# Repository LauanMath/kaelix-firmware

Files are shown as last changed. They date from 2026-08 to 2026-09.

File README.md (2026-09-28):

# Kaelix

Dispositivo IoT de manutenção preditiva para motores industriais — monitora
vibração e temperatura, roda um modelo de detecção de anomalias embarcado
(TinyML) e transmite o resultado via LoRa. TCC de Engenharia de Software
(ICEV), inspirado na arquitetura do TRACTIAN Smart Trac.

O hardware físico ainda não foi montado. Todo o firmware e o pipeline de
treino foram desenvolvidos e testados em simulador e dados offline, para que
a integração com o hardware real seja só calibração quando ele chegar.

## Hardware alvo

| Componente | Modelo | Interface |
|---|---|---|
| Microcontrolador | ESP32-S3-WROOM-1 N16R8 | — |
| Acelerômetro/giroscópio | MPU6050 | I2C (endereço 0x68) |
| Temperatura | Termistor NTC 10K (beta 3950) | ADC analógico |
| Rádio | RA-02 (SX1278) LoRa 433MHz | SPI |
| Regulador | HT7333 (LDO 3,3V ultra baixo consumo) | — |
| Corte de energia | Load switch high-side: SI2301 (P-MOSFET) + BC847B (inversor) | GPIO |
| Proteção de entrada | SI2301 em série (polaridade invertida) | — |
| Medição da bateria | Divisor 1M/1M + 100n | ADC analógico |

### Pinagem

| Uso | Pino | Observação |
|---|---|---|
| I2C (MPU6050) | SDA=8, SCL=9 | *default* da placa — ainda não usado (I2C real é TODO) |
| SPI (LoRa) | MOSI=11, MISO=13, SCK=12, SS=10 | *default* da placa |
| LoRa DIO0 | 14 | escolhido para não colidir com I2C |
| LoRa RESET | 21 | escolhido para não colidir com I2C |
| NTC (ADC) | 4 | placeholder |
| Corte de energia (+3V3_SW) | 5 | ativo-alto; RTC-capable, ver *deep sleep* |
| Tensão da bateria (ADC) | 6 | divisor 1M/1M; 4,2 V → 2,10 V, 3,0 V → 1,50 V |

Conferidos sem conflito entre si e contra o `pins_arduino.h` real da variante
`esp32s3`, mas ainda não contra um esquemático físico definitivo.

**Microcontrolador conferido contra a peça real.** Um ESP32-S3 foi lido com
`esptool`: QFN56 revisão v0.2, 16 MB de flash, 8 MB de PSRAM embarcada. Confirma a
variante N16R8 que o `platformio.ini` declara — e portanto a necessidade de
sobrescrever o perfil da `devkitc-1`, que declara 8 MB de flash e nenhuma PSRAM.
Os demais componentes (MPU6050, NTC, SX1278) continuam não montados.

## O ciclo

```
acordar → energizar periféricos (100ms de estabilização)
        → ler 512 amostras a 1 kHz + NTC
        → extrair RMS, curtose, fator de crista, frequência dominante
        → inferir Isolation Forest embarcado
        → transmitir 21 bytes via LoRa
        → dormir o rádio, cortar periféricos, deep sleep (12 min)
```

Todo o trabalho acontece em `setup()`; `loop()` nunca executa, porque o
dispositivo entra em deep sleep antes de chegar lá.

---

# Decisões de arquitetura

Esta seção registra o *porquê* das escolhas não óbvias — útil tanto para
retomar o desenvolvimento quanto para justificá-las numa defesa.

## Separar matemática pura de acesso a hardware

É a decisão estruturante do projeto. Cada capacidade do firmware foi
dividida em duas camadas:

- **`lib/<nome>/`** — funções puras, sem `Arduino.h`, sem I2C/ADC/SPI.
  Compilam e rodam no host pelo ambiente `native` do PlatformIO.
- **`src/sensors/`, `src/ml/`, `src/comms/`, `src/power/`** — a camada que
  fala com o hardware de verdade e chama as funções de `lib/`.

Foi isso que permitiu desenvolver e validar a maior parte da lógica sem ter
o ESP32-S3, o MPU6050 ou o RA-02 em mãos. Quando o hardware chegar, só a
camada `src/` muda — trocar buffers zerados por leituras reais — porque a
matemática já está testada.

## FFT própria em vez de `arduinoFFT`

A implementação própria (radix-2 Cooley-Tukey, iterativa, sem alocação
dinâmica) compila tanto no ambiente `esp32-s3` quanto no `native`, o que
permite testá-la no host com senoides de frequência conhecida antes de
qualquer hardware. `arduinoFFT` foi avaliada e nunca chegou a ser usada.

`n` precisa ser potência de 2 — responsabilidade do chamador
(`VIBRATION_SAMPLES = 512`).

## Frequência dominante da velocidade, não da aceleração

Aceleração escala com ω², então o espectro de aceleração é sempre dominado
pelo conteúdo de alta frequência — tipicamente um modo estrutural da
montagem, que é o mesmo com a máquina sadia ou defeituosa. Medido em dados
reais do MAFAULDA: o pico de aceleração fica em 117 Hz independente da
rotação, com correlação de **−0,018** contra a rotação real do ensaio.

A magnitude é reponderada por `|V(f)| = |A(f)|/(2πf)` e a busca fica
restrita a 10–1000 Hz. A fase é irrelevante para escolher o bin de pico,
então não é preciso integrar o sinal — só reponderar o espectro que a FFT já
produziu. Custo no firmware: uma divisão por bin.

O limite inferior da banda não é cosmético: sem ele, a ponderação 1/f faria
o bin mais baixo vencer sempre.

**Efeito medido** em 880 arquivos reais, mesmo protocolo: detecção de 11,7%
para 38,5%, F1 de 0,178 para 0,550. A AUC global quase não se move
(0,795 → 0,805), o que ilustra por que ela não serve como métrica de
operação.

## Isolation Forest nativo, sem TensorFlow Lite Micro

O modelo é um Isolation Forest (scikit-learn), mas a inferência embarcada
**não** usa TFLite Micro — usa uma implementação C++ própria
(`lib/isolation_forest/`) que percorre diretamente as árvores exportadas.

TensorFlow Lite é desenhado para redes neurais; Isolation Forest é um
ensemble de árvores cujo score é o comprimento médio de caminho até isolar
um ponto. Não existe caminho oficial e confiável de conversão
scikit-learn → TFLite Micro para esse tipo de modelo, e a rota possível
(`skl2onnx` → `onnx-tf` → `TFLiteConverter`) depende de ferramentas pouco
mantidas. A alternativa nativa é mais simples, mais leve em RAM/Flash, e
elimina a dependência frágil.

### Como funciona

1. `isolation_path_length_correction(n)` — c(n), o comprimento médio de
   caminho esperado numa árvore binária com n amostras. Mesma fórmula do
   scikit-learn, incluindo os casos `c(1)=0` e `c(2)=1`.
2. `isolation_tree_path_length` — percorre a árvore até a folha e soma a
   profundidade com a correção da folha.
3. `isolation_forest_score` — média entre as árvores, normalizada:
   `score = 2^(−caminho_médio / c(n))`, em (0,1]. Próximo de 1 = anômalo.

### Validação cruzada Python ↔ C++

`training/tests/test_export_cpp.py` treina um modelo, exporta o header,
**compila de verdade com g++**, roda o binário e compara o score contra
`-clf.score_samples(X)` do scikit-learn, com tolerância de 1e-4. É o que
garante, de forma verificável, que treino e inferência não divergem.

O vetor de features é o mesmo dos dois lados (`src/ml/model.cpp` e
`training/kaelix_ml/features.py::FEATURE_ORDER`):

```
[rms, kurtosis, crest_factor, dominant_freq_hz]
```

`temperature_c` é lido e passado para `model_infer`, mas ainda não entra no
vetor.

### Estado do modelo embarcado

`src/ml/isolation_forest_data.h` traz o modelo treinado nos dados reais do
MAFAULDA: `N_TREES = 100`, `N_FEATURES = 4`, `ANOMALY_THRESHOLD = 0,55719777`
(quantil de calibração, não 0,5). O arquivo é gerado por
`python -m kaelix_ml.train` — use `--out` para exportar a outro caminho e
preservar o que está versionado.

`model_init` e `model_infer` mantêm a guarda `N_TREES <= 0`, que devolve
`Status::ModelAbsent` e deixa o veredito em `Unknown`. Ela deixou de ser o
caminho normal quando o modelo foi embarcado, mas continua sendo o
comportamento correto para um build sem modelo — e é o que impede que a
ausência de árvores vire "máquina sadia".

## Protocolo de treino e calibração

**Domínio alinhado com o firmware.** Os datasets vêm a 50 kHz (MAFAULDA) ou
12/48 kHz (CWRU), em registros de segundos; o dispositivo lê 512 amostras a
1 kHz. Extrair features do arquivo inteiro produziria um modelo inaplicável
— `dominant_freq_hz` chegaria a 25 kHz no treino e nunca passaria de 500 Hz
em campo. `dataset.to_device_windows` decima e fatia todo sinal antes de
virar feature.

**Split por ensaio.** `GroupKFold` com o arquivo de origem como grupo, para
que janelas do mesmo ensaio nunca fiquem dos dois lados do split. O relatório
traz média ± desvio entre folds: desvio alto é informação sobre falta de
ensaios, não ruído a esconder atrás de um número único.

**Limiar por taxa de falso alarme alvo.** O limiar não é 0,5 nem vem do
`contamination`: é o quantil dos scores de um conjunto de calibração formado
por grupos que o modelo não viu no fit. O default `contamination="auto"`
marcaria ~42% da operação normal como anomalia.

**Mesma regra de decisão dos dois lados.** Calibração, avaliação e exportação
usam `device_score()` = `-clf.score_samples(X)`, a convenção (0,1] idêntica à
de `lib/isolation_forest/`. Usar `clf.predict()` faria o relatório do treino
descrever um comportamento diferente do embarcado.

**Rótulo verdadeiro do caminho, ISO como diagnóstico.** Quando o dataset
codifica a classe de falha na estrutura de diretórios — como o MAFAULDA faz
— é esse o rótulo usado. O rótulo derivado da ISO 10816-3 é calculado em
paralelo e o treino imprime a matriz de concordância. Em dados reais, a ISO
sob classe I marca **93,4% da operação genuinamente normal como anômala**,
o que a desqualifica como fonte de rótulo para este dataset.

## Temperatura

Duas funções puras em `lib/thermistor/`:

1. `ntc_resistance_from_millivolts` — converte a leitura para resistência,
   assumindo o divisor `Vcc → R_FIXED → nó de leitura → NTC → GND`.
   **Topologia assumida, não confirmada contra o esquemático final.**
2. `ntc_resistance_to_celsius` — equação B (Steinhart-Hart simplificada).

O firmware usa a variante em milivolts porque o ADC bruto do ESP32-S3 é
sensivelmente não-linear; `analogReadMilliVolts` aplica a curva de calibração
gravada no eFuse de fábrica. Usar a contagem crua assume uma linearidade que
o hardware não tem e enviesa a temperatura.

## Comunicação LoRa

RadioLib, SX1278, 433 MHz, TX a 17 dBm. API conferida contra o código-fonte
da versão instalada.

### Pacote — 21 bytes, versão 2

| Campo | Bytes | Por quê |
|---|---|---|
| `version` | 1 | o gateway precisa saber interpretar o layout; sem isso, mudar o formato vira leitura silenciosamente errada do outro lado |
| `device_id` | 4 | do eFuse MAC. Com mais de um Kaelix na planta, sem ele o gateway não sabe de quem é a leitura |
| `boot_count` | 4 | contador em RTC memory, sobrevive ao deep sleep. Dá sequência e detecção de pacote perdido |
| `state` | 1 | `kaelix::MachineState` — normal, anômalo ou **desconhecido** |
| `diag` | 1 | `kaelix::status_code()` do primeiro erro do ciclo (0 = Ok). É o canal de diagnóstico de produção: sem ele, `state = Unknown` chega ao gateway sem dizer por quê |
| `rms` | 4 | NaN = não medido |
| `temperature_c` | 4 | NaN = não medido |
| `crc` | 2 | CRC-16/CCITT sobre os 19 bytes anteriores |

A v1 tinha 20 bytes e um campo `status` binário. O `state` ternário e o `diag`
entraram juntos: um veredito que pode ser "não sei" é inútil se o outro lado
não recebe a causa.

O campo `timestamp` que existia antes era `millis()`, que zera a cada deep
sleep — todo pacote chegava com ~3000 ms. Não era um relógio. O tempo de
parede é responsabilidade do gateway, que carimba na recepção.

O CRC vive em `lib/crc16/` como função pura, testada no host contra o vetor
de conferência padrão (`"123456789"` → `0x29B1`): um pacote corrompido no ar
que chegue ao gateway como leitura válida é pior que um pacote perdido.

Um `static_assert` trava o tamanho do struct, para que uma mudança de layout
não passe despercebida sem bump de `PACKET_VERSION`.

### Topologia de rede e o elo que falta

O dispositivo transmite. Do outro lado existe um receptor **em simulação**, em
`experiments/gateway/` — decodificação do quadro, estado por dispositivo, detecção de
lacuna na sequência e regra de alerta, com 19 testes. Não existe receptor em rádio
real: nada nunca recebeu um pacote pelo ar.

**E o gateway está uma versão atrás.** `packet.py` fixa `PACKET_VERSION = 1` e
`PACKET_SIZE = 20`; o firmware emite v2 com 21 bytes. A guarda de versão faria o
gateway recusar **todos** os pacotes do firmware atual — falha segura, e a defesa
funcionando como projetada, mas a cadeia ponta-a-ponta simulada não corresponde ao
dispositivo. Os 19 testes passam porque o gateway é exercitado contra o próprio
`codificar()`, um laço fechado em v1: o teste de paridade cruza a **função** CRC com
`lib/crc16`, não o **layout** da struct. O byte `diag`, que o firmware trata como
canal de diagnóstico de produção, não tem leitor nenhum.

Fechar isso é subir o gateway para v2 e criar um teste que gere o quadro a partir do
layout de `src/comms/lora.h`, em vez do próprio codificador.

**LoRa cru, não LoRaWAN.** `radio.transmit()` direto: sem endereçamento de rede, sem
join, sem criptografia, sem confirmação. Qualquer receptor na mesma frequência, SF e
syncWord recebe o pacote. É escolha, não esquecimento — LoRaWAN exigiria um
concentrador multicanal em vez de um SX1278 e traria complexidade que um protótipo não
paga. Mas o custo aparece nos itens abaixo.

**Sem confirmação, sem retransmissão.** `lora_send()` informa se a transmissão saiu,
não se chegou. Um pacote perdido some em silêncio. O `boot_count` existe para que o
gateway detecte o buraco na sequência — sem gateway, isso é teoria.

**Colisão.** ALOHA puro. Com 185 ms no ar e ciclo de 720 s, a probabilidade de colisão
é 1,0% para 20 dispositivos e 2,5% para 50. Aceitável.
(Uma revisão anterior dava 1,5% e 3,7%: aqueles valores correspondem a 226 ms, o tempo
no ar em `CR 4/7`, que não é o que o firmware usa — ele fixa `CR 4/5`.) Mas essa conta pressupõe fases
aleatórias, e uma instalação em que os aparelhos são ligados juntos não tem fase
aleatória: eles acordariam no mesmo instante e colidiriam de forma sistemática. É o que
o deslocamento anticolisão em `transmission_jitter_seconds()` resolve.

**Sem downlink.** O dispositivo nunca escuta. Intervalo de sono, limiar de anomalia e
modelo são fixos no flash. Atualizar qualquer um exige regravar cada aparelho
fisicamente. A base magnética facilita a remoção, mas continua sendo trabalho manual
por unidade. Downlink exigiria janela de recepção após a transmissão, com custo de
energia a orçar.

**Risco regulatório: 433 MHz não é faixa ISM no Brasil.** A Resolução 680 da Anatel
define 902–907,5 MHz e 915–928 MHz para radiação restrita. Para protótipo acadêmico é
irrelevante; para qualquer intenção de produto, é bloqueante — o dispositivo não
passaria em homologação. A migração para 915 MHz (RA-01H, SX1276) é praticamente
drop-in em firmware, então o custo de errar é baixo. O risco precisa estar registrado,
e é este o registro.

**O que existe depois do gateway.** Nada definido: banco de dados, painel, alerta ao
manutentor. E o `device_id` é um número do eFuse — alguém precisa mapeá-lo para
"compressor 3". Esse cadastro não existe.

Um gateway mínimo — ESP32 ou Raspberry Pi com SX1278, validando o CRC com a mesma
lógica de `packet_is_valid()` e publicando o resultado — é o que transformaria
"transmite" em "sistema funciona de ponta a ponta". Fica como trabalho futuro,
registrado aqui para não ser confundido com esquecimento.

## Deep sleep e orçamento de energia

Ciclo: acordar → ler e processar (3s) → transmitir (~150ms) → deep sleep
(10min).

| Fonte | Corrente | Origem |
|---|---|---|
| ESP32-S3 ativo (sem WiFi) | ~40 mA | típico, datasheet Espressif |
| MPU6050 em operação | ~3,9 mA | datasheet InvenSense |
| SX1278 TX @ ~17dBm | ~90 mA | datasheet Semtech |
| **SX1278 standby (STDBY)** | **~1,5 mA** | datasheet Semtech |
| **SX1278 sleep** | **~0,2 µA** | datasheet Semtech |
| ESP32-S3 deep sleep | ~10 µA | fornecido no escopo do projeto |
| HT7333 quiescente | ~8 µA | fornecido no escopo do projeto |

### A linha que decide o orçamento

O rádio **não** está no rail comutado (+3V3_SW), então o estado em que
ele passa os 12 minutos de sleep é decidido por software:

```
sem lora_sleep():  (1,5 + 0,018) mA × 720s = 1093,0 mA·s
com lora_sleep():  (0,0002 + 0,018) mA × 720s = 13,1 mA·s
```

Sozinha, essa diferença é 5,5× maior que o orçamento inteiro do ciclo.
`comms::lora_sleep()` antes do `deep_sleep()` é obrigatório, não opcional.

### Carga por ciclo, com o rádio dormindo

```
Fase ativa (3,0s):   (40 + 3,9 + 1,5 + 0,008) mA × 3,0s   = 136,22 mA·s
                     (o rádio fica em standby depois do begin())
Fase TX (0,185s):    (40 + 3,9 + 90 + 0,008) mA × 0,185s  =  24,77 mA·s
Fase sleep (720s):   (0,0002 + 0,010 + 0,008) mA × 720s   =  13,10 mA·s
                                                   Total  = 171,91 mA·s
```

Corrente média do circuito: `171,91 ÷ 603,19 ≈ 285 µA`.

O tempo de transmissão não é estimativa: sai do cálculo de tempo no ar para os
parâmetros fixados em `src/comms/lora.cpp` (SF9, BW 125 kHz, CR 4/5, preâmbulo de 8
símbolos, 21 bytes de payload). Antes o orçamento assumia 150 ms, número que não vinha
de cálculo nenhum, e os parâmetros do enlace ficavam nos defaults do RadioLib — de modo
que uma atualização da biblioteca mudaria o consumo do produto em silêncio.

Alcance e autonomia são o mesmo botão:

| SF | Tempo no ar | Autonomia | Ganho de enlace | REQ-PWR-06 (≥ 8 meses) |
|---|---|---|---|---|
| 7 | 57 ms | 292 dias | referência | ✅ |
| 8 | 103 ms | 283 dias | +2,5 dB | ✅ |
| **9 (atual)** | **185 ms** | **269 dias** | **+5,0 dB** | ✅ |
| 10 | 371 ms | 243 dias | +7,5 dB | ✅ (no limite) |
| 11 | 741 ms | 202 dias | +10,0 dB | ❌ |
| 12 | 1483 ms | 152 dias | +12,5 dB | ❌ |

Tempo no ar para 21 bytes em `CR 4/5`; autonomia para o ciclo de 12 min. A tabela
anterior era de 20 bytes e do ciclo de 10 min.

A escolha definitiva depende da distância entre os motores e o gateway, que ainda não
foi medida. O período de 12 min é o que mantém **SF10 dentro do orçamento** — a 10 min
ele dava 211 dias e a decisão de alcance ficava travada pela energia.

Somando a autodescarga da LiPo (~2,5%/mês sobre 2000 mAh ≈ **68,5 µA**, 28%
do orçamento):

```
Consumo efetivo: ~309 µA            → dentro da meta de <1mA, margem ~3,2×
Autonomia (LiPo 2000mAh): ~269 dias (~8,8 meses)
```

REQ-PWR-06 (autonomia ≥ 8 meses) fica atendido com ~26 dias de margem. A 10 min o
projeto entregava 236 dias (7,7 meses) e o requisito não era atendido — não por
medição, mas desde que os 150 ms estimados de tempo no ar viraram 185 ms calculados.

Para comparação, sem `lora_sleep()` o consumo seria ~1,83 mA e a autonomia
cairia para ~48 dias.

### Retenção do GPIO

GPIOs não-RTC vão para alta impedância ao entrar em deep sleep, o que
deixaria a base de Q2 flutuando justamente durante os 12 minutos em que
o corte de energia precisa valer. `deep_sleep()` chama `gpio_hold_en()` +
`gpio_deep_sleep_hold_en()`; `peripherals_power()` chama `gpio_hold_dis()` no
boot seguinte, porque o hold sobrevive ao reset e travaria o pino.

---

# Status

| Frente | Situação |
|---|---|
| Estrutura do firmware (PlatformIO) | ✅ Completa |
| Processamento de vibração (RMS, curtose, fator de crista, FFT) | ✅ Implementado e testado |
| Frequência dominante na velocidade band-limitada | ✅ Paridade C++/Python verificada numericamente |
| Temperatura (NTC + Steinhart-Hart, ADC calibrado) | ✅ Implementado e testado |
| Deep sleep, corte de energia, retenção de GPIO | ✅ ~309 µA médio, autonomia ~269 dias (ciclo de 12 min) |
| LoRa (RadioLib) com device id, sequência e CRC-16 | ✅ Implementado; transmissão real não testada |
| Pipeline de treino (Isolation Forest) | ✅ Validado ponta-a-ponta |
| Split por ensaio + limiar por falso alarme alvo | ✅ `GroupKFold` + calibração por quantil |
| Alinhamento treino ↔ inferência (1 kHz, 512 amostras) | ✅ `dataset.to_device_windows` |
| Treino com dados reais (MAFAULDA) | ✅ 1951 arquivos, 17.559 janelas |
| Modelo embarcado no firmware | ✅ 100 árvores, limiar 0,55719777 |
| Build do firmware para ESP32-S3 | ✅ `pio run -e esp32-s3` limpo — RAM 8,5%, Flash 9,0% de 6,25 MB |
| Watchdog RTC (WDT-1) no ESP32-S3 | ✅ Via `hal/wdt_hal.h`; armado e linkado, comportamento não medido |
| Gateway ↔ firmware na mesma versão de pacote | ❌ Gateway em v1/20 B, firmware em v2/21 B |
| Simulação Wokwi | 🟡 Arquivo pronto; só ESP32+MPU6050, sem NTC nem rádio |
| Leitura I2C real do MPU6050 + DLPF | ⬜ Bloqueado — precisa do hardware físico |
| Calibração física, consumo real, alcance LoRa | ⬜ Bloqueado — precisa do hardware físico |

## O que o modelo detecta

Medido com `GroupKFold` por ensaio, a 2% de falso alarme, em dados reais do
MAFAULDA:

| Classe | Detecção |
|---|---|
| Desbalanceamento | **75,0% ± 3,5%** |
| Defeito de rolamento (0g, puro) | 15–21% |
| Desalinhamento vertical | 7,2% ± 4,3% |
| Desalinhamento horizontal | 5,0% ± 3,1% |

Só desbalanceamento é detectável de forma útil hoje, e as outras duas falham
por motivos diferentes:

- **Desalinhamento** — limitação do vetor de features, não do sensor. A
  assinatura é a razão entre as linhas de 2× e 1× rotação, que nenhuma das
  quatro features captura. Corrigível em software.
- **Rolamento** — limitação de banda. Com Nyquist em 500 Hz, a ressonância de
  3–10 kHz que carrega a assinatura do defeito já foi descartada na
  aquisição. Nenhuma feature recupera informação que o sensor não capturou.

Atenção ao ler números agregados deste dataset: o MAFAULDA roda os ensaios de
rolamento **com massa de desbalanceamento adicionada** (0g, 6g, 20g, 35g), e
a detecção acompanha a massa, não o defeito — de 14,8% em 0g a 87,3% em 35g.
Reportar detecção de rolamento sem estratificar pela massa infla o resultado.

---

# Estrutura do projeto

```
kaelix-firmware/
├── platformio.ini      # ambientes esp32-s3 (firmware real) e native (testes)
├── pyproject.toml      # ambiente Python das análises, figuras e notebooks
│
├── src/                # camada que fala com o hardware
│   ├── main.cpp          # ciclo principal
│   ├── sensors/          # vibração (I2C, TODO) e temperatura (ADC)
│   ├── ml/               # integração do modelo de detecção de anomalias
│   ├── comms/            # empacotamento e envio LoRa
│   └── power/            # deep sleep e corte de energia
├── lib/                # lógica pura, sem Arduino — testável em `native`
│   ├── signal_processing/  # RMS, curtose, fator de crista, FFT
│   ├── thermistor/         # conversão mV → resistência → °C
│   ├── isolation_forest/   # inferência do modelo de anomalia
│   └── crc16/              # integridade do pacote LoRa
├── test/               # testes unitários do firmware (PlatformIO + Unity)
├── wokwi/              # simulação (ESP32-S3 + MPU6050)
│
├── training/           # pipeline Python de treino do modelo
│   ├── kaelix_ml/        # ingestão, features, rotulagem, treino, export C++
│   └── tests/            # testes do pipeline (pytest)
├── tools/              # verificação reproduzível e análise estática
├── data/               # datasets — brutos ignorados, cache derivado versionado
│
├── docs/
│   ├── referencias.md    # revisão de literatura
│   ├── relatorio/        # monografia (LaTeX + PDF)
│   ├── device/           # desenho técnico do invólucro
│   └── img/
├── experiments/        # notebooks de validação numérica (fonte da verdade)
└── experiments/figures/  # figuras em padrão de submissão
    ├── scripts/          # exportadores Python + plot em R (ggplot2)
    ├── data/             # CSVs rastreáveis
    └── output/           # SVG/PDF vetoriais, TIFF 600 dpi
```

`docs/relatorio/` contém quatro documentos: o relatório de simulação da cadeia de
medição, a revisão de literatura, a análise de comunicação e topologia, e a tabela
de práticas de tolerância a falhas em sistemas embarcados críticos
(`praticas-sistemas-criticos.tex` — redundância aviônica, normas de garantia e o que
o Kaelix adota, não adota e por quê).

Histórico de mudanças em [CHANGELOG.md](CHANGELOG.md).

# Como rodar

## Firmware

```bash
pio run -e esp32-s3
```

## Testes do firmware (sem hardware, roda no host)

```bash
./tools/run-all-tests.sh      # as três suítes de uma vez
```

São três, em duas linguagens, e rodá-las separadamente é como quebra de
integração passa: um refactor em `lib/` que muda assinatura aparece no teste C++,
mas o gerador Python que consome a mesma struct só quebra na suíte de treino.

| Suíte | Casos | Cobre |
|---|---|---|
| `tools/run-native-tests.sh` | 146 | `lib/`, nos dois modos de build |
| `training/tests/` | 35 | pipeline de treino, paridade C++↔Python |
| `experiments/gateway/tests/` | 19 | pacote, receptor, cadeia simulada |

Nenhuma cobre a camada `src/`, que depende de `pio run -e esp32-s3`.

## Pipeline de treino

```bash
cd training
pip install -r requirements.txt
python -m pytest tests/            # 35 testes, inclui compilação real com g++
python -m kaelix_ml.ingest --all   # baixa o MAFAULDA e cacheia (~12GB -> 32MB)
python -m kaelix_ml.train          # treina e exporta o header C++
```

`ingest` processa uma classe por vez e apaga os CSVs após cachear, então o
pico de disco é o maior tarball e não os ~31 GB extraídos. É resumível, com
timeout e retomada por HTTP Range.

`train` imprime a validação cruzada por ensaio com média ± desvio entre
folds, AUC, pAUC e a matriz de concordância com a ISO 10816-3. Use `--out`
para exportar o header a outro caminho e preservar o placeholder do
repositório.

Sem dados em `data/`, o treino cai para dados sintéticos com aviso em stderr
— serve para exercitar o pipeline, não como modelo utilizável.

## Simulação Wokwi

Abrir a pasta em [wokwi.com](https://wokwi.com) ou pela extensão do VSCode,
usando `wokwi/diagram.json`. O diagrama tem só ESP32-S3 e MPU6050 — sem NTC e
sem rádio — e, como a leitura I2C ainda é um stub, a simulação hoje exercita
pouco além do boot.

# Pendências conhecidas

- **Gateway uma versão atrás do firmware.** `experiments/gateway/packet.py` fixa
  `PACKET_VERSION = 1` e 20 bytes; o firmware emite v2 com 21 bytes. O gateway
  recusaria todo pacote real. Os 19 testes passam porque exercitam o gateway
  contra o próprio codificador — nenhum teste cruza a fronteira firmware↔gateway.
  O caso `test_crc16_valores_de_referencia_do_pacote_de_20_bytes` também congela o
  tamanho da v1.
- **Comportamento do WDT-1 não medido.** O build prova que a API do RWDT é usada
  corretamente e que resolve em link; não prova que o contador sobrevive ao deep
  sleep, premissa em que se apoiam o `watchdog_arm_for_sleep` e o despertador de
  último recurso. Medir com o timer de despertar desabilitado.
- **Nada foi transmitido pelo ar.** `lora_init()` e `lora_send()` compilam contra a
  RadioLib instalada, mas nenhum pacote saiu de um SX1278 real.
- **Pinos GPIO** são placeholders sem conflito entre si, mas não conferidos
  contra um esquemático final. O pino de corte de energia precisa ser
  RTC-capable para que `gpio_hold_en` funcione.
- **Correntes do SX1278** (standby ~1,5mA, sleep ~0,2µA) e a autodescarga da
  LiPo (~2,5%/mês) são valores de datasheet. São os dois termos que mais
  pesam no orçamento de energia — medir com INA219 na Fase 3.
- **Layout do CWRU.** O download oficial entrega `.mat` soltos e numerados,
  sem estrutura de pastas; é preciso organizar em `normal/`, `ir/`, `or/`,
  `b/` antes de carregar. `cwru_label_from_path` falha alto até lá, de
  propósito — rotular errado em silêncio contamina o treino inteiro.
- **Limiares da ISO 10816-3** (`training/kaelix_ml/labeling.py`): valores
  comumente citados na literatura, não conferidos contra o texto oficial nem
  contra a classe real do motor de bancada. A integração para velocidade já
  usa o método validado; o que falta são os limiares de zona.
- **Banda ISO coberta pela metade.** Com 1 kHz de amostragem o Nyquist é
  500 Hz, contra os 1000 Hz que a norma exige. Conformidade plena não é
  possível com o MPU6050.
- **Alcance LoRa e taxa de perda** nunca testados em campo.

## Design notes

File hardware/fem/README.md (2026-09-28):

# Análise modal — placa e caminho de montagem

Elementos finitos com gmsh 4.15 (malha) e CalculiX 2.23 (solver), ambos os
binários vindos da instalação do FreeCAD. Nada aqui é editado à mão; todo o
conteúdo de `v1/` e `v2/` é derivado e está no `.gitignore` (uma rodada
completa passa de 200 MB).

```
# sólido do caminho de rigidez (base + corpo unidos pelo spigot)
/Applications/FreeCAD.app/Contents/Resources/bin/freecadcmd hardware/fem_caminho.py

# modo próprio da placa, por versão
KAELIX_PCB=v1 uv run --no-project --with gmsh python hardware/fem_modal.py
KAELIX_PCB=v2 uv run --no-project --with gmsh python hardware/fem_modal.py

# modo do caminho de montagem, as duas versões numa rodada
uv run --no-project --with gmsh python hardware/fem_montagem.py
KAELIX_MALHA=1.8 uv run --no-project --with gmsh python hardware/fem_montagem.py
```

## Por que existe

`experiments/notebooks/analise-involucro.ipynb` testou três hipóteses e
confirmou uma: o caminho **motor → ímãs → base ASA → spigot → corpo ASA → PCB
→ MPU6050** tem frequência de montagem dentro dos 10–1000 Hz que a
ISO 10816-3 exige, estimada em **560 Hz**. Aquela análise é de mola
equivalente, e trata a placa como massa rígida.

Ficaram duas lacunas, e as duas passaram a ser resolvíveis quando os sólidos
do invólucro e da placa passaram a existir:

1. A placa também é uma mola. Um acelerômetro no ponto mais flexível de uma
   chapa de 1,6 mm mede a flexão da chapa.
2. Existem duas versões de invólucro para comparar. A estimativa por mola
   equivalente usa uma massa fixa de 118 g e não distingue as duas.

## Resultado 1 — modo próprio da placa

Contorno e furos lidos do `.kicad_pcb` gerado, não redigitados. FR-4
isotrópico, E = 24 GPa, ν = 0,136, ρ = 1850 kg/m³, 1,6 mm. Massa dos
componentes somada como densidade equivalente (+5,1 g).

| apoio | v1 42 × 42 | v2 61 × 51 |
|---|---|---|
| 3 furos M2 engastados, chapa nua | 2951 Hz | 1702 Hz |
| 3 furos M2 engastados, povoada | **2001 Hz** | **1352 Hz** |
| aro com apoio simples, povoada | 3986 Hz | 2398 Hz |

Aumentar a placa custou **32%** do primeiro modo. O limite inferior continua
acima dos 1000 Hz da ISO nas duas versões — a decisão de ir para 61 × 51 não
introduz modo na banda.

Consequência de amostragem, essa sim aberta: com fs = 1000 Hz, um modo em
1352 Hz **dobra para 352 Hz** e fica indistinguível de vibração real. O
`vibration_init` já registra a configuração do DLPF como pendência decisiva e
devolve `NotImplemented`; o modo próprio da placa é mais um item que esse
filtro tem de rejeitar.

## Resultado 2 — modo do caminho de montagem

Base + corpo unidos pelo spigot, ASA maciço isotrópico E = 2,0 GPa,
ν = 0,35, ρ = 1070 kg/m³. Engaste nos quatro bolsos de ímã. Tampa sempre
como massa na borda de cima. O modo relatado é o de **maior massa modal
efetiva lateral**, não o primeiro autovalor: em vários casos o primeiro modo é
local de parede e não move o sensor.

| carga placa+bateria | v1 (19,4 g + tampa 13,8) | v2 (48,8 g + tampa 23,8) |
|---|---|---|
| no piso da cavidade | 1181 Hz | 1670 Hz |
| na borda de cima do corpo | **936 Hz** | **679 Hz** |
| massa modal efetiva | 57–69 g de ~110 g | 41–43 g de ~135 g |

**A v2 não resolve o caminho, e na hipótese pessimista piora.** O corpo é
24 mm mais baixo e mais rígido, e mesmo assim a frequência cai: a célula de
2000 mAh que entrega os 265 dias de REQ-PWR-06 põe 25 g a mais sobre a mola de
ASA, e a massa vence a geometria.

Contra a estimativa do notebook: os 560 Hz correspondem ao caso pessimista, e
o modelo os reproduz de perto — o menor autovalor da v2 com carga no topo é
530 Hz. O que a estimativa não conseguia mostrar é que **a posição da carga
vale um fator 2,5 na frequência**, e o projeto não a define.

A regra prática de f_n ≥ 3 × f_max continua **não atendida** em nenhum dos
quatro casos: pede 1500 Hz para a banda de 500 Hz do MPU6050 e 3000 Hz para os
1000 Hz da ISO. Só a v2 com carga no piso passa do primeiro critério. A
recomendação de base metálica do notebook permanece de pé.

## Formas modais

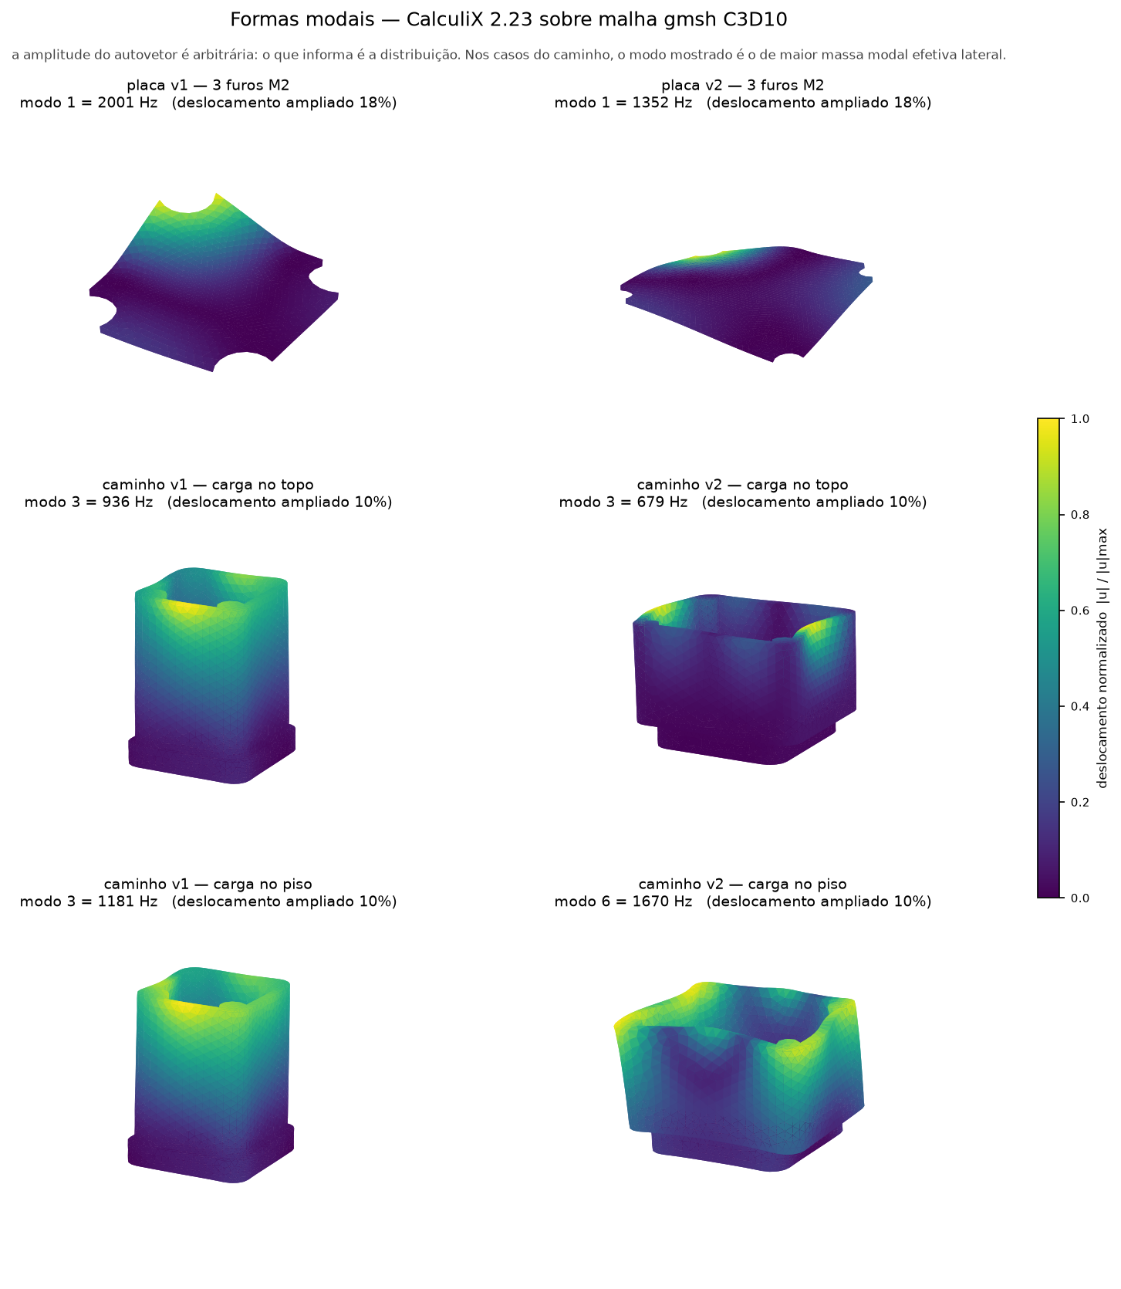
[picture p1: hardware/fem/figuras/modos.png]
formas modais


```
uv run --no-project --with numpy --with matplotlib python hardware/fem_figuras.py
```

O que as formas mostram, e que os números sozinhos não diziam:

- **placa v1 e v2** — flexão simples, com os três furos M2 como os únicos
  pontos parados. O ventre cai na região dos recortes de canto, não no centro:
  o triedro assimétrico da v1 (97°) põe o máximo perto de um recorte
- **caminho v1** — flexão de viga engastada limpa: o deslocamento cresce
  monotonicamente com a altura e é máximo na borda de cima. É exatamente o
  modelo que `analise-involucro.ipynb` assumiu
- **caminho v2** — **não** é flexão de viga. A base fica praticamente parada e
  o deslocamento se concentra na borda superior, em dois cantos opostos. Baixar
  o corpo de 62 para 38 mm enrijeceu a coluna, mas alargou os painéis de
  50 × 50 para 69 × 59 — a flexibilidade mudou de lugar, do balanço da coluna
  para a borda da caixa aberta

Essa troca é a razão de a v2 não herdar a melhora que a altura menor sugeriria.

## Resultado 3 — vibração aleatória e fadiga de junta (Steinberg)

`hardware/vibracao.py`, figura em `experiments/figures/scripts/fig10_vibracao.R`.

Excitação da própria norma que o produto usa: ISO 10816-3 classe III, limiar
C/D = 11,2 mm/s RMS, com os limites importados de
`training/kaelix_ml/labeling.py`. Densidade espectral de **velocidade**
constante na banda de 10–1000 Hz — é o que vibração de máquina rotativa faz, e
o motivo de a norma medir velocidade. Resposta pela equação de Miles com
Q = √f_n (estimativa do próprio Steinberg para placa de circuito impresso).

| | v1 | v2 |
|---|---|---|
| 1º modo da placa | 2001 Hz | 1352 Hz |
| PSD nessa frequência | 0,208 g²/Hz | 0,095 g²/Hz |
| deslocamento 3σ máximo | 31,8 µm | 35,1 µm |
| pior componente | J2 | **U1** |
| margem, base rígida | 7,3× | 4,2× |
| margem, critério do livro (sem escalonar pela forma modal) | 2,4× | 2,7× |

Todos os componentes passam com base rígida. **A base não é rígida.**

### A regra da oitava falha em três das quatro combinações

Steinberg exige que placa e chassi estejam separados por um fator 2, senão
respondem acoplados e o que chega na placa já vem amplificado.

| | chassi | razão | T | margem corrigida | vida em C/D contínua |
|---|---|---|---|---|---|
| v1, carga no topo | 936 Hz | 2,14 | 0,28 | 26,0× | > 100 anos |
| v1, carga no piso | 1181 Hz | 1,69 | 0,54 | 13,7× | > 100 anos |
| v2, carga no topo | 679 Hz | 1,99 | 0,34 | 12,3× | > 100 anos |
| **v2, carga no piso** | **1670 Hz** | **0,81** | **2,88** | **1,4×** | **43 h** |

A última linha é a configuração que a montagem atual implica: a placa assenta
a 5,0 mm do fundo, com a carga embaixo. Nessa combinação o modo do invólucro
(1670 Hz) fica logo **acima** do modo da placa (1352 Hz), a transmissibilidade
vale 2,88, e a margem de 4,2× cai para 1,4×. Com expoente S-N de 6,4, isso
leva a vida da junta do módulo ESP32-S3 de mais de 100 anos para **43 horas**
de zona C/D contínua.

Duas coisas conspiram na v2 e nenhuma delas é acidente: a placa maior baixou o
modo de 2001 para 1352 Hz, e o U1 saiu de uma região quieta (amplitude modal
local 0,21) para perto do ventre (0,65).

### Sensibilidade

Sem a correção do chassi, a margem do pior caso varia com Q e com a zona:

| Q | zona A/B | zona B/C | zona C/D |
|---|---|---|---|
| 10 | 97× / 45× | 39× / 20× | 15,5× / 8,0× |
| 20 | 68× / 32× | 27× / 14× | 11,0× / 5,6× |
| √f_n | 46× / 34× | 18× / 10× | 7,3× / 4,2× |

(v1 / v2). A ordem entre as versões não muda em nenhuma célula.

### Simplificações desta parte

| Simplificação | Direção do erro |
|---|---|
| densidade espectral de velocidade constante **extrapolada acima de 1 kHz** | **conservador**: espectro real de máquina rola em velocidade acima de algumas centenas de Hz. A norma para em 1000 Hz e os dois modos estão acima — é a única escolha livre da análise |
| ζ = 0,03 para o ASA | não medido; herdado de `analise-involucro.ipynb` para as duas análises falarem a mesma língua |
| c = 2,25 para os módulos e o QFN | classe de encapsulamento sem terminal, a pior de Steinberg. Com c = 1,26 as margens dobram |
| escalonamento pela amplitude modal local | refinamento; a linha "critério do livro" mostra o número sem ele |
| Miles com 1 grau de liberdade | válido só enquanto a regra da oitava vale — e ela falha em três dos quatro casos. A correção por transmissibilidade é remendo, não substituto de uma análise acoplada |

## Resultado 4 — condução do motor até a placa

`hardware/termica.py`, figura em `experiments/figures/scripts/fig11_termica3d.R`.
Invólucro fechado (base + corpo + tampa) em ASA, entrada pelos quatro bolsos
de ímã presos a 90 °C, convecção natural mais radiação linearizada para 30 °C
nas faces externas, cavidade adiabática.

### Regime permanente

| altura | v1 | v2 |
|---|---|---|
| ímã (carcaça do motor) | 90,0 °C | 90,0 °C |
| base, z ≈ 3 mm | 57,0 °C | 58,2 °C |
| meia altura | 31,4 °C | 32,6 °C |
| tampa | 30,0 °C | 30,1 °C |
| **parede da cavidade** | **34,3 °C** | **35,1 °C** |

**O ASA não protege: ele desconecta.** A entrada vale ~118 K/W (12,3 mm de
ASA sobre 615 mm²) contra ~5 K/W de troca com o ar — 25 vezes mais resistiva.
Dos 60 K de salto, **33 K são gastos nos primeiros 4 mm da base**. A 90 °C
passam ~640 mW e a cavidade fica 4–5 K acima do ambiente.

### A placa não fica na média da cavidade

A placa não toca em nada (ver o achado colateral acima), então se acopla ao
invólucro só por radiação e convecção interna. Mas a cavidade **não é
isotérmica**, e usar a média dela para a placa foi erro meu na primeira
versão desta seção:

| | piso da cavidade | paredes | tampa | média | **placa** |
|---|---|---|---|---|---|
| v1 | 49,1 °C | 31,9 °C | 30,0 °C | 34,3 °C | **38,6 °C** |
| v2 | 48,2 °C | 31,7 °C | 30,1 °C | 35,1 °C | **38,3 °C** |

A placa assenta 5,0 mm acima do piso, e daí o fator de forma para o piso vale
**0,80 (v1) e 0,84 (v2)** — ela enxerga quase só a superfície mais quente da
cavidade. O equilíbrio sai 4 K acima da média, não nela.

Margem para a LiPo: limite de carga 45 °C contra ~38,5 °C —
**6,5 K de folga com o motor a 90 °C**, não os 10 K que a média sugeria.

A célula fica acima da placa, com fator de forma menor para o piso, então é a
placa que manda nessa margem.

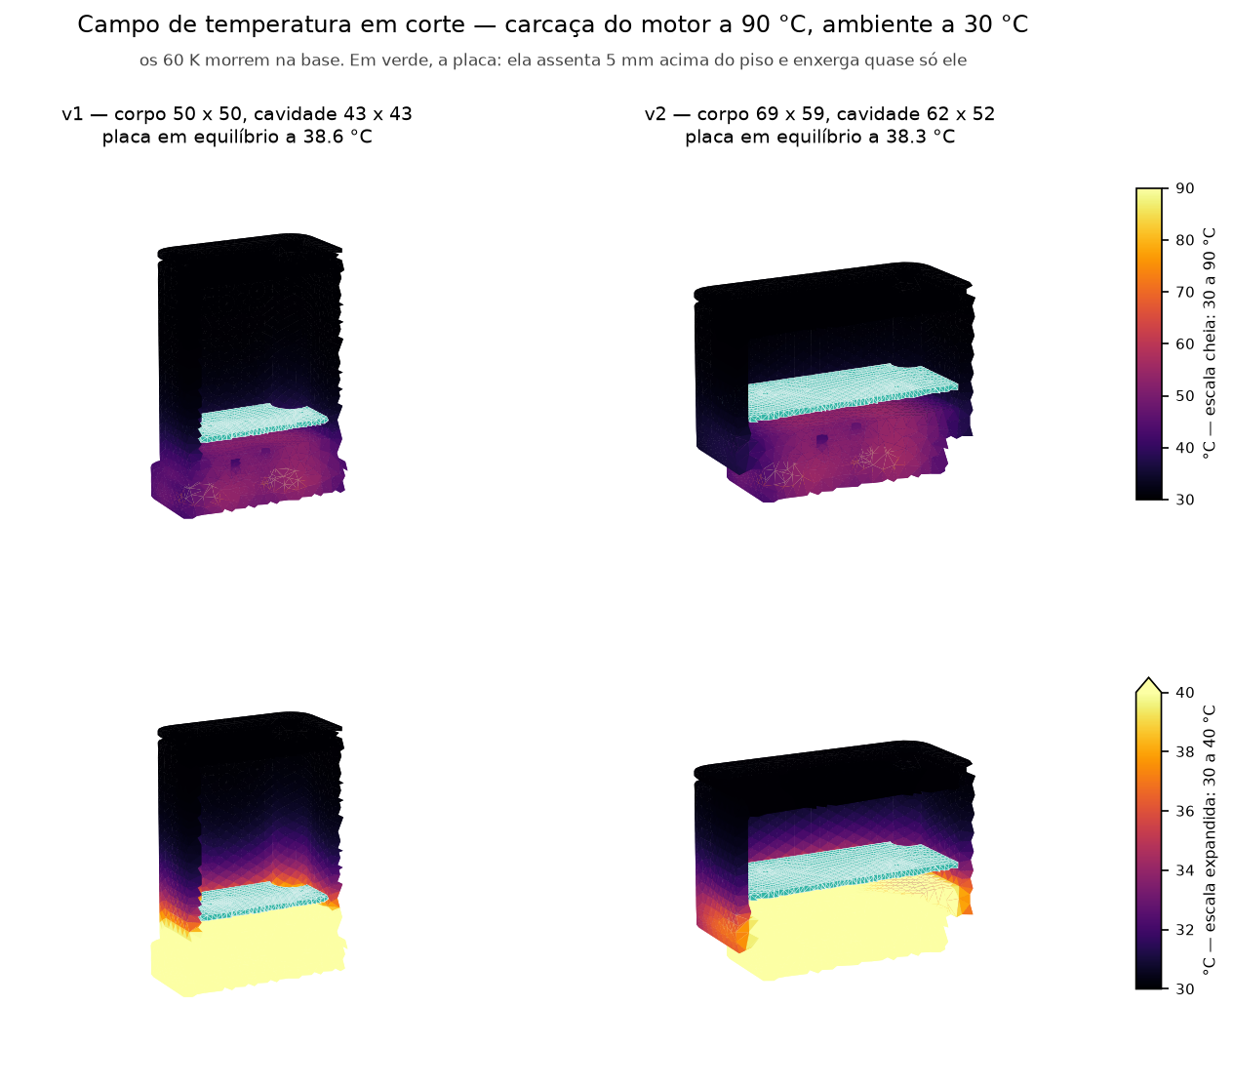
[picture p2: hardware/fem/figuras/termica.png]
campo de temperatura em corte


O corte é no plano central em Y, com a face cortada voltada para a câmera. São
duas escalas de cor porque uma só mente: com 30–90 °C o corpo inteiro sai
preto, que **é** o resultado mas não deixa ver nada dentro dele; com 30–40 °C
aparece o gradiente que sobra depois da base. Mostrar só a segunda faria o
efeito parecer maior do que é.

### Transiente

Degrau de 30 para 90 °C na carcaça em t = 0:

| | v1 | v2 |
|---|---|---|
| τ (63% do salto) | 23 min | 24 min |
| 90% do salto | 50 min | 53 min |
| 99% do salto | 113 min | 120 min |
| τ próprio da placa + célula, dentro | 4 min | 7 min |

O conjunto acompanha o motor com cerca de meia hora de atraso e nunca chega
perto dele. A massa térmica interna (20 J/K na v1, 50 J/K na v2) é pequena
diante da do invólucro e some em série.

### Durante a carga (placa v3)

`hardware/termica_carga.py`, dados em
`experiments/figures/data/termica_carga.csv`. A cavidade adiabática vale para
a operação — 2,0 mW médios, centésimos de kelvin — e deixa de valer na carga:
o BQ21040 da placa v3 é linear e dissipa I·(V_USB − V_bat) dentro do
invólucro fechado, centenas de mW. Mesma malha, material e troca externa
desta seção; a potência entra como fluxo uniforme pelas faces da cavidade, e a
placa fica acima da parede pela R_int de `termica.py`.

| cenário | placa sem carga | ganho | 200 mA (0,41 W no pior ponto) |
|---|---|---|---|
| bancada, fora do motor | 30,3 °C | 15,7 K/W | 36,7 °C |
| preso ao motor parado | 30,3 °C | 15,5 K/W | 36,6 °C |
| preso ao motor a 90 °C | 35,3 – 38,5 °C | 14,3 K/W | **41,1 – 44,3 °C** |

O intervalo do motor quente é o mesmo desta seção: da média da parede ao
equilíbrio radiativo com o piso quente. O NTC do TS está na placa, então o
corte de 45 °C é lido na placa — o limite superior da célula.

A conclusão muda de forma. **Em operação**, nenhum limite é atingido até
90 °C de carcaça: a placa fica em 38,3 °C, abaixo tanto dos 45 °C de carga
quanto dos 60 °C de descarga da célula. **Durante a carga** o limite de 45 °C
passa a restringir: com folga de 8,3 K na bancada e de só 0,7 a 3,9 K no
motor quente. E essa folga é **otimista**: a R_int herdada usa o h externo, e a
convecção dentro da cavidade fechada é mais fraca — a placa real esquenta mais
que o modelo durante a carga. No motor quente a folga real pode ser nula. O
TS suspende e retoma a carga sozinho; o procedimento recomendado é carregar
fora do motor ou com ele parado.

### Correção a `analise-termica.ipynb`

O notebook resolve o balanço concentrado por iteração de ganho fixo
(`T += 0.005*(Q_in - Q_out)`) com 500 passos, e **não converge**: no passo 500
o resíduo ainda é 2831 mW, cinco vezes o calor que atravessa. O mesmo balanço,
resolvido até a raiz:

| carcaça | notebook (500 iterações) | convergido | erro |
|---|---|---|---|
| 80 °C | 44,8 °C | 33,0 °C | +11,8 K |
| 90 °C | 47,5 °C | 33,5 °C | +14,0 K |

O erro atinge só os casos de alta resistência. O ramo de alumínio (R = 0,07
K/W) converge e seus 79,0 °C estão certos — por isso a conclusão de que base
metálica é ruim termicamente **permanece**. O que muda é a linha de base:

- "a bateria é o elo mais fraco" — a 33 °C ela tem 12 K de folga, não 0
- "recarga bloqueada com o dispositivo montado" — a curva não convergida cruza
  os 45 °C perto de 80 °C de carcaça; a convergida não cruza em faixa nenhuma
- a tabela de compromisso ASA × alumínio × quebra térmica tem a coluna térmica
  errada nas duas linhas com isolamento

O notebook não foi alterado: reescrevê-lo é mexer nas conclusões em prosa dele,
e isso é decisão de quem o mantém.

### Simplificações desta parte

| Simplificação | Direção do erro |
|---|---|
| face do bolso de ímã presa em 90 °C | **otimista**: o ímã real tem cola e resistência de contato, que só reduziriam o fluxo |
| cavidade adiabática na condução | vale > 1000 K/W contra poucos K/W da parede; desprezível para o campo no ASA |
| equilíbrio da placa por média ponderada por fator de forma, com ε → 1 | ignora a mistura do ar da cavidade, que puxaria a placa para a média (35 °C). O valor real fica **entre 35 e 38,5 °C**; adotado o extremo radiativo |
| radiação linearizada (h = 4εσT³) | erro < 1% para salto de poucos kelvin |
| h externo de convecção natural por correlação de placa vertical | valor único para toda a peça; o real varia com a orientação da face |
| ASA maciço, k = 0,17 | peça impressa a 35% de preenchimento conduz **menos**; o resultado real é ainda mais isolado |
| sem fonte interna | os 314 µA médios dissipam ~1 mW, contra os 640 mW que entram. **Não vale durante a carga** da placa v3: ver "Durante a carga" |
| fonte da carga como fluxo uniforme nas faces da cavidade | o calor real sai concentrado perto do U5; a média da parede não muda, a distribuição sim |
| R_int da placa com o h externo (herdado de `termica.py`) | a convecção interna é mais fraca que a externa: a placa real fica **mais quente** que o modelo durante a carga |
| corpo sem os furos de USB-C e SMA | os furos nunca foram cortados até a correção 18 de `hardware/involucro/README.md`; ~1,7% da parede, não refeito |

## Convergência de malha

| elemento | v1 carga no topo | v2 carga no topo | nós (v2) |
|---|---|---|---|
| 3,5 mm | 936 Hz | 679 Hz | 27 346 |
| 2,5 mm | 922 Hz | 641 Hz | 55 181 |
| 1,8 mm | 927 Hz | 657 Hz | 123 817 |

Dispersão de 1,5% na v1 e 6% na v2. As conclusões não dependem do refino.

## Achado colateral: a placa não tem assento

Seccionando o corpo no plano em que a montagem posiciona a placa
(`FUNDO` + 5,0 mm), a seção contém **apenas a parede externa e os quatro
bosses**. Não há ressalto, nervura ou batente.

Os 0,0 mm³ de interferência que `check_3d.py` reporta como aprovação
significam, portanto, que **nada toca a placa**. As duas condições de contorno
do Resultado 1 são hipóteses, e os dois casos de carga do Resultado 2 são os
limites da mesma indefinição. Enquanto ela existir, a frequência do conjunto
não é uma propriedade do projeto — é uma faixa de 2,5×.

## Simplificações declaradas

| Simplificação | Direção do erro |
|---|---|
| ASA isotrópico e maciço, E = 2,0 GPa | **otimista**: peça impressa a 35% de preenchimento é anisotrópica e mais mole, sobretudo entre camadas |
| junta do spigot tratada como colada | **otimista**: no produto são base e corpo aparafusados, com 0,2 mm de folga radial |
| furos-guia M3 Ø2,6 preenchidos | desprezível (4 × 287 mm³ em 92 cm³); feito porque o cilindro esbelto gerava elemento de jacobiano não positivo |
| nós de meio-lado lineares (`SecondOrderLinear`) | perde fidelidade nas faces curvas; adotado porque a projeção invertia elementos |
| FR-4 isotrópico | erra o modo torcional mais que o de flexão |
| massa dos componentes espalhada na chapa | subestima a queda quando a massa está no meio do vão, superestima quando está perto do apoio |
| tampa e carga como massa concentrada, sem rigidez própria | **conservador**: massa sem a rigidez que a peça real acrescenta |

## Não coberto

- Amortecimento: só frequências, nenhuma resposta forçada. O ζ = 0,03 usado
  no notebook para transmissibilidade não foi medido aqui
- Contato: todas as juntas são coladas; nenhum caso de folga ou pré-carga
- A tampa e a bateria não têm rigidez, só massa
- Nada de térmico, fadiga ou impacto

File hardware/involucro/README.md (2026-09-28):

# Invólucro — v1, v2 e v3

Três versões geradas por `hardware/gen_involucro.py` a partir de um único
conjunto de parâmetros (`VERSOES`). Todas reprodutíveis; nenhum arquivo desta
pasta é editado à mão.

A **v3** é o corpo da v2 para a placa v3, que carrega a bateria por USB-C. A
única diferença é a altura do furo do USB-C, que deixa de ser arbitrada e
passa a ser **medida** no `.step` da placa: centro do conector a 7,73 mm do
fundo da cavidade, no eixo da placa em Y (desvio 0,00 mm). O furo sai de
z = 21,50 para z = 15,73 mm. Na altura antiga a borda de baixo do furo barrava
o plugue. Tudo o mais na tabela abaixo vale para a v3 como para a v2.

| | v1 | v2 |
|---|---|---|
| estado | congelada | ativa (v3 = v2 com o furo do USB-C medido) |
| origem das cotas | `docs/device/IMG_5298.jpeg`, versão 4 | dimensionada pela célula real e pela placa |
| planta | quadrada | retangular |
| cavidade | 43 × 43 × 54 | 62 × 52 × 30 |
| corpo | 50 × 50 × 62 | 69 × 59 × 38 |
| montagem | 54 × 54 × **74,5** | 69 × 59 × **50,5** |
| postes M3 | Ø11, recuo 3,5 | Ø8, recuo 2,5 |
| volume externo do corpo | 155 cm³ | 155 cm³ |
| massa se maciço | 112 g | 115 g |
| célula que entra | nenhuma de catálogo | Adafruit 2011, 2000 mAh |
| autonomia a 314 µA | 66 dias (célula de 500 mAh, **que também não entra**) | **265 dias** |
| REQ-PWR-06 (243 dias) | não atendido | atendido |

Eletrônica idêntica na v1 e na v2; a v3 acrescenta o circuito de carga. Cada
versão tem a sua placa, desenhada para o próprio vão
(`hardware/pcb/README.md`): 42 × 42 mm na v1, 61 × 51 mm na v2 e na v3. Cada
uma entra na cavidade correspondente com interferência **0,0 mm³** — na v3
com o nariz do USB-C passando pelo furo da parede.

## Arquivos

```
v1/  v2/  v3/
  corpo.step  tampa.step  base.step     peças, cada uma na própria origem
  montagem.step                          posicionadas, com placa e bateria
  montagem-corte.step                    meia seção
```

A base (54 × 54, spigot Ø28, quatro ímãs Ø10 em R20, pino de orientação) é a
interface com o motor e é **igual nas duas versões**.

## Defeitos de projeto identificados

Cada linha traz como o defeito foi medido e o que decorre dele.

### Fechados

| # | Defeito | Medição | Correção |
|---|---|---|---|
| 1 | Contorno da placa circular (Ø40) sem fundamento. A justificativa era "com 43 mm de vão, um disco de 40 mm deixa 1,5 mm de folga radial" — trata vão **quadrado** como circular | vistas 1 e 2 do desenho: 50 × 50 externo, 43,0 interno, R7 | placa passou a quadrado 42 × 42 com recortes de canto; +18% de área útil (1257 → 1477 mm²) |
| 2 | Verificador de encaixe da placa comparava escalares (vão 43,0 contra placa 42,0), sem ver corredor de cabo, poste no canto nem altura | — | encaixe passou a ser interseção de sólidos no modelo montado |
| 3 | Modelo do conector JST deslocado 2,65 mm da origem do footprint (substituto da variante passante) | interseção de sólidos: J1 × C12 e J1 × RT1 | modelo próprio da variante SMD, e depois modelo real de terceiro |
| 4 | `.step` exportado sem os quatro componentes mais altos (WROOM-1U, Ra-02, MPU6050, JST), por ausência de modelo 3D na biblioteca | conferência de existência de arquivo por footprint | modelos de terceiros com licença permissiva; ver `3dmodels/origem/ORIGEM.md` |

### Abertos

| # | Defeito | Medição | Decorrência |
|---|---|---|---|
| 5 | **Nenhuma célula de catálogo entra na v1.** Adafruit 2011 (2000 mAh) mede 60,0 × 37,0 × 7,5 — 60 mm não entram em 43. Adafruit 1578 (500 mAh, 36 × 29 × 4,75) colide com os postes | interferência 86,1 mm³ com os postes Ø11 | REQ-PWR-06 não atendido na v1. Resolvido na v2 |
| 6 | Postes Ø11 de altura cheia consomem os cantos da cavidade. Maior retângulo livre: **25 × 40 mm** | varredura geométrica com folga de 1,0 mm | 2000 mAh nesse formato exigiria célula de ~18 mm de espessura, sob encomenda |
| 7 | **Altura dos postes não é cotada** no desenho | vistas 1 e 2 não a apresentam | Se forem postes curtos (só no topo), a v1 aceita célula 40 × 40 × 10 (~1880 mAh, 249 dias). Cota que separa "custom exótico" de "custom viável" |
| 8 | Empilhamento não fecha: 74,5 mm contra os **78,0** da vista 6 | base 9,0 + corpo 62,0 (rebaixo 3,3 absorvido) + tampa 3,5 | −3,5 mm. Candidatos: espessura da tampa, altura da base, gaxeta |
| 9 | **Espessura da tampa não é cotada.** Adotado 3,5, herdado de `experiments/figures/scripts/export_enclosure_data.py` | vista 3 não a apresenta | Se for 7,0, o item 8 fecha exato |
| 10 | Massa anotada (118 g) é cálculo **maciço**, não impresso | modelo maciço: 112 g a 1070 kg/m³ → fração implícita 1,06 | Peça impressa a 35% de infill pesa menos. Diferença de 5% valida a leitura das cotas |
| 11 | Furo USB-C Ø13,0 sem conector correspondente na placa | netlist: J2 é header UART de 6 vias | Fechado na v3 (J3, USB-C de carga). Na v1 e na v2 segue sem conector |
| 12 | Antena SMA Ø6,5 sem rabicho u.FL→SMA na BOM | `hardware/pcb/v1/kaelix-bom.csv` | O Ra-02 tem conector IPEX; a ligação ao painel não está especificada |
| 13 | Altura dos furos de USB-C e SMA na parede não legível na foto do desenho | — | Modelados a 45% e 80% da cavidade. Bitolas são as do desenho; posições verticais são arbitradas. Na v3 a do USB-C é medida no conector (15,73 mm); a da SMA segue arbitrada |
| 18 | **Os furos de USB-C e SMA nunca foram cortados.** O cilindro começava em x = −cx, a largura externa inteira, e ia de −69 a −58,5 mm num corpo que termina em −34,5 | interferência de 0,07 mm entre a carcaça do USB-C da v3 e a parede, dentro do que devia ser o furo | Corrigido: o cilindro começa fora da parede e a atravessa. O corpo perde 0,58 cm³ nas duas versões, o volume dos dois furos. **Os resultados modais e térmicos de `hardware/fem/` foram calculados sobre o corpo sem furos** e não foram refeitos: ~166 mm² de abertura numa parede de ~9.700 mm². O efeito esperado é pequeno, mas não foi medido |
| 14 | Assento mínimo da placa não estava especificado em lugar nenhum | interferência 220,3 mm³ com assento de 2,0 mm | **A placa exige ≥3,3 mm acima do fundo**: o Ra-02 está na face de baixo e desce 3,29 mm. Adotado 5,0 mm |
| 16 | **Não existe assento.** Seccionando o corpo no plano dos 5,0 mm adotados, a seção tem só a parede externa e os quatro bosses — nenhum ressalto, nervura ou batente | seção do sólido em z = FUNDO + 5,0 | Os 0,0 mm³ de interferência que `check_3d.py` reporta como aprovação significam que **nada toca a placa**. Onde a carga se apoia vale **fator 2,5** na frequência do conjunto (679 Hz contra 1670 Hz na v2); ver `hardware/fem/README.md` |
| 17 | A v2 **não resolve** o caminho de montagem confirmado em `analise-involucro.ipynb`, e na hipótese pessimista piora | modal FEM: v1 936 Hz, v2 **679 Hz**, com carga na borda de cima | A célula de 2000 mAh que entrega os 265 dias põe 25 g a mais sobre a mola de ASA; a massa vence a redução de 24 mm na altura. A recomendação de base metálica permanece |
| 15 | Base 54 × 54 menor que o corpo da v2 (69 × 59) | — | Corpo avança 7,5 mm sobre a base em X. Decisão pendente: aumentar a base ou manter a interface com o motor intocada |

## Decisões da v2

| Decisão | Razão medida |
|---|---|
| Planta retangular | Célula real manda em X (60 + folgas); placa manda em Y |
| Poste Ø8 em vez de Ø11 | Com Ø11, a menor cavidade que livra célula **e** placa exige corpo de 87 × 51. O inserto térmico M3 do próprio desenho tem Ø4,0; Ø8 de ASA em volta é folgado |
| Cavidade 62 × 52 | Menor solução da varredura sob a restrição dos quatro postes |
| Altura 50,5 mm | 24 mm abaixo da v1. Perde a comparação de altura com o TRACTIAN Smart Trac (40 × 40 × 78,5, vista 6) |
| Base inalterada | É a interface com a máquina; nada na v2 a exige diferente |

## Limitação declarada da v1

A não-adequação da bateria está registrada em `VERSOES["v1"]["limitacao"]` e
sai no relatório de geração como **limitação conhecida**, não como falha:
a v1 gera com código de saída 0. Falha de geração fica reservada a defeito
não previsto.

```
LIMITAÇÕES CONHECIDAS (declaradas, não são falha):
   v1: a bateria não cabe (86 mm3 de interferência com os postes Ø11)
```

## O que a geração verifica

Cada execução mede e reporta, por versão:

- sólido não vazio em cada peça
- interseção placa × corpo
- interseção bateria × corpo, com o lado longo da célula alinhado ao lado
  longo da cavidade
- envelope da montagem e volume externo do corpo
- massa se maciço, contra a anotada no desenho
- empilhamento, contra a altura anotada na vista 6

## Não verificado

- Se a peça impressa mede o desenho. O desenho está marcado **"⚠ COTAS NÃO
  TRAVADAS"** e "medir com paquímetro no componente físico antes da impressão
  final"
- Vedação, IP67, compressão de gaxeta
- Comportamento térmico e modal (o sólido habilita ambos; nenhum foi rodado)
- Disponibilidade comercial das células citadas

## Regenerar

```
/Applications/FreeCAD.app/Contents/Resources/bin/freecadcmd hardware/gen_involucro.py
```

Depende de `hardware/pcb/<versão>/kaelix.step` (gerado por `tools/build-hardware.sh`) e dos
modelos em `hardware/3dmodels/origem/`.

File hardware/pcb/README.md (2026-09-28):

# Placa — versões

Projeto KiCad versionado por diretório. Cada versão é autocontida
(`.kicad_sch`, `.kicad_pcb`, `.kicad_pro`, `.kicad_sym`, `sym-lib-table` e
derivados) e é gerada por `hardware/gen_schematic.py` + `hardware/gen_pcb.py`.
Nenhum arquivo destas pastas é editado à mão.

```
KAELIX_PCB=v1 ./tools/build-hardware.sh        # v1 é o padrão
KAELIX_PCB=v2 ./tools/build-hardware.sh
KAELIX_PCB=v3 ./tools/build-hardware.sh
```

**O esquemático é idêntico na v1 e na v2.** Mesma netlist, mesmos 32
componentes, mesmos 24 nets. O que a v2 muda é o contorno, o placement e o
roteamento — consequência do vão do invólucro correspondente
(`hardware/involucro/README.md`), não decisão de circuito.

**A v3 é a primeira revisão de circuito:** a v2 mais a carga da bateria
(BQ21040 e USB-C). Até a v2 a placa não tinha como carregar a célula. Ver
[O que a v3 muda](#o-que-a-v3-muda).

| | v1 | v2 | v3 |
|---|---|---|---|
| estado | congelada | ativa até a v3 | ativa |
| invólucro | v1, vão 43 × 43 | v2, vão 62 × 52 | v3 = corpo da v2 com o furo do USB-C na altura do conector |
| contorno | 42 × 42, 4 recortes r = 6,0 | 61 × 51, 4 recortes r = 4,5 | igual à v2 |
| recortes entre eixos | 36,0 × 36,0 | 57,0 × 47,0 | igual à v2 |
| área útil de cobre | 1477 mm² | 2962 mm² (+101%) | igual à v2 |
| folga no vão | 0,50 mm/lado em X e Y | 0,50 mm/lado em X e Y | 0,50 mm/lado; em −X o USB-C passa 0,07 mm para dentro do furo da parede, por projeto |
| componentes | 32 + 3 furos M2 | 32 + 3 furos M2 | 41 + 3 furos M2 |
| nets · pads com net | 24 · 118 | 24 · 118 | 30 · 149 |
| segmentos | 485 (327 F.Cu / 159 B.Cu) | 501 (419 F.Cu / 83 B.Cu) | 637 (488 F.Cu / 150 B.Cu) |
| vias de sinal | 68 | 68 | 108 |
| vias de costura de terra | 71 | 234 | 220 |
| triedro M2 | 63°, 206°, 326° — menor separação **97°** | 79°, 199°, 319° — menor separação **120°** | 64°, 184°, 304° — menor separação **120°** |
| ângulos legais para furo | 89 de 360 | 171 de 360 | 181 de 360 |
| deslocamento máx. no placement | 13,50 mm | 4,00 mm | 11,25 mm |
| desacoplamento acima de 3 mm (reta) | **6 de 6** | **2 de 6** | **3 de 6** |
| pior caso | 11,08 mm (C8 → U3.3) | 4,47 mm (C8 → U3.3) | 5,90 mm (C3 → U1.2) |
| corredor do cabo da bateria | 4,0 mm | 6,0 mm | 6,0 mm |
| envelope montado | 42,00 × 42,00 × 13,42 mm | 61,00 × 51,00 × 13,42 mm | 61,58 × 51,00 × 13,42 mm (nariz do USB-C) |
| ERC | 0 violações | 0 violações | 0 violações |
| DRC | 0 regra, 0 desconectado | 0 regra, 0 desconectado | 0 regra, 0 desconectado |
| interferência 3D | nenhuma entre 92 corpos | nenhuma entre 92 corpos | nenhuma entre 116 corpos |

A linha de desacoplamento usava uma métrica antiga ("10 de 10", "3 de 10"),
anterior à correção 16a, que tirou da conta os quatro capacitores que não
desacoplam nada. Segmentos, vias e costura da v1 e da v2 mudaram com as
correções 27 e 28 abaixo, sem tocar em circuito nem em placement.

Regras de fabricação, iguais nas duas: traço 0,20 · folga 0,15 · via Ø0,60 com
furo 0,30 mm; mínimos declarados furo 0,20 · folga 0,15 · traço 0,15 mm.

## O que a v2 resolve

| Item | v1 | v2 | Causa |
|---|---|---|---|
| desacoplamento | 10 capacitores acima de 3 mm, pior 11,08 | 3 acima de 3 mm, pior 5,95 | Na v1 o Ra-02 fica empilhado sob o WROOM-1U e divide o mesmo anel; na v2 cada módulo tem canto próprio. Os deslocamentos da v2 também deixaram de ser palpite: saem do contorno do CI mais a folga de corpo mais a meia-largura da peça |
| corredor do cabo | 4,0 mm | 6,0 mm | Medido: com 6,0 mm a v1 perde a saída de GND de RT1.2 e R8.2 (3 itens soltos no DRC); a v2 tem área para o plano contornar o corredor |
| triedro de furos M2 | 97° | 120° | O acelerômetro apoiado num triedro assimétrico mede a flexão da própria placa. 171 ângulos legais contra 89 |
| retorno de sinal | 151 segmentos em B.Cu | 81 | Menos rasgos no plano de terra da face de baixo |
| bateria | nenhuma célula de catálogo entra no invólucro v1 | célula real de 2000 mAh, 265 dias | Ver `hardware/involucro/README.md`, defeitos #5 e #6 |

## O que a v2 **não** muda

Eletrônica. Nenhum componente, valor, net ou conexão difere. Os dois
`.kicad_sch` têm os mesmos 294 elementos e 12 símbolos. Isso é deliberado: a
v2 é uma revisão mecânica e de layout, e misturá-la com mudança de circuito
tornaria impossível atribuir qualquer diferença de comportamento medido.

## O que a v3 muda

Circuito, pela primeira vez desde a v1: a placa passa a **carregar a
bateria**. Até a v2 não havia CI carregador nem conector de entrada — o
invólucro tinha o furo de USB-C, os relatórios falavam em "recarga por USB-C",
e a netlist não. Fonte: bloco `COM_CARGA` em `hardware/gen_schematic.py`.

| Peça | Função | Por quê |
|---|---|---|
| U5 BQ21040 (SOT-23-6) | carregador linear de uma célula, 4,2 V | único entre BQ21040, TP4056 e MCP73831 com monitor de temperatura da **célula** pronto para NTC de 10 k |
| RT2 NTC 10k β 3380 | TS do U5: suspende a carga acima de 45 °C (V_TS < 275 mV) e abaixo de 0 °C (V_TS > 1250 mV) | limiares do BQ21040 calibrados para β ≈ 3370 (103AT-2); o B3950 do RT1 cortaria perto de 39 °C |
| R13 2k7 | I_carga = K_ISET / R_ISET = 540 / 2,7 k = 200 mA | escolhida pelo modelo térmico, ver abaixo |
| J3 USB-C só energia, R11/R12 5k1 | entrada de 5 V | Rd em CC1 e CC2 é o que faz fonte C-para-C entregar VBUS |
| C13, C14 1 µF; C15 220 nF | entrada, saída e filtro do TS | C15 é opcional na folha de dados; aqui não, porque o RT2 fica a 22 mm do U5, na placa do rádio |
| IO7 ← CHG_N | status da carga para o firmware | GPIO de RTC: pode acordar do deep sleep; sem pull-up externo |

O limite de 45 °C que a análise térmica usa deixa de ser recomendação da
folha de dados da célula e passa a ser **imposto pelo hardware**.

**Corrente de carga, do modelo térmico.** O BQ21040 é linear e dissipa
I·(V_USB − V_bat) dentro do invólucro fechado. `hardware/termica_carga.py`
roda o FEM de `termica.py` com essa fonte interna: a placa sobe
**~15 K por watt**. Pior ponto da corrente constante (V_bat = 3,0 V), V_USB =
5,0 V, ambiente 30 °C. Com o motor a 90 °C a placa fica entre a média da
parede e o equilíbrio radiativo com o piso quente (+3,2 K, seção térmica de
`hardware/fem/README.md`); os dois extremos estão na tabela:

| I | P | bancada | motor frio | motor a 90 °C | carga completa |
|---|---|---|---|---|---|
| 150 mA | 0,30 W | 35,1 °C | 35,0 °C | 39,6 – 42,8 °C | ~15 h |
| **200 mA** | **0,41 W** | **36,7 °C** | **36,6 °C** | **41,1 – 44,3 °C** | **~12 h** |
| 250 mA | 0,51 W | 38,3 °C | 38,2 °C | 42,6 – 45,8 °C — TS pode cortar | ~9 h |
| 500 mA | 1,04 W | 46,6 °C — TS corta | 46,4 °C — TS corta | 50,2 – 53,4 °C — TS corta | — |

A 200 mA sobram 8,3 K até o corte na bancada ou com o motor parado. **No
motor a 90 °C sobram entre 0,7 e 3,9 K**: a carga funciona, mas no limite, e
com ambiente acima de 30 °C a margem cai kelvin por kelvin. Quem decide é o
TS, que suspende a carga e a retoma ao esfriar — é a proteção funcionando,
não falha. O procedimento recomendado é carregar fora do motor ou com ele
parado. Tudo isto é modelo, não medição, e a folga do motor quente é
otimista: a resistência interna herdada usa o h externo, e a convecção dentro
da cavidade é mais fraca. Ali a folga real pode ser nula. Hipóteses em
`hardware/termica_carga.py` e `hardware/fem/README.md`.

**Placement.** J3 na borda −X, alinhado ao furo do invólucro; U5 e os passivos
na face de baixo, sob o J3. RT2 na face de cima, sob a célula e longe do U5. O
J1 desce 3 mm em relação à v2: na posição antiga o corpo dele invadia o do J3
em 3,77 × 2,47 mm.

**Conector de borda.** O corpo do USB-C passa da borda da placa por projeto.
O gerador passou a conhecer isso (`NA_BORDA`): o encaixe é conferido pelos
pads, a linha "PCB Edge" do footprint tem de cair na borda (desvio medido
0,000 mm), e a passagem pela parede é interseção de sólidos em
`gen_involucro.py`.

## Defeitos de projeto identificados

### Fechados

| # | Defeito | Medição | Correção |
|---|---|---|---|
| 1 | Corte de energia dos periféricos por BC337 low-side. Os pull-ups de 4k7 permaneciam em +3V3 e alimentavam o MPU6050 pelos diodos de ESD de SDA/SCL | FM-27 em `docs/ANALISE-DE-FALHAS.md` | load switch high-side (Q1 SI2301 + Q2 BC847B); pull-ups movidos para o rail comutado +3V3_SW |
| 2 | MPU6050 permanentemente alimentado: 3,9 mA contínuos | orçamento em `src/power/sleep.cpp` | passou ao rail comutado; 314 µA efetivos |
| 3 | Placa em Ø74 mm num vão de 43. `verifica_encaixe` passava porque comparava escalares | contorno contra o vão do desenho | módulos empilhados um por face; contorno retangular |
| 4 | Ângulo de pad gravado como relativo. É **absoluto** (biblioteca + rotação do footprint) | 42 curtos no DRC | conferido contra as placas de exemplo do KiCad |
| 5 | Sinal da rotação invertido: pad local (0; 7,62) a 90° ia para −x | pad 4 do J2 aparecia em +7,62 no DRC | corrigido |
| 6 | Rotação própria do pad ignorada | QFN-24 descrito com pads de 0,85 mm num passo de 0,5 — sobrepostos entre si | escape do barramento I2C passou a fechar |
| 7 | Pad `custom` medido pelo `size` (âncora) | aba do SOT-89 tem 4,6 mm; o `size` diz 1,475 | quatro pistas passavam por cima da aba |
| 8 | Colisão mecânica e colisão de cobre tratadas como um invariante só | furo M2 sobre o pad do R6 não era detectado | separadas; passante vale nas duas faces |
| 9 | Nenhuma pista roteada — só footprints, planos e contorno | 70 pads desconectados no DRC | roteador de labirinto de duas camadas |
| 10 | Sem medição de tensão da bateria | REQ-SEG-29, REQ-SEG-53 e o heartbeat da QUARENTENA dependem dela | divisor 1M/1M + C11 em IO6 |
| 11 | Sem proteção de polaridade invertida na entrada | — | Q3 SI2301 em série, dreno na bateria |
| 12 | Sem filtro no nó do ADC do NTC. FM-08 raciocina sobre "capacitância de filtro × 10 k" — capacitor que não existia | `docs/ANALISE-DE-FALHAS.md` | C12 100n |
| 13 | Corredor de cabo do conector de bateria não modelado; furo M2 a 2,6 mm da boca | courtyard cobre a peça, não o que se conecta nela | corredor virou restrição de placement |
| 14 | Varredura do corredor registrada em comentário estava obsoleta: atribuía o limite ao triedro de furos e a peças sem lugar | remedido: placement fecha de 2,0 a 9,0 mm, furos a 97° em toda a faixa | o limite real é o plano de terra; comentário reescrito com o número medido |
| 15 | `gen_involucro.py` conferia as duas cavidades contra uma única versão de placa, escolhida por variável de ambiente | v1 do invólucro acusava 1616 mm³ de interferência com a placa da v2 | a placa passou a acompanhar a versão do invólucro |
| 22 | Nenhum caminho de carga da bateria: sem carregador, sem conector de entrada | netlist; o furo USB-C do invólucro não tinha conector | v3: BQ21040 + USB-C. v1 e v2 ficam como estão |
| 27 | Pino passante de peça não contava como obstáculo na face oposta. Só furo de fixação contava | DRC da v3: 3 `pth_inside_courtyard` — pinos de carcaça do J3 sob U5, R13 e C14 | a regra de furo passou a valer para pino (pad ≥ 0,8 mm). Via térmica de 0,6 mm continua de fora: o Ra-02 da v1 assenta sob as do WROOM-1U por projeto |
| 28 | O roteador contava como plano a faixa entre as fileiras de pads de um QFN de passo fino | DRC da v3: grupo de GND solto — o escape do U2.1 terminava numa ilha sob o MPU6050 | sob o corpo de peça de passo fino, na face dela, o plano não conta como caminho (`router.py`, `sob_fino`). Mudou o roteamento da v1 e da v2 também; as duas continuam com DRC limpo |
| 29 | Os furos de USB-C e SMA nunca foram cortados no modelo do invólucro | o cilindro começava fora do corpo, em −cx em vez de −cx/2 | ver `hardware/involucro/README.md` |

### Abertos

| # | Defeito | v1 | v2 | Decorrência |
|---|---|---|---|---|
| 16 | Desacoplamento acima de 3 mm do pino, em linha reta | 6 de 6, pior 11,08 mm | 2 de 6, pior 4,47 mm | Restam C8 (4,47) e C3 (3,30). C8 é o segundo capacitor de um **único** pino de +3V3 do Ra-02: em 0805 não há terceira posição |
| 16a | A métrica contava quatro capacitores que não desacoplam nada | lista antiga: C1, C5, C6, C9 | idem | C1 é o RC do EN, C5 e C6 são o regulador interno e a bomba de carga do MPU6050 (exigência de folha de dados, não de PDN) e C9 é a entrada do LDO. `_DESACOPLA` corrigido para C2, C3, C4, C7, C8, C10 |
| 16b | **A régua mede a reta; o laço vê a pista.** Numa placa de 2 camadas o retorno está a 1,5 mm, o que dá 781 pH/mm de pista e 1,30 nH por via passante | C8: 11,1 mm em reta contra **36,1 mm de pista e 6 vias** → 35,9 nH (3,25×) | pior caso C3: 6,4 mm de pista e 2 vias → 7,59 nH | A distância euclidiana subestimava a indutância por até 3,25×. Ver `hardware/pdn.py` e a figura 9 |
| 16c | **A v2 aproximou os capacitores e piorou o PDN.** O roteador pôs 2 vias no caminho do capacitor de bulk do ESP32-S3 | Z abaixo do alvo de 733 mΩ em toda a faixa | passa do alvo acima de **6,0 MHz** (ESP32-S3) e de **1,1 MHz** (MPU6050) | Ganho de placement em linha reta não se traduziu em ganho elétrico. Corrigir pede fixar o caminho do bulk na mesma face, sem via |
| 17 | Cinco pads de sinal do WROOM-1U a 1,27 mm de passo não comportam seis discretos a 3 mm | — | — | 0805 em pé pede 3,5 mm de passo. Limite de encapsulamento, não de área |
| 18 | Corredor do cabo | 4,0 mm | 6,0 mm | A v1 não aceita os ~6 mm que um alojamento PHR-2 com chicote pede |
| 19 | Altura dominada pelos **conectores**: J2 tem 11,54 mm e J1 tem 5,60, contra 3,20 dos módulos | igual | igual | Num dispositivo selado, um header de gravação de 11,5 mm é a peça mais alta. Decidir se fica populado no produto |
| 20 | Divisor do NTC satura no frio: nó chega a 3,22 V a −40 °C, acima da faixa útil do ADC (~3,1 V a 12 dB) | igual | igual | Abaixo de ~−35 °C a leitura sai otimista e **não** dispara os limiares de curto/aberto (ratio 0,94 contra 0,99). Inverter o divisor refaz toda a derivação de limiares |
| 21 | Numeração de pino do HT7333 em SOT-89-3 varia por fabricante | igual | igual | Conferir contra a folha de dados antes de fabricar |
| 22a | Furo USB-C Ø13,0 no invólucro sem conector correspondente | igual | igual | Fechado na v3 (J3). Na v1 e na v2 o furo existe no corpo e segue sem conector |
| 30 | v3: o NTC do TS lê a **placa**, não a célula | — | — | A placa fica acima da célula durante a carga, então o corte vem cedo, nunca tarde. Célula com NTC próprio (3 fios) tiraria a folga |
| 31 | v3: célula invertida **e** USB ligado ao mesmo tempo | — | — | O carregador sobe VBAT, liga o Q3 e injeta a pré-carga na célula invertida até VBAT cair abaixo do Vgs(th). Exige falha dupla; o JST-PH é polarizado. Saída em VBAT_RAW seria pior: a célula invertida conduziria pelo ESD do OUT mesmo sem USB |
| 32 | v3: nenhum código lê o CHG_N | — | — | O hardware está no IO7; o firmware ainda não sabe se está carregando |
| 33 | v3: modo próprio, PDN e vibração não foram recalculados | — | — | Contorno, furos e módulos são os da v2; as nove peças novas são estimadas em menos de 2 g. Declarado, não medido |
| 34 | v3: sem TVS no VBUS | — | — | O BQ21040 aguenta 30 V na entrada e desliga acima de 6,65 V (OVP). Descarga eletrostática no conector não está tratada |
| 23 | Rabicho u.FL → SMA fora da BOM | igual | igual | O Ra-02 tem IPEX; a ligação ao painel não está especificada |
| 24 | Não há código lendo a tensão da bateria | igual | igual | O caminho de hardware existe (IO6, divisor, capacitor); os limiares de REQ-SEG-29 não estão implementados |
| 26 | Modo próprio da placa cai 32% na v2 (2001 → 1352 Hz) e, a fs = 1000 Hz, dobra para 352 Hz | modal FEM em `hardware/fem/README.md` | Continua acima dos 1000 Hz da ISO nas duas versões, mas é mais um item que o DLPF do MPU6050 tem de rejeitar — configuração ainda pendente em `vibration_init` |
| 25 | A placa não parafusa nos bosses do invólucro em nenhuma das versões | furo M3 em (18; 18) pediria material até 28,2 mm na diagonal; o canto R7 da cavidade termina em 27,5 | recortes r=4,5 ficam exatamente sobre os eixos dos bosses | A fixação é o assento pelo aro mais os três M2 próprios. Os bosses seguram a tampa, não a placa |

## O que a geração verifica

- ERC com aviso tratado como erro
- DRC com zonas preenchidas; violação de regra é falha dura, item desconectado
  é contado contra linha de base declarada (**zero** nas três versões)
- contenção no contorno e colisão entre peças, separadas em mecânica e cobre
- distância de cada capacitor de desacoplamento ao pino que serve
- existência e validade de cada modelo 3D referenciado
- envelope, o que define a altura, interferência entre corpos e folga contra o
  vão da versão correspondente do invólucro
- derivados regerados a cada execução: netlist, BOM, STEP, renders

## Não verificado

- Se a pinagem confere com a peça física
- Numeração de pino do HT7333 em SOT-89-3
- Desempenho de RF, consumo real e qualquer medida de bancada
- Se o roteamento sobrevive à montagem: o gerador prova regras, não fabricação

## Reprodutibilidade

Apagando todos os derivados e regerando, `.kicad_sch`, `.kicad_pcb` e
`.kicad_sym` voltam **byte a byte idênticos**. O roteador é determinístico.

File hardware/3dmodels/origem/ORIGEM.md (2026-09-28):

# Modelos 3D de terceiros

A biblioteca do KiCad não traz corpo 3D para três footprints deste projeto —
nem a instalação local nem o repositório oficial `kicad-packages3D` têm
ESP32-S3-WROOM-1U, Ai-Thinker Ra-02 ou JST S2B-PH-SM4-TB. Os arquivos desta
pasta vieram da comunidade e estão AQUI COMO BAIXADOS, sem edição.

As versões alinhadas ficam um nível acima e são geradas por
`hardware/gen_3dmodels.py`, que aplica a transformação e CONFERE as cotas
contra o footprint. Nenhum arquivo desta pasta é usado direto pela placa.

| arquivo | componente | origem | licença |
|---|---|---|---|
| `wroom1u.step` | U1 ESP32-S3-WROOM-1U | [Lambosaurus/KicadLib](https://github.com/Lambosaurus/KicadLib) `Step/module/ESP32-S3-WROOM-1U.STEP` | MIT |
| `ra02.step` | U3 Ai-Thinker Ra-02 | [mithro/esp32-to-433mhz](https://github.com/mithro/esp32-to-433mhz) `hardware/3d/sx1278-lora-module.step` | Apache-2.0 |
| `jst.step` | J1 JST S2B-PH-SM4-TB | [arturo182/kicad-modules](https://github.com/arturo182/kicad-modules) `packages3D/Connector.3dshapes/S2B-PH-SM4-TB.step` | MIT |
| `lipo-2000mah-adafruit2011.step` | célula de referência do orçamento de energia | [adafruit/Adafruit_CAD_Parts](https://github.com/adafruit/Adafruit_CAD_Parts) `2011 2000mAh Battery` | MIT |
| `lipo-500mah-adafruit1578.step` | maior célula de catálogo que entra no vão | [adafruit/Adafruit_CAD_Parts](https://github.com/adafruit/Adafruit_CAD_Parts) `1578 500mAh battery` | MIT |

## Integridade

    06037d05aaa1940127b69baadd63fcbb76ba9f7f69717f7789735810c0756484  jst.step
    cde1f2fe047ceeaed014af076b08a75d97e699aa761d864a24c9a768c525e235  ra02.step
    f913932e97594461a5971a40dff8d53c90be6c1a7bb2da2fd58d6540b52c06bc  wroom1u.step

O `wroom1u.step` veio por Git LFS; o SHA256 acima confere com o `oid` do
ponteiro no repositório.

## O que precisou ser corrigido em cada um

Medido antes de usar, contra as cotas do footprint do projeto:

    WROOM-1U   18,00 x  3,35 x 19,20    deitado: Y é a espessura e Z o comprimento
    Ra-02      17,00 x 16,50 x  3,20    girado 90 graus, origem no canto (+8,50, -8,25)
    JST PH      7,90 x  8,65 x  5,60    alinhado; nenhuma transformação

Modelo de terceiro com eixo trocado é pior que modelo ausente: ele aparece,
parece certo de longe e mente sobre a altura. Por isso a conferência de cotas
está no gerador e falha a compilação, em vez de ficar num comentário.

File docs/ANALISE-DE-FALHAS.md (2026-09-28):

# Kaelix — Análise de Modos de Falha e Definição de Estados Seguros

Documento de segurança funcional do firmware Kaelix.
Base de código analisada: `src/` e `lib/` na revisão atual (superloop de um disparo,
modelo treinado e embarcado — `N_TREES = 100` —, leitura I2C do MPU6050 ainda
`NotImplemented`, pinos ainda marcados como `TODO`).

Método: FMEA de projeto enxuta, no espírito da IEC 60812:2018 (priorização por matriz
severidade × detectabilidade, **sem** RPN — números de ocorrência inventados não se
sustentam numa banca), com os princípios de determinismo, cota de laço e estado seguro
que DO-178C, ARP4761 e JSF++ exigem. O objetivo **não** é certificação: é que cada
decisão de projeto tenha uma razão escrita e rastreável.

---

## 1. Função, falha e classes de severidade

**Função do Kaelix (FUNC-1):** a cada 12 minutos, produzir uma caracterização confiável
do estado de vibração e temperatura de uma máquina e entregá-la ao gateway, dentro de um
orçamento de ~309 µA médio, por ~8,8 meses sem intervenção humana.

Falha é qualquer desvio dessa função. Para este dispositivo a falha mais grave **não** é
parar de funcionar — é continuar funcionando de forma aparentemente correta enquanto
produz dados que não mediu. Um dispositivo mudo é percebido; um dispositivo que mente é
acreditado.

### Classes de severidade

| Classe | Nome | Critério | Consequência típica |
|---|---|---|---|
| **S3** | Crítica | O gateway recebe dado inválido e o aceita como válido | Decisão de manutenção errada: máquina defeituosa declarada sadia, ou parada desnecessária |
| **S2** | Maior | Perda prolongada de função sem indicação, ou perda de energia que reduz a autonomia em mais de 50% | Dispositivo morre em campo; ninguém sabe quando nem por quê |
| **S1** | Moderada | Perda de um ou poucos ciclos, recuperável | Lacuna de 10 a 30 min na série temporal |
| **S0** | Menor | Sem efeito sobre a função ou sobre o orçamento de energia | — |

### Classes de detectabilidade (situação **atual**, não a desejada)

| Classe | Significado |
|---|---|
| **D-A** | O dispositivo detecta, classifica e reporta a falha |
| **D-B** | O dispositivo não detecta, mas o gateway consegue inferir a falha com os dados que já recebe |
| **D-C** | Silenciosa: nem o dispositivo nem o gateway têm como saber |

### Matriz de criticidade

Prioridade = combinação de severidade e detectabilidade atual. **S3/D-C é a categoria que
precisa desaparecer primeiro** — é a definição operacional de "falha perigosa não
detectada".

| | D-A | D-B | D-C |
|---|---|---|---|
| **S3** | Média | Alta | **Crítica** |
| **S2** | Baixa | Média | **Alta** |
| **S1** | Baixa | Baixa | Média |

---

## 2. Sumário dos modos de falha

| ID | Componente | Modo de falha | Sev. | Detecção hoje | Prioridade |
|---|---|---|---|---|---|
| FM-01 | MPU6050 / I2C | Ausente — não responde ao endereço 0x68 | S3 | D-C | **Crítica** |
| FM-02 | MPU6050 / I2C | Emudece no meio da rajada de 512 amostras | S3 | D-C | **Crítica** |
| FM-03 | MPU6050 / I2C | Barramento travado (SDA/SCL preso em nível baixo) | S2 | D-C | **Alta** |
| FM-04 | MPU6050 | Responde, mas devolve valor constante ou saturado (±16 g) | S3 | D-C | **Crítica** |
| FM-05 | Fixação mecânica | Sensor solto do corpo da máquina | S3 | D-C | **Crítica** |
| FM-06 | NTC / ADC | Termistor aberto (fio rompido, solda fria) | S3 | D-C | **Crítica** |
| FM-07 | NTC / ADC | Termistor em curto ou divisor em curto para GND | S3 | D-C | **Crítica** |
| FM-08 | NTC / ADC | Leitura feita antes do divisor estabilizar | S3 | D-C | **Alta** |
| FM-09 | SX1278 / SPI | `begin()` falha — rádio ausente, SPI mudo ou frequência rejeitada | S1 | D-B | Média |
| FM-10 | SX1278 / SPI | `sleep()` falha e o retorno é descartado — rádio fica em standby | S2 | D-C | **Alta** |
| FM-11 | Enlace LoRa | Pacote perdido no ar (alcance, colisão, interferência) | S1 | D-B | Baixa |
| FM-12 | Enlace LoRa | Colisão sistemática entre dois Kaelix na mesma planta | S2 | D-B | Média |
| FM-13 | Enlace LoRa | Dado corrompido que passa no CRC-16 | S3 | D-C | Média |
| FM-14 | Sistema | Dispositivo morto — silêncio indistinguível de perda de pacote | S2 | D-B | **Alta** |
| FM-15 | Bateria | Tensão abaixo do mínimo — brownout durante o TX | S2 | D-C | **Alta** |
| FM-16 | Bateria | Descarga profunda irreversível da célula LiPo | S2 | D-C | **Alta** |
| FM-17 | Firmware | Travamento — laço bloqueante sem watchdog | S2 | D-C | **Alta** |
| FM-18 | Firmware | Reset em laço consumindo a bateria a 40 mA | S2 | D-C | **Alta** |
| FM-19 | Isolation Forest | Árvore corrompida — travessia sem cota de profundidade | S2 | D-C | **Alta** |
| FM-20 | Isolation Forest | Índice de feature fora de faixa — leitura fora dos limites | S3 | D-C | **Crítica** |
| FM-21 | Isolation Forest | `n_trees == 0` / ponteiro nulo — divisão por zero e deref | S2 | D-C | **Alta** |
| FM-22 | Isolation Forest | Modelo placeholder: veredito sempre `Normal` | S3 | D-C | **Crítica** |
| FM-23 | Inferência | Feature NaN — comparação falha para o lado "Normal" | S3 | D-C | **Crítica** |
| FM-24 | Deep sleep | Não desperta — silêncio permanente | S2 | D-B | **Alta** |
| FM-25 | Deep sleep | `minutes == 0` ou wakeup mal configurado — acorda de imediato | S2 | D-C | **Alta** |
| FM-26 | Corte de energia | Load switch não corta — periféricos alimentados durante o sleep | S2 | D-C | **Alta** |
| FM-27 | Corte de energia | Pull-ups do I2C alimentam o MPU6050 pelos pinos de sinal | S2 | D-C | ~~Média~~ eliminada por projeto |
| FM-28 | Temperatura | Ambiente acima de +85 °C — fora da faixa do SoC e da célula | S2 | D-B | Média |
| FM-29 | Temperatura | Ambiente abaixo de 0 °C — resistência interna da célula sobe | S2 | D-C | Média |
| FM-30 | Processamento | FFT com `n` que não é potência de 2 — espectro silenciosamente errado | S3 | D-C | Média |
| FM-31 | Memória | `std::vector` por ciclo — fragmentação e `bad_alloc` não tratado | S2 | D-C | **Alta** |
| FM-32 | Memória | `new Module(...)` em inicialização estática — falha antes de `main()` | S2 | D-C | Média |
| FM-33 | Telemetria | `boot_count` zera em qualquer reset que não seja saída do deep sleep | S2 | D-C | **Alta** |
| FM-34 | Telemetria | Causa do reset nunca é lida nem reportada | S2 | D-C | **Alta** |
| FM-35 | Amostragem | Jitter na taxa de 1 kHz — frequência dominante enviesada | S3 | D-C | Média |
| FM-36 | Tempo | Sem carimbo de tempo no dispositivo | S1 | D-B | Baixa |

---

## 3. FMEA detalhada

Cada item traz o requisito de segurança derivado (`REQ-SEG-nn`), que é o elo de
rastreabilidade da seção 9.

---

### Grupo A — Aquisição de vibração (MPU6050 / I2C)

#### FM-01 — MPU6050 ausente: não responde ao endereço 0x68

- **Causa:** conector solto, solda fria, sensor não populado, rail +3V3_SW que não voltou depois do sono, pull-ups do I2C ausentes.
- **Efeito local:** `sensors::vibration_init()` devolve `false`. Hoje isso está sempre acontecendo: `src/sensors/vibration.cpp:17` retorna `false` incondicionalmente, e `vibration_read_features()` produz features sobre um buffer de zeros (`src/sensors/vibration.cpp:21`).
- **Efeito no sistema:** **este é o modo de falha mais grave do projeto.** `src/main.cpp:33-35` apenas imprime no `Serial` — que em campo não vai a lugar nenhum — e segue adiante. O ciclo transmite `rms = 0.0`, `status = Normal`, CRC íntegro. O gateway recebe um pacote perfeitamente formado dizendo que a máquina está sadia e parada. Não há como distinguir isso de uma máquina realmente desligada. **Dado fabricado apresentado como medição.** S3.
- **Como é detectado hoje:** não é. O retorno de `vibration_init()` não altera nenhum comportamento observável de fora do dispositivo.
- **Mitigação:**
  - **REQ-SEG-01** — Nenhum campo do pacote pode conter valor que o dispositivo não mediu. Cada campo de medição tem um bit correspondente em uma máscara de validade transmitida; campo inválido vai com o bit zerado e conteúdo definido (0), nunca com valor plausível.
  - **REQ-SEG-02** — `vibration_init()` deve confirmar a presença do sensor lendo `WHO_AM_I` (0x75, esperado 0x68/0x70) e comparar com o valor esperado, não apenas concluir a transação I2C.
  - **REQ-SEG-03** — Falha de inicialização de sensor leva o ciclo ao estado `DEGRADADO-DADO` (seção 5), que transmite com `status = DEGRADED` e código de falha, e não executa a inferência.

#### FM-02 — MPU6050 emudece no meio da rajada de 512 amostras

- **Causa:** ESD, glitch de alimentação durante o TX, aquecimento, vibração afrouxando o conector.
- **Efeito local:** parte das amostras é lida e o restante devolve `0xFF` ou timeout. A leitura I2C do core Arduino do ESP32 tem timeout padrão de ~50 ms por transação. 512 amostras em timeout = até ~25 s de fase ativa contra os 3 s orçados — 8 vezes o orçamento de energia do ciclo, e mais que qualquer janela de watchdog razoável.
- **Efeito no sistema:** um sinal metade real, metade lixo produz RMS, curtose e FFT sem significado físico, transmitidos como medição válida. S3. E a fase ativa estendida corrói a autonomia.
- **Como é detectado hoje:** não é. A leitura ainda não existe; quando existir, nada no desenho atual conta erros de transação.
- **Mitigação:**
  - **REQ-SEG-04** — A rajada conta transações falhas. Acima de 1% das amostras (5 de 512), o bloco inteiro é declarado inválido; features de vibração não são calculadas nem transmitidas como válidas.
  - **REQ-SEG-05** — A rajada tem prazo absoluto (deadline) de 1,5 s. Estourado o prazo, aborta e devolve erro — o laço de amostragem nunca é ilimitado (JSF++ AV-197).
  - **REQ-SEG-06** — O número de amostras perdidas vai na telemetria (seção 6), para que a degradação seja visível antes de virar travamento.

#### FM-03 — Barramento I2C travado (SDA ou SCL preso em nível baixo)

- **Causa:** escravo que perdeu a sincronia de clock e segura SDA aguardando pulsos; reset do mestre no meio de uma transação.
- **Efeito local:** toda transação seguinte falha. Sem recuperação, o sensor fica inacessível até um ciclo de energia completo.
- **Efeito no sistema:** perda permanente da função de vibração, com o dispositivo aparentemente vivo. S2.
- **Como é detectado hoje:** não é.
- **Mitigação:**
  - **REQ-SEG-07** — Antes de `Wire.begin()`, o barramento é destravado: até 9 pulsos manuais em SCL com SDA em entrada, seguidos de uma condição de STOP. Cota fixa de 9 pulsos, nunca "até destravar".
  - **REQ-SEG-08** — O corte de energia dos periféricos entre ciclos já dá um ciclo de energia a cada 12 min; isso deve ser registrado como argumento de projeto — o `peripherals_power(false)` é também uma mitigação de travamento de barramento, não só de economia.

#### FM-04 — MPU6050 responde, mas devolve valor constante ou saturado

- **Causa:** MEMS danificado por choque, faixa configurada errada (±2 g com máquina que excede), registro de configuração corrompido, sensor em modo de auto-teste.
- **Efeito local:** as amostras existem, mas não representam a máquina. Amostras todas iguais fazem `compute_kurtosis` cair no ramo `m2 == 0.0` e retornar exatamente 0 (`lib/signal_processing/signal_processing.cpp:33`), e `compute_crest_factor` retornar 0 (linha 39).
- **Efeito no sistema:** features degeneradas alimentam o Isolation Forest e produzem um veredito arbitrário. S3.
- **Como é detectado hoje:** não é. Curtose exatamente 0 e fator de crista exatamente 0 são resultados matematicamente corretos para sinal constante e indistinguíveis de resultado válido no formato atual do pacote.
- **Mitigação:**
  - **REQ-SEG-09** — Verificação de plausibilidade do bloco: variância nula, saturação em mais de 1% das amostras e RMS abaixo do piso de ruído do sensor invalidam o bloco.
  - **REQ-SEG-10** — Os ramos degenerados (`m2 == 0`, `rms == 0`) devem sinalizar "indefinido" ao chamador em vez de devolver 0 — 0 é um valor legítimo do domínio e não pode servir de código de erro (violação nº 3, modelo de erro).

#### FM-05 — Sensor fisicamente solto do corpo da máquina

- **Causa:** adesivo/parafuso cedendo por vibração e ciclo térmico.
- **Efeito local:** o acelerômetro mede o próprio invólucro balançando, não a máquina.
- **Efeito no sistema:** série temporal plausível, fisicamente falsa; a assinatura de desbalanceamento desaparece. S3. É a falha que a instrumentação de vibração industrial mais teme, e nenhum software a detecta diretamente.
- **Como é detectado hoje:** não é.
- **Mitigação:**
  - **REQ-SEG-11** — Monitorar o vetor gravidade (componente DC dos três eixos): módulo distante de 1 g ou mudança abrupta de orientação entre ciclos indica montagem comprometida; sinalizar `MOUNT_SUSPECT` na telemetria.
  - Mitigação principal é de processo, não de software: torque e inspeção de fixação no procedimento de instalação.

---

### Grupo B — Temperatura (NTC 10k / ADC)

#### FM-06 — Termistor aberto

- **Causa:** fio rompido pela vibração, solda fria, conector oxidado.
- **Efeito local:** o nó de leitura é puxado para Vcc pelo resistor fixo de 10 k. `ntc_resistance_from_adc` (`lib/thermistor/thermistor.cpp:10-12`) satura a razão em 0,999 e devolve até 9,99 MΩ.
- **Efeito no sistema:** com os parâmetros atuais (beta 3950, R nominal 10 k, 25 °C), a conversão produz **cerca de −26 °C** para leitura no topo de escala do ADC (~3100 mV) e **−77 °C** no limite absoluto do clamp. São `float` finitos, passam pelo CRC e chegam ao gateway como temperatura. S3.
- **Como é detectado hoje:** não é. O clamp em `thermistor.cpp` foi escrito para evitar divisão por zero e, sem querer, **converte uma falha de hardware detectável em um número plausível** — o clamp esconde exatamente a informação que denunciaria a falha.
- **Mitigação:**
  - **REQ-SEG-12** — O clamp deixa de ser silencioso: razão fora de [0,02; 0,98] é falha de sensor (aberto/curto) e retorna erro, não um valor saturado.
  - **REQ-SEG-13** — Faixa de plausibilidade da temperatura no dispositivo: leitura fora de [−40 °C, +125 °C] invalida o campo (bit de validade zerado).

#### FM-07 — Termistor em curto ou divisor em curto para GND

- **Causa:** solda escorrida, esmagamento do cabo, umidade.
- **Efeito local:** razão vai a zero, clamp em 0,001, resistência ≈ 10 Ω.
- **Efeito no sistema:** a conversão devolve **+349 °C**. Novamente um `float` finito, com CRC válido, indistinguível de leitura real no formato de pacote atual. Se o gateway tiver alarme de sobretemperatura, dispara uma parada de máquina por causa de uma solda ruim. S3.
- **Como é detectado hoje:** não é.
- **Mitigação:** REQ-SEG-12 e REQ-SEG-13.

#### FM-08 — Leitura feita antes de o divisor estabilizar

- **Causa:** o divisor do NTC é alimentado pelo mesmo rail +3V3_SW do MPU6050 (`src/power/sleep.cpp:14-32`). `PERIPHERAL_SETTLE_MS = 100` (`src/main.cpp:18`) é uma estimativa, não uma medição. Se a constante de tempo do nó (capacitância de filtro × 10 k) for maior, a leitura pega o transitório.
- **Efeito local:** temperatura enviesada para baixo (nó ainda subindo).
- **Efeito no sistema:** deriva sistemática em todas as leituras, invisível porque é consistente. S3 por ser um erro sistemático não detectável.
- **Como é detectado hoje:** não é.
- **Mitigação:**
  - **REQ-SEG-14** — O tempo de estabilização é medido no banco (osciloscópio no nó do divisor) e o valor adotado é o medido com margem de 3×, registrado com a evidência. Enquanto não medido, permanece como premissa aberta (seção 10).
  - **REQ-SEG-15** — Média de N leituras consecutivas com descarte da primeira, e verificação de que a dispersão entre elas está abaixo de um limite (leituras instáveis = ainda em transitório).

---

### Grupo C — Enlace de rádio (SX1278 / SPI / LoRa)

#### FM-09 — `begin()` falha: rádio ausente, SPI mudo ou frequência rejeitada

- **Causa:** módulo não populado, CS/RST/DIO0 nos pinos errados (ainda `TODO` em `src/comms/lora.cpp:10-13`), SPI sem clock, cristal de 32 MHz fora de especificação fazendo `begin(433.0)` devolver `RADIOLIB_ERR_INVALID_FREQUENCY`.
- **Efeito local:** `lora_init()` devolve `false` (`src/comms/lora.cpp:45-51`), colapsando três causas distintas — versão de chip errada (`RADIOLIB_ERR_CHIP_NOT_FOUND`, −2), SPI mudo, e frequência rejeitada (−12) — em um único bit. É exatamente a violação nº 3 do levantamento: o valor de `state` existe, tem a informação, e é jogado fora na linha seguinte.
- **Efeito no sistema:** `src/main.cpp:51` pula a transmissão. O ciclo é medido e descartado; 12 minutos de dados perdidos por ciclo. Se a causa for permanente, o dispositivo fica **completamente mudo para sempre** e a manutenção não tem informação alguma para diagnosticar sem ir até a máquina. S1 por ciclo, S2 se persistente.
- **Como é detectado hoje:** D-B — o gateway percebe o silêncio, mas não sabe a causa nem se o dispositivo está vivo.
- **Mitigação:**
  - **REQ-SEG-16** — Modelo de erro tipado substituindo `bool`: um `enum class Error : uint8_t` por subsistema, propagado até o topo e **transmitido** no campo `fault_code` (seção 6). "Rádio ausente", "SPI mudo" e "frequência rejeitada" precisam ser distinguíveis do lado do gateway.
  - **REQ-SEG-17** — Rotina de recuperação antes de desistir: pulso de reset por hardware no pino RST, nova tentativa, no máximo 2 vezes (cota fixa).
  - **REQ-SEG-18** — Medições que não puderam ser transmitidas são guardadas em um buffer circular na RTC slow memory (8 KB disponíveis; ~40 registros de 12 bytes = quase 7 h de histórico) e enviadas em rajada quando o enlace voltar.

#### FM-10 — `lora_sleep()` falha e o retorno é descartado

- **Causa:** rádio em estado inconsistente, SPI intermitente, `lora_init()` falhou e `main.cpp:61` chama `lora_sleep()` sobre um rádio que nunca respondeu.
- **Efeito local:** `bool lora_sleep()` devolve `false` e **`src/main.cpp:61` ignora o retorno**. O SX1278 permanece em standby.
- **Efeito no sistema:** o próprio código documenta a conta (`src/comms/lora.h:51-56` e `src/power/sleep.cpp:32-33`): standby custa 1,5 mA durante 720 s = 1080 mA·s por ciclo, contra 174 mA·s do ciclo inteiro. O consumo efetivo sobe de 309 µA para ~1,83 mA e a autonomia cai de ~269 dias para **~48 dias**. O dispositivo morre em campo seis meses antes do previsto, e nada indica o porquê. S2, e é a maior ameaça isolada ao orçamento de energia.
- **Como é detectado hoje:** não é. Não há medição de bateria; a única evidência seria o dispositivo morrer cedo.
- **Mitigação:**
  - **REQ-SEG-19** — O retorno de `lora_sleep()` é obrigatoriamente verificado. `[[nodiscard]]` em todas as funções que reportam falha.
  - **REQ-SEG-20** — Fallback de hardware: se `sleep()` não confirmar, o pino RST é mantido em nível ativo antes do deep sleep, forçando o rádio ao estado de menor consumo independentemente do estado do firmware do módulo.
  - **REQ-SEG-21** — O evento entra no `fault_code` do próximo pacote — uma vez que o rádio volte, o gateway fica sabendo que houve um ciclo com fuga de corrente.
  - **INV-1** (invariante, seção 5): o rádio nunca entra no período de sleep em standby.

#### FM-11 — Pacote perdido no ar

- **Causa:** alcance, obstrução metálica, interferência em 433 MHz, desvanecimento.
- **Efeito local:** `transmit()` retorna sucesso — o SX1278 confirma que emitiu, não que alguém recebeu. Não há ACK.
- **Efeito no sistema:** lacuna de um ciclo. `boot_count` permite ao gateway detectar a lacuna depois. S1.
- **Como é detectado hoje:** D-B, pela descontinuidade de `boot_count`. Este é um ponto em que o projeto já acertou.
- **Mitigação:**
  - **REQ-SEG-22** — Manter o envio sem ACK (ACK custaria janela de RX e energia), e compensar com REQ-SEG-18: reenviar as últimas N leituras junto com a atual, de forma que uma perda isolada seja recuperada no ciclo seguinte sem transmissão adicional.

#### FM-12 — Colisão sistemática entre dois Kaelix na mesma planta

- **Causa:** `lora_init()` não configura sync word, spreading factor, largura de banda, coding rate nem preâmbulo — todos ficam nos padrões do RadioLib. Dois dispositivos acordam por timers independentes de 12 min; se as janelas se aproximarem, a deriva relativa dos osciladores é pequena e elas podem ficar sobrepostas por dezenas de ciclos seguidos.
- **Efeito local:** ambos transmitem, nenhum é decodificado.
- **Efeito no sistema:** dois dispositivos ficam mudos simultaneamente e de forma persistente. S2.
- **Como é detectado hoje:** D-B, e apenas se alguém correlacionar os silêncios.
- **Mitigação:**
  - **REQ-SEG-23** — Parâmetros de rádio explicitamente fixados no código (SF, BW, CR, sync word, preâmbulo, potência) — nunca herdados de padrão de biblioteca, para que o pacote no ar seja determinístico e rastreável a uma linha de código.
  - **REQ-SEG-24** — Dispersão pseudoaleatória do instante de despertar: ±15 s derivados do `device_id`, o que descorrelaciona permanentemente as janelas de dispositivos diferentes ao custo de nada em energia.

#### FM-13 — Dado corrompido que passa no CRC-16

- **Causa:** o CRC-16/CCITT (`lib/crc16/crc16.cpp`) detecta todas as rajadas de até 16 bits e deixa passar ~1 em 65536 dos padrões restantes. O LoRa já tem CRC próprio na camada física; este é o CRC fim-a-fim.
- **Efeito local:** pacote aceito com um `float` alterado.
- **Efeito no sistema:** leitura errada aceita como boa. S3, mas com probabilidade baixa e com defesa já existente.
- **Como é detectado hoje:** parcialmente — o CRC existe, é testado no host, e usa o vetor de conferência padrão (`crc16_ccitt("123456789") == 0x29B1`). Boa prática já aplicada.
- **Mitigação:**
  - **REQ-SEG-25** — Faixas de plausibilidade no gateway como segunda barreira: RMS, temperatura e frequência dominante fora de faixa física derrubam o pacote mesmo com CRC válido. Defesa em profundidade, custo zero no dispositivo.

#### FM-14 — Dispositivo morto, silêncio indistinguível de perda de pacote

- **Causa:** qualquer falha terminal — bateria esgotada, travamento sem watchdog, deep sleep sem despertar, dano físico.
- **Efeito local:** nenhum pacote é emitido.
- **Efeito no sistema:** o gateway vê silêncio. Como não existe cadência declarada nem heartbeat, o silêncio de um dispositivo morto é igual ao de um dispositivo com o rádio momentaneamente ruim. S2.
- **Como é detectado hoje:** D-B, e só se o operador do gateway estiver ativamente esperando pacotes daquele `device_id`.
- **Mitigação:**
  - **REQ-SEG-26** — O gateway monitora cadência: ausência por mais de 2 períodos consecutivos gera alarme de dispositivo. É regra de gateway, mas é requisito de segurança do sistema e precisa estar escrito aqui.
  - **REQ-SEG-27** — Todo estado do dispositivo, inclusive os degradados, mantém emissão periódica (ver seção 5, INV-4: "sempre audível"). Um Kaelix que decide se calar é indistinguível de um Kaelix quebrado; nenhum estado seguro pode ser mudo, exceto o de proteção terminal da bateria — e esse é anunciado antes de ser entrado.

---

### Grupo D — Energia e bateria

#### FM-15 — Tensão abaixo do mínimo: brownout durante o TX

- **Causa:** o TX a 17 dBm puxa ~90-120 mA. Com a célula perto do fim, resistência interna alta e o dropout do HT7333, o trilho afunda no instante do pulso de transmissão. O detector de brownout do ESP32-S3 dispara reset.
- **Efeito local:** reset no meio da transmissão. O ciclo recomeça, energiza os periféricos, amostra, e transmite de novo — provocando outro brownout.
- **Efeito no sistema:** **laço de brownout**: o dispositivo passa a operar em fase ativa quase contínua a ~40 mA em vez de 309 µA, queimando a carga residual em horas e destruindo qualquer chance de a última mensagem sair. S2.
- **Como é detectado hoje:** não é. `esp_reset_reason()` nunca é chamado; não há medição de tensão.
- **Mitigação:**
  - **REQ-SEG-28** — `esp_reset_reason()` é lido nas primeiras linhas de `setup()`. Reset por brownout ou por pânico **não** repete o ciclo normal: entra na escalada de falhas da seção 5.
  - **REQ-SEG-29** — Medir a tensão da bateria antes de decidir transmitir. Abaixo de um limiar operacional (a definir com a curva real da célula; ponto de partida 3,45 V sob carga), reduzir a potência de TX para 10 dBm; abaixo do limiar crítico, não transmitir em 17 dBm de forma alguma.
  - **REQ-SEG-30** — Capacitor de reservatório (centenas de µF) próximo ao módulo de rádio dimensionado para o pulso de TX. Mitigação de hardware — a de software sozinha não resolve.

#### FM-16 — Descarga profunda irreversível da célula

- **Causa:** o dispositivo continua tentando cumprir a função até a célula chegar abaixo da tensão de corte. Sem BMS com corte confiável, a LiPo sofre dano permanente.
- **Efeito local:** célula inutilizada.
- **Efeito no sistema:** perda do dispositivo e do ativo, não só do ciclo. S2.
- **Como é detectado hoje:** não é.
- **Mitigação:**
  - **REQ-SEG-31** — Estado `DORMENTE-BATERIA` (seção 5): abaixo do limiar crítico, o dispositivo emite um último pacote anunciando o desligamento e entra em deep sleep **sem timer de despertar**. Esta é a única situação em que o silêncio é o comportamento seguro, e ela é anunciada antes de acontecer.

---

### Grupo E — Execução do firmware

#### FM-17 — Travamento: laço bloqueante sem watchdog

- **Causa:** travessia de árvore sem cota (FM-19), rajada I2C que nunca completa (FM-02/FM-03), `transmit()` bloqueante do RadioLib esperando DIO0 que nunca sobe porque o pino está errado (`src/comms/lora.cpp:12`, ainda `TODO`).
- **Efeito local:** `setup()` nunca chega a `deep_sleep()`. A CPU fica em fase ativa a ~40 mA indefinidamente.
- **Efeito no sistema:** dispositivo mudo **e** consumindo 115 vezes o orçamento. A bateria de 2000 mAh acaba em ~50 h. Ninguém percebe até o silêncio ser notado, e a essa altura já não há energia nem para reportar. S2.
- **Como é detectado hoje:** não é. Não há watchdog armado (violação nº 5).
- **Mitigação:** política completa na seção 5. **REQ-SEG-32** — RTC WDT armado antes de qualquer periférico ser energizado.

#### FM-18 — Reset em laço consumindo a bateria

- **Causa:** consequência direta da mitigação de FM-17 mal desenhada. Se o watchdog reinicia e o firmware volta a travar no mesmo ponto, o ciclo é travar → resetar → travar.
- **Efeito local:** boots consecutivos.
- **Efeito no sistema:** com janela de 15 s a ~40 mA, 2000 mAh se esgotam em ~50 h. **O reset, sozinho, não é um estado seguro** — é uma máquina de destruir bateria. Este é o argumento central da seção 5. S2.
- **Como é detectado hoje:** não é. Pior: `boot_count` está em `RTC_DATA_ATTR` e, como explicado em FM-33, é **zerado** em resets que não sejam saída de deep sleep — o laço de reset apagaria a própria evidência.
- **Mitigação:**
  - **REQ-SEG-33** — Contador de falhas consecutivas em `RTC_NOINIT_ATTR`, protegido por palavra mágica e CRC, com escalada obrigatória para o estado `QUARENTENA` (seção 5).

#### FM-19 — Árvore do Isolation Forest corrompida: travessia sem cota

- **Local:** `lib/isolation_forest/isolation_forest.cpp:17`
  ```cpp
  while (tree.feature[node] != -1) {
      node = (features[tree.feature[node]] < tree.threshold[node]) ? tree.left[node] : tree.right[node];
      ++depth;
  }
  ```
- **Causa:** bit flip na flash (a SPI flash externa não tem ECC por padrão), exportador de modelo com defeito gerando um ciclo `left[a] = b, left[b] = a`, ou índice apontando para além do array.
- **Efeito local:** laço infinito, ou leitura fora dos limites do array. `depth` é incrementado sem teto — em uma árvore cíclica, o laço nunca termina.
- **Efeito no sistema:** travamento permanente a 40 mA (ver FM-17). S2, e é a violação nº 2 do levantamento confirmada.
- **Como é detectado hoje:** não é.
- **Mitigação:**
  - **REQ-SEG-34** — Cota de profundidade explícita: `for (int d = 0; d < MAX_TREE_DEPTH; ++d)`, com `MAX_TREE_DEPTH` derivado de `ceil(log2(SUBSAMPLE_SIZE)) + margem` (com `SUBSAMPLE_SIZE = 256`, um limite de 32 é folgado). Estourar a cota é falha declarada, não veredito.
  - **REQ-SEG-35** — CRC-16 sobre o blob do modelo, calculado na exportação, embarcado como constante e verificado uma vez em `model_init()`. Modelo com CRC divergente = subsistema de inferência indisponível, e o dispositivo transmite features sem veredito em vez de um veredito falso.

#### FM-20 — Índice de feature fora de faixa

- **Local:** mesma linha. `features[tree.feature[node]]` — `tree.feature[node]` é `int16_t` e nada garante que esteja em [0, `N_FEATURES`). `node` também é `int16_t` e pode ser negativo, indexando `tree.feature[node]` **antes** do início do array.
- **Causa:** as mesmas de FM-19.
- **Efeito local:** leitura de memória arbitrária. No ESP32-S3 não há MMU protegendo essa região do jeito que se esperaria em um host; a leitura provavelmente **não** gera exceção — devolve lixo interpretado como `float`.
- **Efeito no sistema:** um score de anomalia calculado sobre bytes aleatórios da RAM, transmitido como veredito. É pior que travar: **o travamento é detectável, o veredito falso não é.** S3.
- **Como é detectado hoje:** não é. Não há uma única asserção nem validação de índice no módulo (violação nº 4 confirmada).
- **Mitigação:**
  - **REQ-SEG-36** — Validação de faixa em cada passo: `feature ∈ [0, N_FEATURES)`, `node ∈ [0, n_nodes)`. Índice fora de faixa aborta a travessia e devolve erro.
  - **REQ-SEG-37** — `n_nodes` passa a ser campo da `struct IsolationTree`. Hoje a struct carrega cinco ponteiros e uma raiz, e **nenhum tamanho** — é estruturalmente impossível validar um índice contra um array cujo tamanho não se conhece. Esta é uma falha de projeto do tipo de dado, não do laço.

#### FM-21 — `n_trees == 0` ou ponteiro de árvores nulo

- **Local:** `lib/isolation_forest/isolation_forest.cpp:29` — `total_path / float(n_trees)`; e `src/ml/isolation_forest_data.h` declara `isolation_forest_trees = nullptr`.
- **Causa:** chamar `isolation_forest_score()` no estado atual do repositório.
- **Efeito local:** divisão de 0,0 por 0,0 = NaN, e `trees[i]` desreferencia o ponteiro nulo antes disso.
- **Efeito no sistema (análise original):** `model.cpp` protegia com uma guarda no **chamador** — convenção documentada em comentário, não propriedade da função. Qualquer outro chamador (um teste, um refactor futuro) quebrava. S2.
- **Como é detectado hoje:** **mitigado.** `isolation_forest_score` valida as próprias pré-condições (`isolation_forest.cpp:129-139`): ponteiros nulos ⇒ `NullPointer`, `subsample_size <= 1` ⇒ `InvalidArgument`, `n_trees <= 0` ⇒ `ModelAbsent`. A guarda passou para o provedor do serviço, e `model.cpp:35` a complementa com `isolation_forest_validate`.
- **Mitigação:**
  - **REQ-SEG-38** — Validação de pré-condição dentro da própria função: `trees != nullptr && n_trees > 0 && subsample_size > 1`, devolvendo erro tipado. A guarda pertence ao provedor do serviço, não ao consumidor (princípio de contrato defensivo em fronteira de módulo).

#### FM-22 — Modelo ausente confundido com veredito `Normal` — **mitigado**

- **Local:** `src/ml/model.cpp:35` e `:59` (guarda `N_TREES <= 0`); `src/ml/isolation_forest_data.h:12` (hoje `N_TREES = 100`).
- **Causa (original):** o treino ainda não havia gerado as árvores, e a guarda devolvia `Normal`.
- **Efeito local (original):** `model_init()` devolvia falso e `model_infer()` devolvia `Normal` sempre.
- **Estado atual:** as duas metades foram fechadas. A guarda devolve `Status::ModelAbsent` (`0x30`, `"NO_MODEL"`) e deixa o veredito em `MachineState::Unknown` — nunca `Normal`. E o modelo treinado no MAFAULDA está embarcado, então o caminho da guarda deixou de ser o normal. O `diag` do pacote carrega o código ao gateway.
- **Efeito no sistema:** todo pacote sai com `status = Normal`. O gateway não tem como saber que **não há modelo embarcado**: um "Normal" sem modelo é byte a byte idêntico a um "Normal" com modelo. Um dispositivo com firmware de desenvolvimento instalado por engano em uma máquina real declara-a sadia para sempre. S3, e a mesma classe de FM-01: **dado fabricado com aparência de medição**.
- **Como é detectado hoje:** não é. A mensagem existe, mas só no `Serial` (`src/main.cpp:40`).
- **Mitigação:**
  - **REQ-SEG-39** — `Status` deixa de ser binário. Passa a ter, no mínimo: `Normal`, `Anomalous`, `Degraded` (medição parcial), `Unavailable` (sem inferência), `Fault`. `Unavailable` é o valor quando não há modelo.
  - **REQ-SEG-40** — Identificação do modelo (hash de 16 bits do blob treinado) transmitida em todo pacote. Sem ela, não há rastreabilidade entre um veredito de campo e o modelo que o produziu — e nenhuma análise post-mortem é possível depois de um retreino.

#### FM-23 — Feature NaN: a comparação falha para o lado "Normal"

- **Local:** `src/ml/model.cpp:24` — `return score > ANOMALY_THRESHOLD ? Status::Anomalous : Status::Normal;`
- **Causa:** qualquer NaN a montante — `dominant_frequency` sobre amostras com Inf, divisão degenerada, ponteiro lido fora de faixa (FM-20).
- **Efeito local:** **toda comparação com NaN é falsa em IEEE 754.** `NaN > threshold` é falso, então o operador ternário escolhe `Status::Normal`.
- **Efeito no sistema:** dado corrompido resulta sistematicamente em "máquina sadia". A falha tem direção: **falha para o lado inseguro**. É o pior padrão possível em uma decisão de segurança e está em uma única linha de código. S3.
- **Como é detectado hoje:** não é.
- **Mitigação:**
  - **REQ-SEG-41** — Toda comparação de decisão é escrita para falhar no sentido seguro: validar `std::isfinite(score)` **antes** de comparar, e tratar não finito como `Fault`, jamais como `Normal`.
  - **REQ-SEG-42** — `std::isfinite` em toda feature na fronteira entre processamento de sinal e inferência.

#### FM-30 — FFT com `n` que não é potência de 2

- **Local:** `lib/signal_processing/signal_processing.cpp:49` e `:88`. O cabeçalho documenta "`n` deve ser potência de 2" (`signal_processing.h:23-24`), mas **nada verifica**. `dominant_frequency` só rejeita `n < 4` (linha 90).
- **Causa:** um chamador futuro passando 500 em vez de 512; ou uma rajada abortada devolvendo menos amostras que o pedido.
- **Efeito local:** o laço de borboletas `for (len = 2; len <= n; len <<= 1)` simplesmente para cedo e a permutação bit-reversal fica inconsistente. Não há erro, não há travamento — o espectro sai **silenciosamente errado**.
- **Efeito no sistema:** frequência dominante inventada, alimentando o modelo. S3.
- **Como é detectado hoje:** não é. Não há asserção alguma no módulo (violação nº 4).
- **Mitigação:**
  - **REQ-SEG-43** — Contrato verificável: `n` potência de 2 checado em tempo de compilação onde o tamanho é constante (`static_assert`), e em tempo de execução na fronteira pública, com erro tipado.
  - **REQ-SEG-44** — Como `dominant_frequency` só é chamada com 512, o caminho correto é aceitar um tamanho de compilação (`template<size_t N>` ou parâmetro `constexpr`), o que resolve simultaneamente este item e FM-31.
- **Observação adicional:** `best_mag` inicia em −1,0 e é comparado com magnitudes; se todas forem NaN, nenhuma comparação é verdadeira e a função devolve o **bin inferior da banda** como se fosse o pico. Mais uma falha silenciosa para o lado plausível.

#### FM-31 — `std::vector` por ciclo: fragmentação e `bad_alloc` não tratado

- **Local:** `lib/signal_processing/signal_processing.cpp:92-93` (dois vetores de `n` floats = ~4 KB com n=512) e `src/sensors/vibration.cpp:21` (mais 2 KB).
- **Causa:** violação nº 1 do levantamento — alocação dinâmica depois da inicialização (JSF++ AV-206, MISRA C++ 18-4-1).
- **Efeito local:** ~6 KB de heap alocados e liberados a cada ciclo. O padrão alocar-liberar é regular, então a fragmentação é improvável aqui, mas o argumento de segurança não é probabilístico: **o tempo de execução e o sucesso da alocação deixam de ser determináveis estaticamente**, que é justamente o que DO-178C exige poder afirmar sobre uso de memória.
- **Efeito no sistema:** se a alocação falhar, com exceções habilitadas há `std::bad_alloc` não capturado → `std::terminate` → `abort` → reset; sem exceções, `abort` direto. Em ambos os casos: reset silencioso, sem diagnóstico, e potencialmente em laço (FM-18). S2.
- **Como é detectado hoje:** não é.
- **Mitigação:**
  - **REQ-SEG-45** — Buffers estáticos de tamanho fixo dimensionados para o pior caso (512 amostras), declarados em escopo de arquivo, com o consumo de RAM documentado e verificado no mapa de memória do build.
  - **REQ-SEG-46** — `-fno-exceptions` e proibição de `new`/`malloc` após a inicialização, verificada por análise estática (`clang-tidy: cppcoreguidelines-no-malloc`, `hicpp-no-malloc`) e por inspeção do mapa de link.

#### FM-32 — `new Module(...)` em inicialização estática

- **Local:** `src/comms/lora.cpp:17` — `static SX1278 radio = new Module(LORA_CS_PIN, LORA_DIO0_PIN, LORA_RST_PIN);`
- **Causa:** forma idiomática da API do RadioLib.
- **Efeito local:** alocação de heap **antes de `main()`**, num ponto em que não há nenhum tratamento de erro possível. Se falhar, o dispositivo não chega a executar uma linha do firmware.
- **Efeito no sistema:** boot morto, sem diagnóstico. S2 por severidade, baixa probabilidade.
- **Avaliação do desvio (pedida no levantamento):** **é evitável.** O construtor de `SX1278` aceita `Module*`, então o objeto pode viver em memória estática:
  ```cpp
  static Module lora_module(LORA_CS_PIN, LORA_DIO0_PIN, LORA_RST_PIN);
  static SX1278 radio(&lora_module);
  ```
  Isso elimina a alocação sem alterar a API usada. **Não deve ser registrado como desvio justificado** — deve ser corrigido. Registrar como desvio uma violação que tem correção de duas linhas enfraquece todos os outros desvios do documento.
  - **REQ-SEG-47** — Zero alocação dinâmica no projeto, inclusive em inicialização estática. Se em algum ponto futuro uma biblioteca de terceiros impuser heap sem alternativa, o desvio é registrado com: a evidência de que não há alternativa, o limite superior da alocação, e o comportamento em caso de falha.

---

### Grupo F — Sono, despertar e corte de energia

#### FM-24 — Deep sleep que não desperta

- **Causa:** falha do RTC timer, oscilador RC lento fora de faixa por temperatura extrema, corrupção do domínio RTC por transitório de tensão.
- **Efeito local:** o dispositivo permanece em deep sleep para sempre, a ~18 µA.
- **Efeito no sistema:** silêncio permanente com bateria cheia. É o modo de falha mais frustrante em campo: o dispositivo parece intacto e a bateria está boa, então o diagnóstico é demorado. S2.
- **Como é detectado hoje:** D-B, apenas pelo silêncio.
- **Mitigação:**
  - **REQ-SEG-48** — Fonte de despertar redundante: além do timer, habilitar despertar por GPIO (um botão de manutenção já resolve a intervenção em campo sem abrir o equipamento).
  - **REQ-SEG-49** — O RTC WDT permanece armado durante o deep sleep com janela de aproximadamente 1,2× o período de sono, funcionando como despertador de último recurso. **Isso muda a política da seção 5**: o RTC WDT não pode ser simplesmente desabilitado antes de dormir; a janela precisa ser reprogramada. Se for deixada em 20 s, o watchdog reinicia o chip 20 s depois de dormir e o período de 12 min nunca acontece.

#### FM-25 — `minutes == 0` ou wakeup mal configurado

- **Local:** `src/power/sleep.cpp:65-73`. `minutes` não é validado, e o retorno de `esp_sleep_enable_timer_wakeup()` (que é `esp_err_t`) é descartado.
- **Causa:** parâmetro vindo de configuração futura, erro de refactor, valor lido de NVS corrompido.
- **Efeito local:** com `minutes == 0` o chip desperta imediatamente. Com a chamada falhando e o retorno ignorado, nenhuma fonte de despertar fica habilitada e o resultado é FM-24.
- **Efeito no sistema:** dos dois lados o efeito é grave e oposto — ou ciclo contínuo a ~40 mA (bateria em ~50 h), ou sono permanente. S2. É a violação nº 4 (sem validação de parâmetro) com consequência direta sobre a função principal do dispositivo.
- **Como é detectado hoje:** não é.
- **Mitigação:**
  - **REQ-SEG-50** — Validar `minutes ∈ [1, 120]` e verificar o retorno de `esp_sleep_enable_timer_wakeup()`. Falha na configuração do despertar é um erro tratado, não um sono silencioso.

#### FM-26 — Corte de energia não atua: periféricos alimentados durante o sono

- **Local:** `src/power/sleep.cpp:57-70`. O código já trata corretamente o caso mais sutil (`gpio_hold_dis` no boot, `gpio_hold_en` + `gpio_deep_sleep_hold_en` antes de dormir, com o raciocínio escrito nos comentários — é um dos pontos fortes do código atual).
- **Causa residual:** o `hold` falhando silenciosamente porque o retorno de `gpio_hold_en()` não é verificado; Q1 (SI2301) com Vgs(th) fora da faixa de nível lógico não fechando o canal em 3,3 V. O pino e a polaridade deixaram de ser `TODO`: GPIO5 ativo-alto, conferido contra `hardware/gen_schematic.py`.
- **Efeito local:** o MPU6050 (~3,9 mA) e o divisor do NTC (~0,33 mA em 3,3 V sobre 10 k) permanecem energizados durante 720 s.
- **Efeito no sistema:** ~2,5 A·s adicionais por ciclo; o consumo médio salta de 309 µA para vários mA e a autonomia cai de 269 dias para poucos dias. Nada indica a falha, porque a leitura funciona normalmente. S2.
- **Como é detectado hoje:** não é. Sem medição de tensão da bateria, a única evidência é o dispositivo morrer antes da hora.
- **Mitigação:**
  - **REQ-SEG-51** — Verificar o retorno de `gpio_hold_en()`.
  - **REQ-SEG-52** — Verificação em banco com INA219/multímetro do consumo em sono, com critério de aceitação numérico (< 30 µA) e registro do resultado como evidência de verificação de REQ. É o tipo de "teste de projeto" que a defesa vai pedir.
  - **REQ-SEG-53** — Telemetria de tensão da bateria (seção 6) transforma esta falha silenciosa em uma inclinação anômala de descarga visível no gateway em poucos dias.

#### FM-27 — Pull-ups do I2C alimentando o MPU6050 pelos pinos de sinal

**Estado: eliminada por mudança de topologia.** Fica registrada porque é a
razão de o circuito ser o que é hoje — e porque a mitigação por software que
estava proposta (REQ-SEG-54) resolvia o sintoma, não a causa.

- **Causa (topologia antiga):** o BC337 era chave low-side — cortava o retorno a GND, mas SDA/SCL continuavam presos a +3V3 pelos resistores de pull-up. A corrente entrava pelos diodos de proteção dos pinos do MPU6050 e o alimentava parasitariamente.
- **Efeito local:** o sensor podia permanecer parcialmente energizado, com corrente de fuga pelos pull-ups (2 × 3,3 V / 4,7 kΩ ≈ 1,4 mA no pior caso, se os pinos do sensor puxassem para baixo).
- **Efeito no sistema:** mesmo efeito de FM-26 em escala menor, e o corte de energia deixava de ser garantia de reset do sensor (o que enfraquecia a mitigação REQ-SEG-08). S2 no pior caso.
- **Correção aplicada:** o corte passou a ser high-side (Q1 SI2301 comandado por Q2 BC847B), e os pull-ups R2/R3 foram movidos do rail fixo +3V3 para o rail comutado +3V3_SW. Com o rail em zero não existe fonte para o caminho parasita: os pull-ups estão do lado cortado. Ver `hardware/gen_schematic.py`, bloco "Corte de energia dos periféricos".
- **O que resta verificar:** REQ-SEG-55 continua valendo — medir a corrente em sono com o sensor populado. A topologia elimina o caminho conhecido; o ensaio é o que responde se existe outro.
- **REQ-SEG-54 fica sem objeto:** colocar SDA/SCL em nível baixo antes do sono era contornar o efeito. Com os pull-ups no rail cortado, não há o que contornar.

#### FM-28 — Temperatura ambiente acima de +85 °C

- **Causa:** montagem próxima a mancal quente, carcaça de motor, ambiente industrial.
- **Efeito local:** ESP32-S3, MPU6050 e SX1278 são especificados até +85 °C; a LiPo tem limite de descarga tipicamente em +60 °C. Acima disso: deriva de oscilador, erro do ADC, resets espúrios, e degradação acelerada ou inchaço da célula.
- **Efeito no sistema:** medições enviesadas, resets aleatórios, risco físico à célula. S2.
- **Como é detectado hoje:** D-B — o dispositivo **mede** a temperatura e a transmite, mas **não age sobre ela**. A informação existe e é desprezada.
- **Mitigação:**
  - **REQ-SEG-56** — A temperatura medida realimenta o comportamento: acima de +70 °C, sinalizar `OVERTEMP` na telemetria; acima de +85 °C, suspender a transmissão a 17 dBm (é o maior gerador de calor interno) e estender o período de sono. Medir e ignorar é desperdiçar uma barreira de proteção que já está paga.

#### FM-29 — Temperatura ambiente abaixo de 0 °C

- **Causa:** instalação externa ou câmara fria.
- **Efeito local:** a resistência interna da LiPo sobe acentuadamente; o pulso de TX derruba o trilho e provoca brownout (FM-15) com a bateria ainda razoavelmente carregada. A curva do NTC e a calibração do ADC também degradam nos extremos.
- **Efeito no sistema:** laço de brownout com bateria aparentemente boa — diagnóstico particularmente enganoso. S2.
- **Como é detectado hoje:** não é (a temperatura é transmitida, mas ninguém correlaciona).
- **Mitigação:** REQ-SEG-28, REQ-SEG-29 e REQ-SEG-56 cobrem; acrescentar redução de potência de TX abaixo de 0 °C.

---

### Grupo G — Telemetria e observabilidade

#### FM-33 — `boot_count` zera em resets que não sejam saída de deep sleep

- **Local:** `src/main.cpp:22` — `RTC_DATA_ATTR static uint32_t boot_count = 0;`
- **Causa:** `RTC_DATA_ATTR` coloca a variável no segmento `.rtc.data`, que o bootloader **recarrega a partir da imagem** em qualquer boot que não seja despertar de deep sleep. Reset por watchdog, por brownout ou por pânico zera o contador.
- **Efeito local:** o contador reinicia em 1.
- **Efeito no sistema:** o gateway vê `boot_count` voltar ao começo e interpreta como dispositivo novo ou reinstalado. Perde-se a detecção de lacunas (FM-11) exatamente nos cenários em que ela mais importa — os de falha. O laço de reset (FM-18) apaga a própria evidência. S2.
- **Como é detectado hoje:** não é.
- **Mitigação:**
  - **REQ-SEG-57** — Contadores que precisam sobreviver a resets anormais usam `RTC_NOINIT_ATTR` (não é reinicializado pelo bootloader; só é perdido em power-on reset), protegidos por palavra mágica de 32 bits + CRC-16, porque após um power-on o conteúdo é arbitrário e precisa ser reconhecido como inválido.
  - **REQ-SEG-58** — Transmitir separadamente `boot_count` (ciclos) e `abnormal_reset_count` (resets anormais desde a instalação). São grandezas diferentes e hoje estão fundidas em uma que não sobrevive à falha.

#### FM-34 — Causa do reset nunca é lida nem reportada

- **Causa:** `esp_reset_reason()` não é chamado em lugar nenhum.
- **Efeito local:** o firmware não sabe se está saindo de um sono normal, de um watchdog, de um brownout ou de um pânico — e trata todos igual.
- **Efeito no sistema:** as falhas dos grupos D e E tornam-se todas indistinguíveis entre si e invisíveis do lado do gateway. Todo o valor diagnóstico de um reset é perdido no instante em que ele acontece. S2.
- **Como é detectado hoje:** não é.
- **Mitigação:** **REQ-SEG-59** — Ler `esp_reset_reason()` no início de `setup()`, usar na decisão de fluxo (seção 5) e transmitir codificado (seção 6).

#### FM-35 — Jitter na amostragem de 1 kHz

- **Causa:** amostragem em laço de software com `delayMicroseconds`, com o tempo de transação I2C variando entre amostras.
- **Efeito local:** a taxa efetiva não é 1000 Hz constante. `dominant_frequency` calcula `bin_hz = sample_rate_hz / n` com a taxa **nominal** (`src/sensors/vibration.cpp:14`, `SAMPLE_RATE_HZ = 1000.0f`). Se a real for 940 Hz, toda a escala de frequência tem 6 % de erro e o espectro fica borrado.
- **Efeito no sistema:** a frequência dominante — que o cabeçalho de `signal_processing.h` justifica cuidadosamente como a assinatura de desbalanceamento em 1× rotação — passa a apontar para o bin errado. O modelo foi treinado com dados amostrados com precisão; o dispositivo infere sobre um eixo de frequência deslocado. **Divergência treino/inferência**, que o próprio cabeçalho identifica como risco (`signal_processing.h:8-10`). S3.
- **Como é detectado hoje:** não é.
- **Mitigação:**
  - **REQ-SEG-60** — Amostragem disparada por timer de hardware, não por laço de software; ou uso do FIFO do MPU6050 com taxa configurada no próprio sensor (opção preferível: o relógio de amostragem passa a ser o do sensor, imune ao jitter do software).
  - **REQ-SEG-61** — Medir a duração real da rajada com `esp_timer_get_time()`, calcular a taxa efetiva e usá-la na FFT em vez da nominal. Transmitir a taxa efetiva (ou o desvio) na telemetria.

#### FM-36 — Sem carimbo de tempo no dispositivo

- **Causa:** decisão de projeto, documentada e correta (`src/comms/lora.h:18-22`): o tempo de parede é responsabilidade do gateway.
- **Efeito no sistema:** se o gateway atrasar ou enfileirar, o instante de recepção não é o de medição. Com REQ-SEG-18 (buffer de leituras não transmitidas), pacotes antigos chegariam com carimbo atual — um erro que hoje não existe mas que a mitigação introduziria. S1.
- **Mitigação:**
  - **REQ-SEG-62** — Cada leitura carrega o `boot_count` que a gerou (já carrega) e, se REQ-SEG-18 for implementado, um `age_cycles` indicando de quantos ciclos atrás é aquela medição. Sem isso o buffer circular corrompe a série temporal em vez de recuperá-la.

---

## 4. Violações do levantamento — confirmação e ampliação

| # | Violação levantada | Confirmada | Ampliação encontrada na leitura do código |
|---|---|---|---|
| 1 | Alocação dinâmica | Sim | `signal_processing.cpp:92-93`, `vibration.cpp:21`, `lora.cpp:17`. **O caso do RadioLib é evitável** (ver FM-32) — não deve ser registrado como desvio. Efeito não tratado do `bad_alloc`: `abort` → reset silencioso → risco de laço de reset (FM-18). |
| 2 | Laço sem cota | Sim | `isolation_forest.cpp:17`. Além do laço, **o índice é irrestrito nos dois sentidos** (FM-20) e a `struct IsolationTree` **não carrega o tamanho dos arrays**, tornando a validação estruturalmente impossível (REQ-SEG-37). Laços futuros na rajada I2C têm o mesmo problema (FM-02). |
| 3 | Sem modelo de erro | Sim | `lora_init()` colapsa `CHIP_NOT_FOUND` (−2), SPI mudo e `INVALID_FREQUENCY` (−12) em um `bool`: a informação existe em `state` e é descartada na linha seguinte. Pior: **`lora_sleep()` devolve `bool` e `main.cpp:61` nem lê o retorno** (FM-10), o modo de falha que sozinho custa 80 % da autonomia. |
| 4 | Sem validação e sem asserção | Sim | Acrescente: `deep_sleep(minutes)` sem faixa (FM-25); `fft_radix2` documenta "potência de 2" e não verifica (FM-30); `isolation_forest_score` sem checar `nullptr`/`n_trees` (FM-21); o clamp de `thermistor.cpp:10-12` **transforma falha de hardware em número plausível** em vez de sinalizá-la (FM-06/FM-07). |
| 5 | Sem watchdog e sem estado seguro | Sim | Acrescente: **o reset sozinho não é estado seguro** — 50 h de bateria em laço de reset (FM-18); e o RTC WDT continua contando durante o deep sleep, então uma política ingênua de watchdog **quebra o ciclo de 12 minutos** (FM-24, REQ-SEG-49). |
| 6 | Sem análise estática | Sim | Regras com efeito direto sobre esta análise: `cppcoreguidelines-no-malloc`, `bugprone-*`, `cert-flp30-c`, `-Wfloat-equal` (pegaria `m2 == 0.0` de FM-04), `[[nodiscard]]` obrigatório (pegaria FM-10). |
| 7 | Sem ponto de entrada reprodutível | Sim | Consequência de segurança: sem `make verify` determinístico, nenhuma evidência de verificação de REQ é reproduzível numa defesa. |
| 8 | Sem rastreabilidade | Sim | Seção 9 abre a matriz. Nota: os 4 módulos de `lib/` têm teste no host; **`src/` inteiro não tem nenhum**, e é onde estão FM-01, FM-10, FM-22, FM-25 e FM-26. |
| **9** | **(novo) Falha para o lado inseguro na decisão** | — | `model.cpp:24`: `score > threshold` com `score = NaN` devolve `Normal`. Dado corrompido → "máquina sadia" (FM-23). |
| **10** | **(novo) Dado fabricado transmitido como medição** | — | `vibration.cpp:21` produz um buffer de zeros e `main.cpp:47-55` o transmite com CRC válido e `status = Normal`, mesmo com `vibration_init()` tendo falhado (FM-01, FM-22). É a violação de maior severidade do projeto. |
| **11** | **(novo) Persistência de diagnóstico não sobrevive à falha** | — | `RTC_DATA_ATTR` é zerado em reset por watchdog/brownout/pânico (FM-33), e `esp_reset_reason()` nunca é lido (FM-34). |

---

## 5. Estado seguro

### 5.1 Princípio

> **O estado seguro do Kaelix é aquele em que ele não afirma nada que não mediu, não gasta energia que não pode justificar, e continua audível.**

Um sensor de manutenção preditiva não tem atuador: não há nada para desligar, nenhum
movimento para interromper. O dano que ele pode causar é **informacional** — induzir uma
decisão de manutenção errada — e **econômico** — morrer antes da hora sem avisar. Logo o
estado seguro não é "parar": é **degradar de forma declarada**.

### 5.2 Invariantes (valem em todos os estados)

| ID | Invariante | Modos que ele fecha |
|---|---|---|
| **INV-1** | O rádio nunca entra no período de sono em standby. Se `sleep()` não confirmar, o pino RST é acionado. | FM-10 |
| **INV-2** | Os periféricos nunca permanecem energizados durante o sono, e o `hold` do GPIO é confirmado. | FM-26, FM-27 |
| **INV-3** | Nenhum campo do pacote contém valor que o dispositivo não mediu. Campo inválido vai com bit de validade zerado. | FM-01, FM-04, FM-06, FM-07, FM-22 |
| **INV-4** | Todo caminho de execução tem prazo máximo. Nenhum laço é ilimitado; o watchdog é a rede sob a rede. | FM-02, FM-17, FM-19 |
| **INV-5** | O dispositivo permanece audível em todos os estados, exceto no de proteção terminal da bateria — e este é anunciado antes de ser entrado. | FM-14, FM-16 |
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

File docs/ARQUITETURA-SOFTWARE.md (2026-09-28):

# Arquitetura de software do Kaelix

Documento normativo. Descreve as camadas do firmware, a regra de dependência
entre elas, as convenções de nome, a política de memória, a política de erro e
o estado seguro do dispositivo.

O alvo não é certificação DO-178C. O alvo é adotar — e conseguir justificar
numa defesa — as práticas de organização, determinismo e rastreabilidade que
projetos industriais e aeroespaciais usam, aplicadas a um dispositivo real:
ESP32-S3-WROOM-1 N16R8, MPU6050 no I2C, NTC 10k no ADC, SX1278 no SPI,
alimentado por LiPo com orçamento de ~309 µA médios e autonomia alvo de ~8
meses.
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

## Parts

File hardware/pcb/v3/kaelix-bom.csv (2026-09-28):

Reference | Value | Footprint
C1,C2,C4,C5,C7,C11,C12 | 100n | Capacitor_SMD:C_0805_2012Metric
C3,C8 | 10u | Capacitor_SMD:C_0805_2012Metric
C6 | 2n2 | Capacitor_SMD:C_0805_2012Metric
C9,C10,C13,C14 | 1u | Capacitor_SMD:C_0805_2012Metric
C15 | 220n | Capacitor_SMD:C_0805_2012Metric
J1 | LiPo 3,7V | Connector_JST:JST_PH_S2B-PH-SM4-TB_1x02-1MP_P2.00mm_Horizontal
J2 | UART/BOOT | Connector_PinHeader_2.54mm:PinHeader_1x06_P2.54mm_Vertical
J3 | USB-C 5V | Connector_USB:USB_C_Receptacle_GCT_USB4125-xx-x_6P_TopMnt_Horizontal
Q1,Q3 | SI2301CDS | Package_TO_SOT_SMD:SOT-23
Q2 | BC847B | Package_TO_SOT_SMD:SOT-23
R1,R5-R7 | 10k | Resistor_SMD:R_0805_2012Metric
R2,R3 | 4k7 | Resistor_SMD:R_0805_2012Metric
R4,R8 | 100k | Resistor_SMD:R_0805_2012Metric
R9,R10 | 1M | Resistor_SMD:R_0805_2012Metric
R11,R12 | 5k1 | Resistor_SMD:R_0805_2012Metric
R13 | 2k7 | Resistor_SMD:R_0805_2012Metric
RT1 | NTC 10k B3950 | Resistor_SMD:R_0805_2012Metric
RT2 | NTC 10k B3380 (103AT) | Resistor_SMD:R_0805_2012Metric
U1 | ESP32-S3-WROOM-1U-N16R8 | RF_Module:ESP32-S3-WROOM-1U
U2 | MPU-6050 | Sensor_Motion:InvenSense_QFN-24_4x4mm_P0.5mm
U3 | Ai-Thinker Ra-02 (SX1278) | RF_Module:Ai-Thinker-Ra-01-LoRa
U4 | HT7333 | Package_TO_SOT_SMD:SOT-89-3
U5 | BQ21040DBV | Package_TO_SOT_SMD:SOT-23-6

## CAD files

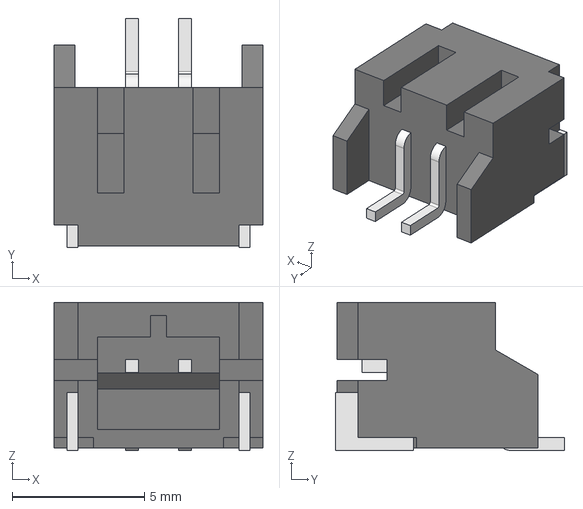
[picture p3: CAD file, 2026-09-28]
hardware/3dmodels/origem/jst.step
7.90 x 8.65 x 5.60 mm

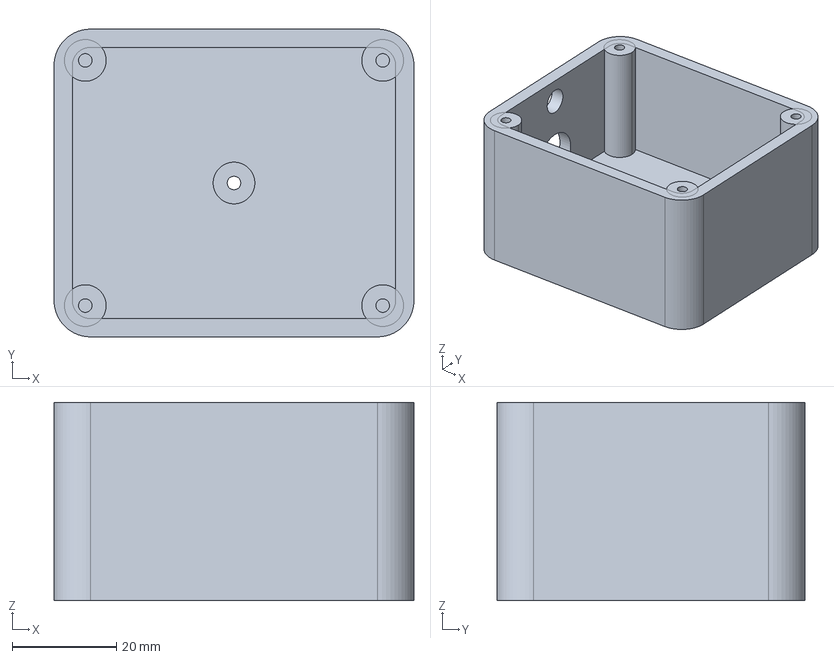
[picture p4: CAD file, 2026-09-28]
hardware/involucro/v3/corpo.step
69.0 x 59.0 x 38.0 mm

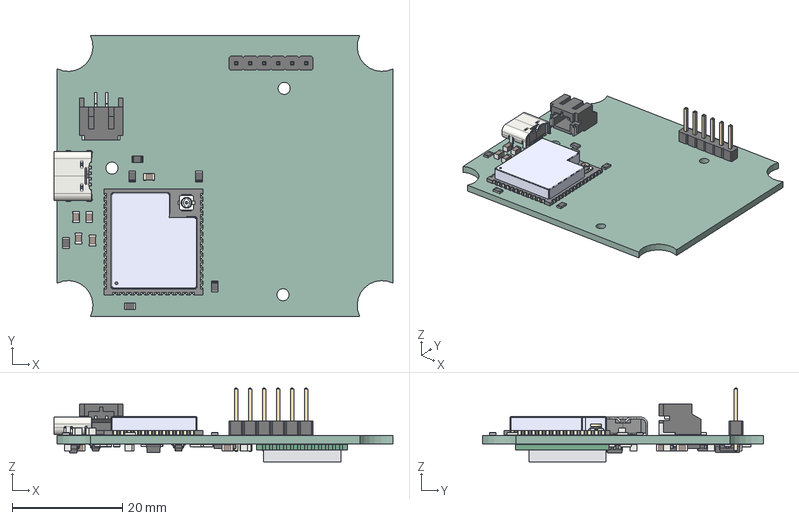
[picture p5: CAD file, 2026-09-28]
hardware/pcb/v3/kaelix.step
61.6 x 51.0 x 13.4 mm
ESP32-S3-WROOM-1U-N16R8
QFN-24-1EP_4x4mm_Pitch0.5mm
pcb_0
can_1
SOT-23-6
R_0805_2012Metric x 15
C_0805_2012Metric x 15
adbeea57-9c39-11ed-93f0-dde97e994e83_part
adbeea58-9c39-11ed-93f0-dde97e994e83_part
adbeea59-9c39-11ed-93f0-dde97e994e83_part
SOT-23 x 3
(Unsaved)
PinHeader_1x06_P254mm_Vertical
USB_C_Receptacle_GCT_USB4125-xx-x_6P_TopMnt_Horizontal
kaelix_PCB

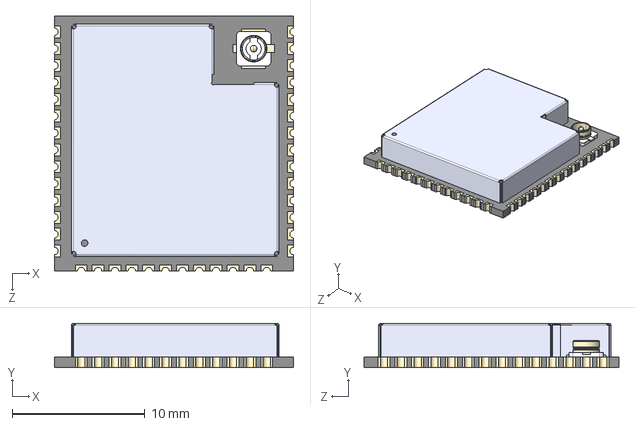
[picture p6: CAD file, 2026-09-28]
hardware/3dmodels/origem/wroom1u.step
18.0 x 3.35 x 19.2 mm

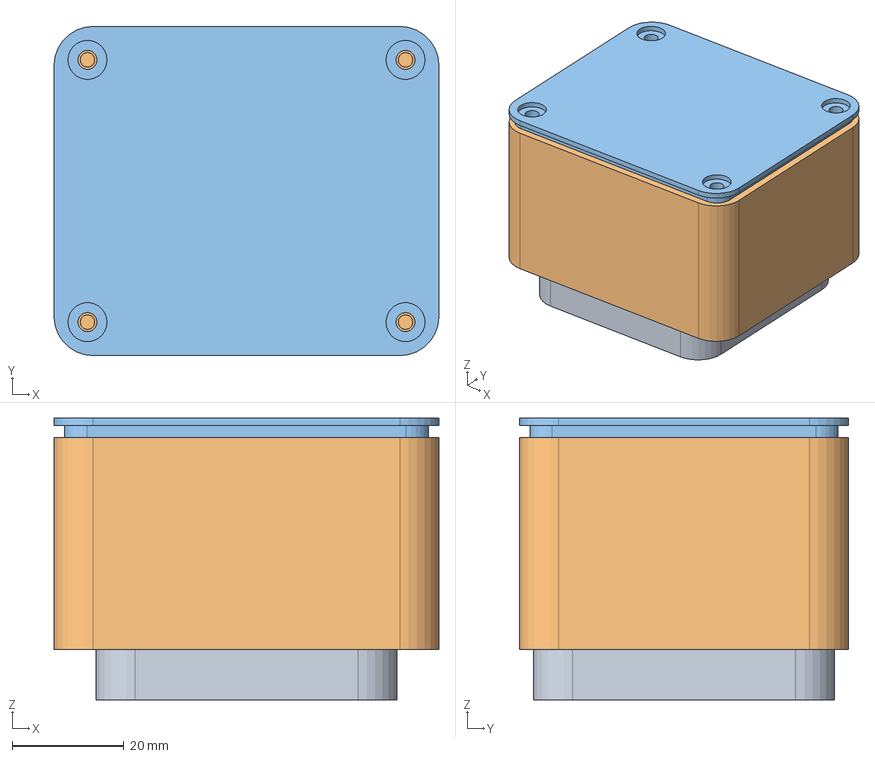
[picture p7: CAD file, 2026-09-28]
hardware/involucro/v3/montagem.step
69.0 x 59.0 x 50.5 mm

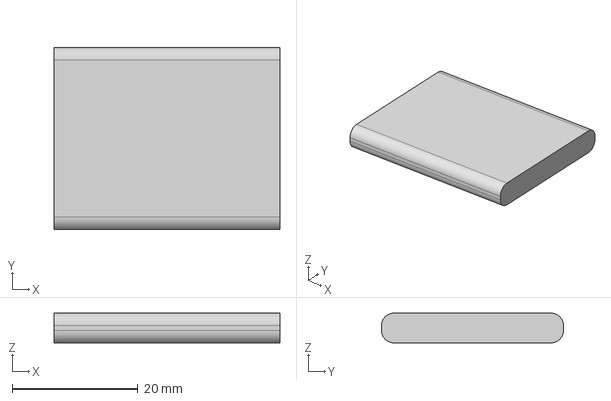
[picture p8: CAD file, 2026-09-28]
hardware/3dmodels/origem/lipo-500mah-adafruit1578.step
36.0 x 29.0 x 4.75 mm

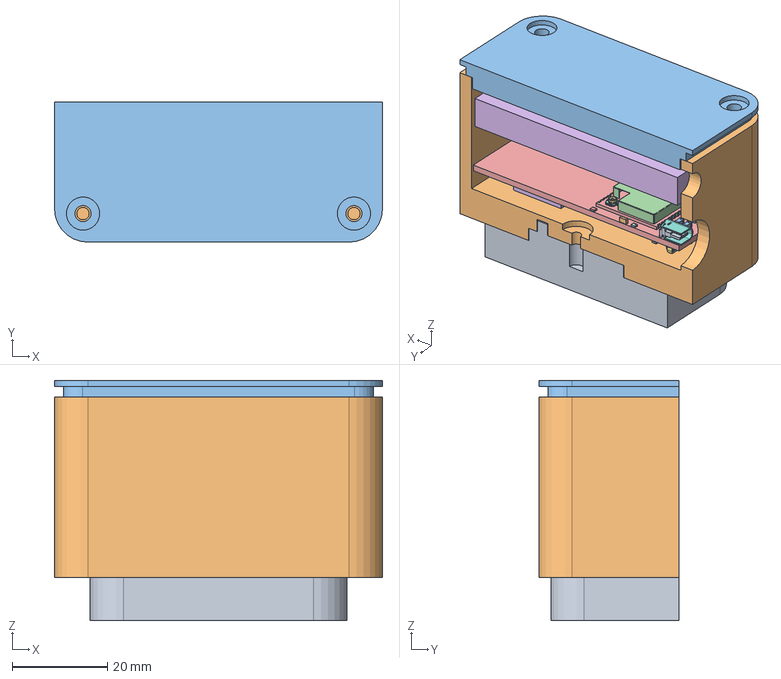
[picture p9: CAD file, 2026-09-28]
hardware/involucro/v3/montagem-corte.step
69.0 x 29.5 x 50.5 mm

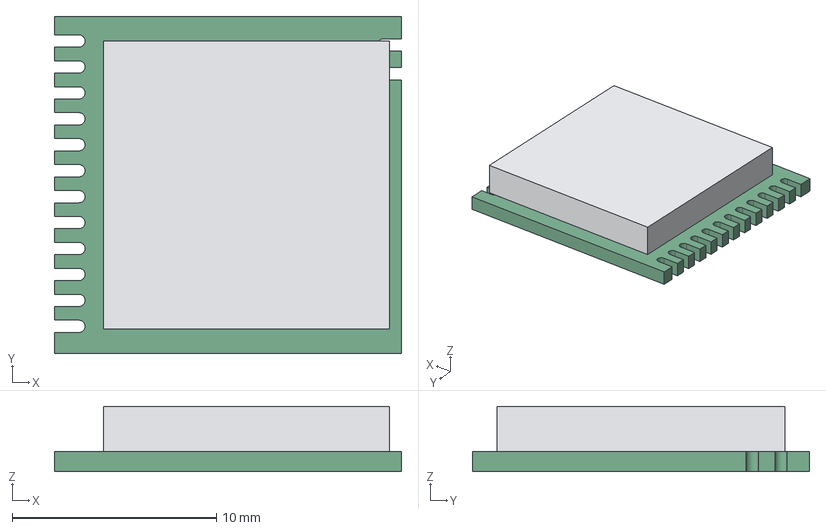
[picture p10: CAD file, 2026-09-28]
hardware/3dmodels/origem/ra02.step
17.0 x 16.5 x 3.20 mm
pcb_0
can_1

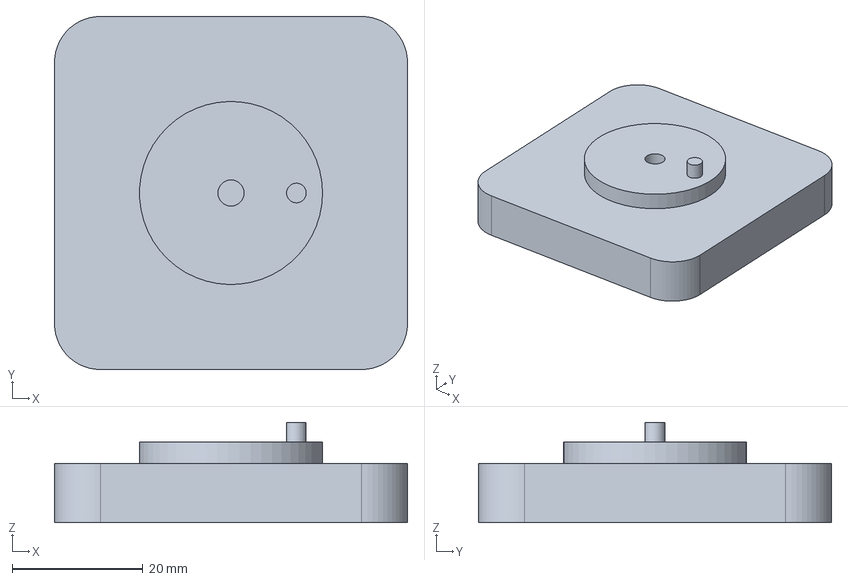
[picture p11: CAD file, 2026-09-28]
hardware/involucro/v3/base.step
54.0 x 54.0 x 15.3 mm

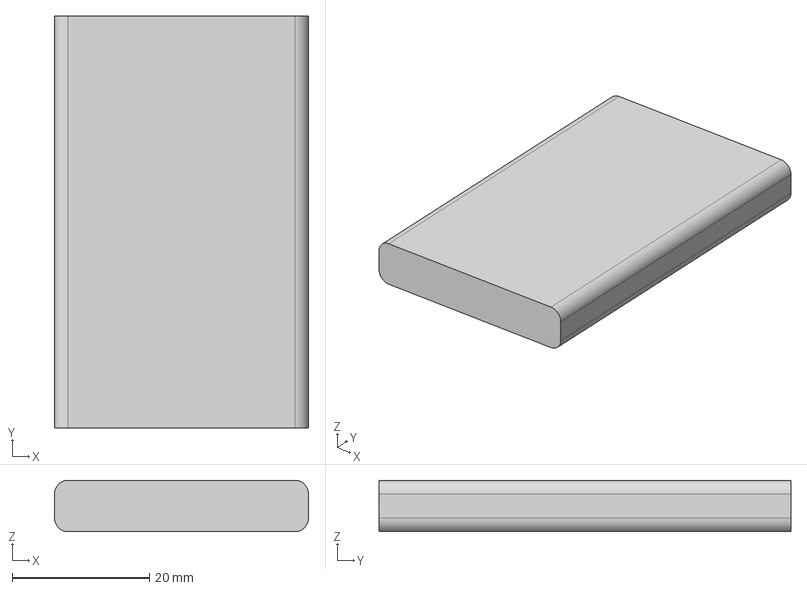
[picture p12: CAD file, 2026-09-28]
hardware/3dmodels/origem/lipo-2000mah-adafruit2011.step
37.0 x 60.0 x 7.50 mm

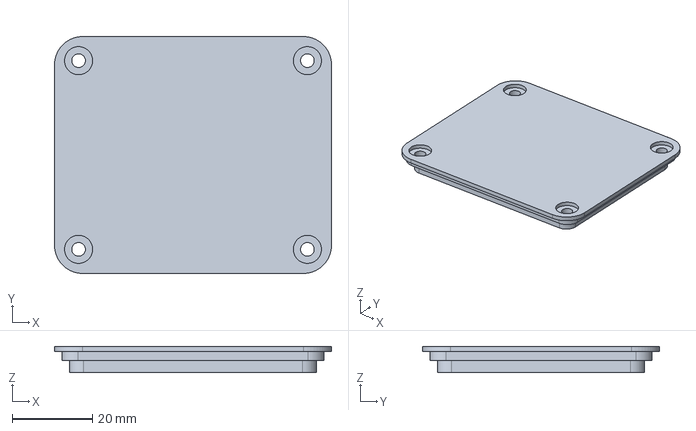
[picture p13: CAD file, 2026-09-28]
hardware/involucro/v3/tampa.step
69.0 x 59.0 x 6.50 mm

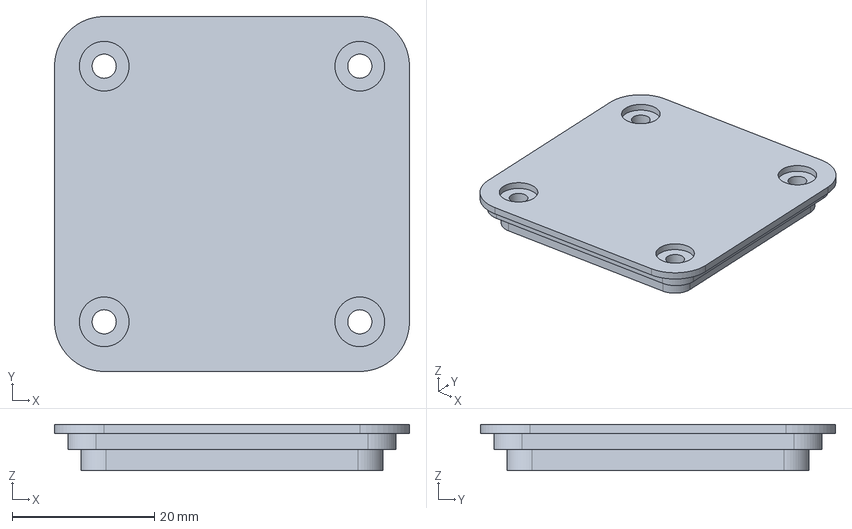
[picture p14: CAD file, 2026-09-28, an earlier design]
hardware/involucro/v1/tampa.step
50.0 x 50.0 x 6.50 mm

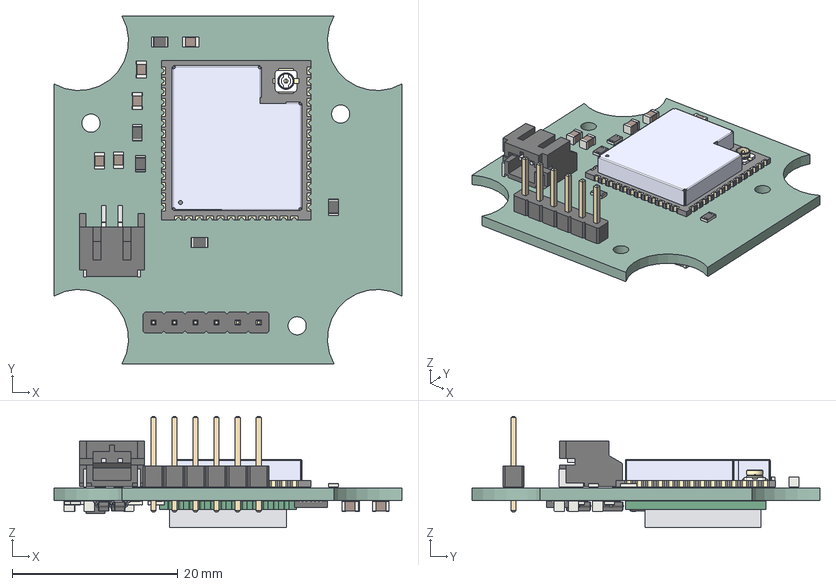
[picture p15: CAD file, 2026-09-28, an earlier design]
hardware/pcb/v1/kaelix.step
42.0 x 42.0 x 13.4 mm
ESP32-S3-WROOM-1U-N16R8
QFN-24-1EP_4x4mm_Pitch0.5mm
pcb_0
can_1
R_0805_2012Metric x 11
C_0805_2012Metric x 12
adbeea57-9c39-11ed-93f0-dde97e994e83_part
adbeea58-9c39-11ed-93f0-dde97e994e83_part
adbeea59-9c39-11ed-93f0-dde97e994e83_part
SOT-23 x 3
(Unsaved)
PinHeader_1x06_P254mm_Vertical
kaelix_PCB

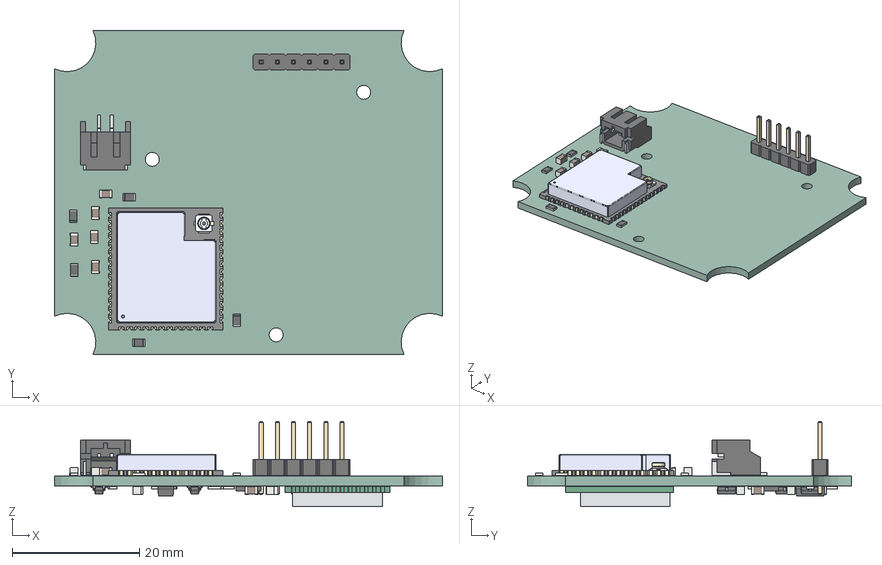
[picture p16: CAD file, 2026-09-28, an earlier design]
hardware/pcb/v2/kaelix.step
61.0 x 51.0 x 13.4 mm
ESP32-S3-WROOM-1U-N16R8
QFN-24-1EP_4x4mm_Pitch0.5mm
pcb_0
can_1
R_0805_2012Metric x 11
C_0805_2012Metric x 12
adbeea57-9c39-11ed-93f0-dde97e994e83_part
adbeea58-9c39-11ed-93f0-dde97e994e83_part
adbeea59-9c39-11ed-93f0-dde97e994e83_part
SOT-23 x 3
(Unsaved)
PinHeader_1x06_P254mm_Vertical
kaelix_PCB

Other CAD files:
hardware/involucro/v2/montagem.step
hardware/involucro/v1/montagem-corte.step
hardware/involucro/v2/base.step
hardware/involucro/v1/base.step
hardware/involucro/v1/corpo.step
hardware/involucro/v1/montagem.step
hardware/involucro/v2/corpo.step
hardware/involucro/v2/montagem-corte.step
hardware/involucro/v2/tampa.step

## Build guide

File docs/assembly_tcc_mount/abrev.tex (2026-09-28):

%%%%%%%%%%%%%%%%%%%%%%%%%%%%%%%%%%%%%%%%%%%%%%%%%%%%%%%%%%%%%%%%%%%%%%%%%%%%%%%
%% Lista de Siglas e Abreviaturas (pacote glossaries)
%%
%% Contém apenas as siglas efetivamente usadas nos Capítulos 1 a 5 e nos
%% apêndices. Acrescentar entrada aqui ao introduzir sigla nova no texto.
%%%%%%%%%%%%%%%%%%%%%%%%%%%%%%%%%%%%%%%%%%%%%%%%%%%%%%%%%%%%%%%%%%%%%%%%%%%%%%%

%% Instrumentação e mecânica
\newacronym{MEMS}{MEMS}{sistemas microeletromecânicos (\emph{Micro-Electro-Mechanical Systems})}
\newacronym{IMU}{IMU}{unidade de medição inercial (\emph{Inertial Measurement Unit})}
\newacronym{BPFO}{BPFO}{frequência de passagem de esferas na pista externa (\emph{Ball Pass Frequency, Outer race})}
\newacronym{BPFI}{BPFI}{frequência de passagem de esferas na pista interna (\emph{Ball Pass Frequency, Inner race})}
\newacronym{DLPF}{DLPF}{filtro passa-baixas digital (\emph{Digital Low-Pass Filter})}
\newacronym{RMS}{RMS}{valor eficaz (\emph{Root Mean Square})}
\newacronym{ASA}{ASA}{acrilonitrila estireno acrilato}
\newacronym{NTC}{NTC}{termistor de coeficiente de temperatura negativo}

%% Normalização
\newacronym{ISO}{ISO}{Organização Internacional de Normalização (\emph{International Organization for Standardization})}
\newacronym{ABNT}{ABNT}{Associação Brasileira de Normas Técnicas}

%% Detecção e avaliação
\newacronym{ROC}{ROC}{característica de operação do receptor (\emph{Receiver Operating Characteristic})}
\newacronym{AUC}{AUC}{área sob a curva (\emph{Area Under the Curve})}
\newacronym{pAUC}{pAUC}{área parcial sob a curva, restrita a uma faixa de falso alarme}
\newacronym{PRAUC}{PR-AUC}{área sob a curva de precisão e revocação}
\newacronym{TPR}{TPR}{taxa de detecção (\emph{True Positive Rate})}
\newacronym{DFT}{DFT}{transformada discreta de Fourier (\emph{Discrete Fourier Transform})}
\newacronym{FFT}{FFT}{transformada rápida de Fourier (\emph{Fast Fourier Transform})}
\newacronym{FPR}{FPR}{taxa de falso alarme (\emph{False Positive Rate})}

%% Computação embarcada e comunicação
\newacronym{TinyML}{TinyML}{aprendizado de máquina em dispositivos de recursos limitados}
\newacronym{LoRa}{LoRa}{modulação de longo alcance e baixa potência (\emph{Long Range})}
\newacronym{SF}{SF}{fator de espalhamento (\emph{Spreading Factor})}
\newacronym{CRC}{CRC}{verificação cíclica de redundância (\emph{Cyclic Redundancy Check})}
\newacronym{ADC}{ADC}{conversor analógico-digital}
\newacronym{SRAM}{SRAM}{memória estática de acesso aleatório (\emph{Static Random-Access Memory})}

%% Projeto de hardware
\newacronym{PCB}{PCB}{placa de circuito impresso (\emph{Printed Circuit Board})}
\newacronym{ERC}{ERC}{verificação de regras elétricas (\emph{Electrical Rules Check})}
\newacronym{DRC}{DRC}{verificação de regras de projeto (\emph{Design Rules Check})}
\newacronym{PDN}{PDN}{rede de distribuição de alimentação (\emph{Power Delivery Network})}

%% Instituição
\newacronym{UFRJ}{UFRJ}{Universidade Federal do Rio de Janeiro}

%%%%%%%%%%%%%%%%%%%%%%%%%%%%%%%%%%%%%%%%%%%%%%%%%%%%%%%%%%%%%%%%%%%%%%%%%%%%%%%
%% O pacote glossaries só imprime as siglas EFETIVAMENTE USADAS via \gls{...}.
%% Como o texto dos capítulos usa as siglas em forma literal (e não \gls{}),
%% \glsaddall força todas as entradas acima para a lista impressa.
%%
%% Se no futuro o texto passar a usar \gls{}, remova a linha abaixo para que a
%% lista volte a conter apenas o que é citado.
%%%%%%%%%%%%%%%%%%%%%%%%%%%%%%%%%%%%%%%%%%%%%%%%%%%%%%%%%%%%%%%%%%%%%%%%%%%%%%%
\glsaddall

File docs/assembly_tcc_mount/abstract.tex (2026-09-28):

%%%%%%%%%%%%%%%%%%%%%%%%%%%%%%%%%%%%%%%%%%%%%%%%%%%%%%%%%%%%%%%%%%%%%%%%%%%%%%%
%% Abstract --- tradução do resumo, mesma afirmação e mesma força.
%%%%%%%%%%%%%%%%%%%%%%%%%%%%%%%%%%%%%%%%%%%%%%%%%%%%%%%%%%%%%%%%%%%%%%%%%%%%%%%

\begin{resumo}[Abstract]
\begin{otherlanguage*}{english}
Vibration-based predictive maintenance of rotating machinery is a standardised practice,
and the obstacle to its adoption is the cost of instrumentation, which restricts coverage
to critical assets. Low-cost sensor nodes address this obstacle, but the literature
proposing them rarely declares the measurement bandwidth and noise floor that underpin the
reported performance. This work determines what the measurement chain specified for a
device of this class --- a consumer-grade accelerometer sampling at 1~kHz, a low-power
microcontroller, a long-range radio link and a polymer printed enclosure --- is able to
measure, and calibrates the decision stage so that performance is verifiable at the
intended operating point. The method builds reference conditions whose correct result
follows from an analytical solution or from a normative definition, submits them to the
proposed chain and measures the deviation. Results have three provenances, declared
individually: synthesised signal, real test-rig data decimated in software, and modelling
over design specifications. On real data, at a measured 2\% false alarm rate, detection reaches
75.0\% $\pm$ 3.5\% for imbalance, between 14.8\% and 20.7\% for pure bearing faults and
between 5.0\% and 7.2\% for misalignment. On synthesised signals, three of the estimation
decisions examined alter the results by larger margins than the physical effect under
investigation: time-domain integration misses the normative indicator by 73\% without bias
and by 716\% under a bias within the sensor specification, whereas frequency-domain
integration recovers it exactly; the detector's default thresholding policy flags 42.1\% of
normal operation as anomalous, against 1.4\% under a calibrated threshold; and random
window partitioning inflates accuracy by roughly 36 percentage points relative to
partitioning by test run. From modelling, the assembly mounting frequency falls at 557~Hz,
inside the measurement band, and the enclosure keeps the electronics below every limit
during operation; the binding thermal limit is the battery's charging limit, and only while
charging. We conclude that the chain supports imbalance detection under
a fixed false alarm rate and does not support bearing fault diagnosis, and that the
verifiable contribution of a device of this class lies in the decision stage, provided the
acquisition stage is declared. The conclusions hold for the specified chain, not for the
performance of the assembled device in industrial operation: building the prototype and
testing it in a real environment constitute the next stage.

\vspace{\onelineskip}
\noindent
\textbf{Keywords}: predictive maintenance; vibration analysis; anomaly detection;
embedded systems; low-cost instrumentation.
\end{otherlanguage*}
\end{resumo}

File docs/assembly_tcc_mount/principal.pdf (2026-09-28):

### INSTITUTO DE ENSINO SUPERIOR iCEV

### Bacharelado em Engenharia de Software

### Lauan Matheus

## Monitoramento de vibração de baixo custo para

## manutenção preditiva: aquisição e detecção

## embarcada de anomalias em motores

### Teresina – PI

2026

### Lauan Matheus

## Monitoramento de vibração de baixo custo para manutenção

## preditiva: aquisição e detecção embarcada de anomalias em

## motores

Monografia apresentada ao curso de Bacharelado em Engenharia de Software do Instituto de Ensino Superior iCEV, como requisito parcial para a obtenção do título de Bacharel em Engenharia de Software.

Instituto de Ensino Superior iCEV

Bacharelado em Engenharia de Software

### Orientador: [Nome do orientador]

### Teresina – PI

2026

### Lauan Matheus

## Monitoramento de vibração de baixo custo para manutenção preditiva: aquisição e detecção embarcada de anomalias em motores

Monografia apresentada ao curso de Bacharelado em Engenharia de Software do Instituto de Ensino Superior iCEV, como requisito parcial para a obtenção do título de Bacharel em Engenharia de Software.

Trabalho aprovado. Teresina – PI, [dia] de [mês] de 2026:

[Nome do orientador]
Orientador

[Nome do membro da banca]
Convidado 1

[Nome do membro da banca]
Convidado 2

### Teresina – PI

2026

# Resumo

A manutenção preditiva de máquinas rotativas por análise de vibração é normalizada, e o obstáculo à sua adoção é o custo de instrumentação, que restringe a cobertura aos ativos críticos. Nós sensores de baixo custo respondem a esse obstáculo, mas a literatura que os propõe raramente declara a banda e o piso de ruído que sustentam o desempenho reportado. Este trabalho determina o que a cadeia de medição especificada para um dispositivo dessa classe — acelerômetro de consumo com taxa de amostragem de 1 kHz, microcontrolador de baixo consumo, enlace de longo alcance e invólucro impresso em polímero — permite medir, e calibra o estágio de decisão de modo que o desempenho seja verificável no ponto de operação pretendido. O método constrói condições de referência cujo resultado correto decorre de solução analítica ou de definição normativa, submete-as à cadeia proposta e mede o desvio. Os resultados têm três procedências, declaradas individualmente: sinal sintetizado, dado real de bancada decimado em software e modelagem sobre as especificações de projeto. Em dado real, a 2% de falso alarme medido, a detecção é de 75,0% ± 3,5% em desbalanceamento, entre 14,8% e 20,7% em defeito de rolamento puro e entre 5,0% e 7,2% em desalinhamento. Em sinal sintetizado, três das decisões de estimação examinadas alteram os resultados por margens maiores que o efeito físico investigado: a integração no domínio do tempo erra o indicador normativo em 73% sem viés e em 716% sob viés contido na especificação do sensor, enquanto a integração no domínio da frequência o recupera exatamente; a política de limiar padrão do detector marca 42,1% da operação normal como anomalia, contra 1,4% sob limiar calibrado; e a partição aleatória de janelas infla a acurácia em cerca de 36 pontos percentuais frente à partição por ensaio. Por modelagem, a frequência de montagem do conjunto situa-se em 557 Hz, dentro da banda de medição, e o invólucro mantém a eletrônica abaixo de todos os limites em operação; o limite térmico que restringe é o de carga da bateria, e somente durante a carga. Conclui-se que a cadeia sustenta a detecção de desbalanceamento sob falso alarme fixado e não sustenta diagnóstico de defeito de rolamento, e que a contribuição verificável de um dispositivo dessa classe está no estágio de decisão, desde que o estágio de aquisição esteja declarado. As conclusões valem para a cadeia especificada, e não para o desempenho do dispositivo montado em operação industrial: a construção do protótipo e seu ensaio em ambiente real constituem a etapa seguinte.

Palavras-chave: manutenção preditiva; análise de vibração; detecção de anomalia; sistemas embarcados; instrumentação de baixo custo.

# Abstract

Vibration-based predictive maintenance of rotating machinery is a standardised practice, and the obstacle to its adoption is the cost of instrumentation, which restricts coverage to critical assets. Low-cost sensor nodes address this obstacle, but the literature proposing them rarely declares the measurement bandwidth and noise floor that underpin the reported performance. This work determines what the measurement chain specified for a device of this class — a consumer-grade accelerometer sampling at 1 kHz, a low-power microcontroller, a long-range radio link and a polymer printed enclosure — is able to measure, and calibrates the decision stage so that performance is verifiable at the intended operating point. The method builds reference conditions whose correct result follows from an analytical solution or from a normative definition, submits them to the proposed chain and measures the deviation. Results have three provenances, declared individually: synthesised signal, real test-rig data decimated in software, and modelling over design specifications. On real data, at a measured 2% false alarm rate, detection reaches 75.0% ± 3.5% for imbalance, between 14.8% and 20.7% for pure bearing faults and between 5.0% and 7.2% for misalignment. On synthesised signals, three of the estimation decisions examined alter the results by larger margins than the physical effect under investigation: time-domain integration misses the normative indicator by 73% without bias and by 716% under a bias within the sensor specification, whereas frequency-domain integration recovers it exactly; the detector’s default thresholding policy flags 42.1% of normal operation as anomalous, against 1.4% under a calibrated threshold; and random window partitioning inflates accuracy by roughly 36 percentage points relative to partitioning by test run. From modelling, the assembly mounting frequency falls at 557 Hz, inside the measurement band, and the enclosure keeps the electronics below every limit during operation; the binding thermal limit is the battery’s charging limit, and only while charging. We conclude that the chain supports imbalance detection under a fixed false alarm rate and does not support bearing fault diagnosis, and that the verifiable contribution of a device of this class lies in the decision stage, provided the acquisition stage is declared. The conclusions hold for the specified chain, not for the performance of the assembled device in industrial operation: building the prototype and testing it in a real environment constitute the next stage.

Keywords: predictive maintenance; vibration analysis; anomaly detection; embedded systems; low-cost instrumentation.

# Lista de ilustrações

Figura 7 – O caminho elástico coloca a frequência de montagem dentro da banda . . . 53

Figura 10 – Quatro escolhas metodológicas alteram os resultados mais que o efeito medido 56

# Lista de tabelas

Tabela 1 – Características do acelerômetro do MPU6050 relevantes para medição de
vibração (InvenSense, 2011; InvenSense, 2012) | 26
Tabela 2 – Banda e atraso do filtro passa-baixas digital do acelerômetro do MPU6050, por configuração do campo DLPF_CFG, com taxa de saída de 1 kHz (InvenSense,
2012) | 26
Tabela 3 – Limites entre zonas de avaliação, em velocidade eficaz de banda larga (mm/s), para máquinas industriais (ISO/TC 108/SC 2, 2022). Grupo 1: potência acima
de 300 kW, ou máquinas elétricas com altura de eixo de pelo menos 315 mm. Grupo 2: potência de 15 kW a 300 kW, ou máquinas elétricas com altura de
eixo entre 160 e 315 mm | | 27
Tabela 4 – Cadeia de geração do hardware e verificação automática de cada etapa. . . . | 47
Tabela 5 – Detecção por modo de falha a 2 % de falso alarme medido, em dado real decimado (M). Desvio entre partições onde registrado. As duas classes

de rolamento correspondem à condição sem massa de desbalanceamento
sobreposta | 52
Tabela 6 – Velocidade eficaz por variante de integração, contra o valor analítico exato (S
| ). 54

# Lista de abreviaturas e siglas

ABNT Associação Brasileira de Normas Técnicas.

ADC conversor analógico-digital.

ASA acrilonitrila estireno acrilato.

AUC área sob a curva (Area Under the Curve).

BPFI frequência de passagem de esferas na pista interna (Ball Pass Frequency, Inner race).

BPFO frequência de passagem de esferas na pista externa (Ball Pass Frequency, Outer race).

CRC verificação cíclica de redundância (Cyclic Redundancy Check).

DFT transformada discreta de Fourier (Discrete Fourier Transform).

DLPF filtro passa-baixas digital (Digital Low-Pass Filter).

DRC verificação de regras de projeto (Design Rules Check).

ERC verificação de regras elétricas (Electrical Rules Check).

FFT transformada rápida de Fourier (Fast Fourier Transform).

FPR taxa de falso alarme (False Positive Rate).

IMU unidade de medição inercial (Inertial Measurement Unit).

ISO Organização Internacional de Normalização (International Organization for Standardiza-tion).

LoRa modulação de longo alcance e baixa potência (Long Range).

MEMS sistemas microeletromecânicos (Micro-Electro-Mechanical Systems).

NTC termistor de coeficiente de temperatura negativo.

pAUC área parcial sob a curva, restrita a uma faixa de falso alarme.

PCB placa de circuito impresso (Printed Circuit Board).

PDN rede de distribuição de alimentação (Power Delivery Network).

PR-AUC área sob a curva de precisão e revocação.

RMS valor eficaz (Root Mean Square).

ROC característica de operação do receptor (Receiver Operating Characteristic).

SF fator de espalhamento (Spreading Factor).

SRAM memória estática de acesso aleatório (Static Random-Access Memory).

TinyML aprendizado de máquina em dispositivos de recursos limitados.

TPR taxa de detecção (True Positive Rate).

UFRJ Universidade Federal do Rio de Janeiro.

# Lista de Símbolos

Descritores e avaliação

α | Limite superior da faixa de falso alarme na área parcial
β | Limite superior de falso alarme da área parcial
κ | Curtose do sinal na janela
AUCα | Área parcial sob a curva ROC, acumulada até α
ψ | Tamanho da subamostra de cada árvore
σ | Desvio-padrão do sinal na janela | m/s
| | 2

c(ψ) Comprimento médio de caminho para subamostra de ψ pontos

ℎ(x) Comprimento do caminho de isolamento de x

N | Número de amostras na janela
q | Risco alvo na calibração de limiar por valores extremos

s(x, ψ) Escore de anomalia do Isolation Forest

s(x, n) Escore de anomalia do Isolation Forest

xrms | Valor eficaz do sinal na janela | m/s
| | 2

Modelo mecânico e térmico

ℓ | Lado externo da seção tubular | m
D | Rigidez flexional da placa | N m
ν | Coeficiente de Poisson
ζ | Razão de amortecimento
A | Área da seção resistente | m²
a | Raio da placa circular | m
E | Módulo de elasticidade | Pa
fn | Frequência natural de montagem do conjunto | Hz
ℎ | Espessura da base | m

I | Momento de inércia da seção tubular quadrada | m⁴
k | Rigidez equivalente do caminho de transmissão | N/m
kbase | Rigidez da base, placa circular engastada | N/m
kcorpo Rigidez do corpo, viga tubular engastada | N/m
kres | Rigidez do ressalto de centragem, compressão axial | N/m
L | Comprimento do elo | m
R | Resistência térmica | K/W
r | Razão entre frequência de excitação e frequência natural
Rth | Resistência térmica do caminho condutivo | K/W

T (r) Transmissibilidade de base

t | Espessura da parede tubular | m

Modelo de sinal e aquisição

Δ f | Resolução em frequência da DFT | Hz
δi | Desvio aleatório que modela o escorregamento das esferas | s
θ | Ângulo de contato do rolamento | rad
ε(t) | Ruído gaussiano branco | m/s
| | 2
φk | Fase da k-ésima harmônica | rad
ζd | Taxa de amortecimento do impacto | 1/s
a(t) | Aceleração simulada | m/s
| | 2
Ak | Amplitude da k-ésima harmônica da rotação | m/s
| | 2
D | Amplitude do impacto do defeito | m/s
| | 2
d | Diâmetro da esfera | mm
Dp | Diâmetro primitivo do rolamento | mm
fr | Frequência de rotação do eixo | Hz
fs | Taxa de amostragem | Hz
fap | Frequência aparente sob subamostragem sem filtro | Hz

fres | Frequência da ressonância estrutural excitada | Hz
Nb | Número de esferas do rolamento
ti | Instante do i-ésimo impacto | s
Ts | Duração de um símbolo LoRa | s
u(·) | Degrau unitário
vrms | Velocidade eficaz de banda larga, indicador normativo | mm/s

# Sumário

3.2 | Aquisição: banda, ruído e detectabilidade de defeito de rolamento . . . . | 35
3.3 | Normalização: o que a norma exige do instrumento e da estimativa . . . | 36

5.2.1 | A banda do sensor descarta a evidência de defeito de rolamento | | 50
5.2.2 | O que o dispositivo detecta, por modo de falha | | 51
5.2.3 | O invólucro filtra o sinal antes que ele alcance o sensor | | 52
5.3 | O que a estimação decide | | 53
5.3.1 | A norma exige velocidade, e a integração precisa ser feita na frequência . . . | 53
5.3.2 | O limiar padrão produz falso alarme incompatível com operação | | 54
5.3.3 | A métrica global não caracteriza o ponto de operação | | 55
5.3.4 | O protocolo de validação infla a acurácia | | 56
5.4 | O que a implantação impõe | | 56
5.4.1 | A carga da bateria, e não o invólucro, define a margem térmica | | 56
5.4.2 | O enlace impõe um compromisso entre alcance e autonomia | | 57
5.5 | Confronto com a literatura | | 59
5.5.1 | Convergências | | 59
5.5.2 | Fragilidades desta análise | | 60
5.5.3 | Escolhas de hardware contestadas | | 61
6 | CONCLUSÕES | | 62
6.1 | O que a aquisição permite medir | | 62
6.2 | O que a estimação decide | | 63
6.3 | O que a implantação impõe | | 64
6.4 | Alcance dos resultados | | 64
6.5 | Trabalho futuro | | 65
| REFERÊNCIAS | | 67
| APÊNDICES | 71
| APÊNDICE A – REGISTRO DE VERIFICAÇÃO DO HARDWARE . | 72
A.1 | Correções no esquemático e defeitos corrigidos | | 72
A.2 | Defeitos abertos | | 72
A.3 | Limitações declaradas das análises | | 73
| APÊNDICE B – PRÁTICAS DE SISTEMAS CRÍTICOS APLICADAS
| AO FIRMWARE | | 74
B.1 | Escalas de criticidade | | 74
B.2 | Mecanismos adotados | | 74
B.3 | Limite conhecido das práticas adotadas | | 75

15

# 1 Introdução

A manutenção preditiva de máquinas rotativas por análise de vibração é uma prática normalizada. A norma ISO 20816-3:2022 estabelece faixas de severidade a partir da velocidade eficaz de vibração de banda larga e define os limites que separam operação aceitável de operação inaceitável para máquinas industriais acima de 15 kW, com rotação entre 120 e 30 000 r/min. Para essa medição, a norma exige do instrumento resposta plana em faixa de ao menos 10 Hz a 1000 Hz (ISO/TC 108/SC 2, 2022). O procedimento é consolidado, e o obstáculo à sua adoção não é metodológico: é de custo de instrumentação. Acelerômetros piezoelétricos com a banda exigida para diagnóstico, seus condicionadores e os analisadores associados restringem a cobertura aos ativos considerados críticos, e deixam sem instrumentação a maior parte do parque de motores de uma planta.

A resposta que a literatura recente oferece a esse obstáculo é o nó sensor de baixo custo: uma unidade de medição inercial MEMS acoplada a um microcontrolador de baixo consumo, com detecção de anomalia executada no próprio dispositivo e enlace de rádio de longo alcance para telemetria. A viabilidade computacional dessa arquitetura está estabelecida. O algoritmo Isolation Forest (LIU; TING; ZHOU, 2008) treina e executa dentro de um ESP32 (ANTONINI et al., 2023), existem variantes desenhadas para reduzir seu custo em TinyML (BARBARIOL; SUSTO, 2022), e a combinação de microcontrolador, acelerômetro MEMS de consumo e detecção não supervisionada já foi demonstrada em manutenção preditiva de baixo custo (KOLOK et al., 2025). O que a viabilidade computacional não resolve — e é o ponto de partida deste trabalho — é a questão anterior: o que uma cadeia de medição dessa classe efetivamente permite medir.

Essa questão tem uma ordem de precedência que organiza todo o restante. Primeiro vem a aquisição: piso de ruído, banda passante e caminho mecânico entre a fonte de vibração e o elemento sensor. Nenhuma decisão posterior recupera informação que o sensor não coletou. Depois vem a estimação, que decide o que se faz com a informação disponível: a política de limiar, a métrica de desempenho e o protocolo de validação. Por último vem a implantação — energia, comportamento térmico e invólucro —, que determina por quanto tempo o dispositivo continua operando. Os três elos são encadeados, e um erro no primeiro não é compensável nos seguintes.

É contra essa cadeia que se identifica a lacuna. A literatura de vibração embarcada é

forte no primeiro elo e frágil no segundo. Sobre aquisição, há consenso quantitativo: nenhum estudo de adequação de sensor revisado testou dispositivo com limite superior abaixo de 1500 Hz (ALBARBAR et al., 2008), e os grupos que se propõem a diagnosticar defeito de rolamento com MEMS escolhem sensores de dezenas de quilohertz (LANDI et al., 2023; JAKOBSEN, 2024), porque a assinatura do defeito viaja modulada em uma portadora de alta frequência (RANDALL; ANTONI, 2011; ANTONI, 2007). Sobre estimação, ao contrário, o

Capítulo 1. Introdução | 16

registro é lacunar. O escore do Isolation Forest tem 0,5 como referência interpretativa, e não como corte calibrado (LIU; TING; ZHOU, 2008); a implementação de referência transporta essa interpretação para um deslocamento fixo, sem alterar o ranqueamento (scikit-learn developers, 2026); e os trabalhos que reportam bom desempenho com o detector abandonam o padrão sem que a política adotada seja submetida a varredura (ANTONINI et al., 2023; BRITO et al., 2022). Não se localizou, entre os trabalhos que executam o detector em microcontrolador, nenhum que variasse o parâmetro de contaminação sobre a mesma base e reportasse a fração de operação normal marcada como anomalia, nem taxa de falso alarme publicada para detector treinado no próprio dispositivo — que é justamente o modo de operação exigido de uma máquina sem histórico rotulado. Soma-se a isso uma fragilidade de protocolo com efeito documentado: janelas consecutivas de um mesmo ensaio compartilham a assinatura da montagem, e sua divisão aleatória entre treino e teste permite que o modelo identifique o ensaio em vez da falha. Varejão et al. (2025) denominam o fenômeno similarity bias e relatam que, de 41 estudos revisados sobre uma base de referência consolidada, 40 adotaram delineamento suscetível a ele.

Este trabalho ocupa essa lacuna com uma tese delimitada. Uma cadeia de medição de baixo custo, com banda e piso de ruído declarados, sustenta a detecção de desbalanceamento sob taxa de falso alarme fixada, mas não sustenta diagnóstico de defeito de rolamento; e a contribuição verificável de um dispositivo dessa classe está no segundo elo da cadeia — limiar calibrado por risco alvo, métrica avaliada no ponto de operação e protocolo de validação sem vazamento entre ensaios —, contribuição que só é válida se o primeiro elo estiver declarado em vez de disfarçado. O objeto de estudo é o Kaelix, um dispositivo que combina acelerômetro MPU6050, microcontrolador ESP32-S3, enlace LoRa e invólucro em ASA impresso por deposição, com detecção de anomalia embarcada e rotulagem de severidade pela norma.

A validade dessa tese depende de que se declare a procedência de cada resultado, e ela não é uniforme. Os resultados de detecção por modo de falha provêm de dado real: sinais de uma bancada instrumentada, adquiridos a 50 kHz e submetidos a decimação controlada em software para emular a banda do dispositivo. O que é modelado, nesse caso, não é o sinal, é a aquisição. Os resultados sobre banda, integração, limiar, métrica e protocolo de validação provêm de sinal sintetizado, cuja resposta correta é conhecida, e sustentam relações entre métodos, não desempenho em máquina. Os resultados de análise mecânica e térmica provêm de modelagem computacional sobre as especificações de projeto, tomadas como dadas. E a cadeia física do próprio dispositivo não foi verificada: nenhum ensaio físico foi conduzido e nenhuma medição de campo alimenta os modelos, uma vez que a construção do protótipo e seu ensaio em ambiente real constituem a etapa seguinte deste trabalho. Essa distinção restringe uma afirmação específica e é declarada aqui por isso: os resultados sustentam conclusões sobre o que a cadeia de aquisição especificada permite medir, e não sobre o desempenho do dispositivo montado em operação industrial. As duas coisas serão mantidas separadas ao longo do texto, e cada resultado indicará de qual das três origens provém.

Capítulo 1. Introdução | 17

## 1.1 Objetivo

### 1.1.1 Objetivo geral

Determinar o que a cadeia de medição de vibração especificada para o Kaelix permite medir, e calibrar o estágio de decisão do detector embarcado de modo que o desempenho reportado seja verificável no ponto de operação pretendido.

### 1.1.2 Objetivos específicos

Dentro desse objetivo geral, encontram-se como metas específicas:

- Quantificar a perda de contraste do indicador de defeito de rolamento entre a cadeia de

referência e a cadeia truncada do dispositivo, e verificar se o delineamento permite atribuir essa perda à banda ou ao método de demodulação;

- Determinar o método de integração de aceleração para velocidade compatível com a norma,

e quantificar o erro dos métodos alternativos contra um sinal cuja integral é conhecida analiticamente (BRANDT; BRINCKER, 2014; ISO/TC 108/SC 2, 2022);

- Medir a taxa de falso alarme produzida pela política de limiar padrão do Isolation Forest e

o efeito do parâmetro de contaminação sobre ela;

- Comparar o desempenho do detector sob divisão aleatória por janela e sob divisão por

ensaio, e quantificar a inflação de acurácia atribuível ao vazamento de assinatura de montagem;

- Avaliar, por modelagem, a resposta modal e a margem térmica do conjunto invólucro-

sensor-fixação, e identificar qual componente impõe o limite de operação;

- Declarar, para cada questão levantada, se ela foi respondida por medição, por modelagem

ou se permanece dependente de ensaio físico.

## 1.2 Metodologia

A estratégia adotada é comum às questões investigadas: construir uma condição de referência cujo resultado correto decorre de solução analítica ou de definição normativa, submetê-la à cadeia de medição proposta e medir o desvio introduzido pela configuração do projeto. Quando a resposta certa é conhecida de antemão, um erro de implementação não consegue se esconder atrás de um resultado plausível.

O trabalho se desenvolve em quatro etapas. A primeira é a revisão da literatura, organizada por eixos correspondentes aos elos da cadeia descrita, com verificação de cada referência em

Capítulo 1. Introdução | 18

fonte primária e registro explícito das lacunas encontradas, incluindo aquelas que a própria verificação derrubou. A segunda é a caracterização da aquisição: um sinal sintetizado com resposta conhecida é submetido à cadeia de referência e à cadeia truncada, e os descritores extraídos são comparados entre elas; em paralelo, sinais de bancada adquiridos em alta taxa são decimados de forma controlada para emular a banda do dispositivo e medir a detecção por modo de falha. A terceira é a calibração do estágio de decisão, na qual a política de limiar é avaliada por varredura, o desempenho é reportado no ponto de operação de baixa taxa de falso alarme e o protocolo de validação é submetido à divisão por ensaio. A quarta é a verificação de implantação, por modelagem mecânica e térmica do conjunto montado a partir das especificações de projeto.

Duas decisões metodológicas atravessam as quatro etapas. A primeira é a rastreabilidade: cada resultado é acompanhado da indicação de sua origem — sinal sintetizado, dado real decimado ou modelagem sobre especificação — e os artefatos que o produzem, dados intermediários e código de geração, são mantidos versionados e regeneráveis. A exceção são os resultados de treino sobre dado real, que não têm artefato versionado próprio e exigem nova execução do treino para serem reproduzidos (Seção 4.2). A segunda é o registro do que não foi verificado. As questões levantadas que dependem de ensaio físico ou de consulta regulatória são enunciadas, mantidas abertas e associadas à afirmação cujo alcance elas restringem, em vez de omitidas. Esse registro é parte do método, e não uma ressalva sobre ele.

## 1.3 Estrutura do Trabalho

Este trabalho está organizado em seis capítulos. O Capítulo 1 apresentou o contexto, a lacuna identificada, a tese defendida e a procedência dos resultados que a sustentam. O Capítulo 2 apresenta os conceitos em que o trabalho se apoia: vibração de máquinas rotativas e suas assinaturas de falha, aquisição e processamento de sinais, avaliação normativa de severidade, detecção de anomalias e sua avaliação, e as restrições de um dispositivo embarcado. O Capítulo 3 revisa a literatura por eixos, seguindo a ordem de precedência da cadeia de medição, e consolida o que a literatura sustenta, o que ela contesta e quais lacunas permanecem abertas. O Capítulo 4 descreve o desenvolvimento do dispositivo: a cadeia de aquisição, o detector embarcado, o projeto de hardware e a arquitetura de comunicação e recepção. O Capítulo 5 apresenta os resultados e os confronta com a literatura revisada, organizado pela ordem de precedência da cadeia: primeiro o que a aquisição permite medir, depois o que a estimação decide com a informação disponível e, por fim, o que a implantação impõe como limite de operação. O Capítulo 6 reúne as conclusões, delimita seu alcance e enuncia o trabalho futuro decorrente das questões mantidas em aberto.

19

# 2 Fundamentação teórica

Este capítulo apresenta os conceitos sobre os quais o restante do trabalho se apoia. A ordem de exposição acompanha o percurso da informação no dispositivo estudado: parte do fenômeno físico — a vibração de uma máquina rotativa e as assinaturas que cada tipo de falha deixa nela —, passa pela conversão desse fenômeno em sequência de números, pelos critérios com que a norma avalia a severidade da vibração e pelos métodos com que um algoritmo decide se a máquina se afastou da operação normal, e termina nas restrições de um equipamento embarcado: comunicação sem fio, energia e temperatura. Ao final de cada seção, o conceito é aplicado ao dispositivo estudado, de modo que os números usados nos capítulos seguintes possam ser refeitos a partir daqui.

## 2.1 Manutenção de máquinas rotativas

A manutenção de equipamentos industriais é usualmente classificada em três estratégias, distinguidas pelo momento em que a intervenção ocorre (MOBLEY, 2002). Na manutenção corretiva, o equipamento opera até falhar e só então é reparado; o custo de planejamento é nulo, mas a falha ocorre em momento não escolhido e pode danificar componentes que estavam íntegros. Na manutenção preventiva, a intervenção ocorre em intervalos fixos de tempo ou de uso, definidos a partir da vida média esperada dos componentes; a falha inesperada torna-se menos frequente, mas componentes em bom estado são substituídos sem necessidade, e falhas que ocorrem antes do intervalo continuam não detectadas. Na manutenção preditiva, ou baseada em condição, a intervenção é decidida pelo estado medido do equipamento: acompanha-se uma grandeza física que reflete sua condição e intervém-se quando ela indica degradação.

Jardine, Lin e Banjevic (2006) descrevem um programa de manutenção baseada em condição em três etapas: aquisição de dados, processamento dos dados e tomada de decisão de manutenção. A divisão é útil porque separa problemas de natureza distinta. A aquisição é um problema de instrumentação: que grandeza medir, com que sensor, em que ponto da máquina e com que taxa. O processamento é um problema de tratamento de sinais: como extrair, dos dados brutos, indicadores que respondam à condição do equipamento. A decisão é um problema de classificação ou de detecção: a partir desses indicadores, decidir se a condição exige intervenção. Os capítulos seguintes adotam uma divisão análoga, em que a qualidade de cada etapa limita a das seguintes.

Entre as grandezas empregadas no monitoramento de máquinas rotativas, a vibração é a mais difundida, porque a maior parte dos defeitos mecânicos — desbalanceamento, desalinhamento, folga, desgaste de rolamentos e de engrenagens — altera as forças dinâmicas no interior da máquina, e essas forças se transmitem à carcaça, onde podem ser medidas sem interromper a

Capítulo 2. Fundamentação teórica | 20

operação (RANDALL, 2011).

## 2.2 Fundamentos de vibração mecânica

### 2.2.1 Deslocamento, velocidade e aceleração

Vibração é o movimento oscilatório de um ponto em torno de uma posição de equilíbrio. O movimento pode ser descrito por três grandezas relacionadas: o deslocamento x(t), a velocidade v(t) = dx/dt e a aceleração a(t) = dv/dt. Para um movimento senoidal de frequência f e amplitude de deslocamento X, com ω = 2π f ,

x(t) = X sin(ωt), | v(t) = ωX cos(ωt), | a(t) = −ω
2X sin(ωt). | (2.1)

As amplitudes das três grandezas diferem, portanto, por fatores de ω: para um mesmo deslocamento, a velocidade cresce proporcionalmente à frequência, e a aceleração, ao quadrado dela. Essa relação tem duas consequências práticas. A primeira é que a grandeza escolhida para avaliação pondera as frequências de maneira diferente: o deslocamento realça as componentes de baixa frequência, a aceleração realça as de alta frequência, e a velocidade ocupa posição intermediária. A segunda é que, conhecida uma das grandezas, as outras podem ser obtidas por derivação ou integração; em particular, um acelerômetro, que mede a(t), pode fornecer a velocidade por integração, operação discutida na Seção 2.4.3.

### 2.2.2 Descritores escalares de um sinal

Um sinal de vibração registrado durante um intervalo é frequentemente resumido por descritores escalares. Para uma janela de N amostras xn, com média x¯ e desvio padrão σ, os mais usados são (RANDALL, 2011):

xrms =

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
, | xpico = max

n

|xn|, FC =

xpico

xrms

, | κ =

1
N

ÍN

n=1

(xn − x¯)

4

σ4

. (2.2)

O valor eficaz (xrms) mede a energia média do sinal e é a base da avaliação normativa de severidade (Seção 2.6). O valor de pico e o pico a pico (diferença entre o maior e o menor valor da janela) medem a excursão máxima. O fator de crista (FC) e a curtose (κ) medem a impulsividade: quanto o sinal concentra sua energia em eventos breves e intensos. Valores de referência ajudam a interpretá-los. Uma senoide pura tem FC =

√
2 ≈ 1,41 e κ = 1,5; um ruído gaussiano tem κ = 3. Um sinal composto por impactos espaçados, como o produzido por um defeito localizado em rolamento (Seção 2.3.2), tem fator de crista e curtose bem maiores, porque

Capítulo 2. Fundamentação teórica | 21

poucos valores extremos dominam a média de quarta potência. Esses descritores são insensíveis, porém, à frequência em que a energia se concentra e à relação entre componentes de frequências diferentes; essa informação só é acessível pela análise espectral (Seção 2.4.2).

### 2.2.3 Sistema de um grau de liberdade e ressonância

O modelo mais simples de uma estrutura que vibra é o sistema de um grau de liberdade: uma massa m ligada a uma base por uma mola de rigidez k e um amortecedor. Deslocada do equilíbrio e liberada, a massa oscila na frequência natural (BRANDT, 2011)

fn =

1

2π

√︂
k

m

. | (2.3)

Quando a base vibra com frequência f , a razão entre a amplitude do movimento da massa e a da base é a transmissibilidade. Com a razão de frequências r = f / fn e a razão de amortecimento ζ,

T (r) =

√︄
1 + (2ζr)

2
(1 − r

2
)

2 + (2ζr)

2

| . | | (2.4)

Para r ≪ 1, T ≈ 1: a massa acompanha a base. À medida que f se aproxima de fn, a

transmissibilidade cresce, e em r = 1 é limitada apenas pelo amortecimento — é a ressonância. Acima de r =

√
2, T < 1 e o movimento da base é atenuado.

Esse modelo descreve um problema central da medição de vibração: o sensor não está preso diretamente à superfície da máquina, mas a um conjunto de peças — base, fixação, invólucro, placa — que tem rigidez finita. Esse conjunto e a massa que ele sustenta formam um sistema com frequência natural própria, a frequência de montagem, e o sensor mede o movimento da massa, não o da máquina. Para que a medição reproduza a vibração da superfície, a transmissibilidade precisa ficar próxima de 1 em toda a banda de interesse. Com amortecimento desprezível, o erro de amplitude é 1/(1 − r

2
) − 1, e o critério de erro máximo de 10 % exige

1

1 − r

2

≤ 1,1 | =⇒ | r ≤

1
√
11
≈ 0,30 | =⇒ | fn ≥ 3,3 fmax, | (2.5)

em que fmax é a maior frequência que se deseja medir. Para a banda normativa, cujo limite superior é 1000 Hz (Seção 2.6), a frequência de montagem precisa estar acima de cerca de 3,3 kHz.

2.2.3.0.1 Aplicação ao dispositivo estudado.

Com a rigidez do caminho de montagem de 1,45 × 10⁶ N/m e a massa de 118 g obtidas

na análise do invólucro, a Equação (2.3) dá fn ≈ 557 Hz. O erro de amplitude atinge 10 %

Capítulo 2. Fundamentação teórica | 22

em r = 0,30, isto é, em torno de 168 Hz, e em 500 Hz (r ≈ 0,90) a transmissibilidade sem amortecimento é de cerca de 5.

## 2.3 Assinaturas de falha em máquinas rotativas

Cada tipo de defeito altera a vibração de um modo característico, e é essa assinatura que permite, a partir do sinal medido, inferir o que está errado na máquina. As assinaturas dividem-se em dois grupos, conforme a escala de frequência em que se manifestam.

### 2.3.1 Defeitos síncronos com a rotação

Desbalanceamento e desalinhamento produzem forças que se repetem a cada volta do eixo, e por isso se manifestam em múltiplos inteiros da frequência de rotação fr

, as harmônicas da
rotação (RANDALL, 2011). No desbalanceamento, o centro de massa do rotor não coincide com o eixo de rotação, e a força centrífuga resultante gira com o eixo; a assinatura dominante é a componente em 1 × fr
, cuja amplitude cresce com a massa desbalanceada. No desalinhamento, os eixos acoplados não são colineares, e o acoplamento impõe esforços que variam mais de uma vez por volta; a assinatura típica é o aumento da componente em 2 × fr em relação à de 1 × fr .

Como as rotações industriais usuais estão entre algumas centenas e alguns milhares de rotações por minuto, essas componentes situam-se entre poucos hertz e algumas centenas de hertz. Um motor a 1750 rpm, por exemplo, tem fr = 29,17 Hz, e suas três primeiras harmônicas estão abaixo de 100 Hz.

### 2.3.2 Defeitos em rolamentos

O rolamento de esferas é composto por uma pista interna, solidária ao eixo, uma pista externa, fixa à carcaça, e um conjunto de esferas mantidas equidistantes por uma gaiola. Um defeito localizado — uma trinca ou um lascamento em uma das pistas — é atingido periodicamente pelas esferas, e cada passagem produz um impacto. A taxa de repetição desses impactos depende apenas da geometria do rolamento e da rotação. Para um defeito na pista externa e na pista interna, respectivamente (RANDALL; ANTONI, 2011),

BPFO =

Nb
2

fr

1 −

d

Dp

cos θ

, BPFI =

Nb
2

fr

1 +

d

Dp

cos θ

, | (2.6)

com Nb o número de esferas, d o diâmetro da esfera, Dp o diâmetro primitivo e θ o ângulo de contato. Para o rolamento SKF 6205 (Nb = 9, d/Dp = 0,203, θ = 0) a 1750 rpm, as expressões dão BPFO = 104,6 Hz e BPFI = 157,9 Hz.

A frequência de repetição, contudo, não é onde a energia do defeito aparece. Cada impacto é um evento breve, que excita as ressonâncias da estrutura entre o rolamento e o ponto de medição,

Capítulo 2. Fundamentação teórica | 23

tipicamente na faixa de alguns quilohertz. O sinal resultante é uma sequência de oscilações amortecidas na frequência de ressonância, que se repetem na taxa BPFO ou BPFI. Em termos espectrais, a energia do defeito concentra-se em torno da ressonância, e a frequência característica aparece como modulação dessa portadora de alta frequência (RANDALL; ANTONI, 2011). Nos estágios iniciais do defeito, as linhas espectrais na própria BPFO tendem a ser fracas diante das demais componentes da máquina; a informação diagnóstica está na alta frequência.

É por isso que o procedimento consolidado de diagnóstico de rolamentos é a análise de

envelope. O sinal é filtrado em uma banda em torno da ressonância; calcula-se sua envoltória, isto é, a amplitude instantânea, pelo módulo do sinal analítico obtido com a transformada de Hilbert; e o espectro dessa envoltória revela linhas na frequência de repetição dos impactos (RANDALL; ANTONI, 2011). A escolha da banda de filtragem é a etapa crítica, e a curtose espectral — a curtose calculada em função da frequência — é a ferramenta estabelecida para localizar a banda em que o sinal é mais impulsivo (ANTONI; RANDALL, 2006; ANTONI, 2007). Todo esse procedimento pressupõe que a banda de ressonância tenha sido adquirida: um sistema de medição cuja banda termina abaixo da ressonância não dispõe do sinal sobre o qual a análise de envelope opera.

## 2.4 Aquisição e processamento digital de sinais

### 2.4.1 Amostragem, frequência de Nyquist e rebatimento

Um sistema digital não registra o sinal contínuo a(t), mas amostras an = a(n/ fs) tomadas à taxa de amostragem fs

. O teorema da amostragem estabelece que um sinal pode ser reconstruído a partir de suas amostras se não contiver componentes acima de fs/2, a frequência de Nyquist (BRANDT, 2011). Uma componente acima desse limite não desaparece na amostragem: suas amostras são idênticas às de uma componente de frequência mais baixa, dentro da faixa [0, fs/2]. O fenômeno chama-se rebatimento (aliasing), e a frequência aparente de uma componente em f é

fap =

f − fs

- round
f
fs
. | (2.7)

Depois da amostragem, a componente rebatida é indistinguível de uma componente legítima naquela frequência, e nenhum processamento posterior consegue separá-las. A única proteção é remover o conteúdo acima de fs/2 antes da amostragem, por um filtro passa-baixas chamado filtro anti-rebatimento (anti-aliasing). Pela mesma razão, reduzir a taxa de um sinal já digitalizado — a decimação — exige filtrar o sinal abaixo da nova frequência de Nyquist antes de descartar amostras (BRANDT, 2011).

Capítulo 2. Fundamentação teórica | 24

2.4.1.0.1 Aplicação ao dispositivo estudado.

Com fs = 1 kHz, a frequência de Nyquist é 500 Hz. Uma ressonância de rolamento em 3,5 kHz que chegasse sem filtro ao conversor seria observada, pela Equação (2.7), em |3500 − 1000 · 4| = 500 Hz, uma frequência em que nada existe fisicamente.

### 2.4.2 Análise espectral

A representação de um sinal em função da frequência é obtida pela transformada discreta de Fourier (DFT), calculada na prática pelo algoritmo da transformada rápida (FFT). Para uma janela de N amostras,

Xk =

N

∑︁−1

n=0

xn e

−j2πkn/N
, | k = 0, 1, . . . , N − 1, | (2.8)

e o coeficiente Xk corresponde à frequência k fs/N (BRANDT, 2011). Duas propriedades limitam o que o espectro mostra. A resolução em frequência é Δ f = fs/N, o inverso da duração da janela: duas componentes mais próximas que Δ f não são separadas. E a janela finita provoca vazamento espectral: uma componente cuja frequência não coincide com um múltiplo de Δ f espalha energia pelos coeficientes vizinhos, efeito que se atenua multiplicando o sinal por uma função de janela que o leve suavemente a zero nas bordas, como a de Hann (BRANDT, 2011). Para sinais aleatórios, o espectro de uma única janela é uma estimativa muito ruidosa, e usa-se a densidade espectral de potência, obtida pela média dos espectros de várias janelas.

Para o dispositivo estudado, com fs = 1 kHz e janelas de 512 amostras, a janela dura 0,512 s e a resolução é de cerca de 1,95 Hz, suficiente para separar as harmônicas de uma rotação de 29 Hz.

### 2.4.3 Integração de aceleração para velocidade

Como a norma avalia a severidade em velocidade (Seção 2.6) e o acelerômetro fornece aceleração, é preciso integrar o sinal. A integração pode ser feita de duas formas (BRANDT; BRINCKER, 2014).

No domínio do tempo, a velocidade é aproximada pela soma acumulada das amostras de aceleração multiplicadas pelo intervalo de amostragem. O método é simples, mas tem um defeito estrutural: qualquer componente contínua presente na aceleração — um desvio de zero do sensor, por exemplo — é integrada como uma rampa, e o erro cresce linearmente com a duração do registro. Um filtro passa-alta aplicado antes da integração reduz esse efeito, mas introduz seus próprios transitórios nas bordas da janela.

No domínio da frequência, usa-se a relação da Equação (2.1): cada componente de frequência f da velocidade é a componente correspondente da aceleração dividida por j2π f .

Capítulo 2. Fundamentação teórica | 25

Calcula-se a DFT da aceleração, divide-se cada coeficiente por j2π fk , anulam-se os coeficientes fora da banda de interesse — o que elimina a componente contínua e a divisão por zero em f = 0 — e retorna-se ao tempo pela transformada inversa. Brandt e Brincker (2014) compararam os dois métodos e concluíram que a integração no domínio da frequência é a mais exata para registros longos.

Como exemplo, uma aceleração senoidal de amplitude 3,0 m/s

2
a 50 Hz corresponde a
uma velocidade de amplitude 3,0/(2π · 50) ≈ 9,55 mm/s e valor eficaz 9,55/

√
2 ≈ 6,75 mm/s. É

esse valor analítico que serve de referência para comparar os métodos de integração no Capítulo 5.

## 2.5 Transdutores de vibração

### 2.5.1 Acelerômetros piezoelétricos e MEMS

O transdutor de referência no monitoramento de máquinas é o acelerômetro piezoelétrico: uma massa sísmica apoiada sobre um cristal que gera carga elétrica proporcional à força, e portanto à aceleração. Sua frequência de ressonância interna é elevada, o que lhe confere resposta plana até vários quilohertz, e seu ruído é baixo; em contrapartida, exige condicionamento de sinal dedicado e tem custo alto (ALBARBAR et al., 2008).

Os acelerômetros de sistemas microeletromecânicos (MEMS) capacitivos são fabricados pelos mesmos processos dos circuitos integrados. Uma microestrutura suspensa por molas desloca-se sob aceleração, e o deslocamento altera a capacitância entre eletrodos. O conversor analógico-digital e o processamento digital ficam no mesmo encapsulamento, e o sensor entrega amostras digitais por barramento serial. O custo é de uma a duas ordens de grandeza menor que o de um piezoelétrico, mas a banda e o ruído dependem fortemente do modelo: há MEMS projetados para monitoramento de condição, com banda de dezenas de quilohertz, e MEMS de consumo, projetados para orientação e movimento humano, com banda de algumas centenas de hertz (ALBARBAR et al., 2008; FIDALI et al., 2024). Os critérios que decidem se um MEMS serve para uma aplicação de vibração são a banda útil, a densidade espectral de ruído, a faixa de medição e a estabilidade do zero.

A densidade espectral de ruído, expressa em µg/

√
Hz, indica o ruído por unidade de banda. Para ruído branco, o ruído eficaz na banda B é a densidade multiplicada por √
B: quanto
mais larga a banda analisada, maior o ruído total, e menor a menor vibração que o sensor consegue distinguir.

### 2.5.2 O acelerômetro MPU6050

O acelerômetro adotado no dispositivo estudado é o MPU6050, uma unidade de medição inercial de consumo que combina acelerômetro e giroscópio de três eixos. As características relevantes

Capítulo 2. Fundamentação teórica | 26

para medição de vibração, conforme a folha de dados e o mapa de registradores do fabricante, estão na Tabela 1.

Tabela 1 – Características do acelerômetro do MPU6050 relevantes para medição de vibração (InvenSense, 2011; InvenSense, 2012).

Característica | Valor
Faixa de medição | ±2, ±4, ±8 ou ±16 g, programável
Resolução do conversor | 16 bits
Taxa de saída de dados | 4 Hz a 1000 Hz, programável
Filtro passa-baixas digital (DLPF) | 5 Hz a 260 Hz, programável
Densidade espectral de ruído | 400 µg/

√
Hz a 10 Hz
Tolerância de zero (eixos X e Y) ±50 mg

Dois pontos da tabela condicionam o uso do sensor em vibração. O primeiro é a banda. A taxa máxima de saída do acelerômetro é de 1 kHz, o que situa a frequência de Nyquist em 500 Hz; mas a banda efetiva é fixada pelo filtro passa-baixas digital interno, configurado pelo campo DLPF_CFG, e não pela taxa de saída. Os valores possíveis estão na Tabela 2. Na configuração de banda mais larga, DLPF_CFG = 0, que é também o valor após a inicialização, a banda do acelerômetro é de 260 Hz; não há configuração em que o acelerômetro opere sem esse filtro (InvenSense, 2012). O mapa de registradores informa a banda e o atraso de cada configuração, mas não a ordem do filtro nem sua atenuação acima da banda, de modo que o grau de proteção contra rebatimento não é especificado pelo fabricante.

Tabela 2 – Banda e atraso do filtro passa-baixas digital do acelerômetro do MPU6050, por configuração do campo DLPF_CFG, com taxa de saída de 1 kHz (InvenSense, 2012).

DLPF_CFG | Banda (Hz) | Atraso (ms)
0 | 260 | 0
1 | 184 | 2,0
2 | 94 | 3,0
3 | 44 | 4,9
4 | 21 | 8,5
5 | 10 | 13,8
6 | 5 | 19,0

O segundo ponto é o ruído. Tratando a densidade de 400 µg/

√
Hz como ruído branco, o
ruído eficaz na banda de 260 Hz é de 400 ·

√
260 ≈ 6,5 mg, cerca de 0,063 m/s

2
. A tolerância de
zero de ±50 mg significa, por sua vez, que o sensor pode apresentar uma componente contínua de até aproximadamente 0,5 m/s

2
sem estar fora de especificação — exatamente o tipo de desvio que a integração no domínio do tempo acumula (Seção 2.4.3).

Capítulo 2. Fundamentação teórica | 27

## 2.6 Avaliação normativa da severidade de vibração

A avaliação da vibração de máquinas industriais medida em partes não rotativas é normalizada pela ISO 20816-3:2022, que substituiu a ISO 10816-3:2009 (ISO/TC 108/SC 2, 2022; ISO/TC 108/SC 2, 2009). A norma aplica-se a máquinas com potência acima de 15 kW e rotação entre 120 e 30 000 r/min, e adota como grandeza de avaliação a velocidade eficaz de banda larga. A justificativa está no próprio texto normativo: vibrações com o mesmo valor eficaz de velocidade na faixa de 10 Hz a 1000 Hz podem, em geral, ser consideradas de mesma severidade, ao passo que critérios em deslocamento ou em aceleração variariam com a frequência (ISO/TC 108/SC 2, 2022). Pela mesma razão, a norma exige do instrumento resposta plana em pelo menos 10 Hz a 1000 Hz, com limite inferior de até 2 Hz para máquinas com rotação próxima ou abaixo de 600 r/min, e determina que o sinal de acelerômetros montados na carcaça seja integrado para fornecer velocidade. A norma de instrumentação correspondente torna verificável o requisito de resposta plana, com tolerância de cerca de 10 % na banda passante (ISO/TC 108/SC 3, 2012).

O valor medido é comparado com quatro zonas de avaliação:

Zona A. Vibração típica de máquinas recém-comissionadas.

Zona B. Vibração aceitável para operação de longo prazo sem restrição.

Zona C. Vibração insatisfatória para operação contínua de longo prazo; a máquina pode operar por período limitado, até que haja oportunidade de ação corretiva.

Zona D. Vibração suficientemente severa para causar dano à máquina.

Os limites entre as zonas dependem do porte da máquina e do tipo de fundação, conforme a Tabela 3. A fundação é dita rígida quando a primeira frequência natural do conjunto máquina– fundação está suficientemente acima da frequência de excitação principal, e flexível no caso contrário. Os valores de zona são idênticos nas edições de 2009 e de 2022.

Tabela 3 – Limites entre zonas de avaliação, em velocidade eficaz de banda larga (mm/s), para máquinas industriais (ISO/TC 108/SC 2, 2022). Grupo 1: potência acima de 300 kW, ou máquinas elétricas com altura de eixo de pelo menos 315 mm. Grupo 2: potência de 15 kW a 300 kW, ou máquinas elétricas com altura de eixo entre 160 e 315 mm.

Grupo | Fundação | A/B | B/C | C/D
1 | rígida | 2,3 | 4,5 | 7,1
1 | flexível | 3,5 | 7,1 | 11,0
2 | rígida | 1,4 | 2,8 | 4,5
2 | flexível | 2,3 | 4,5 | 7,1

A tabela torna concreta a sensibilidade da avaliação ao erro de medição. A velocidade eficaz de 6,75 mm/s do exemplo da Seção 2.4.3 está na zona B para máquinas do grupo 1 em

Capítulo 2. Fundamentação teórica | 28

fundação flexível, na zona C para o grupo 1 rígido e o grupo 2 flexível, e na zona D para o grupo 2 rígido. Um erro de medição de poucos milímetros por segundo, portanto, muda a classificação e a recomendação de manutenção dela decorrente.

## 2.7 Detecção de anomalias

### 2.7.1 Paradigmas de aprendizado

A decisão sobre a condição da máquina pode ser formulada de modos diferentes, conforme os dados disponíveis para treinar o modelo (CHANDOLA; BANERJEE; KUMAR, 2009). Na abordagem supervisionada, o modelo aprende a partir de exemplos rotulados de cada condição — normal e cada tipo de falha — e classifica novos dados em uma dessas classes. Na abordagem semissupervisionada, ou de classe única, o modelo aprende apenas a partir de exemplos da condição normal e marca como anomalia o que se afasta dela. Na abordagem não supervisionada, não há rótulo algum, e o modelo supõe que as anomalias são raras e diferentes da maioria dos dados.

Em manutenção preditiva, a abordagem supervisionada esbarra em um problema prático: uma máquina recém-instalada não tem histórico de falhas, e reunir exemplos rotulados de cada defeito exige que eles ocorram. O treino apenas com dados de operação normal, disponíveis desde o primeiro dia, é por isso o modo de operação natural de um dispositivo instalado em uma máquina sem histórico (CHANDOLA; BANERJEE; KUMAR, 2009). O preço é que o modelo detecta afastamento da normalidade, e não identifica qual defeito está presente.

### 2.7.2 Isolation Forest

O Isolation Forest (LIU; TING; ZHOU, 2008) parte de uma observação simples: anomalias são poucas e diferentes, e por isso são mais fáceis de isolar do resto dos dados do que os pontos normais. O algoritmo constrói um conjunto de árvores de isolamento. Cada árvore é construída sobre uma subamostra aleatória dos dados de treino, dividindo-a recursivamente: em cada nó, escolhe-se ao acaso um atributo e um valor de corte entre o mínimo e o máximo desse atributo, até que cada ponto fique isolado em uma folha ou que se atinja um limite de profundidade. Um ponto anômalo, por estar em região de baixa densidade, tende a ser isolado em poucas divisões, isto é, perto da raiz; um ponto normal exige mais divisões.

O comprimento do caminho ℎ(x) entre a raiz e a folha em que o ponto x cai mede, portanto, quão fácil é isolá-lo. Para tornar essa medida comparável entre árvores construídas com subamostras de tamanho ψ, ela é normalizada pelo comprimento médio esperado do caminho em uma árvore binária de busca com ψ pontos,

c(ψ) = 2H(ψ − 1) − 2(ψ − 1) ψ

, | H(i) ≈ ln i + 0,5772, | (2.9)

Capítulo 2. Fundamentação teórica | 29

e o escore de anomalia é

s(x, ψ) = 2

− E[ℎ(x)]/c(ψ)
, | (2.10)

em que E[ℎ(x)] é a média do comprimento do caminho sobre todas as árvores (LIU; TING; ZHOU, 2008). O escore está entre 0 e 1. Valores próximos de 1 indicam ponto facilmente isolável, candidato a anomalia; valores bem abaixo de 0,5 indicam ponto normal; e, se todos os pontos têm escore próximo de 0,5, os dados não contêm anomalias distintas. Os valores recomendados pelos autores são t = 100 árvores e subamostras de ψ = 256 pontos, para as quais c(256) ≈ 10,2.

O algoritmo tem características que o tornam atraente para execução embarcada: o treino opera sobre subamostras pequenas, a inferência percorre cada árvore uma única vez com uma comparação por nó, e o modelo treinado é inteiramente descrito por atributos e valores de corte (LIU; TING; ZHOU, 2008). A viabilidade de treiná-lo e executá-lo em microcontrolador foi demonstrada (ANTONINI et al., 2023).

### 2.7.3 Limiar de decisão e taxa de falso alarme

O escore contínuo de anomalia precisa ser convertido em decisão binária por um limiar: acima dele, o ponto é marcado como anômalo. O limiar não é propriedade do modelo, e sim uma escolha que troca um tipo de erro pelo outro. Um limiar baixo detecta mais falhas e marca mais pontos normais como anomalia; um limiar alto faz o contrário.

Na implementação de referência do algoritmo, a escolha é controlada pelo parâmetro de contaminação, que representa a fração esperada de anomalias nos dados de treino. No valor padrão, o limiar corresponde à referência interpretativa de 0,5 do escore; com um valor numérico, o limiar é posicionado de modo que essa fração dos pontos de treino fique acima dele. Em ambos os casos, o parâmetro altera apenas o deslocamento do limiar, e não o escore calculado para cada ponto (scikit-learn developers, 2026).

Quando o treino contém apenas operação normal, o limiar pode ser calibrado diretamente pela taxa de falso alarme desejada: se o limiar é o quantil de ordem 1 − α dos escores de dados normais não usados no ajuste das árvores, espera-se que uma fração α da operação normal fique acima dele. Uma alternativa com fundamentação estatística mais forte modela apenas a cauda da distribuição dos escores pela teoria de valores extremos e fixa o limiar a partir de um risco alvo (SIFFER et al., 2017).

Capítulo 2. Fundamentação teórica | 30

## 2.8 Avaliação de detectores

### 2.8.1 Matriz de confusão e taxas derivadas

Com a anomalia como classe positiva, cada decisão do detector cai em uma de quatro categorias: verdadeiro positivo (VP), anomalia corretamente detectada; falso positivo (FP), operação normal marcada como anomalia; verdadeiro negativo (VN); e falso negativo (FN), anomalia não detectada. Dessas contagens derivam as taxas usuais (FAWCETT, 2006):

TPR =

VP
VP + FN

, FPR =

FP
FP + VN

, preciso =

VP
VP + FP
, | F1 =

2 · preciso · TPR
preciso + TPR
(2.11)

A taxa de verdadeiros positivos (TPR) é a taxa de detecção; a taxa de falsos positivos (FPR) é a taxa de falso alarme. Em monitoramento contínuo, a segunda tem peso operacional particular: um dispositivo que avalia a máquina a cada poucos minutos e marca 10 % da operação normal como anomalia gera dezenas de alarmes falsos por dia, e alarmes frequentes demais deixam de ser atendidos. A acurácia — fração de decisões corretas — é pouco informativa quando as classes são desbalanceadas, porque um detector que nunca dispara alcança acurácia alta se as anomalias são raras.

### 2.8.2 Curva ROC, área sob a curva e área parcial

Como o limiar é uma escolha, um detector não tem uma única TPR, mas uma para cada limiar. A curva ROC traça a TPR contra a FPR à medida que o limiar varre todos os valores possíveis, e a área sob essa curva (AUC) resume o desempenho em um número entre 0,5, o de uma decisão ao acaso, e 1, o de um detector perfeito (FAWCETT, 2006). A AUC tem uma interpretação direta: é a probabilidade de que uma anomalia escolhida ao acaso receba escore maior que um ponto normal escolhido ao acaso. Por depender apenas da ordenação dos escores, ela é invariante a qualquer deslocamento do limiar.

Essa mesma propriedade é sua limitação para um dispositivo de campo, que opera em um único ponto da curva, em falso alarme baixo. Dois detectores com a mesma AUC podem ter desempenhos muito diferentes nessa região. A área parcial sob a curva (pAUC) restringe a integração à faixa de FPR de interesse, entre 0 e um limite β (MCCLISH, 1989). Na forma normalizada adotada no desafio de referência de detecção não supervisionada de anomalias em máquinas (KOIZUMI et al., 2020),

pAUC(β) =

1
β

∫ β

0

TPR(FPR) d FPR, | (2.12)

em que a divisão por β normaliza o resultado para o intervalo [0, 1]; o desafio adota β = 0,1.

Capítulo 2. Fundamentação teórica | 31

### 2.8.3 Validação cruzada e vazamento de informação

O desempenho de um modelo só é informativo se medido em dados não usados no treino. Na validação cruzada em k partições, os dados são divididos em k partes; o modelo é treinado k vezes, cada vez com uma parte reservada para teste, e o desempenho é a média das k avaliações, acompanhada de sua dispersão. A dispersão entre partições é informação, e não ruído a descartar: ela indica quanto o resultado depende de quais dados foram usados no teste.

A validade da validação cruzada exige que as partes de treino e de teste sejam indepen-dentes. Quando não são, ocorre vazamento de informação: o modelo tem acesso, no treino, a informação que não estaria disponível na aplicação real, e o desempenho medido superestima o desempenho verdadeiro (KAUFMAN et al., 2012). Em sinais de vibração, a forma mais comum de vazamento vem da segmentação. Um ensaio de alguns segundos é dividido em muitas janelas, e janelas do mesmo ensaio compartilham características que nada têm a ver com a falha — nível de ruído, ganho do sensor, condição de fixação. Se as janelas são distribuídas aleatoriamente entre treino e teste, o modelo pode acertar reconhecendo o ensaio, e não a falha. Varejão et al. (2025) denominam esse efeito viés de similaridade. A correção é a validação por grupos: todas as janelas de um mesmo ensaio são mantidas na mesma partição, de modo que o teste é sempre feito sobre ensaios inteiramente desconhecidos pelo modelo.

## 2.9 Sistemas embarcados para monitoramento

Um nó sensor de monitoramento é um sistema embarcado: um computador dedicado a uma única função, integrado ao equipamento que atende e sujeito a restrições de memória, de processamento e, sobretudo, de energia. O componente central é o microcontrolador, que reúne processador, memória e periféricos — conversores, interfaces seriais, temporizadores — em um único circuito integrado.

O microcontrolador adotado no dispositivo estudado é o ESP32-S3, com dois núcleos de processamento de até 240 MHz, 512 kB de memória SRAM, coprocessadores de ultrabaixo consumo e rádios Wi-Fi e Bluetooth integrados (Espressif Systems, 2026). Para a operação a bateria, a característica decisiva são os modos de baixo consumo: no modo deep-sleep, os núcleos principais e a maior parte dos periféricos são desligados, e o consumo cai para cerca de 7 µA

(Espressif Systems, 2026).

A estratégia usual de um nó a bateria é o ciclo de trabalho: o dispositivo permanece a maior parte do tempo em modo de baixo consumo, desperta em intervalos regulares, adquire e processa uma janela de sinal, transmite o resultado e volta a dormir. A corrente média é a média das correntes de cada fase, ponderada pela fração do ciclo que ela ocupa, e a autonomia é a capacidade da bateria dividida por essa corrente média. Como a fase de sono ocupa quase todo o ciclo, a corrente de sono e a duração das fases ativas — em especial a transmissão — dominam a autonomia.

Capítulo 2. Fundamentação teórica | 32

Executar a detecção no próprio dispositivo, em vez de transmitir o sinal bruto para processamento remoto, é o que viabiliza esse ciclo: transmitir uma janela de 512 amostras de três eixos custaria ordens de grandeza mais tempo de rádio que transmitir um escore. A execução de modelos de aprendizado de máquina em microcontroladores, com memória de centenas de quilobytes e consumo de miliwatts, é o campo denominado TinyML (ANTONINI et al., 2023; BARBARIOL; SUSTO, 2022).

## 2.10 Comunicação de longo alcance: LoRa

LoRa é uma técnica de modulação de rádio projetada para enlaces de longo alcance e baixo consumo, à custa de baixa taxa de dados (AUGUSTIN et al., 2016). Ela usa espalhamento espectral por chirp: cada símbolo é representado por um sinal cuja frequência varia linearmente ao longo de toda a largura de banda do canal. O espalhamento permite demodular sinais abaixo do nível de ruído, o que aumenta o alcance. LoRa designa a camada física; LoRaWAN é um protocolo de rede definido sobre ela, com servidores de rede e gerência de dispositivos. Um enlace ponto a ponto, entre o dispositivo e um receptor próprio, pode usar a modulação LoRa sem o protocolo LoRaWAN.

Três parâmetros controlam o compromisso entre alcance, taxa e consumo (Semtech, 2015):

Fator de espalhamento (SF), de 6 a 12: cada símbolo carrega SF bits e é formado por 2

SF chips.

Cada incremento de SF dobra a duração do símbolo e aumenta a sensibilidade do receptor.

Largura de banda (BW), tipicamente 125 kHz: banda mais larga encurta o símbolo e reduz a sensibilidade.

Taxa de codificação (CR), de 4/5 a 4/8: fração de redundância acrescentada para correção de erros.

A taxa de símbolos é Rs = BW/2

SF, e a duração do símbolo é Ts = 1/Rs . A duração total
de um pacote, o tempo no ar, é a soma da duração do preâmbulo e da carga útil (Semtech, 2015):

Tpacote = (npre + 4,25) Ts

+

8 + max8 PL − 4 SF + 28 + 16 CRC − 20 IH 4(SF − 2 DE)

(CR + 4), 0

Ts

,

(2.13)

em que npre é o número de símbolos do preâmbulo, PL o número de bytes da carga útil, CRC vale 1 quando a verificação de redundância está habilitada, IH vale 1 quando o cabeçalho é omitido, DE vale 1 quando a otimização para baixa taxa está ativa, e CR vale de 1 (para 4/5) a 4 (para 4/8).

Capítulo 2. Fundamentação teórica | 33

2.10.0.0.1 Aplicação ao dispositivo estudado.

O enlace do dispositivo usa SF9, BW = 125 kHz, CR = 4/5, preâmbulo de 8 símbolos e carga útil de 21 bytes, com cabeçalho e CRC habilitados e sem otimização para baixa taxa. A duração do símbolo é 2

9
/125 000 = 4,096 ms; o preâmbulo ocupa (8 + 4,25) × 4,096 ≈ 50,2 ms; a carga útil ocupa 8 + ⌈176/36⌉ × 5 = 33 símbolos, ou 135,2 ms. O tempo no ar resultante é de cerca de 185 ms. Em SF12, a mesma carga útil ocuparia o rádio por um tempo várias vezes maior, e é por isso que a escolha do fator de espalhamento é, ao mesmo tempo, uma escolha de alcance e de autonomia.

## 2.11 Transferência de calor e limites térmicos

Um dispositivo fixado à carcaça de um motor recebe calor da superfície em que está montado. Em regime permanente, a condução de calor por uma camada de espessura L, área A e condutividade térmica kt pode ser descrita por uma resistência térmica R = L/(kt A), e a diferença de temperatura através dela é o produto do fluxo de calor pela resistência, ΔT = q R (BERGMAN et al., 2011). Camadas em série somam suas resistências, como resistores elétricos. O modelo permite estimar a temperatura interna do dispositivo a partir da temperatura da carcaça, das resistências do caminho e da potência dissipada internamente.

A consequência para a escolha de material é direta: um invólucro de polímero, cuja condutividade é duas a três ordens de grandeza menor que a de um metal, oferece resistência térmica muito maior e isola o interior da carcaça quente; um invólucro metálico faz o contrário. Como a Seção 2.2.3 mostrou, a rigidez — e portanto a frequência de montagem — também depende do material, e os dois requisitos podem apontar em sentidos opostos.

Entre os componentes internos, a bateria é tipicamente o mais sensível à temperatura. A temperatura acelera os mecanismos de degradação das células de íon-lítio, e a carga em temperatura elevada é particularmente prejudicial, razão pela qual os fabricantes especificam faixas de temperatura mais estreitas para carga do que para descarga (MA et al., 2018). O limite térmico de um dispositivo com bateria recarregável depende, por isso, da fase de operação. Durante a descarga, a potência dissipada internamente é pequena e a temperatura interna é ditada pela carcaça. Durante a carga, surge uma fonte interna de calor: um carregador linear dissipa a diferença entre a tensão de entrada e a da célula multiplicada pela corrente de carga, P = (Vin − Vbat) I, e essa potência se soma ao calor vindo da carcaça justamente na fase em que o limite admissível da célula é mais baixo. É comum que o carregador monitore a temperatura

da célula por um termistor e suspenda a carga fora da faixa permitida, o que converte o limite térmico em uma interrupção da carga, e não em dano à célula.

Capítulo 2. Fundamentação teórica | 34

## 2.12 Síntese do capítulo

Os conceitos apresentados organizam-se na mesma sequência que a informação percorre no dispositivo. A vibração da máquina carrega assinaturas em duas escalas de frequência: defeitos síncronos com a rotação, em harmônicas de baixa frequência, e defeitos de rolamento, cuja informação está modulada em ressonâncias de alguns quilohertz. O caminho mecânico até o sensor, modelado como sistema de um grau de liberdade, pode amplificar ou distorcer essa vibração antes de ela ser medida. A amostragem e o filtro anti-rebatimento decidem que parte do espectro chega ao processamento, e o que fica de fora não é recuperável. A norma fixa a grandeza, a banda e os critérios com que a severidade é avaliada, e a integração de aceleração para velocidade é a etapa em que um erro numérico pode mudar a zona de classificação. O detector de anomalias converte descritores do sinal em escore, e o limiar converte o escore em decisão, escolha que determina a taxa de falso alarme; a curva ROC, a área parcial e a validação por grupos são os instrumentos que tornam esse desempenho mensurável sem superestimá-lo. Por fim, o rádio, a bateria e o comportamento térmico impõem os limites dentro dos quais o dispositivo pode operar.

O capítulo seguinte examina como a literatura aplicou esses conceitos a dispositivos de baixo custo, e quais questões ela deixou em aberto.

35

# 3 Trabalhos relacionados

## 3.1 Método da revisão

A revisão foi conduzida por confronto, e não por levantamento: cada seção parte de uma escolha de projeto ou de um resultado obtido e pergunta o que a literatura publicada diz sobre ele — se o confirma, se o contradiz ou se nada diz.

Todas as referências foram conferidas em fonte primária: depósito do editor, texto integral do artigo, amostra oficial da norma ou folha de dados do fabricante. Onde o texto integral não pôde ser acessado, isso consta na própria referência, e o achado correspondente é tratado como de menor peso. Essa verificação não é formalidade: duas auditorias sucessivas encontraram defeito em parcela substancial das referências inicialmente levantadas — primeiro autor trocado, iniciais incorretas colapsando autores distintos, norma retirada citada como vigente e, em três casos, achado atribuído a uma fonte que não o continha.

Um eixo temático levantado na fase inicial não integra esta revisão. Nenhuma das referências que o sustentariam sobreviveu à verificação em fonte primária, e a decisão foi não citar o que não foi conferido. O registro fica aqui porque uma revisão que apresenta apenas os eixos sobreviventes esconde o método que os selecionou.

A organização segue a ordem de precedência da cadeia de medição, a mesma do Capítulo 5: primeiro a aquisição, que decide que informação existe; depois a normalização, que impõe requisitos sobre o instrumento e sobre a estimativa; em seguida a estimação, que decide o que se faz com a informação disponível; por fim a implantação, que decide por quanto tempo o dispositivo continua operando.

## 3.2 Aquisição: banda, ruído e detectabilidade de defeito de rola-

## mento

A tensão que organiza esta literatura é única: as frequências que se deseja medir em um rolamento são baixas, mas o mecanismo físico que as torna mensuráveis é alto. O defeito produz impactos periódicos na frequência característica da geometria, na ordem de dezenas a centenas de hertz, e esses impactos excitam ressonâncias estruturais de alguns quilohertz. A assinatura diagnóstica viaja modulada nessa portadora de alta frequência, e é por demodulação de envelope sobre a banda de ressonância que ela é recuperada (RANDALL; ANTONI, 2011; ANTONI; RANDALL, 2006; ANTONI, 2007). O procedimento padrão localiza a banda ótima pela díade que maximiza a impulsividade do sinal filtrado (ANTONI, 2007); um dispositivo cuja frequência de Nyquist é de 500 Hz não tem díade a escolher.

Capítulo 3. Trabalhos relacionados | 36

Os estudos de adequação de sensor convergem para o limite superior de banda como a variável determinante, e nenhum testa dispositivo próximo da faixa do Kaelix. A comparação de três acelerômetros MEMS capacitivos contra um piezoelétrico de referência reprovou o de banda mais estreita, de 1500 Hz, para monitoramento de condição (ALBARBAR et al., 2008). Os grupos que se propõem a diagnosticar rolamento com MEMS escolhem sensores de dezenas de quilohertz (LANDI et al., 2023; SHARMA et al., 2024), e uma implementação de baixo custo publicada resolve o problema por projeto, reservando um acelerômetro de banda estreita para desbalanceamento e outro de 40 kHz para rolamento (JAKOBSEN, 2024). Os produtos comerciais medem, ao menos em um eixo, uma ordem de grandeza acima do teto de uma IMU de consumo (Bently Nevada (Baker Hughes), 2025; Erbessd Instruments, 2025; TRACTIAN, 2022).

Há uma segunda objeção, anterior à banda e independente dela: o piso de ruído. A densidade de ruído declarada em folha de dados para uma IMU de consumo, integrada sobre a banda normativa, situa o sensor acima do ruído admissível para resolver a fronteira entre as zonas normativas mais baixas. A literatura de MEMS levanta, de forma convergente, a ausência de calibração rastreável desses dispositivos (ALBARBAR et al., 2008; RODRIGUES et al., 2021), e a avaliação de sensibilidade diagnóstica de sensores digitais de catálogo chega à mesma leitura (FIDALI et al., 2024). O orçamento de ruído usualmente atribuído à literatura de fabricante não pôde ser confirmado em fonte primária (LOONEY, 2017), e fechar essa conta com densidade medida, e não declarada, permanece pendente.

Um efeito adicional é pouco documentado e afeta diretamente dispositivos de consumo: a ausência de filtro anti-aliasing configurado abaixo da frequência de Nyquist. Sem ele, conteúdo espectral acima da banda dobra para dentro da faixa de análise e torna-se indistinguível de sinal legítimo. Não se localizou, na literatura revisada por pares de diagnóstico de rolamento, descrição experimental do efeito desse artefato sobre descritores estatísticos como curtose e fator de crista; ele aparece apenas em notas de aplicação de fabricante, não conferidas nesta revisão.

## 3.3 Normalização: o que a norma exige do instrumento e da

## estimativa

A avaliação de severidade em velocidade eficaz não é convenção arbitrária de unidades, mas escolha justificada no próprio texto normativo (ISO/TC 108/SC 2, 2022). A norma vigente estabelece as zonas de severidade para máquinas acima de 15 kW com rotação entre 120 e 30 000 r/min, e exige do instrumento resposta plana em faixa de ao menos 10 Hz a 1000 Hz, com limite inferior de até 2 Hz em máquinas próximas ou abaixo de 600 r/min.

A distinção entre requisito de instrumento e janela de análise é decisiva e frequentemente perdida. A exigência de resposta plana recai sobre o instrumento; é isso que torna o truncamento de banda uma violação de requisito, e não uma escolha de processamento reversível. A edição

Capítulo 3. Trabalhos relacionados | 37

anterior da norma delega esse “plana” a uma norma de instrumentação que o torna verificável, com tolerância de banda passante de aproximadamente 10 % entre 12,6 Hz e 1000 Hz e limitação de banda por par de Butterworth de terceira ordem (ISO/TC 108/SC 3, 2012).

A edição de 2009 foi retirada e substituída pela de 2022 (ISO/TC 108/SC 2, 2009; ISO/TC 108/SC 2, 2022). Os valores de zona são idênticos nas duas, de modo que a substituição afeta a rastreabilidade da citação e não os números. A edição anterior é mantida na bibliografia por ser a que a prática industrial e parte da literatura ainda adotam, e por ser nela que está a delegação explícita à norma de instrumentação.

A conversão de aceleração para velocidade é obrigação normativa, e é também um problema numérico com solução conhecida. A integração no domínio do tempo acumula qualquer componente contínua presente no sinal, e o erro resultante cresce sem limite; a integração no domínio da frequência, restrita à máscara normativa, é o método estabelecido, e a comparação quantitativa entre os dois está publicada (BRANDT; BRINCKER, 2014). O que não se localizou publicado é a aplicação desse método ao indicador da norma em um dispositivo truncado — isto é, quanto um instrumento limitado a 500 Hz subestima o indicador normativo frente à banda exigida.

## 3.4 Estimação: detector, limiar, métrica e protocolo

Esta literatura desloca a pergunta de engenharia, mas o deslocamento é condicional, e a condição precisa ficar à vista: dada banda de medição suficiente, o que decide o desempenho não é qual detector se escolhe, e sim como o limiar é calibrado, com que métrica o resultado é lido e quanto do orçamento do microcontrolador o modelo consome. Sem banda, nada disso importa — nenhum corte de escore transforma contraste ausente em detecção.

### 3.4.1 A escolha do detector não tem consenso

Dois comparativos de grande porte discordam, e a discordância é informativa porque medem coisas diferentes. O maior em cobertura de paradigmas avalia 30 algoritmos sobre 57 conjuntos de dados e conclui que nenhum método não supervisionado é estatisticamente superior aos demais (HAN et al., 2022). A maior comparação restrita a métodos não supervisionados, com 33 algoritmos sobre 52 conjuntos tabulares reais, encontra vantagem para o Extended Isolation Forest, com a ressalva de que os dados se separam em dois regimes (BOUMAN; BUKHSH; HESKES, 2024). Não há contradição, e sim escopos distintos — mas há consequência: a evidência disponível recomenda uma variante que este trabalho não adota.

A razão para permanecer no algoritmo canônico (LIU; TING; ZHOU, 2008) é de custo de implementação embarcada, e é verificável em estrutura: um nó da variante estendida armazena um vetor normal com tantas componentes quantos forem os descritores, e a inferência passa de uma comparação para um produto interno por nó. É argumento de projeto, e não resultado de

Capítulo 3. Trabalhos relacionados | 38

literatura; enquanto o orçamento embarcado não for medido no dispositivo, a escolha permanece limitação de escopo declarada, não conclusão.

O suporte específico para máquinas rotativas é, em contrapartida, o melhor que o algoritmo canônico tem: entre 11 detectores não supervisionados, atinge F1 de 97,19 em rolamento run-to-failure e 97,20 em faltas mecânicas de bancada (BRITO et al., 2022). Os dois primeiros conjuntos são adquiridos a 20 kHz, banda que uma IMU de consumo não possui.

### 3.4.2 O limiar padrão não é calibração

No artigo fundador, o escore tem 0,5 como referência interpretativa, e a robustez demonstrada está nos parâmetros do ensemble, não no corte (LIU; TING; ZHOU, 2008). A implementação de referência explicita o mecanismo: o parâmetro de contaminação redefine apenas um deslocamento fixo, nunca o escore subjacente (scikit-learn developers, 2026). Seguem daí duas consequências mecânicas: o corte padrão é herdado de uma interpretação, e não estimado nos dados; e toda métrica de ranqueamento, área sob a curva ROC inclusive, é invariante ao parâmetro.

Os trabalhos que reportam bom desempenho abandonam o padrão — fixando o escore normalizado em 0,75 sob hipótese de treino limpo (ANTONINI et al., 2023), ou derivando o corte da razão de contaminação conhecida (BRITO et al., 2022). A alternativa principiada dispensa hipótese sobre a distribuição do corpo dos dados e fixa o limiar a partir de um risco alvo, que controla diretamente o número de falsos positivos (SIFFER et al., 2017).

O problema não é teórico. As duas implementações do mesmo detector em nó embarcado que reportam falso alarme, ou permitem derivá-lo, situam-se entre 22 e 38 % sobre operação normal (CHEVTCHENKO et al., 2023; KOLOK et al., 2025). Um dispositivo que marca um terço da operação normal como anomalia não é utilizável em manutenção.

### 3.4.3 A métrica e o protocolo de validação

A área sob a curva ROC global não caracteriza o ponto de operação de um dispositivo de campo, que precisa operar em falso alarme baixo. O benchmark de referência para o mesmo regime de treino reporta área parcial restrita a essa faixa (KOIZUMI et al., 2020), e a mesma disciplina aparece em quem reporta PR-AUC além do F1 (BRITO et al., 2022).

Sobre o protocolo, a objeção é a mais séria, e sua identificação não é contribuição deste trabalho: ela está publicada. Janelas consecutivas de um mesmo ensaio compartilham a assinatura da montagem, e sua divisão aleatória entre treino e teste permite que o modelo identifique o ensaio em vez da falha. O fenômeno tem nome e quantificação: de 41 estudos revisados sobre uma base de referência consolidada, 40 adotaram delineamento suscetível a ele (VAREJÃO et al.,

2025), e a inflação medida por vazamento é da ordem de dezenas de pontos percentuais (VIEIRA et al., 2026). Trabalhos que revisam abordagens de classificação de falha de rolamento chegam a leitura convergente (ABBURI et al., 2023; SMITH; RANDALL, 2015).

Capítulo 3. Trabalhos relacionados | 39

## 3.5 Implantação: nós comparáveis, invólucro e energia

A literatura de nós sem fio para manutenção preditiva divide-se em duas populações que raramente se citam. De um lado, produtos comerciais, com banda uma ordem de grandeza acima da de uma IMU de consumo, caminho mecânico rígido até o elemento sensor e alimentação por célula primária (Bently Nevada (Baker Hughes), 2025; Erbessd Instruments, 2025; TRACTIAN, 2022). De outro, nós acadêmicos de baixo custo, que convergem para a mesma arquitetura estudada aqui: microcontrolador de baixo consumo, IMU MEMS na ordem de 1 kHz e detecção não supervisionada (KOLOK et al., 2025; ANTONINI et al., 2023; BISIO et al., 2025).

### 3.5.1 O que a literatura de nós de baixo custo autoriza concluir

O análogo mais próximo em hardware e em modo de falha reporta acurácia de 72,9 % ± 2,4 %, com validação cruzada de cinco dobras sobre cerca de 900 amostras e um único modo de falha (KOLOK et al., 2025). O dado valida a arquitetura como publicável. O que ele não faz é fixar teto de desempenho da classe: a amostra é de um estudo único com um modo de falha, e o trabalho encerra em valor eficaz de aceleração, sem integração para velocidade e sem critério normativo.

A comparação mais direta é embarcada e mede três detectores no mesmo nó e no mesmo conjunto (CHEVTCHENKO et al., 2023). No mesmo hardware e no mesmo dado, um método baseado em vizinhança domina o algoritmo adotado aqui tanto em especificidade quanto em latência, sendo cerca de 26 vezes mais rápido. A resposta declarada é de custo de memória — o método de vizinhança exige manter o conjunto de referência, enquanto a floresta armazena apenas limiares e índices — mas o orçamento embarcado ainda não foi medido, e a permanência no detector adotado é hipótese de projeto, não conclusão.

O mesmo trabalho traz um achado que é restrição de implantação, e não detalhe: um motor com cerca de um ano de uso tem assinatura normal distinta da de motores novos (CHEVTCHENKO et al., 2023). Um modelo único com limiar fixo herda essa deriva do que conta como normal entre máquinas e ao longo da vida — cenário em que a calibração por risco alvo deixa de ser refinamento e passa a ser requisito.

A viabilidade computacional, em contrapartida, está estabelecida: o detector treina e executa dentro de um microcontrolador da classe (ANTONINI et al., 2023), existe variante desenhada para reduzir seu custo em TinyML (BARBARIOL; SUSTO, 2022), e dispositivos da mesma família comportam pipelines consideravelmente mais caros (USELIS; SERACKIS; ¯

POMARNACKI, 2025; KUMAR et al., 2026).

### 3.5.2 Invólucro e caminho mecânico

É na física do dispositivo que a literatura contraria o projeto mais diretamente. A prática consoli-

dada em acelerometria exige que a frequência natural do conjunto montado seja suficientemente

Capítulo 3. Trabalhos relacionados | 40

superior à maior frequência de interesse, e os produtos comerciais obtêm isso por base metálica aparafusada ou colada ao ativo. Nenhum dos nós de baixo custo revisados publica a frequência natural do conjunto invólucro-sensor-fixação: um deles reporta apenas autorressonâncias de placa e estrutura entre 6 kHz a 9 kHz (JAKOBSEN, 2024), outro adia explicitamente o invólucro (ANTONINI et al., 2023), e para um terceiro o dado não foi localizado na parte acessível do texto (BISIO et al., 2025).

### 3.5.3 Energia e margem térmica

Na energia, a literatura contraria o projeto com clareza. O campo adota célula primária, e portanto nunca carrega nada (NABAVI; HAJFOROOSH; NABAVI, 2025); a revisão térmica disponível estabelece o mecanismo de degradação por temperatura, mas não o limite de carga (MA et al., 2018). O limite de carga de uma célula secundária vem da folha de dados e das normas de segurança aplicáveis, não da literatura de manutenção preditiva. O orçamento térmico completo — carcaça quente, invólucro fechado e célula carregando — não foi localizado publicado, e é ele que decide se a escolha de bateria sobrevive.

## 3.6 Síntese

Lidos em conjunto, os eixos não formam uma lista de pontos fortes e fracos: formam uma cadeia com ordem de precedência. Primeiro a aquisição — piso de ruído, banda e caminho mecânico —, e nenhuma decisão posterior recupera informação que o sensor não coletou. Depois a estimação, que decide o que se faz com a informação disponível. Por último a implantação, que decide por quanto tempo o dispositivo continua operando.

A conclusão desta revisão é que a literatura é mais forte onde o dispositivo é mais frágil, no primeiro elo, e mais frágil onde o dispositivo tem algo a dizer, no segundo.

### 3.6.1 O que a literatura sustenta

O problema do limiar é real e não é preciosismo, e a alternativa principiada existe. A disciplina de reportar a métrica no ponto de operação, e não apenas de forma agregada, tem respaldo em benchmark de referência. A viabilidade computacional da arquitetura está estabelecida, e a exigência de integrar aceleração para velocidade é normativa, com método correto estabelecido. A forma do limite térmico durante a carga — margem imposta pela célula e não pelo invólucro — tem precedente comercial direto.

### 3.6.2 O que a literatura contesta

As objeções são de peso, e nenhuma se resolve com ajuste de software. A banda: nenhum estudo de adequação revisado testou sensor com limite superior próximo ao desta classe, e o

Capítulo 3. Trabalhos relacionados | 41

mecanismo físico da assinatura de rolamento não admite contorno. O piso de ruído: a objeção é anterior à banda e não depende de nenhuma escolha de processamento. O detector: a maior comparação restrita a métodos não supervisionados recomenda outra variante, e no mesmo hardware embarcado um método de vizinhança mostrou-se mais específico e mais rápido. Nenhuma dessas três objeções foi respondida por medição neste trabalho; as respostas oferecidas são critérios de projeto declarados, e permanecem hipóteses até que o orçamento embarcado seja medido.

## 3.7 Lacunas identificadas

Cada lacuna abaixo declara o que foi procurado, onde, e o que não foi encontrado. Duas lacunas enunciadas na fase inicial caíram na verificação e estão registradas como caídas, porque uma revisão que apresenta apenas as lacunas sobreviventes esconde o método.

Caíram na verificação. A afirmação de que não existiria falso alarme publicado para o detector em nó embarcado é falsa: dois trabalhos o reportam ou permitem derivá-lo (CHEVTCHENKO et al., 2023; KOLOK et al., 2025). A afirmação de que ninguém quantificaria a fração de operação normal marcada pela política de limiar padrão também é falsa, pelo mesmo motivo.

1. Efeito isolado do parâmetro de contaminação. Não se localizou trabalho que variasse o parâmetro sobre a mesma base e o mesmo modelo reportando a fração de operação normal marcada. O experimento que falta é barato e definitivo.
2. Falso alarme de detector treinado no próprio dispositivo. O único trabalho revisado que treina on-device é justamente o que declara a avaliação de acurácia fora de escopo (ANTONINI et al., 2023) — e esse é o modo de operação exigido de uma máquina sem histórico rotulado.
3. Contraste diagnóstico como função contínua da banda. A literatura discute o efeito da banda qualitativamente, e o único estudo revisado que faz varredura de taxa de amostragem o faz para acurácia de classificador supervisionado, não para contraste do indicador (BOUHARROUTI; MORINIGO-SOTELO; BELAHCEN, 2024).
4. Artefato de aliasing sobre descritores estatísticos. Não localizado em literatura revisada por pares; aparece apenas em notas de aplicação de fabricante.
5. Custo do truncamento sobre o indicador normativo. O erro dos métodos de integração está quantificado (BRANDT; BRINCKER, 2014), mas não a aplicação ao indicador da norma em dispositivo truncado.
6. Detectabilidade limitada por piso de ruído. Não se localizou análise de defeito mínimo detectável em função da densidade de ruído para IMUs de consumo.

Capítulo 3. Trabalhos relacionados | 42
7. Frequência natural do conjunto montado. Nenhum nó de baixo custo revisado a publica.
8. Orçamento térmico de carga de célula secundária em nó montado em carcaça de motor.
9. Separar efeito de banda de efeito de montagem. Não se localizou benchmark aberto com sinais gravados simultaneamente por MEMS de banda limitada e por piezoelétrico no mesmo ponto. Sem isso, os dois efeitos permanecem confundidos em qualquer medição de campo, inclusive nas deste projeto.

O Capítulo 5 aborda a lacuna 1, em sinal sintetizado, e oferece à lacuna 3 apenas um par de pontos, insuficiente para constituir uma função da banda. As demais, incluindo a 5, permanecem abertas e reaparecem como trabalho futuro no Capítulo 6.

43

# 4 Desenvolvimento e métodos

## 4.1 Delimitação

O objeto de estudo é o Kaelix, um dispositivo de monitoramento de vibração de baixo custo composto por acelerômetro MPU6050, microcontrolador ESP32-S3, enlace LoRa e invólucro em ASA impresso por deposição, com detecção de anomalia embarcada e rotulagem de severidade pela norma. As especificações de hardware, as cotas do desenho mecânico e a arquitetura de processamento são tomadas como dadas; o que se determina é o que elas permitem medir.

A estratégia é comum a todas as questões investigadas: construir uma condição de referência cujo resultado correto decorre de solução analítica ou de definição normativa, submetê-la à cadeia proposta e medir o desvio introduzido pela configuração do projeto. Quando a resposta certa é conhecida de antemão, um erro de implementação não consegue se esconder atrás de um resultado plausível.

Nenhum ensaio físico foi conduzido e nenhuma medição de campo alimenta os modelos. A construção do protótipo e seu ensaio em ambiente real são a etapa seguinte declarada deste trabalho. As três procedências de resultado que decorrem dessa delimitação — sinal sintetizado, dado real decimado e modelagem sobre especificação — estão definidas na Seção 5.1, e cada valor do Capítulo 5 é marcado individualmente por elas.

## 4.2 Modelo de sinal e cadeias de aquisição

### 4.2.1 Sinal sintetizado

Os sinais foram sintetizados com dois mecanismos de escalas de frequência distintas. Desbalanceamento e desalinhamento aparecem como componentes harmônicas da rotação, todas abaixo de 100 Hz. Defeito de pista externa aparece como um trem de impulsos amortecidos, repetido na taxa característica da geometria e modulando uma ressonância estrutural. A aceleração simulada é

a(t) =

∑︁

3

k=1

Ak sin(2πk fr

t + φk )

| | {z | }
| banda baixa

+

∑︁

i

D e−ζd (t−ti)
sin(2π fres(t − ti)) u(t − ti)
| | {z | }
| impactos do defeito

+ ε(t), (4.1)

com fr a rotação, Ak as amplitudes harmônicas, D a amplitude do defeito, ζd a taxa de amortecimento do impacto, fres a ressonância excitada, u(·) o degrau unitário e ε(t) ruído gaussiano

Capítulo 4. Desenvolvimento e métodos | 44

branco. Os instantes de impacto são ti = i/BPFO + δi
, em que δi modela o escorregamento das esferas. As frequências características decorrem da geometria do rolamento pelas expressões usuais de BPFO e BPFI.

### 4.2.2 Três cadeias comparadas sobre o mesmo sinal

A comparação isola o efeito da aquisição mantendo o sinal fixo:

1. Referência — amostragem a 20 kHz, representando um acelerômetro de banda larga.
2. Dispositivo corretamente configurado — decimação para 1 kHz com filtro anti-aliasing.
3. Dispositivo sem filtro — subamostragem para 1 kHz sem filtro, representando a leitura direta do registrador quando o filtro passa-baixas digital interno não é configurado.

No terceiro caso, uma componente em f acima de Nyquist é observada na frequência aparente

fap =

f − fs

f
fs

+

1
2
, | (4.2)

com fs a taxa de amostragem e ⌊·⌉ o arredondamento ao inteiro mais próximo. É essa cadeia que

corresponde ao estado atual do firmware (Seção 4.6).

Na comparação entre cadeias, os descritores extraídos por janela são o valor eficaz, a curtose, o fator de crista, o pico e o pico a pico. O detector embarcado usa um conjunto menor, idêntico no treino e no firmware: valor eficaz, curtose, fator de crista e frequência dominante. A escolha tem consequência analisada no Capítulo 5: os descritores descrevem energia, impulsividade e a linha espectral mais intensa, e nenhum captura a relação entre harmônicas ou a fase.

### 4.2.3 Dado real decimado

Para as taxas de detecção por modo de falha, o sinal não é sintetizado. Utilizaram-se as gravações do conjunto público MAFAULDA, obtidas em bancada instrumentada a 50 kHz e decimadas em software para 1 kHz, a banda do dispositivo. O conjunto soma 1951 arquivos em seis classes — operação normal, desbalanceamento, desalinhamento horizontal e vertical e defeito de rolamento nas posições overhang e underhang —, segmentados em 17 559 janelas de 512 amostras. Apenas 49 arquivos são de operação normal, e é deles que sai todo o treino, já que o detector aprende somente a operação normal. A bancada está abaixo do escopo de potência e altura de eixo da norma, o que a torna adequada como fonte de sinal para estudar a cadeia de medição e inadequada como caso de aplicação normativa.

Capítulo 4. Desenvolvimento e métodos | 45

J1 LiPo 3,7V

bateria

Q3
SI2301CDS

U4 HT7333 LDO · Iq ~8 µA

+3V3

C9 1u

C10 1u

R9 1M

R10 1M

R4 100k | Q1 SI2301CDS

Q2
BC847B

R5 10k

R8 100k

PERIPH_EN (IO5)

+3V3_SW

U2 | MPU-6050 I2C 0x68 · 3,9 mA VDD / VLOGIC

GND · CLKIN, AD0 e FSYNC aterrados; AD0 = 0 fixa o endereço 0x68 do firmware

SDA

SCL

C4 100n

REGOUT

C5 100n

CPOUT

C6 2n2

R2 4k7 R3 4k7

R1 10k

C12 100n
RT1 NTC 10k B3950

U1 ESP32-S3-WROOM-1U-N16R8 16 MB flash · 8 MB PSRAM

IO5 PERIPH_EN

IO6 VBAT_SENSE

IO8 SDA

IO9 SCL

IO4 ADC1_CH3

EN

C11 100n

IO10 NSS

IO11 MOSI

IO12 SCK

IO13 MISO

IO14 DIO0

IO21 RST

TXD0

RXD0

IO0

3V3

GND — o pad térmico (41) leva 12 vias ao plano de baixo

C2 100n · C3 10u — desacoplamento do U1, na mesma face do módulo

C1 100n

R6 10k

R7 10k

U3 Ai-Thinker Ra-02 (SX1278)

433 MHz · 17 dBm

NSS

MOSI

SCK

MISO

DIO0

RESET

VDD

GND

u.FL

C7 100n · C8 10u

J2 | UART/BOOT gravação e console
+3V3 | TX | RX

EN

IO0

GPIO5 em nível alto liga o rail +3V3_SW pelo load switch Q2/Q1. Em nível baixo — ou com o pino solto, graças ao R8 — o rail cai a zero e leva junto o MPU6050, os pull-ups do I2C e o topo do divisor do NTC. Cortar só o retorno a GND não desligaria o sensor: os pull-ups continuariam em +3V3 e o alimentariam pelos diodos de ESD de SDA/SCL.

O rádio NÃO está no rail comutado: lora_sleep() por software é obrigatório (1,5 mA x 720 s = 1093 mA·s por ciclo).

Pinos, valores e conexões extraídos de hardware/gen_schematic.py e conferidos pino a pino na geração. Cruzamento sem ponto não é conexão.

Figura 1 – Circuito de condicionamento e aquisição. Os valores da figura são gerados diretamente a partir das constantes do firmware, com o arquivo e a linha de origem registrados no cabeçalho do gerador.

O limiar do detector é calibrado pelo quantil do escore sobre operação normal, com falso alarme alvo de 1 %. Os resultados desse treino não têm artefato versionado próprio — arquivo de resultados ou registro de execução —: estão registrados no histórico de alterações do repositório, e reproduzi-los exige executar o treino de novo.

A validação emprega partição por ensaio, e não por janela, em cinco partições com os arquivos de origem como grupos. A justificativa é o próprio resultado de vazamento apresentado na Seção 5.3: janelas do mesmo ensaio compartilham a assinatura da montagem, e dividi-las aleatoriamente mede a capacidade de identificar o ensaio, não a falha. Nos ensaios de rolamento, os resultados são adicionalmente estratificados pelo nível de massa de desbalanceamento sobreposta, porque o agregado confunde os dois efeitos.

## 4.3 Conversão normativa e estágio de decisão

A norma define as zonas de severidade em velocidade eficaz de banda larga, e o acelerômetro entrega aceleração (ISO/TC 108/SC 2, 2022). A conversão foi testada contra uma senoide cuja integral é conhecida analiticamente, comparando cinco variantes: integração no tempo com e sem filtro passa-alta, integração no domínio da frequência restrita à máscara normativa, e esta última e a integração no tempo sem filtro repetidas sob viés contínuo contido na especificação do sensor. O método correto está estabelecido na literatura (BRANDT; BRINCKER, 2014); o que

Capítulo 4. Desenvolvimento e métodos | 46

se mede aqui é o erro das alternativas sobre um valor de referência exato.

O estágio de decisão emprega detecção não supervisionada por Isolation Forest (LIU; TING; ZHOU, 2008), treinada exclusivamente com dados de operação normal — o cenário de uma máquina sem histórico rotulado. Três aspectos foram submetidos a variação controlada: a política de limiar, pela varredura do parâmetro de contaminação contra a fração de operação normal marcada; a métrica, pela comparação entre área sob a curva ROC global e área parcial restrita à região de falso alarme baixo (KOIZUMI et al., 2020); e o protocolo de validação, pela comparação entre partição aleatória por janela e partição por ensaio.

## 4.4 Projeto mecânico e térmico

O invólucro foi analisado a partir das cotas do desenho técnico, por fórmulas fechadas de resistência dos materiais. A rigidez do caminho de transmissão entre a superfície do motor e o sensor foi modelada como associação em série de três elos — a base como placa circular engastada com carga central, o ressalto de centragem em compressão axial e o corpo como viga tubular engastada:

kbase =

16πD

a

2

, | kres =

E A

L

, | kcorpo =

3E I

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
, | (4.3)

com D = E ℎ3
/[12(1 − ν

2
)] a rigidez flexional da placa e I = [ℓ

4 − (ℓ − 2t)

4
]/12 o momento
de inércia da seção tubular quadrada. A frequência de montagem e a transmissibilidade de base decorrem do modelo de um grau de liberdade.

A análise térmica considera o invólucro fechado em regime permanente, com o calor entrando pela carcaça do motor e o autoaquecimento do circuito como fonte interna. O caminho condutivo é modelado como resistência térmica em série, e o limite de operação é determinado pelo primeiro componente a atingir sua temperatura máxima admissível.

As condições de contorno são idealizadas: a rigidez real depende de pré-carga de parafusos, planicidade das faces impressas e orientação das camadas, e a análise térmica não modela resistência de contato, convecção forçada pelo ventilador do motor nem radiação de superfícies próximas.

## 4.5 Geração e verificação do hardware

Nenhum arquivo derivado é editado à mão. O esquemático, a placa e o sólido são gerados por script a partir de uma fonte única, e cada etapa tem verificação automática associada, conforme a Tabela 4.

Capítulo 4. Desenvolvimento e métodos | 47

Tabela 4 – Cadeia de geração do hardware e verificação automática de cada etapa.

Etapa | Saída | Verificação automática
Esquemático | .kicad_sch, netclasses | ERC com aviso tratado como erro
Placa | .kicad_pcb | DRC com zonas preenchidas; colisão
Sólido | .step da placa e do invólucro | modelo por footprint; interferência
Modal | frequências e formas | convergência de malha em três refinos
Térmica | campo e transiente | balanço fechado contra modelo concentrado
v1, superior | v1, inferior | v2, superior | v2, inferior
Figura 2 – Placas geradas nas duas versões. Contorno retangular com quatro recortes de canto para os apoios do invólucro; duas camadas, com plano de terra em ambas.

A regeneração a partir de diretório limpo reproduz os arquivos de esquemático, placa e símbolos byte a byte nas duas versões; o roteador é determinístico. Essa propriedade é o que torna a verificação significativa: um resultado que não se reproduz não distingue correção de coincidência.

As regras de fabricação adotadas são traço de 0,20 mm, folga de 0,15 mm e via de 0,60 mm com furo de 0,30 mm, contra mínimos declarados de 0,15 mm para traço e folga. Os defeitos de geração encontrados e corrigidos, bem como os que permanecem abertos, constam do Apêndice A.

## 4.6 Firmware e estado de implementação

O firmware é escrito em C++ para o ESP32-S3, com disciplina de sistemas críticos: caminhos não implementados devolvem um estado de erro explícito e propagam-no, em vez de retornar sucesso ou falha silenciosa. A justificativa dessa escolha e sua correspondência com a prática de sistemas de alta criticidade constam do Apêndice B.

Dois caminhos permanecem não implementados e são decisivos para a validade da medição em campo: a inicialização do acelerômetro — que inclui a conferência do registro de identidade, o fundo de escala, o divisor de taxa de amostragem e, decisivamente, a configuração do filtro passa-baixas interno abaixo de fs/2 — e o segundo caminho de aquisição. Enquanto o filtro não for configurado, o dispositivo opera na terceira cadeia da Seção 4.2, aquela em que todo conteúdo acima de 500 Hz dobra para dentro da banda de análise.

Capítulo 4. Desenvolvimento e métodos | 48

v1
v2
ESP32-S3 | Ra-02 | MPU6050
1 k | 10 k | 100 k | 1 M | 10 M | 100 M 1 k | 10 k | 100 k | 1 M | 10 M | 100 M 1 k | 10 k | 100 k | 1 M | 10 M | 100 M

0.01

0.10

1

10

frequência (Hz)

|Z| (Ω)

alvo 733 mΩ (66 mV / 90 mA); faixa cinza: acima de 50 MHz responde o encapsulamento, não a placa a Impedância do PDN vista do pino de alimentação

### 35.9 nH ↑

vias
pista
v1 | v2

C3
10u

C10
1u

C7
100n

C8
10u

C4
100n

C2
100n

C3
10u

C10
1u

C7
100n

C8
10u

C4
100n

C2
100n

0.0

2.5

5.0

7.5

10.0

L de laço (nH)

cada via passante custa 1,30 nH; a pista, 781 pH/mm. Eixo cortado em 10 nH b Composição da indutância de laço

pista = distância

C8 (v1) 3.2×

C3 (v1) 1.5×

C3 (v2) 1.6×
0

10

20

30

comprimento roteado (mm)

0 | 10 | 20 | 30
distância capacitor–pino (mm) a régua mede a reta; o laço vê a pista c Pista roteada × linha reta

Figura 3 – Rede de distribuição de alimentação: impedância vista do pino de cada carga, composição da indutância de laço e comprimento roteado contra distância em linha reta.
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

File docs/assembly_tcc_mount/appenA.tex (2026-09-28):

%%%%%%%%%%%%%%%%%%%%%%%%%%%%%%%%%%%%%%%%%%%%%%%%%%%%%%%%%%%%%%%%%%%%%%%%%%%%%%%
%% Apêndice A --- Registro de verificação do hardware
%%
%% Absorve o registro de engenharia do relatório de verificação de hardware:
%% correções no esquemático, defeitos de geração corrigidos e abertos, versões.
%% O material de PROJETO (cadeia de geração, placa, PDN) fica no Capítulo 3.
%%
%% PENDENTE DE TRANSCRIÇÃO: as tabelas completas de defeitos (itens 1--21) e de
%% comparação entre versões v1/v2 estão em docs/relatorio/verificacao-hardware.tex
%% e devem ser transportadas na íntegra. A estrutura abaixo é a do destino.
%%%%%%%%%%%%%%%%%%%%%%%%%%%%%%%%%%%%%%%%%%%%%%%%%%%%%%%%%%%%%%%%%%%%%%%%%%%%%%%

\chapter{Registro de verificação do hardware}
\label{ape:hardware}

Este apêndice reúne o registro de engenharia da cadeia de geração descrita na
Seção~\ref{sec:dev-hardware}. Ele é mantido no trabalho por uma razão de método: a
verificação só é informativa se os defeitos que ela encontrou forem publicados junto com os
que ela não encontrou.

Nenhum resultado aqui provém de bancada. Todos os valores são de geração, verificação
geométrica ou simulação, e o registro não reivindica validação experimental. Cada afirmação
tem associada a grandeza que a sustenta; itens sem medição associada aparecem como
\textsf{não verificado}.

\section{Correções no esquemático e defeitos corrigidos}
\label{sec:ape-corrigidos}

Os defeitos identificados e corrigidos durante a geração constam do relatório de
verificação com o valor antigo, o valor corrigido e a causa. Incluem, entre outros, erro de
referencial angular de \emph{pad} que produzia \num{42} curtos no DRC, e inversão de sinal
de rotação de \emph{footprint}.

\section{Defeitos abertos}
\label{sec:ape-abertos}

\emandamento{Os defeitos abaixo permanecem abertos e restringem afirmações específicas.}

\begin{itemize}
  \item \textbf{A placa não parafusa nos bosses do invólucro.} Na v1, o furo M3 exigiria
        material até \SI{28,2}{\milli\meter} na diagonal e o canto termina em
        \SI{27,5}{\milli\meter}; na v2, os recortes coincidem com os eixos dos bosses. A
        fixação passa a ser o assento pelo aro mais três furos M2 próprios.
  \item \textbf{Corredor do cabo.} Com \SI{6,0}{\milli\meter}, a v1 perde a saída de terra
        de dois componentes, com três itens soltos no DRC.
  \item \textbf{Altura do conjunto definida pelos conectores.} Decidir se o cabeçalho de
        gravação permanece populado no produto.
  \item \textbf{Divisor do NTC satura no frio}, atingindo \SI{3,22}{\volt} a
        \SI{-40}{\celsius}, acima da faixa útil do conversor. Abaixo de aproximadamente
        \SI{-35}{\celsius} os limiares de curto e de circuito aberto não disparam.
  \item \textbf{Numeração de pino do regulador varia por fabricante} ---
        \textsf{não verificado}; conferir contra a folha de dados antes de fabricar.
  \item \textbf{Furo de conector no invólucro sem conector correspondente} na netlist.
  \item \textbf{Rabicho de antena ausente da lista de materiais}; a ligação do conector
        do módulo de rádio ao painel não está especificada.
  \item \textbf{Nenhum código lê a tensão da bateria.} O caminho de hardware existe; os
        limiares do requisito de segurança correspondente não estão implementados.
\end{itemize}

\section{Limitações declaradas das análises}
\label{sec:ape-limitacoes}

A análise modal assume ASA isotrópico e maciço, hipótese otimista: a peça impressa com
preenchimento parcial é anisotrópica e menos rígida. O amortecimento do material não foi
medido, e sim herdado de análise anterior do projeto. As demais limitações constam da
Seção~\ref{sec:conc-alcance}.

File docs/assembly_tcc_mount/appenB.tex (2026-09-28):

%%%%%%%%%%%%%%%%%%%%%%%%%%%%%%%%%%%%%%%%%%%%%%%%%%%%%%%%%%%%%%%%%%%%%%%%%%%%%%%
%% Apêndice B --- Práticas de sistemas críticos
%%
%% Absorve o relatório de práticas de sistemas críticos. Justifica escolhas de
%% engenharia de firmware; não toca a tese sobre a cadeia de medição.
%%
%% PENDENTE DE TRANSCRIÇÃO: a tabela de mecanismos por setor, com as colunas
%% Limite conhecido e Situação no Kaelix, está em
%% docs/relatorio/praticas-sistemas-criticos.tex e deve ser transportada.
%%%%%%%%%%%%%%%%%%%%%%%%%%%%%%%%%%%%%%%%%%%%%%%%%%%%%%%%%%%%%%%%%%%%%%%%%%%%%%%

\chapter{Práticas de sistemas críticos aplicadas ao firmware}
\label{ape:praticas}

Este apêndice registra a origem documentada das práticas de engenharia adotadas no
firmware. A unidade de análise é o \emph{mecanismo}, e não a norma: uma norma aparece como
origem de vários mecanismos.

Duas ressalvas delimitam o alcance. Primeira: aviônica civil e automotivo entram como
origem documentada de prática, não como alvo de certificação --- o dispositivo é protótipo
acadêmico e nenhum processo de certificação é reivindicado. Segunda: para cada mecanismo
registra-se também o que ele comprovadamente \emph{não} cobre; sem essa coluna, o
levantamento viraria lista de recomendações.

\section{Escalas de criticidade}
\label{sec:ape-escalas}

Não há equivalência normativa entre as escalas setoriais, e a correspondência citada na
literatura é informal. A norma de aviônica classifica software pela severidade da condição
de falha e não atribui taxa de falha ao software \cite{do178c}; a norma genérica é a única
das três com faixa numérica direta de medida de falha alvo \cite{iec61508}; a automotiva
compõe severidade, exposição e controlabilidade \cite{iso26262}.

\section{Mecanismos adotados}
\label{sec:ape-mecanismos}

Os mecanismos concentram-se em disciplina de codificação, detecção de erro e definição de
estado seguro --- categorias cujo custo é de projeto, e não de replicação de hardware, e
que portanto são acessíveis a um protótipo de baixo custo.

O mecanismo com consequência mais direta sobre este trabalho é a propagação explícita de
estado não implementado. Um caminho ainda não escrito devolve erro e propaga-o até o
receptor, em vez de retornar sucesso ou falhar silenciosamente. A justificativa é a mesma
que a literatura de sistemas críticos oferece para a redundância diversa: falha silenciosa
é indistinguível de operação correta, e é essa indistinguibilidade que remove a evidência
de que algo está errado \cite{knight1986,esa1996}.

\section{Limite conhecido das práticas adotadas}
\label{sec:ape-limites}

A disciplina de codificação e a propagação de erro não substituem redundância de hardware,
e a literatura documenta que a suposição de independência entre versões diversas de
software não se sustenta empiricamente \cite{knight1986}. \emandamento{Nenhuma das práticas
adotadas foi exercitada em hardware real; sua eficácia é verificada apenas em teste no
\emph{host}.}

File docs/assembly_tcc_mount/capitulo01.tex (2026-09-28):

%%%%%%%%%%%%%%%%%%%%%%%%%%%%%%%%%%%%%%%%%%%%%%%%%%%%%%%%%%%%%%%%%%%%%%%%%%%%%%%
%% Capítulo 1 --- Introdução
%%
%% Citações: abntex2cite (sistema autor-data). \cite{} → (AUTOR, ano);
%%           \citeonline{} → Autor (ano).
%%
%% MARCAÇÃO DE TRECHO EM ANDAMENTO --------------------------------------------
%% \emandamento{...} destaca em vermelho os trechos cuja validade muda quando o
%% protótipo for construído e ensaiado em ambiente real. É marcação de rascunho.
%%
%% Para REMOVER todas as marcas na versão final, troque a definição abaixo por:
%%     \newcommand{\emandamento}[1]{#1}
%% ou apague as chamadas \emandamento{...} do texto.
%%%%%%%%%%%%%%%%%%%%%%%%%%%%%%%%%%%%%%%%%%%%%%%%%%%%%%%%%%%%%%%%%%%%%%%%%%%%%%%

\makeatletter
\@ifundefined{emandamento}{%
  \@ifundefined{textcolor}%
    {\newcommand{\emandamento}[1]{#1}}%
    {\newcommand{\emandamento}[1]{\textcolor{red}{#1}}}%
}{}
\makeatother

\chapter{Introdução}
\label{cap:introducao}

A manutenção preditiva de máquinas rotativas por análise de vibração é uma prática
normalizada. A norma ISO 20816-3:2022 estabelece faixas de severidade a partir da
velocidade eficaz de vibração de banda larga e define os limites que separam operação
aceitável de operação inaceitável para máquinas industriais acima de
\SI{15}{\kilo\watt}, com rotação entre \num{120} e \num{30000}~r/min. Para essa medição,
a norma exige do instrumento resposta plana em faixa de \emph{ao menos}
\SIrange{10}{1000}{\hertz}~\cite{iso208163_2022}. O procedimento é
consolidado, e o obstáculo à sua adoção não é metodológico: é de custo de instrumentação.
Acelerômetros piezoelétricos com a banda exigida para diagnóstico, seus condicionadores e
os analisadores associados restringem a cobertura aos ativos considerados críticos, e
deixam sem instrumentação a maior parte do parque de motores de uma planta.

A resposta que a literatura recente oferece a esse obstáculo é o nó sensor de baixo custo:
uma unidade de medição inercial MEMS acoplada a um microcontrolador de baixo consumo, com
detecção de anomalia executada no próprio dispositivo e enlace de rádio de longo alcance
para telemetria. A viabilidade computacional dessa arquitetura está estabelecida. O
algoritmo Isolation Forest~\cite{liu2008} treina e executa dentro de um
ESP32~\cite{antonini2023}, existem variantes desenhadas para reduzir seu custo em
TinyML~\cite{barbariol2022}, e a combinação de microcontrolador, acelerômetro MEMS de
consumo e detecção não supervisionada já foi demonstrada em manutenção preditiva de baixo
custo~\cite{kolok2025}. O que a viabilidade computacional não resolve --- e é o ponto de
partida deste trabalho --- é a questão anterior: o que uma cadeia de medição dessa classe
efetivamente permite medir.

Essa questão tem uma ordem de precedência que organiza todo o restante. Primeiro vem a
aquisição: piso de ruído, banda passante e caminho mecânico entre a fonte de vibração e o
elemento sensor. Nenhuma decisão posterior recupera informação que o sensor não coletou.
Depois vem a estimação, que decide o que se faz com a informação disponível: a política de
limiar, a métrica de desempenho e o protocolo de validação. Por último vem a implantação
--- energia, comportamento térmico e invólucro ---, que determina por quanto tempo o
dispositivo continua operando. Os três elos são encadeados, e um erro no primeiro não é
compensável nos seguintes.

É contra essa cadeia que se identifica a lacuna. A literatura de vibração embarcada é
forte no primeiro elo e frágil no segundo. Sobre aquisição, há consenso quantitativo:
nenhum estudo de adequação de sensor revisado testou dispositivo com limite superior
abaixo de \SI{1500}{\hertz}~\cite{albarbar2008}, e os grupos que se propõem a diagnosticar
defeito de rolamento com MEMS escolhem sensores de dezenas de
quilohertz~\cite{landi2023,jakobsen2024}, porque a assinatura do defeito viaja modulada em
uma portadora de alta frequência~\cite{randall2011,antoni2007}. Sobre estimação, ao
contrário, o registro é lacunar. O escore do Isolation Forest tem \num{0,5} como
referência interpretativa, e não como corte calibrado~\cite{liu2008}; a implementação de
referência transporta essa interpretação para um deslocamento fixo, sem alterar o
ranqueamento~\cite{scikitlearn2026}; e os trabalhos que reportam bom desempenho com o
detector abandonam o padrão sem que a política adotada seja submetida a
varredura~\cite{antonini2023,brito2022}. Não se localizou, entre os trabalhos que executam
o detector em microcontrolador, nenhum que variasse o parâmetro de contaminação sobre a
mesma base e reportasse a fração de operação normal marcada como anomalia, nem taxa de
falso alarme publicada para detector treinado no próprio dispositivo --- que é justamente
o modo de operação exigido de uma máquina sem histórico rotulado. Soma-se a isso uma
fragilidade de protocolo com efeito documentado: janelas consecutivas de um mesmo ensaio
compartilham a assinatura da montagem, e sua divisão aleatória entre treino e teste
permite que o modelo identifique o ensaio em vez da falha. \citeonline{varejao2025}
denominam o fenômeno \emph{similarity bias} e relatam que, de \num{41} estudos revisados
sobre uma base de referência consolidada, \num{40} adotaram delineamento suscetível a ele.

Este trabalho ocupa essa lacuna com uma tese delimitada. Uma cadeia de medição de baixo
custo, com banda e piso de ruído declarados, sustenta a detecção de desbalanceamento sob taxa de falso
alarme fixada, mas não sustenta
diagnóstico de defeito de rolamento; e a contribuição verificável de um dispositivo dessa
classe está no segundo elo da cadeia --- limiar calibrado por risco alvo, métrica avaliada
no ponto de operação e protocolo de validação sem vazamento entre ensaios ---, contribuição
que só é válida se o primeiro elo estiver declarado em vez de disfarçado. O objeto de
estudo é o Kaelix, um dispositivo que combina acelerômetro MPU6050, microcontrolador
ESP32-S3, enlace LoRa e invólucro em ASA impresso por deposição, com detecção de anomalia
embarcada e rotulagem de severidade pela norma.

A validade dessa tese depende de que se declare a procedência de cada resultado, e ela não
é uniforme. Os resultados de detecção por modo de falha provêm de dado real: sinais de uma
bancada instrumentada, adquiridos a \SI{50}{\kilo\hertz} e submetidos a decimação
controlada em \emph{software} para emular a banda do dispositivo. O que é modelado, nesse
caso, não é o sinal, é a aquisição. Os resultados sobre banda, integração, limiar, métrica e
protocolo de validação provêm de sinal sintetizado, cuja resposta correta é conhecida, e
sustentam relações entre métodos, não desempenho em máquina. Os resultados de análise
mecânica e térmica provêm de modelagem computacional sobre as especificações de projeto,
tomadas como dadas. \emandamento{E a cadeia física do próprio
dispositivo não foi verificada: nenhum ensaio físico foi conduzido e nenhuma medição de
campo alimenta os modelos, uma vez que a construção do protótipo e seu ensaio em ambiente
real constituem a etapa seguinte deste trabalho.} Essa distinção restringe uma afirmação
específica e é declarada aqui por isso: \emandamento{os resultados sustentam conclusões
sobre o que a cadeia de aquisição especificada permite medir, e não sobre o desempenho do
dispositivo montado em operação industrial.} As duas coisas serão mantidas separadas ao
longo do texto, e cada resultado indicará de qual das três origens provém.

\section{Objetivo}
\label{sec:objetivo}

\subsection{Objetivo geral}
\label{ssec:objetivo-geral}

Determinar o que a cadeia de medição de vibração especificada para o Kaelix permite medir,
e calibrar o estágio de decisão do detector embarcado de modo que o desempenho reportado
seja verificável no ponto de operação pretendido.

\subsection{Objetivos específicos}
\label{ssec:objetivo-especifico}

Dentro desse objetivo geral, encontram-se como metas específicas:

\begin{itemize}
    \item Quantificar a perda de contraste do indicador de defeito de rolamento entre a
          cadeia de referência e a cadeia truncada do dispositivo, e verificar se o
          delineamento permite atribuir essa perda à banda ou ao método de demodulação;

    \item Determinar o método de integração de aceleração para velocidade compatível com a
          norma, e quantificar o erro dos métodos alternativos contra um sinal cuja
          integral é conhecida analiticamente~\cite{brandt2014,iso208163_2022};

    \item Medir a taxa de falso alarme produzida pela política de limiar padrão do
          Isolation Forest e o efeito do parâmetro de contaminação sobre ela;

    \item Comparar o desempenho do detector sob divisão aleatória por janela e sob divisão
          por ensaio, e quantificar a inflação de acurácia atribuível ao vazamento de
          assinatura de montagem;

    \item Avaliar, por modelagem, a resposta modal e a margem térmica do conjunto
          invólucro-sensor-fixação, e identificar qual componente impõe o limite de
          operação;

    \item Declarar, para cada questão levantada, se ela foi respondida por medição, por
          modelagem ou se permanece dependente de ensaio físico.
\end{itemize}

\section{Metodologia}
\label{sec:metodologia}

A estratégia adotada é comum às questões investigadas: construir uma condição de
referência cujo resultado correto decorre de solução analítica ou de definição normativa,
submetê-la à cadeia de medição proposta e medir o desvio introduzido pela configuração do
projeto. Quando a resposta certa é conhecida de antemão, um erro de implementação não
consegue se esconder atrás de um resultado plausível.

O trabalho se desenvolve em quatro etapas. A primeira é a revisão da literatura,
organizada por eixos correspondentes aos elos da cadeia descrita, com verificação de cada
referência em fonte primária e registro explícito das lacunas encontradas, incluindo
aquelas que a própria verificação derrubou. A segunda é a caracterização da aquisição: um sinal
sintetizado com resposta conhecida é submetido à cadeia de referência e à cadeia truncada, e
os descritores extraídos são comparados entre elas; em paralelo, sinais de bancada
adquiridos em alta taxa são decimados de forma controlada para emular a banda do
dispositivo e medir a detecção por modo de falha.
A terceira é a calibração do estágio de decisão, na qual a política de limiar é avaliada
por varredura, o desempenho é reportado no ponto de operação de baixa taxa de falso alarme
e o protocolo de validação é submetido à divisão por ensaio. A quarta é a verificação de
implantação, por modelagem mecânica e térmica do conjunto montado a partir das
especificações de projeto.

Duas decisões metodológicas atravessam as quatro etapas. A primeira é a rastreabilidade:
cada resultado é acompanhado da indicação de sua origem --- sinal sintetizado, dado real
decimado ou modelagem sobre especificação --- e os artefatos que o produzem, dados
intermediários e código de geração, são mantidos versionados e regeneráveis. A exceção são
os resultados de treino sobre dado real, que não têm artefato versionado próprio e exigem
nova execução do treino para serem reproduzidos (Seção~\ref{sec:dev-sinal}). A
segunda é o registro do que não foi verificado. As questões levantadas que dependem de
ensaio físico ou de consulta regulatória são enunciadas, mantidas abertas e associadas à
afirmação cujo alcance elas restringem, em vez de omitidas. Esse registro é parte do
método, e não uma ressalva sobre ele.

\section{Estrutura do Trabalho}
\label{sec:estrutura}

Este trabalho está organizado em seis capítulos. O Capítulo~\ref{cap:introducao}
apresentou o contexto, a lacuna identificada, a tese defendida e a procedência dos
resultados que a sustentam. O Capítulo~\ref{cap:fundamentacao} apresenta os conceitos
em que o trabalho se apoia: vibração de máquinas rotativas e suas assinaturas de falha,
aquisição e processamento de sinais, avaliação normativa de severidade, detecção de
anomalias e sua avaliação, e as restrições de um dispositivo embarcado. O
Capítulo~\ref{cap:revisao} revisa a literatura por eixos, seguindo a ordem
de precedência da cadeia de medição, e consolida o que a literatura sustenta, o que ela
contesta e quais lacunas permanecem abertas. O Capítulo~\ref{cap:desenvolvimento} descreve o desenvolvimento do
dispositivo: a cadeia de aquisição, o detector embarcado, o projeto de hardware e a
arquitetura de comunicação e recepção. O Capítulo~\ref{cap:resultados} apresenta os resultados e os confronta
com a literatura revisada, organizado pela ordem de precedência da cadeia: primeiro o que
a aquisição permite medir, depois o que a estimação decide com a informação disponível e,
por fim, o que a implantação impõe como limite de operação. O Capítulo~\ref{cap:conclusoes}
reúne as conclusões, delimita seu alcance e enuncia o trabalho futuro decorrente das
questões mantidas em aberto.

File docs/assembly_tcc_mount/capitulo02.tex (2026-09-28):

%%%%%%%%%%%%%%%%%%%%%%%%%%%%%%%%%%%%%%%%%%%%%%%%%%%%%%%%%%%%%%%%%%%%%%%%%%%%%%%
%% Capítulo 2 --- Fundamentação e revisão da literatura
%%
%% Reordenado pela ordem de precedência da cadeia, na MESMA sequência do
%% Capítulo 4: aquisição -> normalização -> estimação -> implantação.
%% Os relatórios de origem organizavam a revisão por "eixos" numerados 1, 3, 4 e
%% 5, abrindo pelo detector. A ordem aqui é a da cadeia, para que o capítulo de
%% revisão e o de resultados possam ser lidos em paralelo.
%%
%% A ausência de um eixo na numeração original era deliberada e está declarada
%% na Seção 2.1: as referências que o sustentariam não passaram na verificação.
%%%%%%%%%%%%%%%%%%%%%%%%%%%%%%%%%%%%%%%%%%%%%%%%%%%%%%%%%%%%%%%%%%%%%%%%%%%%%%%

\makeatletter
\@ifundefined{toprule}{%
  \newcommand{\toprule}{\hline}%
  \newcommand{\midrule}{\hline}%
  \newcommand{\bottomrule}{\hline}%
}{}
\@ifundefined{emandamento}{%
  \@ifundefined{textcolor}%
    {\newcommand{\emandamento}[1]{#1}}%
    {\newcommand{\emandamento}[1]{\textcolor{red}{#1}}}%
}{}
\makeatother

\chapter{Trabalhos relacionados}
\label{cap:revisao}

\section{Método da revisão}
\label{sec:rev-metodo}

A revisão foi conduzida por confronto, e não por levantamento: cada seção parte de uma
escolha de projeto ou de um resultado obtido e pergunta o que a literatura publicada diz
sobre ele --- se o confirma, se o contradiz ou se nada diz.

Todas as referências foram conferidas em fonte primária: depósito do editor, texto integral
do artigo, amostra oficial da norma ou folha de dados do fabricante. Onde o texto integral
não pôde ser acessado, isso consta na própria referência, e o achado correspondente é
tratado como de menor peso. Essa verificação não é formalidade: duas auditorias sucessivas
encontraram defeito em parcela substancial das referências inicialmente levantadas ---
primeiro autor trocado, iniciais incorretas colapsando autores distintos, norma retirada
citada como vigente e, em três casos, achado atribuído a uma fonte que não o continha.

Um eixo temático levantado na fase inicial não integra esta revisão. Nenhuma das
referências que o sustentariam sobreviveu à verificação em fonte primária, e a decisão foi
não citar o que não foi conferido. O registro fica aqui porque uma revisão que apresenta
apenas os eixos sobreviventes esconde o método que os selecionou.

A organização segue a ordem de precedência da cadeia de medição, a mesma do
Capítulo~\ref{cap:resultados}: primeiro a aquisição, que decide que informação existe;
depois a normalização, que impõe requisitos sobre o instrumento e sobre a estimativa; em
seguida a estimação, que decide o que se faz com a informação disponível; por fim a
implantação, que decide por quanto tempo o dispositivo continua operando.

\section{Aquisição: banda, ruído e detectabilidade de defeito de rolamento}
\label{sec:rev-aquisicao}

A tensão que organiza esta literatura é única: as frequências que se deseja medir em um
rolamento são baixas, mas o mecanismo físico que as torna mensuráveis é alto. O defeito
produz impactos periódicos na frequência característica da geometria, na ordem de dezenas
a centenas de hertz, e esses impactos excitam ressonâncias estruturais de alguns
quilohertz. A assinatura diagnóstica viaja modulada nessa portadora de alta frequência, e é
por demodulação de envelope sobre a banda de ressonância que ela é recuperada
\cite{randall2011,antoni2006,antoni2007}. O procedimento padrão localiza a banda ótima pela
díade que maximiza a impulsividade do sinal filtrado \cite{antoni2007}; um dispositivo cuja
frequência de Nyquist é de \SI{500}{\hertz} não tem díade a escolher.

Os estudos de adequação de sensor convergem para o limite superior de banda como a variável
determinante, e nenhum testa dispositivo próximo da faixa do Kaelix. A comparação de três
acelerômetros MEMS capacitivos contra um piezoelétrico de referência reprovou o de banda
mais estreita, de \SI{1500}{\hertz}, para monitoramento de condição \cite{albarbar2008}.
Os grupos que se propõem a diagnosticar rolamento com MEMS escolhem sensores de dezenas de
quilohertz \cite{landi2023,sharma2024}, e uma implementação de baixo custo publicada
resolve o problema por projeto, reservando um acelerômetro de banda estreita para
desbalanceamento e outro de \SI{40}{\kilo\hertz} para rolamento \cite{jakobsen2024}. Os
produtos comerciais medem, ao menos em um eixo, uma ordem de grandeza acima do teto de uma
IMU de consumo \cite{bentlynevada2025,erbessd2025,tractian2022}.

Há uma segunda objeção, anterior à banda e independente dela: o piso de ruído. A densidade
de ruído declarada em folha de dados para uma IMU de consumo, integrada sobre a banda
normativa, situa o sensor acima do ruído admissível para resolver a fronteira entre as
zonas normativas mais baixas. A literatura de MEMS levanta, de forma convergente, a
ausência de calibração rastreável desses dispositivos \cite{albarbar2008,rodrigues2021},
e a avaliação de sensibilidade diagnóstica de sensores digitais de catálogo chega à mesma
leitura \cite{fidali2024}. \emandamento{O orçamento de ruído usualmente atribuído à
literatura de fabricante não pôde ser confirmado em fonte primária \cite{looney2017}, e
fechar essa conta com densidade medida, e não declarada, permanece pendente.}

Um efeito adicional é pouco documentado e afeta diretamente dispositivos de consumo: a
ausência de filtro anti-\emph{aliasing} configurado abaixo da frequência de Nyquist. Sem
ele, conteúdo espectral acima da banda dobra para dentro da faixa de análise e torna-se
indistinguível de sinal legítimo. Não se localizou, na literatura revisada por pares de
diagnóstico de rolamento, descrição experimental do efeito desse artefato sobre descritores
estatísticos como curtose e fator de crista; ele aparece apenas em notas de aplicação de
fabricante, não conferidas nesta revisão.

\section{Normalização: o que a norma exige do instrumento e da estimativa}
\label{sec:rev-norma}

A avaliação de severidade em velocidade eficaz não é convenção arbitrária de unidades, mas
escolha justificada no próprio texto normativo \cite{iso208163_2022}. A norma vigente
estabelece as zonas de severidade para máquinas acima de \SI{15}{\kilo\watt} com rotação
entre \num{120} e \num{30000}~r/min, e exige do instrumento resposta plana em faixa de
\emph{ao menos} \SIrange{10}{1000}{\hertz}, com limite inferior de até \SI{2}{\hertz} em
máquinas próximas ou abaixo de \num{600}~r/min.

A distinção entre requisito de instrumento e janela de análise é decisiva e frequentemente
perdida. A exigência de resposta plana recai sobre o instrumento; é isso que torna o
truncamento de banda uma violação de requisito, e não uma escolha de processamento
reversível. A edição anterior da norma delega esse ``plana'' a uma norma de instrumentação
que o torna verificável, com tolerância de banda passante de aproximadamente
\SI{10}{\percent} entre \SI{12,6}{\hertz} e \SI{1000}{\hertz} e limitação de banda por par
de Butterworth de terceira ordem \cite{iso2954_2012}.

\emandamento{A edição de 2009 foi retirada e substituída pela de 2022
\cite{iso108163_2009,iso208163_2022}. Os valores de zona são idênticos nas duas, de modo
que a substituição afeta a rastreabilidade da citação e não os números.} A edição anterior
é mantida na bibliografia por ser a que a prática industrial e parte da literatura ainda
adotam, e por ser nela que está a delegação explícita à norma de instrumentação.

A conversão de aceleração para velocidade é obrigação normativa, e é também um problema
numérico com solução conhecida. A integração no domínio do tempo acumula qualquer
componente contínua presente no sinal, e o erro resultante cresce sem limite; a integração
no domínio da frequência, restrita à máscara normativa, é o método estabelecido, e a
comparação quantitativa entre os dois está publicada \cite{brandt2014}. O que não se
localizou publicado é a aplicação desse método ao indicador da norma em um dispositivo
truncado --- isto é, quanto um instrumento limitado a \SI{500}{\hertz} subestima o
indicador normativo frente à banda exigida.

\section{Estimação: detector, limiar, métrica e protocolo}
\label{sec:rev-estimacao}

Esta literatura desloca a pergunta de engenharia, mas o deslocamento é condicional, e a
condição precisa ficar à vista: \emph{dada banda de medição suficiente}, o que decide o
desempenho não é qual detector se escolhe, e sim como o limiar é calibrado, com que métrica
o resultado é lido e quanto do orçamento do microcontrolador o modelo consome. Sem banda,
nada disso importa --- nenhum corte de escore transforma contraste ausente em detecção.

\subsection{A escolha do detector não tem consenso}

Dois comparativos de grande porte discordam, e a discordância é informativa porque medem
coisas diferentes. O maior em cobertura de paradigmas avalia \num{30} algoritmos sobre
\num{57} conjuntos de dados e conclui que \emph{nenhum} método não supervisionado é
estatisticamente superior aos demais \cite{han2022}. A maior comparação restrita a métodos
não supervisionados, com \num{33} algoritmos sobre \num{52} conjuntos tabulares reais,
encontra vantagem para o Extended Isolation Forest, com a ressalva de que os dados se
separam em dois regimes \cite{bouman2024}. Não há contradição, e sim escopos distintos ---
mas há consequência: a evidência disponível recomenda uma variante que este trabalho não
adota.

A razão para permanecer no algoritmo canônico \cite{liu2008} é de custo de implementação
embarcada, e é verificável em estrutura: um nó da variante estendida armazena um vetor
normal com tantas componentes quantos forem os descritores, e a inferência passa de uma
comparação para um produto interno por nó. \emandamento{É argumento de projeto, e não
resultado de literatura; enquanto o orçamento embarcado não for medido no dispositivo, a
escolha permanece limitação de escopo declarada, não conclusão.}

O suporte específico para máquinas rotativas é, em contrapartida, o melhor que o algoritmo
canônico tem: entre \num{11} detectores não supervisionados, atinge F1 de \num{97,19} em
rolamento \emph{run-to-failure} e \num{97,20} em faltas mecânicas de bancada
\cite{brito2022}. Os dois primeiros conjuntos são adquiridos a \SI{20}{\kilo\hertz}, banda
que uma IMU de consumo não possui.

\subsection{O limiar padrão não é calibração}

No artigo fundador, o escore tem \num{0,5} como \emph{referência interpretativa}, e a
robustez demonstrada está nos parâmetros do \emph{ensemble}, não no corte \cite{liu2008}.
A implementação de referência explicita o mecanismo: o parâmetro de contaminação redefine
apenas um deslocamento fixo, nunca o escore subjacente \cite{scikitlearn2026}. Seguem daí
duas consequências mecânicas: o corte padrão é herdado de uma interpretação, e não estimado
nos dados; e toda métrica de ranqueamento, área sob a curva ROC inclusive, é invariante ao
parâmetro.

Os trabalhos que reportam bom desempenho abandonam o padrão --- fixando o escore
normalizado em \num{0,75} sob hipótese de treino limpo \cite{antonini2023}, ou derivando o
corte da razão de contaminação conhecida \cite{brito2022}. A alternativa principiada
dispensa hipótese sobre a distribuição do corpo dos dados e fixa o limiar a partir de um
risco alvo, que controla diretamente o número de falsos positivos \cite{siffer2017}.

O problema não é teórico. As duas implementações do mesmo detector em nó embarcado que
reportam falso alarme, ou permitem derivá-lo, situam-se entre \num{22} e
\SI{38}{\percent} sobre operação normal \cite{chevtchenko2023,kolok2025}. Um dispositivo que marca um terço da operação
normal como anomalia não é utilizável em manutenção.

\subsection{A métrica e o protocolo de validação}

A área sob a curva ROC global não caracteriza o ponto de operação de um dispositivo de
campo, que precisa operar em falso alarme baixo. O benchmark de referência para o mesmo
regime de treino reporta área parcial restrita a essa faixa \cite{koizumi2020}, e a mesma
disciplina aparece em quem reporta PR-AUC além do F1 \cite{brito2022}.

Sobre o protocolo, a objeção é a mais séria, e sua identificação não é contribuição deste
trabalho: ela está publicada.
Janelas consecutivas de um mesmo ensaio compartilham a assinatura da montagem, e sua
divisão aleatória entre treino e teste permite que o modelo identifique o ensaio em vez da
falha. O fenômeno tem nome e quantificação: de \num{41} estudos revisados sobre uma base de
referência consolidada, \num{40} adotaram delineamento suscetível a ele \cite{varejao2025},
e a inflação medida por vazamento é da ordem de dezenas de pontos percentuais
\cite{vieira2026}. Trabalhos que revisam abordagens de classificação de falha de rolamento
chegam a leitura convergente \cite{abburi2023,smith2015}.

\section{Implantação: nós comparáveis, invólucro e energia}
\label{sec:rev-implantacao}

A literatura de nós sem fio para manutenção preditiva divide-se em duas populações que
raramente se citam. De um lado, produtos comerciais, com banda uma ordem de grandeza acima
da de uma IMU de consumo, caminho mecânico rígido até o elemento sensor e alimentação por
célula primária \cite{bentlynevada2025,erbessd2025,tractian2022}. De outro, nós acadêmicos
de baixo custo, que convergem para a mesma arquitetura estudada aqui: microcontrolador de
baixo consumo, IMU MEMS na ordem de \SI{1}{\kilo\hertz} e detecção não supervisionada
\cite{kolok2025,antonini2023,bisio2025}.

\subsection{O que a literatura de nós de baixo custo autoriza concluir}

O análogo mais próximo em hardware e em modo de falha reporta acurácia de
\SI{72,9}{\percent} $\pm$~\SI{2,4}{\percent}, com validação cruzada de cinco dobras sobre
cerca de \num{900} amostras e \emph{um único} modo de falha \cite{kolok2025}. O dado valida
a arquitetura como publicável. O que ele não faz é fixar teto de desempenho da classe: a
amostra é de um estudo único com um modo de falha, e o trabalho encerra em valor eficaz de
aceleração, sem integração para velocidade e sem critério normativo.

A comparação mais direta é embarcada e mede três detectores no mesmo nó e no mesmo
conjunto \cite{chevtchenko2023}. No mesmo hardware e no mesmo dado, um método baseado em
vizinhança domina o algoritmo adotado aqui tanto em especificidade quanto em latência,
sendo cerca de \num{26} vezes mais rápido. \emandamento{A resposta declarada é de custo de
memória --- o método de vizinhança exige manter o conjunto de referência, enquanto a
floresta armazena apenas limiares e índices --- mas o orçamento embarcado ainda não foi
medido, e a permanência no detector adotado é hipótese de projeto, não conclusão.}

O mesmo trabalho traz um achado que é restrição de implantação, e não detalhe: um motor com
cerca de um ano de uso tem assinatura normal distinta da de motores novos
\cite{chevtchenko2023}. Um modelo único com limiar fixo herda essa deriva do que conta como
normal entre máquinas e ao longo da vida --- cenário em que a calibração por risco alvo
deixa de ser refinamento e passa a ser requisito.

A viabilidade computacional, em contrapartida, está estabelecida: o detector treina e
executa dentro de um microcontrolador da classe \cite{antonini2023}, existe variante
desenhada para reduzir seu custo em TinyML \cite{barbariol2022}, e dispositivos da mesma
família comportam \emph{pipelines} consideravelmente mais caros \cite{uselis2025,kumar2026}.

\subsection{Invólucro e caminho mecânico}
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

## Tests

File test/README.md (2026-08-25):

Testes unitários (PlatformIO + Unity, ambiente `native`) da lógica pura em
`lib/`, que não depende de hardware: `signal_processing` (RMS, curtose,
fator de crista, frequência dominante), `thermistor` (ADC/mV → resistência
→ °C), `isolation_forest` (c(n), caminho de árvore, score) e `crc16`
(integridade do pacote LoRa).

Rodar com: `pio test -e native` — 26 testes.

Os testes do pipeline Python de treino ficam em `training/tests/`
(`python -m pytest tests/`).

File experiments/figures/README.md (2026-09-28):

# Figuras — Kaelix

Figuras em padrão de submissão para os questionamentos técnicos do projeto.
Computação em Python, plotagem em R.

## Pipeline

```
notebooks/*.ipynb          validação numérica (fonte da verdade)
                 │
                 ▼
experiments/figures/scripts/export_*.py            reproduz a computação → CSV
                 │
                 ▼
figures/data/*.csv                     dados-fonte, rastreáveis
                 │
                 ▼
experiments/figures/scripts/fig*.R                 ggplot2 + patchwork
                 │
                 ▼
figures/output/*.{svg,pdf,tiff,png}    SVG/PDF vetoriais, TIFF 600 dpi
```

| Fonte da verdade | Exportador | Figura |
|---|---|---|
| `validacao-questionamentos.ipynb` | `export_source_data.py` | 1, 2 |
| `analise-involucro.ipynb` | `export_enclosure_data.py` | 3 |
| `analise-termica.ipynb` | `export_thermal_data.py` | 4 |
| cálculo no próprio exportador | `export_topologia_data.py` | 5 |
| **módulo `experiments/gateway/`** | `export_gateway_data.py` | 7 |
| esquema, sem dado numérico | — | 6 |
| **firmware** (`src/`, `lib/`) | — (desenho direto) | 8 |

**Figura 8 é a exceção do pipeline.** Um esquemático não tem CSV: os valores
*são* o desenho. `fig8_circuito.py` gera SVG diretamente, com coordenadas
absolutas, e cada constante traz no cabeçalho o arquivo e a linha do firmware de
onde saiu (pinos, R_FIXED, correntes). Não usa R nem biblioteca de esquemático —
`schemdraw` foi tentada e descartada: o posicionamento relativo dela fazia o
rótulo do CI disputar espaço com os nomes dos pinos.

**Nota sobre a fonte da verdade das figuras 5 e 7.** As figuras 1 a 4 têm a
computação no notebook e reproduzida no exportador — duas cópias que podem
divergir em silêncio, e o `simulate()` está de fato duplicado hoje. As figuras 5
e 7 não repetem esse arranjo: a 5 calcula no próprio exportador, e a 7 **importa
`gateway/kaelix_gateway`**, rodando o mesmo código que os 19 testes exercitam. O
exportador é adaptador para CSV, não segunda implementação.

**Divisão de responsabilidade.** A cadeia numérica (FFT, Hilbert, `butter`/`sosfiltfilt`,
`decimate`, Isolation Forest, `GroupKFold`) permanece em SciPy/scikit-learn, onde foi
validada. R cuida da camada gráfica, onde ggplot2 dá controle tipográfico superior.
Reimplementar o processamento de sinal em R exigiria revalidar tudo e arriscaria alterar
resultados já verificados.

## Reproduzir

```bash
uv run python experiments/figures/scripts/export_source_data.py      # CSVs das figuras 1 e 2
uv run python experiments/figures/scripts/export_enclosure_data.py   # CSVs da figura 3
uv run python experiments/figures/scripts/export_thermal_data.py     # CSVs da figura 4

Rscript experiments/figures/scripts/fig1_banda_sensor.R              # figura 1
Rscript experiments/figures/scripts/fig2_metodologia.R               # figura 2
Rscript experiments/figures/scripts/fig3_involucro.R                 # figura 3
Rscript experiments/figures/scripts/fig4_termica.R                   # figura 4

uv run python experiments/figures/scripts/export_topologia_data.py   # CSVs da figura 5
uv run python experiments/figures/scripts/export_gateway_data.py     # CSVs da figura 7

Rscript experiments/figures/scripts/fig5_topologia.R                 # figura 5
Rscript experiments/figures/scripts/fig6_cadeia.R                    # figura 6 (sem CSV)
Rscript experiments/figures/scripts/fig7_gateway.R                   # figura 7
```

Dependências R: `ggplot2`, `patchwork`, `dplyr`, `readr`, `scales`, `tidyr`,
`svglite`, `ragg`, `systemfonts`.

---

## Figura 6 — Cadeia completa do sistema

**Conclusão.** Do motor ao manutentor são dez elos; o diagrama mostra o estado de
implementação de cada um, e as fronteiras do ESP32-S3 não coincidem com a quebra
de linha.

**Arquétipo.** Esquema de fluxo, sem dado numérico. 183 × 96 mm.

**Legenda proposta.**

> **Fig. 6 | Cadeia do sistema proposto e estado de cada elo.** Fluxo do motor ao
> manutentor. Cor indica o estado: implementado e testado no host; existente mas
> exercitado apenas em simulação; inexistente; ou bloqueado pela ausência de
> hardware. Linhas tracejadas verticais marcam onde começa e termina o ESP32-S3.
> "Testado" refere-se a verificação no host: nenhum elo desta cadeia foi
> exercitado com rádio ou sensor reais.

## Figura 7 — Cadeia de comunicação exercitada por simulação

**Conclusão.** O deslocamento anticolisão por `device_id` não é otimização: sem
ele, dispositivos energizados juntos perdem **todos** os quadros, em qualquer
quantidade de nós.

**Arquétipo.** Grade quantitativa com painel-herói (a). 183 × 118 mm.

**Legenda proposta.**

> **Fig. 7 | Cadeia de comunicação sob simulação de meio.** **a**, Fração de
> quadros perdidos por colisão contra número de dispositivos energizados
> simultaneamente, com e sem o deslocamento derivado de `device_id`. Sem
> deslocamento a colisão não é probabilística: os nós transmitem no mesmo
> instante a cada ciclo e a perda é total. **b**, Funil de 24 h para 20
> dispositivos, com 2% de perda e 1% de corrupção injetados no meio; as duas
> primeiras barras coincidem porque o deslocamento eliminou a colisão neste
> cenário. **c**, Alerta por dispositivo: a regra de anomalias consecutivas
> dispara nos dois nós com anomalia sustentada e em nenhum dos dezoito com
> anomalia esporádica de 2%. **d**, Perda e corrupção injetadas contra o que o
> gateway reconstrói; a corrupção é integralmente detectada pelo CRC-16, e a
> perda aparece como lacuna na sequência de `boot_count`. A simulação cobre
> colisão, perda e corrupção de bit; **não** cobre propagação — alcance e margem
> de enlace dependem de medição em campo.

**Dados.** `fig7a_jitter.csv`, `fig7b_funil.csv`, `fig7c_alertas.csv`,
`fig7d_deteccao.csv`, gerados por `export_gateway_data.py`, que importa o módulo
`experiments/gateway/`.

## Figura 5 — Comparação de arquiteturas topológicas

**Conclusão.** O enlace decide autonomia tanto quanto decide alcance, e a
topologia atual não tem receptor: das quatro arquiteturas, três diferem apenas
no que fica do lado do gateway, e a escolha entre elas é de escopo, não de
viabilidade técnica.

**Arquétipo.** Composto liderado por esquema, com painel-herói (a). 183 × 168 mm.

**Legenda proposta.**

> **Fig. 5 | Arquiteturas topológicas de rede para o Kaelix.** **a**, Quatro
> arranjos comparados. A, estado atual: os nós transmitem e não há receptor
> implementado. B–D diferem no elemento que recebe — gateway ESP32 de canal
> único, computador de placa única com armazenamento e publicação, e
> concentrador LoRaWAN multicanal com downlink classe A. Linha tracejada,
> enlace de rádio; linha contínua, backhaul com fio. **b**, Autonomia do nó
> contra ganho de enlace, por fator de espalhamento; alcance e autonomia são o
> mesmo parâmetro, e SF9 é a escolha atual. **c**, Probabilidade de colisão em
> ALOHA puro contra número de dispositivos por gateway; o cálculo pressupõe
> fases de transmissão descorrelacionadas. **d**, Autonomia do nó por
> tecnologia de enlace. Todos os valores derivam do orçamento de energia do
> dispositivo (bateria LiPo de 2000 mA h, ciclo de 10 min, pacote de 20 bytes)
> e do tempo no ar calculado pela formulação do SX127x; nenhum vem de medição
> em hardware.

**Dados.** `fig5b_sf_tradeoff.csv`, `fig5c_colisao.csv`, `fig5d_enlace.csv`,
gerados por `scripts/export_topologia_data.py`.

## Figura 1 — Limite de banda do sensor

**Conclusão.** A banda de 500 Hz do MPU6050 preserva a taxa de repetição do defeito
(BPFO, 105 Hz) mas descarta a ressonância de 3,5 kHz que a carrega, reduzindo o
contraste diagnóstico de 413× para 20× e anulando curtose e fator de crista.

**Arquétipo.** Grade quantitativa com painel-herói (a). 183 × 110 mm.

| Painel | Evidência | Dados |
|---|---|---|
| a | PSD comparada, sadio vs. defeito, com a banda do sensor destacada | `fig1a_espectro.csv` |
| b | Contraste em BPFO: envelope (20 kHz) vs. espectro direto (1 kHz) | `fig1b_contraste.csv` |
| c | Curtose e fator de crista por cadeia de aquisição | `fig1c_features.csv` |
| d | Frequência aparente da ressonância sob aliasing | `fig1d_aliasing.csv` |

**Legenda proposta.**

> **Fig. 1 | O limite de banda do MPU6050 descarta a evidência de defeito de rolamento.**
> **a**, Densidade espectral de potência de vibração simulada para rolamento sadio (azul)
> e com defeito de pista externa (vermelho), amostrada a 20 kHz. A faixa sombreada marca
> a banda acessível ao MPU6050 (≤ 500 Hz, Nyquist para ODR de 1 kHz). Os impactos
> periódicos excitam uma ressonância estrutural em 3,5 kHz, inteiramente fora dessa
> banda. **b**, Razão entre a amplitude em BPFO (104,6 Hz) nas condições com e sem
> defeito. A análise de envelope sobre a banda de ressonância (2–6 kHz), disponível
> apenas a 20 kHz, entrega contraste 21× maior que o espectro direto na banda do
> MPU6050. **c**, Curtose e fator de crista, indicadores clássicos de impacto, para as
> três cadeias de aquisição. Com antialiasing correto (MPU c/ AA) as duas condições
> tornam-se indistinguíveis (curtose 1,76 vs. 1,77). Sem antialiasing (s/ AA) as
> descritores aparentam discriminar, mas o conteúdo espectral é artefato. **d**, Frequência
> aparente da ressonância após subamostragem a 1 kHz sem filtro antialiasing; a energia
> real de 3–5 kHz reaparece em frequências onde nada existe fisicamente.
> Sinais sintéticos, motor de 1750 rpm, rolamento SKF 6205. Fonte: `figures/data/`.

---

## Figura 2 — Escolhas metodológicas

**Conclusão.** Integração no domínio errado, split que vaza assinatura de ensaio e
limiar herdado do default produzem erros de 73–716%, 36 pontos de acurácia aparente e
42% de falso alarme.

**Arquétipo.** Grade quantitativa, três blocos independentes. 183 × 112 mm.

| Painel | Evidência | Dados |
|---|---|---|
| a | Erro de cada método de integração contra o valor analítico | `fig2a_integracao.csv` |
| b | Deriva temporal causada por bias de 0,02 m/s² | `fig2b_deriva.csv` |
| c | Acurácia por estratégia de split | `fig2c_split.csv`, `fig2c_folds.csv` |
| d | Falso alarme por valor de `contamination` | `fig2d_contamination.csv` |
| e | ROC do Isolation Forest por banda de aquisição | `fig2e_roc.csv` |

**Legenda proposta.**

> **Fig. 2 | Três escolhas metodológicas alteram os resultados mais do que o efeito
> medido.** **a**, Velocidade RMS obtida por cinco variantes de integração aplicadas a
> uma senoide de 3,0 m/s² a 50 Hz, cuja integral é conhecida analiticamente
> (6,75 mm/s, linha tracejada). Só a integração no domínio da frequência, com a banda de
> 10–1000 Hz da ISO 10816-3, recupera o valor exato; ela permanece exata sob bias porque
> o termo DC cai fora da máscara. **b**, Velocidade instantânea sob bias de 0,02 m/s²,
> dentro da especificação do MPU6050. A integração no tempo acumula deriva linear e
> atinge 55 mm/s de RMS contra os 6,75 mm/s corretos. A modulação do traço azul é a
> janela de Hann, compensada no cálculo do RMS. **c**, Acurácia de um Random Forest sobre
> as mesmos descritores e os mesmos dados, variando apenas a estratégia de divisão.
> Barras: média; erro: desvio-padrão entre repetições (n = 10 seeds) ou folds (n = 5);
> pontos: folds individuais do split por ensaio. **d**, Fração de janelas de operação
> normal classificadas como anomalia, por valor de `contamination`, treinando apenas com
> dados normais. A detecção foi de 100% em todos os casos: o parâmetro desloca o limiar,
> não a qualidade (AUC = 1,000). **e**, Curvas ROC do Isolation Forest para defeito
> incipiente. A faixa sombreada marca a região de operação realista; ali a perda do
> MPU6050 é maior do que o AUC sugere.
> Sinais sintéticos. Fonte: `figures/data/`.

---

## Figura 3 — Invólucro

**Conclusão.** O caminho elástico motor→base→ressalto de centragem→corpo→sensor coloca a frequência de
montagem em 557 Hz, dentro da banda de medição, com erro de amplitude acima de 10% a
partir de 168 Hz — enquanto fixação magnética e modos de placa não são problema.

**Arquétipo.** Grade quantitativa com painel-herói (a). 183 × 125 mm.

| Painel | Evidência | Dados |
|---|---|---|
| a | Transmissibilidade por material, com as bandas destacadas | `fig3d_transmissibilidade.csv` |
| b | Erro de amplitude dentro da banda do sensor | `fig3e_erro.csv` |
| c | Fração da flexibilidade por elo do caminho | `fig3c_rigidez.csv` |
| d | Força de retenção vs. diâmetro da carcaça (hipótese descartada) | `fig3a_fixacao.csv`, `fig3a_margem.csv` |
| e | Modos fundamentais dos painéis (hipótese descartada) | `fig3b_modos.csv` |

**Legenda proposta.**

> **Fig. 3 | O invólucro em ASA filtra o sinal antes que ele chegue ao sensor.**
> **a**, Transmissibilidade de base do conjunto invólucro–sensor, modelado como sistema
> massa–mola de um grau de liberdade ($m$ = 118 g, $\zeta$ = 0,03), para a mesma
> geometria em três materiais. A rigidez de cada elo vem de fórmulas fechadas aplicadas
> às cotas do desenho. Em ASA a frequência de montagem cai em 557 Hz, dentro da banda de
> medição; em alumínio e aço ela sai da faixa e a resposta permanece plana.
> **b**, Erro de amplitude correspondente dentro da banda do MPU6050. O erro ultrapassa
> 10% a partir de 168 Hz e cresce até a ressonância; por variar com a frequência, não é
> corrigível por ganho fixo. **c**, Decomposição da flexibilidade total ($1/k$) por elo:
> base e corpo respondem por 99,6%, enquanto o ressalto de centragem é irrelevante — consequência da
> associação em série, em que o elo mais flexível domina. **d**, Força de retenção dos
> quatro ímãs Ø10×3 sobre carcaças cilíndricas de diferentes diâmetros, considerando o
> entreferro causado pela curvatura; a linha tracejada marca a força inercial a 18 g,
> equivalente a 28 mm/s RMS a 1 kHz. **e**, Modo fundamental dos painéis do invólucro;
> a barra cobre o intervalo entre as condições de contorno simplesmente apoiada e
> engastada. Todos os modos ficam acima da banda da ISO 10816-3.
> Estimativas analíticas a partir das cotas do desenho. Fonte: `figures/data/`.

**Nota de método.** Fórmulas fechadas com condições de contorno idealizadas: placa
circular engastada para a base, compressão axial para o ressalto de centragem, viga tubular engastada
para o corpo. A rigidez real depende de pré-carga dos parafusos, planicidade das faces
impressas, orientação de camadas e comportamento do inserto térmico. O módulo do ASA
impresso é anisotrópico e cai com a temperatura. Os valores são ordem de grandeza; a
conclusão qualitativa é robusta à variação testada (base de 4 a 12 mm mantém $f_n$
dentro da banda), o número exato não.

---

## Figura 4 — Análise térmica

**Conclusão.** Por ser mau condutor, o ASA mantém o interior a 44,8 °C com carcaça a
80 °C, enquanto o alumínio entregaria 79,0 °C. O limitante não é o invólucro nem o ímã,
mas o limite de carga da LiPo (45 °C) — e a base metálica que o item 8 pede exige quebra
térmica para não violá-lo.

**Arquétipo.** Grade quantitativa com painel-herói (a). 183 × 115 mm.

| Painel | Evidência | Dados |
|---|---|---|
| a | Temperatura interna vs. carcaça, por configuração de base | `fig4a_temperatura.csv` |
| b | Limite térmico por componente, colorido pela margem | `fig4b_limites.csv` |
| c | Trade-off rigidez × temperatura entre os itens 4 e 8 | `fig4c_tradeoff.csv` |
| d | Efeito da espessura da quebra térmica | `fig4d_isolador.csv` |

**Legenda proposta.**

> **Fig. 4 | O ASA protege a eletrônica; a bateria é o elo térmico mais fraco.**
> **a**, Temperatura interna em regime permanente em função da temperatura da carcaça,
> para três configurações de base. O modelo de parâmetros concentrados considera condução
> pelo caminho sólido (base e ressalto de centragem), convecção natural e radiação para um ambiente a
> 30 °C. A resistência do caminho em ASA é de 88,8 K/W contra 0,074 K/W em alumínio, uma
> razão de 1206×: o plástico isola e o metal conduz. **b**, Limite térmico de cada
> componente, comparado à temperatura interna com carcaça a 80 °C (linha vertical). A cor
> indica a margem — crítica (< 5 °C), estreita (< 40 °C) ou confortável. O limite de
> carga da bateria é o único abaixo da temperatura de operação. **c**, As duas análises
> impõem requisitos opostos à base: o item 8 pede rigidez (metal) para tirar a frequência
> de montagem da banda de medição, e a térmica pede isolamento (plástico). Nenhuma das
> três configurações alcança simultaneamente a região desejável. **d**, Temperatura
> interna com base de alumínio em função da espessura do espaçador isolante. Meio
> milímetro recupera a maior parte do isolamento, porque a resistência em série é
> dominada pelo elo de menor condutividade.
> Estimativas analíticas a partir das cotas do desenho. Fonte: `figures/data/`.

**Nota de método.** Regime permanente, parâmetros concentrados, caminho condutivo
idealizado como a seção do ressalto de centragem. Não modela resistência de contato entre base e
carcaça, convecção forçada pelo ventilador do motor (que ajudaria) nem radiação recebida
de superfícies quentes próximas (que prejudicaria). A temperatura de carcaça dos
equipamentos da Skala continua não medida — é o dado que fecha a análise.

---

## Notas de QA

Verificado contra o checklist de pré-submissão:

| Item | Situação |
|---|---|
| Largura | 183 mm (dupla coluna) |
| Tipografia | Arial, base 6,5 pt; eixos 6,0 pt; tags 8 pt em negrito |
| Texto editável | SVG com 99, 91, 83 e 88 elementos `<text>`; nenhum glifo convertido em curva |
| Vetorial | SVG e PDF vetoriais; TIFF LZW a 600 dpi como raster |
| Cor | Sem mapa arco-íris; azul = correto/referência, vermelho = erro/perda, consistente nas quatro figuras |
| Escala de cinza | Verificado por conversão nas quatro figuras. Vermelho escurecido para #8C2D1E; curvas sobrepostas recebem `linetype` distinto (ROC do MPU6050; aço na Fig. 3; mitigação na Fig. 4), garantindo separação por luminância e por padrão |
| Legendas | Diretas ou internas; nenhuma legenda redundante repetida |
| Dados-fonte | Todo painel quantitativo rastreável a um CSV em `figures/data/` |

**Estatística dos painéis de modelo (Fig. 2c–e).**

```
split treino/teste : aleatório por janela (vazamento) vs. GroupKFold por ensaio
seeds / folds      : 10 seeds (split aleatório); 5 folds (GroupKFold)
métrica            : acurácia (c); taxa de falso alarme e detecção (d); ROC/AUC (e)
variabilidade      : desvio-padrão entre seeds ou folds
baseline           : classe majoritária (0,50), marcada em c
treino do IF       : apenas janelas de operação normal
```

**Limitação.** Os sinais são sintéticos, com física conhecida. As figuras validam a
cadeia de processamento e dimensionam ordens de grandeza; não substituem MAFAULDA/CWRU
nem medição em campo. Os valores absolutos dependem dos parâmetros de simulação
(amplitude do defeito, frequência de ressonância, nível de ruído).

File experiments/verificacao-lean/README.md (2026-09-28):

# Verificação formal dos cálculos do TCC — Lean 4

Este projeto reproduz, em Lean 4, os cálculos de forma fechada que sustentam os
resultados de procedência **E** (modelagem sobre especificação) e o valor de
referência analítico da Tabela 4.2 do TCC. São **76 teoremas**, todos fechados
por avaliação no núcleo (*kernel*) do Lean, sem `sorry` e sem depender de
nenhum axioma — nem `Classical.choice`, nem `propext`, nem `Quot.sound`. O
arquivo `Kaelix/Auditoria.lean` registra isso por escrito na saída da
compilação.

## O que isto verifica, e o que não verifica

**Verifica:** que os números relatados decorrem, por aritmética exata, das
fórmulas declaradas no Capítulo 3 e dos parâmetros declarados no desenho, no
firmware e nas tabelas de material.

**Não verifica:** que os modelos descrevam o dispositivo real. Nenhum ensaio
físico alimenta nada aqui, e as condições de contorno idealizadas continuam
sendo as declaradas em §3.4. Resultado de procedência **S** (sinal
sintetizado) e **M** (dado real decimado) está fora do alcance do método: são
saídas de simulação e de treinamento, não consequências de fórmula fechada.
Onde o TCC relata um número dessa origem, este projeto ou fica em silêncio ou
verifica a conta que o *explica* — e diz qual das duas coisas está fazendo.

## Como rodar

Não há dependências externas, nem mesmo Mathlib; só o compilador. Nada é
baixado.

```sh
lake build          # compila e verifica os 76 teoremas (~6 s)
```

Exige Lean 4.33.1 (`lean-toolchain`). Se `lake` não estiver no `PATH`:
`export PATH="$HOME/.elan/bin:$PATH"`.

A saída de `lake build` inclui, do `Kaelix/Auditoria.lean`, os `#print axioms`
e os valores em decimal de cada grandeza, para conferência a olho contra as
tabelas do TCC.

## Método: por que não há números reais aqui

Lean sem Mathlib não tem ℝ, e π e as raízes não são racionais. Em vez de
importar uma biblioteca de análise, o projeto usa **aritmética de intervalos
sobre racionais exatos** (`Kaelix/Racional.lean`):

* `Q` é um racional `num/den` sem normalização por MDC. A normalização
  exigiria `Nat.gcd`, que não reduz no núcleo; sem ela, cada comparação vira
  uma multiplicação cruzada de inteiros que o núcleo avalia com GMP. O preço é
  denominador grande, nunca erro de arredondamento.
* `Intv` é um par `[lo, hi]`. Toda grandeza irracional entra como intervalo
  que a contém — π em dez casas, e cada raiz por enquadramento verificado
  (`ehRaiz`, `ehRaiz4`: basta checar `lo² ≤ x ≤ hi²`, e a monotonicidade de
  `t ↦ t²` faz o resto). Toda operação devolve intervalo que contém o
  resultado verdadeiro, então `lo < x < hi` no fim vale para o valor real, e
  não para um representante escolhido.

Isso também é o que permite verificar raiz de equação transcendente sem
resolver nada: mostrar que o resíduo do balanço térmico é positivo em `T₁` e
negativo em `T₂` localiza a raiz em `(T₁, T₂)`, dado que o resíduo é monótono
— e essa monotonicidade é elementar e está argumentada em comentário.

## O que fica fora do núcleo, e portanto precisa de leitura humana

1. As **definições** de cada modelo correspondem às fórmulas do Capítulo 3.
   Elas estão no topo de cada arquivo, curtas e comentadas, justamente para
   isso.
2. O enquadramento de π (`piI`) usa dígitos de constante conhecida.
3. A solidez da aritmética de intervalos implementada em `Racional.lean`.
4. Os argumentos de **monotonicidade** que transformam duas avaliações de sinal
   na localização de uma raiz.

Fora isso, nada é acreditado: nem os valores do TCC, nem os das planilhas, nem
os dos notebooks.

## Mapa: valor no TCC → teorema

| §  | Valor relatado | Teorema | Veredito |
|----|---|---|---|
| 4.2.1 | Nyquist 500 Hz para f_s de 1 kHz | `Aquisicao.nyquist_500` | confirma |
| 4.2.1 | BPFO 104,6 Hz | `Aquisicao.bpfo_exata` (104,606 25 exatos) | confirma |
| 4.2.1 | BPFI 157,9 Hz | `Aquisicao.bpfi_exata` (157,893 75 exatos) | confirma |
| 4.2.1 | defeito na banda, ressonância fora | `bpfo_dentro_da_banda`, `ressonancia_fora_da_banda` | confirma |
| 4.2.1 | 3,5 kHz rebate em 500 Hz | `Aquisicao.alias_da_ressonancia` (igualdade exata) | confirma |
| 4.2.1 | banda ISO (10–1000 Hz) não atendida | `Aquisicao.banda_iso_nao_atendida` | confirma |
| 4.2.3 | rigidez do caminho 1,45·10⁶ N/m | `Montagem.rigidez_do_caminho` (1 446 297,8) | confirma |
| 4.2.3 | frequência de montagem 557 Hz | `Montagem.freq_montagem_ASA` (557,196) | confirma |
| 4.2.3 | transmissibilidade ≈ 5× em 500 Hz | `Montagem.transmissibilidade_em_500` (4,9488) | confirma |
| 4.2.3 | erro de amplitude > 10 % em 168 Hz | `erro_abaixo_de_10_em_168`, `erro_acima_de_10_em_169` | confirma com ressalva: a travessia está em (168, 169) Hz, então em 168 Hz o erro ainda é 9,98 % |
| 4.2.3 | flexibilidade 51,1 / 0,4 / 48,5 % | `Montagem.decomposicao_da_flexibilidade` | confirma |
| 4.2.3 | base dobrada → 750 Hz | `Montagem.base_dobrada_nao_resolve` (749,53) | confirma |
| 4.2.3 | alumínio → 3273 Hz | `Montagem.freq_montagem_aluminio` (3272,79) | confirma |
| 4.2.3 | painéis acima de 1300 Hz | `Montagem.painel_lateral` (1307,25) | confirma |
| 4.2.3 | prática pede f_n ≥ 3 kHz | `Montagem.reprova_regra_3x_por_fator_5` | confirma |
| 4.3.1 | referência analítica 6,7524 mm/s | `Integracao.vrms_analitico` (6,752 372) | confirma |
| 4.3.1 | viés de 0,02 m/s² leva a 55,08 mm/s | `Integracao.relatado_55_08_na_faixa` | parcial: a fórmula fechada da deriva dá 46,2 mm/s (janela de 4 s) a 69,3 mm/s (6 s), faixa que contém o valor relatado. O TCC não declara a janela da simulação; sem ela, a verificação é de mecanismo e ordem de grandeza |
| 4.3.1 | sinal de zona A classificado além de D | `Integracao.zona_A_vira_alem_de_D` | confirma |
| 4.4.1 | resistência do caminho em ASA 88,8 K/W | `Termica.resistencia_ASA` (88,844) | confirma |
| 4.4.1 | em alumínio 0,074 K/W; razão 1206× | `resistencia_aluminio`, `razao_das_resistencias` | confirma |
| 4.4.1 | **temperatura interna 44,8 °C com carcaça a 80 °C** | `Termica.asa_sobe_em_32_9`, `asa_desce_em_33_1`, **`refuta_44_8`** | **refuta: o balanço dá 33,0 °C** |
| 4.4.1 | **bateria a 45 °C com carcaça em torno de 81 °C** | `Termica.asa_nao_atinge_45_nem_com_carcaca_90` | **refuta na configuração em ASA**; vale na de alumínio (`aluminio_atinge_45_com_carcaca_46`) |
| 4.4.1 | base de alumínio → 79,0 °C | `Termica.aluminio_79` | confirma |
| 4.4.1 | autoaquecimento de 2,0 mW → 0,01 °C | `Termica.autoaquecimento_desprezivel` (0,0113) | confirma |
| 4.4.2 | tempo no ar 185 ms | `Enlace.tempo_no_ar_sf9` (185,344 ms, igualdade exata) | confirma |
| 4.4.2 | 256 d no SF mais baixo, 138 d no mais alto | `Enlace.autonomia_sf7`, `autonomia_sf12` | confirma |
| 4.4.2 | 12,5 dB entre os extremos | `Enlace.ganho_entre_extremos` | confirma |
| 4.4.2 | Wi-Fi 44 d contra 236 d no enlace adotado | `Enlace.autonomia_wifi`, `autonomia_sf9` | confirma |
| 4.4.2 | rádio em standby: 45 d | `Enlace.autonomia_sem_sleep` | confirma |

Sem cobertura, por serem de procedência S ou M: contraste de 413× e 20×,
tabela de detecção por modo de falha, os 42,1 % de falso alarme, a queda de
área parcial, a inflação por vazamento e os resultados das cinco variantes de
integração (exceto a referência analítica e a deriva). Também não coberta
nesta rodada: a força de retenção magnética (7–30 %), que depende de um modelo
de ímã com duas raízes quadradas e não foi formalizada.

## A divergência térmica, em detalhe

O valor de 44,8 °C vem da célula 8 de `analise-termica.ipynb`, que resolve o
balanço por iteração de ganho fixo: 500 passos de `T += 0,005·(Q_in − Q_out)`
partindo de `T = (80 + 30)/2 = 55 °C`. A iteração caminha na direção certa, mas
em 500 passos ainda não chegou à raiz — parou em 44,8 °C a caminho de 33 °C.

Isso não é conjectura. O próprio repositório registra a correção: o bloco final
de `hardware/termica.py` grava `experiments/figures/data/fig11_correcao.csv`
com as duas leituras lado a lado, e para carcaça a 80 °C elas são **44,841 °C
("500 iterações")** e **33,005 °C ("convergido")**. O modelo em elementos
finitos do mesmo arquivo, com o motor a 90 °C, dá **34,30 °C**. O que este
projeto acrescenta é a prova de que 44,8 °C não pode ser a raiz: o resíduo já é
negativo, e por larga margem (−2,79 W), em 44,7 °C.

Duas consequências para o texto do TCC:

1. **O número precisa mudar** em §4.4.1, de 44,8 °C para ≈ 33 °C — e com ele o
   "temperatura interna alcançada com carcaça em torno de 81 °C".
2. **O achado principal muda de forma, não de direção.** Com base em ASA a
   bateria nunca atinge o limite de carga de 45 °C, nem com a carcaça a 90 °C;
   o invólucro plástico isola bem demais para isso. Mas a análise mecânica de
   §4.2.3 recomenda base metálica — e com base de alumínio bastam **46 °C de
   carcaça** para o interior chegar a 45 °C. O conflito entre elos que o TCC
   enuncia continua de pé, e fica mais nítido: não é que a bateria limite o
   projeto atual, é que ela limita exatamente a correção que o projeto precisa
   fazer. A quebra térmica de 2 mm, que o relatório de origem propõe, leva o
   interior a 40,1 °C com carcaça a 80 °C (`Termica.quebra_termica`) — e é,
   pelos números corrigidos, a saída que fecha os dois requisitos.

## Organização

```
Kaelix/Racional.lean    núcleo: racional exato Q, intervalos Intv, π, raízes
Kaelix/Aquisicao.lean   banda, BPFO/BPFI, Nyquist, rebatimento        (17)
Kaelix/Integracao.lean  velocidade eficaz analítica, deriva do viés   (10)
Kaelix/Montagem.lean    rigidez, f_n, transmissibilidade, painéis     (20)
Kaelix/Termica.lean     resistências, balanço, limite da bateria      (14)
Kaelix/Enlace.lean      tempo no ar, orçamento de energia             (15)
Kaelix/Auditoria.lean   #print axioms e valores em decimal
```

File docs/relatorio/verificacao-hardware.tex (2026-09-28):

% Kaelix — verificação de hardware: esquemático, placa, invólucro e simulação
% Compilar:  latexmk -pdf verificacao-hardware.tex
%
% Formato tabular deliberado. Cada linha é um item verificável: o que foi
% medido, com que ferramenta, e o que o resultado permite afirmar.

\documentclass[10pt,a4paper,landscape]{article}

\usepackage[T1]{fontenc}
\usepackage[utf8]{inputenc}
\usepackage[brazil]{babel}
\usepackage{lmodern}
\usepackage[landscape,top=1.5cm,bottom=1.6cm,left=1.4cm,right=1.4cm]{geometry}
\usepackage{booktabs}
\usepackage{tabularx}
\usepackage{array}
\usepackage{siunitx}
\usepackage{amsmath}
\usepackage{microtype}
\usepackage[hidelinks]{hyperref}
\usepackage{caption}
\usepackage{enumitem}
\usepackage{titlesec}
\usepackage{float}
\usepackage{graphicx}
\usepackage{seqsplit}

\sisetup{output-decimal-marker={,}, group-separator={.}, per-mode=symbol}
\captionsetup{font=footnotesize, labelfont=bf}
\setlist{itemsep=1pt, topsep=3pt, parsep=0pt, leftmargin=*}
\titleformat{\section}{\normalfont\large\bfseries}{\thesection}{0.7em}{}
\titlespacing{\section}{0pt}{11pt}{5pt}
\titleformat{\subsection}{\normalfont\normalsize\bfseries}{\thesubsection}{0.6em}{}
\titlespacing{\subsection}{0pt}{8pt}{3pt}
\pagestyle{plain}

% emergencystretch, e não \sloppy: \sloppy dentro do preâmbulo da coluna
% interfere na passada de medição do tabularx e as tabelas encolhem para um
% quarto da largura. O objetivo é o mesmo — impedir que um \texttt de
% caminho de arquivo transborde a coluna.
\newcolumntype{Y}[1]{>{\raggedright\arraybackslash
  \setlength{\emergencystretch}{2em}\hsize=#1\hsize}X}
% \seqsplit ficou de fora: com os pesos de coluna corretos não há
% mais transbordo, e ele espaçava os nomes de arquivo ao justificar.
\newcommand{\arq}[1]{\texttt{#1}}
\newcommand{\ok}{\textsf{fecha}}
\newcommand{\nok}{\textsf{não fecha}}

\begin{document}

\begin{center}
{\Large\bfseries Verificação de hardware do Kaelix}\\[2pt]
{\large Esquemático, placa, invólucro e simulação numérica}
\end{center}

\vspace{2pt}

\section{Escopo e critério}

\begin{itemize}
\item Cobre a cadeia esquemático $\rightarrow$ placa $\rightarrow$ sólido 3D $\rightarrow$ análise numérica, para três versões (v1, v2, v3) de placa e de invólucro. A v3 é a v2 acrescida do circuito de carga da bateria (Seção~\ref{sec:v3}); as análises modal, de PDN e de vibração cobrem v1 e v2.
\item Nenhum resultado provém de bancada. Todos os valores são de geração, verificação geométrica ou simulação. O documento não reivindica validação experimental.
\item A coluna \textbf{Medição} registra a grandeza que sustenta cada afirmação. Itens sem medição associada aparecem como \textsf{não verificado}.
\item Correções a análises anteriores do projeto constam da Seção~\ref{sec:correcoes} com o valor antigo, o valor corrigido e a causa.
\end{itemize}

\section{Cadeia de geração e verificação}

Nenhum arquivo derivado é editado à mão. A fonte é \texttt{hardware/gen\_schematic.py}.

\begin{table}[H]\footnotesize
\begin{tabularx}{\textwidth}{@{}Y{0.7} Y{1.0} Y{1.3} Y{1.0}@{}}
\toprule
\textbf{Etapa} & \textbf{Ferramenta} & \textbf{Saída} & \textbf{Verificação automática} \\
\midrule
Esquemático & \texttt{gen\_schematic.py} & \texttt{.kicad\_sch}, \texttt{.kicad\_sym}, netclasses & ERC com aviso tratado como erro \\
Placa & \texttt{gen\_pcb.py} + \texttt{router.py} & \texttt{.kicad\_pcb} & DRC com zonas preenchidas; contenção no contorno; colisão mecânica e de cobre \\
Sólido & \texttt{kicad-cli export step}, \texttt{gen\_involucro.py} & \texttt{.step} da placa e do invólucro & existência de modelo por footprint; interferência entre corpos \\
Modal & gmsh 4.15 + CalculiX 2.23 & frequências e formas & convergência de malha em três refinos \\
Térmica & gmsh + CalculiX & campo e transiente & balanço fechado contra modelo concentrado \\
\bottomrule
\end{tabularx}
\end{table}

Regeração a partir de diretório limpo reproduz \texttt{.kicad\_sch}, \texttt{.kicad\_pcb} e \texttt{.kicad\_sym} byte a byte nas duas versões. O roteador é determinístico.

\section{Correções no esquemático}

\begin{table}[H]\footnotesize
\begin{tabularx}{\textwidth}{@{}p{0.7cm} Y{1.184} Y{0.868} Y{0.947}@{}}
\toprule
\textbf{\#} & \textbf{Condição anterior} & \textbf{Medição} & \textbf{Alteração} \\
\midrule
1 & Corte de alimentação dos periféricos por transistor \emph{low-side}. Os pull-ups de \SI{4.7}{\kilo\ohm} permaneciam em +3V3 e alimentavam o MPU6050 pelos diodos de ESD de SDA/SCL & modo de falha FM-27 já registrado em \arq{ANALISE-DE-FALHAS.md} & \emph{Load switch} \emph{high-side} (Q1 SI2301 + Q2 BC847B); pull-ups transferidos para o rail comutado +3V3\_SW \\
2 & MPU6050 permanentemente alimentado & \SI{3.9}{\milli\ampere} contínuos, folha de dados InvenSense & rail comutado; consumo médio do ciclo \SI{314}{\micro\ampere} \\
3 & Ausência de medição de tensão da bateria & REQ-SEG-29 e REQ-SEG-53 dependem dela & divisor \SI{1}{\mega\ohm}/\SI{1}{\mega\ohm} e capacitor de \SI{100}{\nano\farad} em IO6 \\
4 & Ausência de proteção contra polaridade invertida & --- & Q3 SI2301 em série com a entrada \\
5 & Ausência de capacitor no nó do ADC do NTC, embora FM-08 raciocine sobre ``capacitância de filtro $\times$ \SI{10}{\kilo\ohm}'' & \arq{ANALISE-DE-FALHAS.md} & C12, \SI{100}{\nano\farad} \\
\bottomrule
\end{tabularx}
\end{table}

O esquemático é idêntico nas duas versões de placa: mesmos 32 componentes, 24 nets e 118 pads com net. A versão altera contorno, \emph{placement} e roteamento.

\begin{figure}[H]\centering

\caption{Esquemático. A figura é gerada a partir da mesma netlist que produz o
\texttt{.kicad\_sch}, e a geração falha se algum par (referência, pino) da netlist
não estiver desenhado. Confere 106 pinos.}
\end{figure}

\section{Placa gerada}

\begin{figure}[H]\centering
\begin{minipage}{0.24\textwidth}\centering
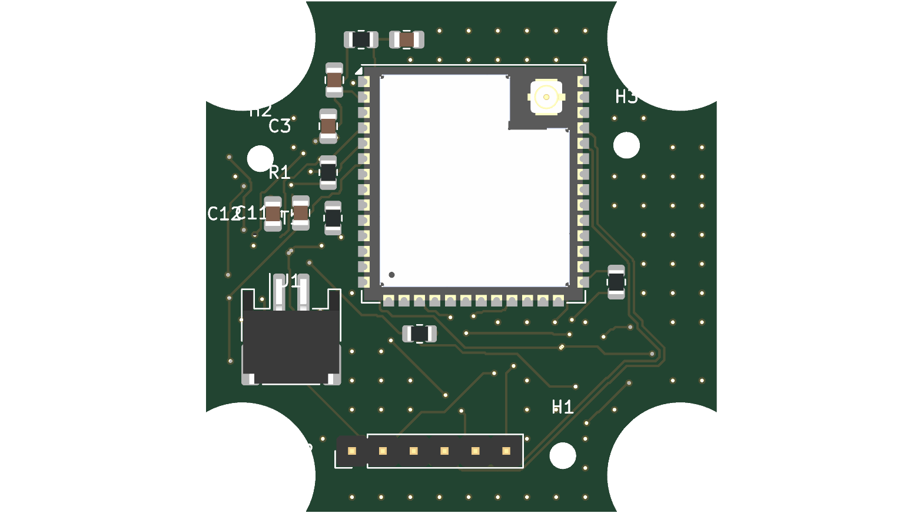
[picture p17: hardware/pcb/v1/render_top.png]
\\[1pt]
{\footnotesize v1, face superior}
\end{minipage}\hfill
\begin{minipage}{0.24\textwidth}\centering
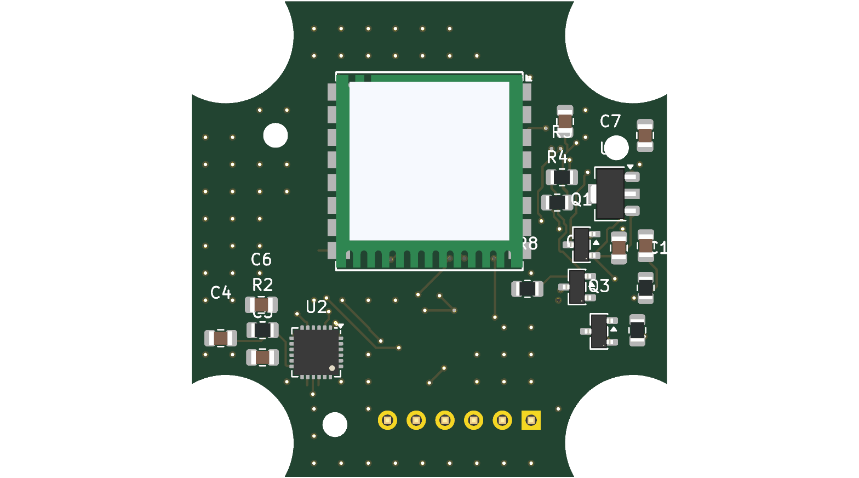
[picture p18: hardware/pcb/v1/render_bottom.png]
\\[1pt]
{\footnotesize v1, face inferior}
\end{minipage}\hfill
\begin{minipage}{0.24\textwidth}\centering
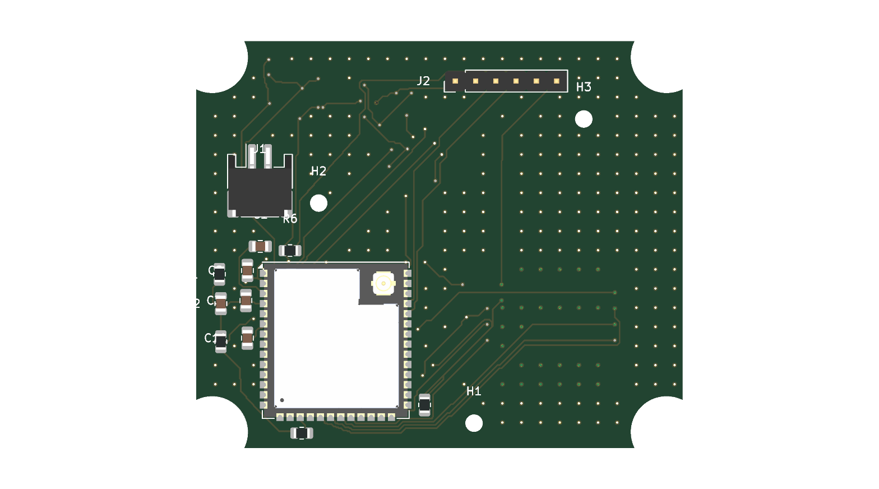
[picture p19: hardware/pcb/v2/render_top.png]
\\[1pt]
{\footnotesize v2, face superior}
\end{minipage}\hfill
\begin{minipage}{0.24\textwidth}\centering
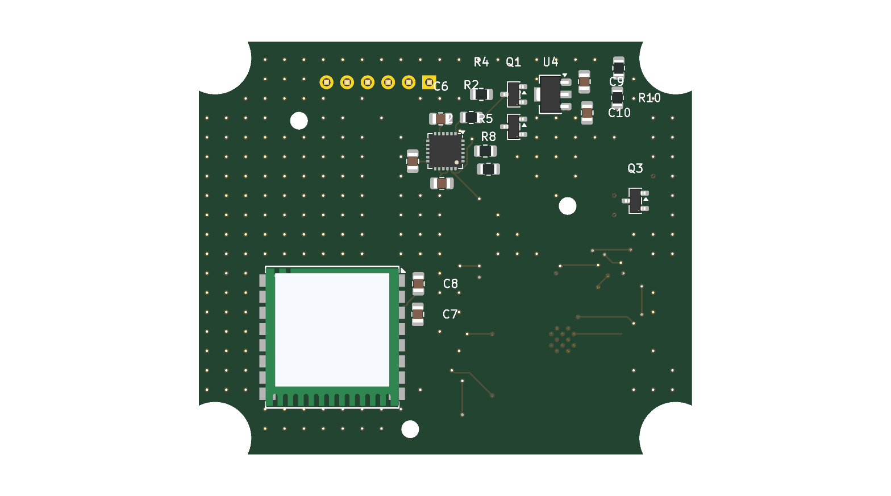
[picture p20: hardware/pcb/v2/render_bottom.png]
\\[1pt]
{\footnotesize v2, face inferior}
\end{minipage}
\caption{Placas geradas. Contorno retangular com quatro recortes de canto para
os bosses do invólucro. Duas camadas, plano de terra em ambas.}
\end{figure}

Regras de fabricação, iguais nas duas versões: traço \SI{0.20}{\milli\meter},
folga \SI{0.15}{\milli\meter}, via Ø\SI{0.60}{\milli\meter} com furo
\SI{0.30}{\milli\meter}. Mínimos declarados: furo \SI{0.20}{\milli\meter},
folga \SI{0.15}{\milli\meter}, traço \SI{0.15}{\milli\meter}.

\section{Defeitos de geração da placa}

\subsection{Corrigidos}

\begin{table}[H]\footnotesize
\begin{tabularx}{\textwidth}{@{}p{0.7cm} Y{1.184} Y{0.868} Y{0.947}@{}}
\toprule
\textbf{\#} & \textbf{Defeito} & \textbf{Medição} & \textbf{Correção} \\
\midrule
6  & Ângulo de pad gravado como relativo; é absoluto (biblioteca mais rotação do footprint) & 42 curtos no DRC & conferido contra as placas de exemplo do KiCad \\
7  & Sinal da rotação invertido: pad local $(0;\,7{,}62)$ a \SI{90}{\degree} mapeado para $-x$ & pad 4 do J2 reportado em $+7{,}62$ pelo DRC & sinal corrigido \\
8  & Rotação própria do pad ignorada & QFN-24 descrito com pads de \SI{0.85}{\milli\meter} em passo de \SI{0.5}{\milli\meter}, sobrepostos entre si & largura e altura trocadas quando o pad tem \SI{90}{\degree} \\
9  & Pad \texttt{custom} medido pelo campo \texttt{size} (âncora) & aba do SOT-89 mede \SI{4.6}{\milli\meter}; \texttt{size} declara \SI{1.475}{\milli\meter} & leitura das \texttt{primitives} \\
10 & Colisão mecânica e colisão de cobre tratadas como invariante único & furo M2 sobre o pad do R6 não detectado & invariantes separados; pad passante conta nas duas faces \\
11 & Contorno circular de \SI{74}{\milli\meter} num vão de \SI{43}{\milli\meter}; o verificador comparava escalares & contorno contra vão do desenho & contorno retangular; módulos distribuídos um por face \\
12 & Nenhuma pista roteada & 70 pads desconectados no DRC & roteador de labirinto de duas camadas \\
13 & Corredor de cabo do conector de bateria não modelado & furo M2 a \SI{2.6}{\milli\meter} da boca do conector & corredor incluído como restrição de \emph{placement} \\
22 & Pino passante de componente não contava como obstáculo na face oposta; só o furo de fixação contava & 3 \texttt{pth\_inside\_courtyard} no DRC da v3: pinos de carcaça do USB-C sob U5, R13 e C14 & regra estendida a pino com pad $\geq\SI{0.8}{\milli\meter}$; vias térmicas de \SI{0.6}{\milli\meter} do WROOM-1U continuam fora \\
23 & O roteador contava como plano a faixa entre as fileiras de pads de um QFN de passo fino & grupo de terra solto no DRC da v3: escape do U2.1 terminado numa ilha sob o MPU6050 & plano não conta como caminho sob o corpo de peça de passo fino, na face dela; o roteamento de v1 e v2 mudou, com DRC limpo nas três \\
24 & Furos de USB-C e SMA do invólucro nunca cortados no modelo: o cilindro começava em $-c_x$ em vez de $-c_x/2$ & interferência de \SI{0.07}{\milli\meter} entre a carcaça do USB-C da v3 e a parede & cilindro reposicionado; o corpo perde \SI{0.58}{\centi\meter\cubed} nas duas versões \\
\bottomrule
\end{tabularx}
\end{table}

\subsection{Abertos}

\begin{table}[H]\footnotesize
\begin{tabularx}{\textwidth}{@{}p{0.7cm} Y{1.333} Y{0.762} Y{0.762} Y{1.143}@{}}
\toprule
\textbf{\#} & \textbf{Defeito} & \textbf{v1} & \textbf{v2} & \textbf{Decorrência} \\
\midrule
14 & A placa não parafusa nos bosses do invólucro & furo M3 em $(18;\,18)$ exigiria material até \SI{28.2}{\milli\meter} na diagonal; o canto R7 termina em \SI{27.5}{\milli\meter} & recortes $r=\SI{4.5}{\milli\meter}$ coincidem com os eixos dos bosses & a fixação é o assento pelo aro mais três furos M2 próprios \\
15 & Corredor do cabo & \SI{4.0}{\milli\meter} & \SI{6.0}{\milli\meter} & com \SI{6.0}{\milli\meter} a v1 perde a saída de terra de RT1.2 e R8.2 (3 itens soltos no DRC) \\
16 & Altura do conjunto definida pelos conectores & J2 \SI{11.54}{\milli\meter}, J1 \SI{5.60}{\milli\meter}, módulos \SI{3.20}{\milli\meter} & idem & decidir se o header de gravação permanece populado no produto \\
17 & Divisor do NTC satura no frio: \SI{3.22}{\volt} a \SI{-40}{\celsius}, acima da faixa útil do ADC ($\approx$\SI{3.1}{\volt} a \SI{12}{\decibel}) & idem & idem & abaixo de $\approx$\SI{-35}{\celsius} os limiares de curto e aberto não disparam (razão 0,94 contra 0,99) \\
\bottomrule
\end{tabularx}
\end{table}
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

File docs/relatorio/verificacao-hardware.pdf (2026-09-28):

## Verificação de hardware do Kaelix

## Esquemático, placa, invólucro e simulação numérica

## 1 Escopo e critério

- Cobre a cadeia esquemático → placa → sólido 3D → análise numérica, para três versões (v1, v2, v3) de placa e de invólucro. A v3 é a v2 acrescida do circuito de carga da bateria (Seção 7); as análises modal, de PDN e de vibração cobrem v1 e v2.
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

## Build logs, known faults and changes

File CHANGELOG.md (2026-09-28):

# Changelog

Registro das mudanças do projeto Kaelix. Formato baseado em
[Keep a Changelog](https://keepachangelog.com/pt-BR/1.1.0/).

## [Não publicado]

## Verificação formal em Lean 4 passa a ser versionada

`experiments/verificacao-lean/`: 76 teoremas que reproduzem por aritmética
exata de intervalos as contas de forma fechada do TCC, sem `sorry` e sem
axiomas — conferido com `#print axioms` em todos os 76, e não só nos cinco
que `Auditoria.lean` imprime. Estava fora do repositório, sem versionamento.
Inclui a refutação dos 44,8 °C do modelo térmico concentrado (a raiz está em
33,0 °C), o que corrobora por outra via a correção feita nos relatórios.
Rodar: `lake build` na pasta.

## Placa v3: a bateria passa a ser carregável

Até a v2 a placa **não tinha como carregar a célula**: nenhum CI carregador,
nenhum conector de entrada. O invólucro tinha o furo de USB-C, os relatórios
falavam em "recarga por USB-C", a análise térmica inteira raciocinava sobre o
limite de 45 °C *de carga* — e a netlist não tinha nada disso. O achado veio
da auditoria do TCC (defeito 19 do `verificacao-hardware`, enterrado entre
ângulo de pad e rabicho de antena).

A correção é uma **v3**, e não uma mudança na v2: a v2 é revisão mecânica por
regra (`hardware/pcb/README.md`), e circuito novo em versão velha tornaria
impossível atribuir diferença medida. v1 e v2 mantêm o esquemático byte a byte.

| Peça | Função |
|---|---|
| U5 BQ21040 | carregador linear de uma célula; pino TS suspende a carga fora de 0–45 °C |
| RT2 NTC 10k β 3380 | sensor do TS, na face de cima, sob a célula e longe do U5 |
| R13 2k7 | I_carga = 540 / 2,7 k = **200 mA** |
| J3 USB-C só energia, R11/R12 5k1 | entrada de 5 V; Rd em CC1/CC2 para fonte C-para-C |
| C13, C14, C15 | entrada, saída e filtro do TS |
| IO7 ← CHG_N | estado da carga para o firmware (nenhum código lê ainda) |

**Por que BQ21040.** Único entre BQ21040, TP4056 e MCP73831 com monitor de
temperatura da célula pronto para NTC de 10 k. O limite de 45 °C deixa de ser
recomendação da folha de dados da célula e passa a ser imposto pelo hardware.
O RT1 existente (B3950) não serve: os limiares do CI são calibrados para
β ≈ 3370, e com B3950 o corte cairia perto de 39 °C.

**Por que 200 mA — do modelo térmico, não de regra de bolso.** O carregador
é linear e dissipa I·(V_USB − V_bat) dentro do invólucro fechado. Novo
`hardware/termica_carga.py` roda o FEM de `termica.py` com essa fonte interna
(helpers extraídos para `termica_base.py`, saída de `termica.py` inalterada):
a placa sobe **~15 K/W**.

| 200 mA, 0,41 W | placa | folga até o corte |
|---|---|---|
| fora do motor | 36,7 °C | 8,3 K |
| motor a 90 °C | 41,1 – 44,3 °C | 0,7 – 3,9 K, **otimista** |

A 500 mA o TS cortaria nos três cenários. A folga do motor quente é otimista
porque a troca interna usa o h externo; ali ela pode ser nula. Procedimento
recomendado: carregar fora do motor ou com ele parado.

### A conclusão térmica muda — e já estava errada antes da carga

`relatorio-kaelix` concluía que "a bateria atinge 45 °C com a carcaça em torno
de 81 °C". Esse número vinha do modelo concentrado **que não convergia**
(44,8 °C a 80 °C); a correção (33,0 °C convergido; placa a 38,3 °C a 90 °C no
FEM) estava registrada no `verificacao-hardware` e nunca chegou ao texto nem à
figura 4. Reescrito: em operação nenhum limite é atingido até 90 °C de
carcaça; o limite de 45 °C restringe **só durante a carga**. A figura 4 segue
mostrando o valor não convergido, agora declarado na legenda — refazê-la mexe
no notebook de origem.

### Defeitos de gerador achados no caminho

- **Pino passante não era obstáculo na face oposta** (`gen_pcb.py`). Só furo
  de fixação era. Os pinos de carcaça do USB-C caíam sob U5, R13 e C14: 3
  `pth_inside_courtyard` no DRC. Regra estendida a pad ≥ 0,8 mm; as vias
  térmicas de 0,6 mm do WROOM-1U seguem de fora, como antes.
- **O roteador contava como plano a faixa entre as fileiras de um QFN**
  (`router.py`). O escape de GND do U2.1 terminava numa ilha sob o MPU6050 e
  o DRC acusava grupo solto. Agora o plano não conta como caminho sob o corpo
  de peça de passo fino. **Mudou o roteamento da v1 e da v2** (costura 92 → 71
  e 261 → 234), sem tocar em circuito nem placement; as três passam com DRC
  limpo.
- **Os furos de USB-C e SMA nunca foram cortados** (`gen_involucro.py`). O
  cilindro começava em −cx, a largura externa inteira, e ficava fora do corpo.
  O defeito "furo USB-C sem conector" descrevia um furo que só existia no
  desenho. Corrigido; os corpos v1 e v2 perdem 0,58 cm³. **Os resultados
  modais e térmicos de `hardware/fem/` foram calculados sem os furos** e não
  foram refeitos (~1,7% da parede).
- **Peça de borda.** O corpo do USB-C passa da borda da placa por projeto.
  `gen_pcb.py` confere o encaixe pelos pads e exige a linha "PCB Edge" do
  footprint sobre a borda (desvio 0,000 mm); `check_3d.py` aceita a passagem
  só no lado −X; `gen_involucro.py` mede a altura do conector no `.step` da
  placa e põe o furo ali (15,73 mm, contra 21,50 arbitrados).

### Não verificado

Modal, PDN e vibração não foram recalculados para a v3. O NTC do TS lê a
placa, não a célula. Célula invertida com USB ligado injeta a pré-carga
(falha dupla; conector polarizado). Sem TVS no VBUS. Tudo acima é modelo,
nenhuma medição.

## Correções de documentação: norma, procedência, referências e TCC

Entrada que faltou nos commits de 17/09/2026.

- **ISO 20816-3.** Os relatórios chamavam de "a norma" a ISO 10816-3:2009,
  retirada. Os valores de zona são idênticos; muda a rastreabilidade da
  citação. A banda passou a ser enunciada como requisito de instrumento ("ao
  menos 10–1000 Hz"), que é o que sustenta a conclusão de não conformidade.
- **Procedência.** Três resultados próprios da revisão eram apresentados como
  medidos no MAFAULDA e vêm de sinal sintetizado: o par 413×/20×, a queda de
  pAUC de 16,2% contra 3,7% e o falso alarme de ~42% com
  `contamination='auto'`. Todos no único documento que mistura procedências.
- **`docs/relatorio/referencias.bib`**, fonte canônica: 55 chaves, 53 obras;
  nas 5 divergentes vence a versão auditada.
- **Figuras** em Times, com cores de série de contraste ≥ 3:1.
- **TCC** em `docs/assembly_tcc_mount/`, consumindo o `.bib` e as figuras
  sem cópia.

## Período do ciclo para 12 minutos: REQ-PWR-06 atendido

`SLEEP_MINUTES` passou de 10 para 12 (`src/main.cpp:83`).

**Por quê.** `REQ-PWR-06` pede autonomia ≥ 8 meses. A 10 min o projeto entregava
~236 dias (7,7 meses) e o requisito estava em falha — não por medição, mas desde
que os 150 ms estimados de tempo no ar viraram 185 ms calculados para SF9. Das
três saídas possíveis (baixar o alvo, descer para SF8, alongar o período), o
período é a única que fecha o requisito **sem tocar no enlace**.

| | 10 min | 12 min |
|---|---|---|
| Carga por ciclo | 171,96 mA·s | 174,14 mA·s |
| Consumo médio | ~354 µA | **~309 µA** |
| Autonomia | ~236 d (7,7 m) | **~269 d (8,8 m)** |
| REQ-PWR-06 | ❌ | ✅ com ~26 dias de margem |

**Custo:** latência de detecção — uma falha que comece logo após uma transmissão
demora até um período para ser vista. Irrelevante para vibração em motor
industrial, cuja evolução se mede em dias.

**Efeito colateral que vale mais que a economia:** a folga torna **SF10 viável**
(~243 dias, ainda ≥ 8 meses). A 10 min, SF10 dava ~211 dias e a escolha de
alcance ficava travada pelo orçamento de energia — o levantamento de RSSI em
planta agora pode pedir os 2,5 dB extras sem reabrir o requisito. Pelo mesmo
motivo, as três linhas do §7.4 da análise de falhas (pacote de diagnóstico de
36 bytes) passaram a caber no requisito: o custo virou margem consumida, não
conflito.

### Corrigido junto

- **Probabilidade de colisão.** README e `main.cpp` davam 1,5% para 20
  dispositivos e 3,7% para 50. Esses valores correspondem a **226 ms**, o tempo
  no ar em `CR 4/7` — o firmware fixa `CR 4/5`. É a mesma troca de linha já
  encontrada no §7.4. Com 185 ms reais e período de 720 s: **1,0% e 2,5%**.
- **Tabela de SF do README.** Era de 20 bytes e do ciclo de 10 min. Refeita para
  21 bytes, `CR 4/5` e 12 min, com coluna dizendo quais SF atendem REQ-PWR-06.
  SF12 a 21 bytes são 1483 ms, não os 1319 ms da v1.
- **Bloco de orçamento em `src/power/sleep.cpp`.** Ainda descrevia 150 ms de TX,
  600 s de sono e ~346 µA. Reescrito.

## Primeiro build do alvo: WDT-1 corrigido e documentação sincronizada

O `pio run -e esp32-s3` passou a rodar. Ele reprovou de imediato, e o que ele
encontrou motivou esta rodada.

### Corrigido

- **WDT-1 não compilava no ESP32-S3.** `src/power/watchdog.cpp` incluía
  `<soc/rtc_wdt.h>` sob uma guarda `__has_include`. A guarda testava a
  **existência** do cabeçalho, não sua **usabilidade**: no S3 o arquivo está
  presente e referencia `RTC_WDT_STG_SEL_*`, definidos apenas na árvore do ESP32
  original — símbolo nenhum deles existe no SDK do S3. O build do alvo falhava
  com 5 erros, em vez de degradar para `NotImplemented` como a guarda pretendia.
  A proteção falhou exatamente no cenário para o qual foi escrita.

  A implementação passou a usar `hal/wdt_hal.h` (RWDT), portátil entre ESP32, S2,
  S3 e C3 e a mesma via que o ESP-IDF usa no bootloader — o que eliminou o
  condicional por família em vez de acrescentar mais um. A janela é convertida em
  ticks a partir de `rtc_clk_slow_freq_get_hz()`, e não de constante: o
  `RTC_SLOW_CLK` é RC de ~136 kHz ou cristal de 32768 Hz conforme a placa, e uma
  constante fixa faria a janela de 20 s virar 4,8 s ou 83 s sem nenhum sintoma
  além do watchdog agindo na hora errada. `WDT_STAGE_ACTION_RESET_SYSTEM`
  preserva o domínio RTC, onde vive o estado retido — `RESET_RTC` apagaria a
  evidência de instabilidade que o FM-33 existe para preservar.

- **Cabeçalho da imagem declarava 8 MB de flash.** `board_build.flash_size`
  governa só o lado do build; o `elf2image` lê `upload.flash_size`, que o perfil
  da `devkitc-1` fixa em 8 MB. A tabela de partições vai até 16 MB (`app1`
  termina em 12,6 MB; `spiffs`, em 15,6 MB). O app cabe nos primeiros 8 MB, então
  nada quebra hoje; OTA, SPIFFS e coredump quebrariam. Corrigido com
  `board_upload.flash_size`, deliberadamente sem tocar em `maximum_size` — a
  checagem de tamanho tem de continuar valendo contra a partição app0 de 6,25 MB.

- **Erro de conta no §7.4 da análise de falhas.** Os ~363 µA e ~230 dias
  atribuídos ao pacote de 36 bytes pertenciam ao de **21 bytes em CR 4/7**: as
  linhas do cálculo foram trocadas. E a base de comparação (~346 µA, ~241 dias)
  era anterior ao cálculo de tempo no ar em SF9. Recalculado a partir do que o
  firmware transmite (21 B, CR 4/5, 185 ms): 36 bytes custam **12 dias** de
  autonomia mantendo CR 4/5, não 11 contra uma base inexistente.

### Sincronizado com o código

A documentação descrevia um firmware anterior a várias rodadas. Corrigido em
`README.md`, `docs/RASTREABILIDADE.md`, `docs/ANALISE-DE-FALHAS.md` e
`docs/ARQUITETURA-SOFTWARE.md`:

- **Modelo embarcado.** Vários pontos ainda diziam `N_TREES = 0` e "limiar 0,5 é
  placeholder". O header traz 100 árvores e limiar 0,55719777 por quantil de
  calibração. A FMEA chegava a citar `if (N_TREES == 0) return Status::Normal;`,
  código que não existe: a guarda devolve `ModelAbsent` e deixa o veredito em
  `Unknown` — o firmware estava **melhor** do que a própria análise afirmava.
- **Pacote v2.** 21 bytes com `state` ternário e `diag`, não 20 bytes com
  `status` binário.
- **Orçamento de energia.** ~354 µA e ~236 dias (7,8 meses) em toda parte; 346 µA
  e 241 dias eram resíduo da estimativa de 150 ms de tempo no ar. Com isso,
  `REQ-PWR-06` ("autonomia ≥ 8 meses") passou a **não ser atendido pelo próprio
  cálculo de projeto**, e a matriz diz isso.
- **Matriz de rastreabilidade.** `REQ-ML-01` e `REQ-ML-09` estavam marcados como
  falha comprovada e já haviam sido corrigidos — o teste de paridade compila e
  passa, e `export_cpp.py` emite os 8 inicializadores por árvore. Contagens
  refeitas: 13 de 59 plenamente verificados (22,0%), 1 falha ativa restante
  (`REQ-SYS-03`, includes relativos), 4 não implementados.

### Registrado como pendência

- **Gateway uma versão atrás.** `experiments/gateway/packet.py` fixa
  `PACKET_VERSION = 1` e 20 bytes; o firmware emite v2 com 21. O gateway recusaria
  todo pacote real — falha segura, e a guarda de versão funcionando, mas a cadeia
  simulada não corresponde ao dispositivo. Os 19 testes passam porque exercitam o
  gateway contra o próprio `codificar()`: nenhum cruza a fronteira. O byte `diag`
  não tem leitor.
- **Comportamento do WDT-1 não medido.** O build prova que a API é usada
  corretamente e resolve em link; não prova que o contador do RWDT sobrevive ao
  deep sleep, premissa do `REQ-WDT-05` e do despertador de último recurso.

### Conferido contra a peça real

Um ESP32-S3 foi lido com `esptool`: QFN56 rev. v0.2, 16 MB de flash, 8 MB de
PSRAM. Confirma a variante N16R8 que o `platformio.ini` declara — a sobrescrita
do perfil da `devkitc-1` era necessária e está correta.

### Adicionado

- `docs/relatorio/praticas-sistemas-criticos.tex` — tabela de práticas de
  tolerância a falhas em sistemas embarcados críticos (redundância aviônica,
  DO-178C, IEC 61508, ISO 26262, ARINC 653, MISRA C++, JSF++), com origem,
  falha coberta, custo, limite conhecido e situação no Kaelix. Traz declaração de
  nível de conferência por fonte, no espírito de `docs/referencias.md`.

## Reorganização: análise e simulação sob `experiments/`

`figures/` e `gateway/` passaram a viver sob `experiments/`, ao lado de
`notebooks/`. A raiz do repositório fica com o que é firmware (`src/`, `lib/`,
`test/`), o pipeline de treino (`training/`), o ferramental (`tools/`) e a
documentação.

Caminhos reapontados: `\graphicspath` dos três documentos LaTeX, a profundidade
de `parents[]` em `export_gateway_data.py` e em `test_paridade_crc.py`, o runner
de testes, e as árvores de projeto nos READMEs.

**Entradas anteriores deste changelog citam os caminhos antigos** (`figures/scripts/`,
`figures/data/`). Elas descrevem o estado da época e não foram reescritas: um
changelog que reescreve o próprio passado para casar com o presente deixa de
servir como registro.

### Corrigido durante a arrumação

- **Crédito de fotografia sem fotografia.** As legendas da Figura 5, no
  `comunicacao-topologia.tex` e no README de figuras, creditavam imagens de
  componente do Wikimedia Commons. A figura deixou de usá-las quando o painel
  (a) foi refeito como grafo de estrela, e os arquivos não estão mais no
  repositório. Atribuir imagem ausente é erro factual; os créditos saíram.
- **`sys.path.insert` nos testes do gateway.** O `training/` já resolvia o
  import por `conftest.py`; o gateway não seguia o padrão. Passou a seguir, e
  com isso saíram os `# noqa: E402` que existiam só para silenciar o import
  fora de ordem.

### Adicionado

- `experiments/gateway/README.md` — o componente não tinha explicação: por que
  existe separado do nó, o acoplamento com `src/comms/lora.h`, e o que a
  simulação não cobre.
- `tools/run-all-tests.sh` — ponto de entrada único para as três suítes. Havia
  146 casos C++, 35 de treino e 19 de gateway sem forma de rodar juntos, e é
  assim que quebra de integração passa: um refactor em `lib/` que muda
  assinatura aparece no teste C++, mas o gerador Python que consome a mesma
  struct só quebra na suíte de treino. O script termina listando o que não
  cobre — a camada `src/` e qualquer comportamento em hardware.

## Conformidade com práticas de software industrial/aeroespacial

Rodada de reorganização do firmware segundo MISRA C++, JSF++ e os princípios de
determinismo do DO-178C. 19 arquivos alterados, +2027/−254 linhas, 4 módulos novos.
O objetivo não é certificar, é adotar as práticas de organização, determinismo e
rastreabilidade que projetos críticos usam — e poder justificá-las numa defesa.

### Corrigido

- **Alocação dinâmica eliminada.** `dominant_frequency` alocava dois `std::vector` de
  512 floats por chamada — ~4 KB de heap por ciclo, ~35 mil pares malloc/free por ano de
  campo, com falha de alocação não tratada. Substituídos por buffer estático
  `FFT_MAX_N`, com a não reentrância documentada. Proibição de heap após inicialização é
  JSF++ AV-206 e MISRA C++ 18-4-1.

- **Laço sem cota superior.** `isolation_tree_path_length` percorria a árvore com
  `while (tree.feature[node] != -1)`: um array corrompido travava o dispositivo, e não
  havia watchdog para tirá-lo de lá. Virou `for` com cota derivada da profundidade real
  da árvore. O defeito estrutural, porém, era a `struct`: ela não carregava o
  comprimento dos arrays, então nenhuma função conseguia validar índice. Ganhou
  `n_nodes` e `max_depth`.

- **Modelo de erro.** As sete funções que devolviam `bool` passam a devolver
  `kaelix::Status` — 41 valores organizados por faixa de subsistema, para que o gateway
  faça triagem sem tabela completa. Os quatro `false` idênticos de `lora_init()` viraram
  `RadioAbsent`, `RadioBusSilent`, `RadioConfigRejected` e `RadioTxFailed`.

- **Validação de parâmetro** em 9 módulos, via `KAELIX_REQUIRE`/`CHECK`/`ENSURE`. A
  asserção tem dois comportamentos por build: em desenvolvimento aborta com
  arquivo:linha; em produção devolve o status sem travar. A justificativa está no
  header — abortar num dispositivo com 8 meses de bateria numa máquina remota troca um
  bug por um aparelho morto e mudo.

- **Watchdog de dois estágios** (`src/power/watchdog.*`): task WDT na fase ativa, RTC WDT
  como rede de segurança, com rearme distinto para o deep sleep. A alimentação acontece
  entre etapas do ciclo e nunca dentro de laço, para que o watchdog meça progresso e não
  atividade de CPU.

### Adicionado

- `lib/kaelix_status/` — modelo de erro compartilhado, header-only, sem `Arduino.h`.
- `src/machine_state.h` — máquina de estados que materializa o estado seguro.
- `docs/ARQUITETURA-SOFTWARE.md` — camadas, convenções, políticas de memória e erro,
  estado seguro, registro de desvios. Recomenda **não** construir uma camada HAL, e
  argumenta dos dois lados.
- `docs/ANALISE-DE-FALHAS.md` — FMEA com 36 modos de falha, classes de severidade e
  detectabilidade, matriz de criticidade (em vez de RPN com números inventados),
  política de watchdog e telemetria.
- `docs/NORMA-DE-CODIFICACAO.md` — regras selecionadas de MISRA/JSF++ com exemplo certo
  e errado tirados do próprio código, mais uma seção de desvios assumidos.
- `docs/RASTREABILIDADE.md` — matriz requisito → código → teste, com a coluna de não
  verificados explícita.
- `.clang-tidy`, `.clang-format`, `tools/run-native-tests.sh`, `tools/run-static-analysis.sh`.
  O runner roda cada suíte nos **dois modos de build**, porque a asserção se comporta
  diferente em cada um: 146 casos.

### Achados da análise de falhas que não estavam na lista original

1. **Dado fabricado transmitido como medição.** `main.cpp` registrava a falha de
   `vibration_init()` e chamava `vibration_read_features()` mesmo assim; o buffer de
   zeros produz RMS=0 e curtose=0, que o modelo lê como `Normal`. Sensor morto virava
   "máquina saudável", com CRC válido.
2. **Falha para o lado inseguro na decisão.** `score > threshold ? Anomalous : Normal` —
   toda comparação com NaN é falsa em IEEE 754, então feature corrompida resultava
   sistematicamente em "sadia".
3. **O clamp do termistor convertia falha de hardware em número plausível**: NTC aberto
   lia −26 °C a −77 °C; em curto, +349 °C. Floats finitos, indistinguíveis de leitura real.
4. **`new Module(...)` é evitável** — a API do RadioLib aceita ponteiro para instância
   existente. O desvio que eu havia classificado como inevitável não era.

### Regressões introduzidas pelo refactor e corrigidas

Três quebras de integração, todas em fronteiras entre áreas de posse diferente:

- Três testes chamavam a FFT com `n = 1024` e um com `n = 4096`, acima do novo
  `FFT_MAX_N = 512`. Reparametrizados mantendo bin de 1 Hz.
- `isolation_forest.h` passou a incluir `kaelix_status.h`, e `test_export_cpp.py`
  compila fora do PlatformIO — faltava o `-I`.
- **A raiz:** a `struct IsolationTree` ganhou dois campos, mas
  `training/kaelix_ml/export_cpp.py` continuava emitindo o inicializador de seis. Com
  `n_nodes = 0`, toda inferência era rejeitada como `ModelMalformed`. O gerador Python é
  parte do mesmo contrato da struct; o acoplamento está agora documentado no cabeçalho
  dele, com guarda que falha alto se a árvore não couber em `int16_t`.

### Verificação

70 testes C++ (eram 26) e 35 Python. Paridade numérica C++↔Python reverificada em janelas
reais do MAFAULDA: divergência máxima **4,2e-06**.

**O firmware não foi compilado.** A camada `src/` passou de 269 para ~700 linhas usando
APIs do ESP-IDF (`esp_task_wdt_reconfigure`, `rtc_wdt_set_stage`, `esp_task_wdt_delete`)
que nunca passaram por compilador, e há código condicional a versão de SDK
(`#if __has_include(<soc/rtc_wdt.h>)`). `pio run -e esp32-s3` é o que fecha esta rodada.

Os três achados de severidade máxima acima ainda **não foram confirmados como
corrigidos**: a fase de reauditoria do workflow terminou por limite de sessão.

---

## Revisão de literatura e auditoria de citações

### Adicionado

- `docs/relatorio/revisao-literatura.tex` — 1472 linhas, 38 referências, todas conferidas
  em fonte primária. Escopo e método com nota de procedência, revisão por eixo, síntese
  (o que a literatura sustenta, o que contesta, o que se conclui) e lacunas.
  **Falta a seção do Eixo 2** (vazamento de dados): o agente redator caiu duas vezes,
  por conexão e por limite de sessão. As 12 referências desse eixo já estão verificadas.

### Corrigido — auditoria de citações

Duas rodadas de auditoria em fonte primária, com placares parecidos: **6 defeitos em 13**
referências do relatório, **18 em 38** da revisão. O levantamento automático original era,
na prática, uma lista de pistas — não uma bibliografia.

No relatório (`relatorio-kaelix.tex`):

- `varejao2025` — **primeiro autor errado**: I. M. S. Varejão, não F. M. Varejão (que é o
  sexto autor). Duas pessoas do mesmo grupo.
- `kolok2025` — três de cinco iniciais erradas.
- `fidali2024` — terceiro autor é J. Ochmann, não M.; título truncado.
- `iso10816` — **norma retirada**, substituída pela ISO 20816-3:2022, e o relatório a
  tratava como vigente em sete lugares. Registrado o status; a prática industrial ainda
  a usa, e é isso que justifica mantê-la. Descoberta também a Amd 1:2017.
- Títulos completos e DOIs acrescentados em cinco entradas.

**Erro factual corrigido no corpo do relatório:** o texto afirmava que Fidali identifica
pico e pico a pico como mais sensíveis *"acima da velocidade eficaz"*. Velocidade eficaz
nunca foi avaliada no estudo — a palavra "velocity" aparece duas vezes no artigo inteiro,
ambas fora do experimento. A comparação real é com aceleração eficaz, curtose e fator de
crista. A distorção tinha consequência: o parágrafo seguinte trata da velocidade eficaz
normativa da ISO, e o texto criava a impressão de que Fidali mediu o descritor da norma e
o achou inferior — argumento contra a norma que a própria monografia adota. Corrigido, e
a citação passou de contraste a apoio: os autores preveem exatamente o colapso por
limitação de banda que o projeto mediu.

Achados que atingem material já removido do repositório, registrados porque podem ter
circulado: o protocolo de limiar por distribuição gama no percentil 90 **não é** de
Koizumi et al. 2020 (aparece no baseline do DCASE2022); a redução de 90,25% em falsos
alarmes de Hermansa et al. é do **HDBSCAN**, não do Isolation Forest, que ficou atrás
dele no ranking; e Ma et al. não sustenta que o default do `contamination` equivalha a
sorteio — o artigo diz que o iForest com hiperparâmetros default é baseline difícil de
bater, e `contamination` nem está entre os hiperparâmetros estudados.

## Firmware — bloco de energia e integridade do pacote

### Corrigido — o SX1278 nunca entrava em sleep

Correção de maior impacto do bloco. O rádio não está no barramento cortado
pelos BC337, e o código nunca chamava `radio.sleep()`: depois do
`transmit()`, o RadioLib devolve o módulo para STANDBY, onde consome
~1,5 mA continuamente — inclusive durante os 10 minutos de deep sleep.

```
sem lora_sleep():  (1,5 + 0,018) mA × 600s = 910,8 mA·s
com lora_sleep():  (0,0002 + 0,018) mA × 600s = 10,9 mA·s
```

Sozinha, a diferença é 5,5× o orçamento inteiro do ciclo. O orçamento
publicado não tinha termo nenhum de LoRa idle.

### Corrigido — orçamento de energia refeito

Além do rádio, dois erros na conta anterior: a autonomia era calculada para
uma 18650 de 3000 mAh enquanto `project.md` especifica LiPo de 2000 mAh, e
a autodescarga da bateria (~2,5%/mês = ~68,5 µA, 25% do orçamento) não
entrava.

| | Antes (publicado) | Real, sem a correção | Depois |
|---|---|---|---|
| Corrente média | 270 µA | ~1,84 mA | **~346 µA** |
| Autonomia | 464 dias (18650 3000mAh) | ~45 dias | **~241 dias** (LiPo 2000mAh) |
| Meta <1 mA | ✅ margem 3,7× | ❌ 84% acima | ✅ margem 2,9× |

Os números anteriores estavam em `sleep.cpp`, `ARQUITETURA.md`, `README.md`
e `project.md`, agora todos alinhados.

### Corrigido — GPIO flutuava durante o deep sleep

GPIOs não-RTC vão para alta impedância ao entrar em deep sleep, deixando a
base dos BC337 flutuando justamente durante os 10 minutos em que o corte de
energia precisa valer. `deep_sleep()` agora chama `gpio_hold_en()` +
`gpio_deep_sleep_hold_en()`, e `peripherals_power()` chama `gpio_hold_dis()`
no boot seguinte — o hold sobrevive ao reset e travaria o pino se não fosse
solto.

### Corrigido — pacote LoRa não identificava o emissor nem detectava erro

O pacote tinha status, RMS, temperatura e um `timestamp` que era `millis()`
— que zera a cada deep sleep, então todo pacote chegava com ~3000 ms. Não
era um relógio. E sem identificação, um gateway com mais de um Kaelix na
planta não teria como saber de quem era a leitura.

Novo formato, 20 bytes: `version`, `device_id` (eFuse MAC), `boot_count`
(RTC memory, sobrevive ao sleep), `status`, `rms`, `temperature_c`, `crc`.

O CRC-16/CCITT vive em `lib/crc16/` como função pura, testada no host
contra o vetor de conferência padrão (`"123456789"` → `0x29B1`) e contra
bit invertido e troca de bytes. Um pacote corrompido no ar que chegue ao
gateway como leitura válida é pior que um pacote perdido.

Layout e round-trip verificados isoladamente: 20 bytes, offsets corretos,
CRC detecta 1 bit invertido.

### Corrigido — retornos de init eram ignorados

`main.cpp` descartava o `bool` dos quatro `*_init()` e de `lora_send()`: o
dispositivo transmitia mesmo com o rádio fora do ar, e uma falha de TX
sumia em silêncio. Agora cada falha é reportada e a transmissão é
condicionada ao rádio ter subido.

Acrescenta também `delay(100ms)` após energizar os periféricos — o MPU6050
precisa estabilizar antes do init.

### Corrigido — ADC do NTC assumia linearidade que o hardware não tem

`analogRead()` no ESP32-S3 é sensivelmente não-linear. A leitura passa a
usar `analogReadMilliVolts()`, que aplica a curva de calibração gravada no
eFuse de fábrica, com `analogSetPinAttenuation(ADC_11db)` para abrir a
faixa aos ~3,3 V do divisor. `lib/thermistor` ganhou
`ntc_resistance_from_millivolts` com testes.

### Corrigido — `platformio.ini` não declarava o hardware alvo

O alvo é o WROOM-1 **N16R8** (16 MB de flash, 8 MB de PSRAM octal), mas o
perfil default da `esp32-s3-devkitc-1` declara 8 MB de flash e nenhuma
PSRAM — metade da flash e toda a PSRAM ficavam invisíveis. Adicionados
`board_build.flash_size`, `partitions`, `memory_type = qio_opi` e
`-D BOARD_HAS_PSRAM`.

### Verificação

26 testes C++ (eram 20) e 35 Python passando. O firmware completo não pôde
ser compilado aqui (sem toolchain ESP32 nesta máquina) — `pio run -e esp32-s3`
continua sendo o passo que fecha esta rodada.

### Ainda aberto no firmware

Leitura I2C real do MPU6050 e configuração do DLPF (item 1) seguem
bloqueadas por hardware. As correntes do SX1278 e a autodescarga da LiPo
são valores de datasheet — são os dois termos que mais pesam no orçamento e
precisam de INA219 na Fase 3.

### Contexto

Rodada de correções no pipeline de treino (`training/`) para
deixá-lo pronto para receber os datasets reais (MAFAULDA/CWRU). O gatilho foi
uma auditoria de proveniência dos dados: **nenhum número do projeto vinha de
medição** — tudo era simulado — e o pipeline tinha defeitos que fariam o
download dos datasets virar retrabalho.

As correções também fecham a lacuna entre o que
`docs/questionamentos-tecnicos.md` (removido depois) concluiu
e o que o código fazia: os itens 2, 6 e 7 prescreviam correções que a
implementação ainda não tinha incorporado.

### Corrigido

- **`dataset.py`: busca de arquivos não era recursiva.** `iter_dataset_files`
  usava `Path.glob`, que não desce em subdiretórios. Como o MAFAULDA é
  organizado em pastas por tipo e severidade de falha, a busca encontraria zero
  arquivos e `train.py` cairia em silêncio no fallback sintético — como se nada
  tivesse sido baixado. Agora usa `rglob`.

- **`labeling.py`: faltava a máscara de banda da ISO 10816-3.** A norma define
  as zonas A–D sobre velocidade RMS medida entre 10 Hz e 1000 Hz. A integração
  zerava apenas o bin DC, sem recortar a banda — divergindo do método que o
  item 2 validou com erro de 0,0%. A implementação agora é a mesma do notebook
  (janela de Hann, recorte 10–1000 Hz, compensação de potência da janela),
  verificada contra o valor analítico de referência.

- **Regra de decisão do treino divergia da do firmware.** `train.py` avaliava
  com `clf.predict()`, que decide pelo `offset_` derivado de `contamination`,
  enquanto o dispositivo decide `score > ANOMALY_THRESHOLD`
  (`src/ml/model.cpp`). Os relatórios impressos no treino não descreviam o
  comportamento embarcado. Agora tudo — calibração, avaliação e exportação —
  usa `device_score()`, a mesma convenção do firmware.

- **`contamination="auto"` e limiar fixo em 0,5.** Exatamente o default que o
  item 7 mediu em 42% de falso alarme, e um limiar que não vinha de lugar
  nenhum. O limiar agora é derivado por quantil sobre um conjunto de
  calibração separado por grupo, com taxa de falso alarme alvo explícita
  (`FALSE_ALARM_TARGET = 1%`).

- **Campo `unit` era escrito e nunca lido.** `label_from_acceleration` assumia
  `g` incondicionalmente; um dataset em m/s² seria multiplicado por 9,80665
  outra vez, em silêncio. A conversão agora é explícita (`convert_unit`) e
  falha alto em unidade desconhecida.

- **`load_cwru_mat` era código morto.** Nenhum chamador — nem `train.py`, nem
  os testes. Baixar o CWRU não teria efeito. Agora está ligado ao carregamento
  por `load_device_windows("cwru")`.

### Adicionado

- **Alinhamento entre domínio de treino e de inferência** (`to_device_windows`).
  O treino extraía um vetor de features por arquivo inteiro — MAFAULDA a 50 kHz,
  ~250k amostras — enquanto o firmware extrai de uma janela de 512 amostras a
  1 kHz. `dominant_freq_hz` chegaria a 25 kHz no treino e nunca passaria de
  500 Hz no dispositivo. Todo sinal carregado agora é decimado para
  `DEVICE_SAMPLE_RATE_HZ` (com anti-aliasing FIR em estágios) e fatiado em
  janelas de `DEVICE_WINDOW_SAMPLES`, espelhando `src/main.cpp` e
  `src/sensors/vibration.cpp`.

- **Rótulo verdadeiro lido do caminho do arquivo**
  (`mafaulda_label_from_path`, `cwru_label_from_path`). O MAFAULDA codifica a
  classe de falha na estrutura de diretórios; o pipeline descartava isso e
  derivava o rótulo pelos limiares ISO. Agora o rótulo do caminho é a verdade
  de referência e o rótulo ISO vira **diagnóstico comparativo** — `train.py`
  imprime a matriz de concordância entre os dois.

- **Validação com `GroupKFold` por arquivo de origem** (item 6). Antes não
  havia split algum: `clf.fit(X_normal)` seguido de `clf.predict(X)` sobre o
  mesmo conjunto. O relatório agora traz média ± desvio entre folds, como o
  item 6 exige, e o desvio alto é informação, não ruído a esconder.

- **Calibração do limiar aninhada.** Dentro de cada fold de treino, um
  subconjunto de grupos é separado para calibrar o limiar; a avaliação ocorre
  no fold de validação intocado. Evita o otimismo de calibrar e avaliar no
  mesmo dado.

- **AUC e pAUC no relatório de treino**, com `max_fpr=0.10` — mesma chamada
  usada em `figures/scripts/export_source_data.py`, para que os números sejam
  comparáveis com a Fig. 2e. Atende à crítica A1 de
  `docs/criticas-da-literatura.md` (removido depois).

- **`training/tests/test_dataset.py`** — cobre recursão do `rglob`, taxa e
  formato da decimação, janelamento, conversão de unidade e leitura de rótulo
  por caminho.

- **Teste de referência da integração ISO** em `test_labeling.py`, contra o
  valor analítico exato de `figures/data/fig2_referencia.csv`.

### Alterado

- `data/README.md` descrevia os datasets como insumo dos testes unitários de
  `sensors/vibration.cpp`; o consumidor real é o pipeline Python. Reescrito
  com a árvore de diretórios esperada.
- `test/README.md` dizia cobrir `sensors/vibration` e `sensors/temperature`;
  os testes cobrem `lib/signal_processing`, `lib/thermistor` e
  `lib/isolation_forest`.
- `VibrationSample` ganhou o campo `group` (identidade do ensaio/arquivo de
  origem), necessário para o `GroupKFold`. O gerador sintético atribui um grupo
  distinto por amostra.

### Achado durante a implementação

O diagnóstico ISO recém-adicionado produziu resultado logo na primeira
execução: **o gerador sintético rotula como "normal" sinais que a ISO
10816-3 classifica como anômalos** — concordância global de 23,1%, com 100%
das janelas "normais" caindo em zona C/D.

A causa é dimensional. As amostras "normais" sintéticas são senoides de
0,5–1,0 g em torno de 50 Hz; integrando, isso dá ~16 mm/s RMS de velocidade,
contra o limite B/C de 1,8 mm/s da classe I. O gerador nunca foi calibrado
em amplitude contra a norma — ele foi escrito para exercitar o pipeline, e
para isso serve.

Não é um defeito do código novo; é o novo diagnóstico funcionando. Mas
reforça que os números de desempenho obtidos sobre dados sintéticos não
transferem, e que o gerador precisaria de amplitudes fisicamente plausíveis
se algum dia for usado para algo além de teste de fumaça.

### Layout do MAFAULDA conferido em fonte primária

Os nomes de diretório e a ordem das 8 colunas em `dataset.py` eram
"documentados publicamente, não conferidos". Conferidos agora contra a
página oficial da UFRJ:

- **Nomes de diretório: batem.** Os 6 tarballs distribuídos são `normal`,
  `horizontal-misalignment`, `vertical-misalignment`, `imbalance`,
  `underhang` e `overhang` — exatamente as chaves de `MAFAULDA_FAULT_DIRS`.
- **Ordem das colunas: bate.** Tacômetro, acelerômetro underhang (axial,
  radial, tangencial), acelerômetro overhang (axial, radial, tangencial),
  microfone.
- **Volume:** 1951 arquivos, 13,0 GB, janelas de 5 s a 50 kHz (250.000
  linhas por arquivo).

O TODO correspondente foi removido. O do CWRU foi **afiado** em vez de
removido: o download oficial entrega .mat soltos e numerados, sem estrutura
de pastas — a condição de cada ensaio está numa tabela do site. É preciso
organizar em `normal/`, `ir/`, `or/`, `b/` antes de carregar, e
`cwru_label_from_path` falha alto até que isso seja feito.

### Composição do MAFAULDA e o que ela implica

| Classe | Arquivos |
|---|---|
| Normal | 49 |
| Imbalance | 333 |
| Horizontal misalignment | 197 |
| Vertical misalignment | 301 |
| Underhang bearing | 558 |
| Overhang bearing | 513 |

Dois pontos que afetam o planejamento:

1. **Só 49 arquivos normais.** Como o Isolation Forest treina apenas sobre
   operação normal, o conjunto de treino inteiro sai desses 49 → ~441
   janelas de 512 amostras. Suficiente, mas modesto, e é o que limita o
   `GroupKFold` (49 grupos).
2. **56% das anomalias (1071 de 1902) são falha de rolamento.** É
   exatamente a classe que o item 1 mostra ficar fora do alcance do
   MPU6050: depois de decimar para 1 kHz, a ressonância de 3–10 kHz que
   carrega a assinatura do defeito já foi descartada. Esperar bom
   desempenho nessas classes contradiz a própria análise do projeto — o
   desempenho útil deve vir de imbalance e misalignment (831 arquivos).

### Primeiro treino em dados reais (parcial — 4 de 6 classes)

880 arquivos do MAFAULDA (normal, imbalance, horizontal- e
vertical-misalignment) → 7920 janelas. Underhang/overhang ainda baixando.

**O pipeline funciona.** Falso alarme medido de 1,8% ± 3,0% contra alvo de
1% — a calibração por quantil faz o que promete. `GroupKFold` por arquivo,
5 folds.

**O modelo não.** Detecção de 11,7% ± 16,1% no ponto de operação:

| Classe | Detecção @ 1% FA |
|---|---|
| horizontal-misalignment | 3,8% ± 3,8% |
| vertical-misalignment | 8,6% ± 8,5% |
| imbalance | 19,3% ± 30,3% |

AUC global 0,795 ± 0,040, pAUC (FPR≤10%) 0,665 ± 0,099. A distância entre
as duas confirma em dado real a crítica A1: a AUC global sugere um detector
razoável, e no ponto de operação que importa ele não é.

### Duas causas identificadas, ambas anteriores ao modelo

**1. O vetor de 4 features não separa desalinhamento de normal.** Medianas:

| Classe | rms | kurtosis | crest | dom. freq |
|---|---|---|---|---|
| normal | 0,177 | −0,155 | 3,11 | 46,9 |
| horizontal-misalignment | 0,174 | −0,115 | 3,11 | 48,8 |
| vertical-misalignment | 0,171 | 0,034 | 3,23 | 50,8 |
| imbalance | 0,607 | −1,310 | 2,00 | 41,0 |

Desalinhamento é indistinguível de normal nas quatro features — o RMS é até
levemente menor. Só imbalance separa, por amplitude. Entre 64% e 92% das
janelas anômalas caem dentro da faixa p1–p99 dos normais em cada feature.

**2. `dominant_freq_hz` mede a ressonância da bancada, não a falha.** A
correlação com a rotação real do ensaio (que o MAFAULDA codifica no nome do
arquivo) é **−0,018**. Investigando o espectro:

```
rot 12,3 Hz | pico ACELERAÇÃO 117,2 Hz | pico VELOCIDADE (10-500 Hz) 11,7 Hz
rot 13,9 Hz | pico ACELERAÇÃO 117,2 Hz | pico VELOCIDADE (10-500 Hz) 27,3 Hz
```

O pico de aceleração fica em 117,2 Hz independente da rotação: é um modo
estrutural do MFS. Como aceleração escala com ω², o espectro de aceleração
é sempre dominado pelo conteúdo de alta frequência, e a linha de 1× rotação
— que é a assinatura de desbalanceamento e desalinhamento — fica soterrada.
No espectro de **velocidade** com a banda 10–500 Hz, o pico cai sobre 1×
rotação, com 86–100% da energia do pico.

**Consequência para o firmware:** `dominant_frequency()` em
`lib/signal_processing/` deveria operar sobre o espectro de velocidade
band-limitado, não sobre a aceleração crua. A FFT já é calculada; falta
dividir por 2πf e aplicar a máscara de banda — o mesmo método que o item 2
já validou para a rotulagem ISO. É barato e provavelmente a mudança de
maior retorno no dispositivo.

### Classe de máquina ISO: o default está errado para esta bancada

Velocidade RMS mediana da operação **normal** real: 4,74 mm/s.

| Classe assumida | Corte B/C | % dos normais reais marcados anômalos |
|---|---|---|
| **I** (default do `train.py`) | 1,80 mm/s | **93,4%** |
| II | 2,80 mm/s | 76,4% |
| III | 4,50 mm/s | 54,6% |
| IV | 7,10 mm/s | 2,0% |

O código antigo derivava o rótulo *da* ISO: teria treinado em ~29 janelas
sobreviventes, em silêncio, e exportado um modelo sem sentido. A mudança
para rótulo-do-caminho como verdade evitou exatamente isso.

Encaminhamento: **não usar o MAFAULDA para calibrar limiar de zona ISO.**
A bancada SpectraQuest opera mais áspera do que a norma admite para classe
I, e nenhuma das quatro classes descreve bem um simulador de laboratório.
Essa calibração depende da medição na Skala — item 3 dos questionamentos.

### Corrigido — `dominant_frequency` passa a medir velocidade band-limitada

Implementado nos dois lados (`lib/signal_processing/signal_processing.cpp` e
`training/kaelix_ml/features.py`), com a paridade preservada.

A frequência dominante era extraída do espectro de **aceleração** cru. Como
aceleração escala com ω², esse espectro é sempre dominado pelo conteúdo de
alta frequência — no MAFAULDA, um modo estrutural da bancada em 117 Hz,
idêntico com máquina sadia ou defeituosa. A feature carregava a assinatura
da montagem, não da falha.

Agora a magnitude é reponderada por `|V(f)| = |A(f)|/(2πf)` e a busca fica
restrita a 10–1000 Hz. A fase é irrelevante para escolher o bin de pico, então
não é preciso integrar o sinal — só reponderar o espectro que a FFT já produz.
Custo no firmware: uma divisão por bin. O limite inferior da banda **não é
cosmético**: sem ele a ponderação 1/f faria o bin mais baixo vencer sempre.

**Resultado, mesmos 880 arquivos e mesmo protocolo:**

| Métrica | Antes | Depois |
|---|---|---|
| Detecção @ 1% FA alvo | 11,7% ± 16,1% | **38,5% ± 8,5%** |
| F1 | 0,178 ± 0,223 | **0,550 ± 0,083** |
| pAUC (FPR≤10%) | 0,665 ± 0,099 | **0,702 ± 0,047** |
| AUC global | 0,795 | 0,805 |
| Falso alarme medido | 1,8% ± 3,0% | 3,6% ± 2,9% |

| Classe | Antes | Depois |
|---|---|---|
| imbalance | 19,3% | **77,5%** |
| vertical-misalignment | 8,6% | 15,1% |
| horizontal-misalignment | 3,8% | 8,3% |

Note que a AUC global quase não se move (0,795 → 0,805) enquanto a detecção
no ponto de operação triplica. É a mesma lição da crítica A1, agora do lado
positivo: a AUC global não teria detectado esta melhoria.

**Verificação de paridade:** comparação numérica direta Python ↔ C++ em 15
casos (10 janelas reais do MAFAULDA + 5 sintéticos adversariais).
`dominant_freq_hz` bate exatamente (divergência 0); as demais features
divergem no máximo 5,1e-06. Testes de regressão espelhados nos dois lados:
9 testes C++ (eram 6), 35 Python (eram 32).

### O que a correção não resolveu

Desalinhamento continua praticamente invisível (8,3% e 15,1%). As quatro
features atuais medem amplitude e forma de onda; a assinatura clássica de
desalinhamento é a **razão entre as linhas de 2× e 1× rotação**, que nenhuma
delas captura. Próximo passo natural: features de energia em banda em torno
de 1× e 2× da rotação — o que exige conhecer a rotação (o MAFAULDA a traz no
tacômetro, coluna 0, hoje não usada; no dispositivo, viria de estimativa
espectral).

O falso alarme subiu de 1,8% para 3,6%, acima do alvo de 1%. Causa provável:
só 49 arquivos normais para dividir entre fit, calibração e validação — a
estimativa de quantil fica ruidosa. É um limite do dataset, não do método.

### Treino completo — 6 classes, 1951 arquivos, 17.559 janelas

Dataset inteiro ingerido: **31 GB de CSV bruto → 32 MB de cache**, bruto
descartado. `GroupKFold` por arquivo, 5 folds, limiar por quantil a 1% de
falso alarme alvo.

| Métrica | Valor |
|---|---|
| Falso alarme medido | 2,0% ± 1,3% |
| Detecção agregada | 42,6% ± 4,4% |
| F1 | 0,596 ± 0,043 |
| AUC global | 0,852 ± 0,022 |
| pAUC (FPR≤10%) | 0,752 ± 0,057 |

### O número agregado é enganoso — e o motivo confirma o item 1

A detecção agregada **subiu** ao acrescentar as classes de rolamento
(38,5% → 42,6%), o que contradiria a previsão do item 1. Investigando: o
MAFAULDA roda os ensaios de falha de rolamento **com massa de
desbalanceamento adicionada**, em quatro níveis (0g, 6g, 20g, 35g), e a
estrutura de diretórios é `overhang/ball_fault/20g/*.csv`.

A detecção acompanha a massa, não o defeito:

| Classe | 0g | 6g | 20g | 35g |
|---|---|---|---|---|
| underhang-bearing | **14,8%** | 46,2% | 82,0% | 87,3% |
| overhang-bearing | **20,7%** | 19,5% | 64,0% | 78,3% |

Na condição 0g — defeito de rolamento puro, sem desbalanceamento
sobreposto — a detecção cai para 14,8% e 20,7%, no mesmo patamar do
desalinhamento. O que o modelo detecta nos arquivos de rolamento é a massa
adicionada, não o defeito.

**Isso confirma o item 1 com dado real**, e acrescenta um alerta
metodológico: reportar "detecção de falha de rolamento: 56%" sem
estratificar pela massa adicionada seria exatamente o tipo de número
inflado que o item 6 e a crítica A2 alertam. O agregado de 42,6% tem o
mesmo problema.

### Quadro honesto do que o dispositivo detecta

| Classe | Detecção @ 2% falso alarme |
|---|---|
| imbalance | **75,0% ± 3,5%** |
| overhang-bearing (0g, puro) | 20,7% |
| underhang-bearing (0g, puro) | 14,8% |
| vertical-misalignment | 7,2% ± 4,3% |
| horizontal-misalignment | 5,0% ± 3,1% |

Só desbalanceamento é detectável de forma útil. Desalinhamento e defeito de
rolamento puro ficam perto do piso.

Para desalinhamento a causa é o vetor de features, não o sensor — a
assinatura é a razão 2×/1× rotação, que RMS, curtose, fator de crista e
frequência dominante não capturam. É corrigível sem trocar hardware.

Para rolamento a causa é a banda, como o item 1 previu por simulação e
estes dados agora confirmam. Não é corrigível por feature nenhuma.

### Consolidado num único repositório

`docs/`, `experiments/` e `figures/` viviam na raiz do workspace, fora do
repositório com remoto (`kaelix-firmware`), num repo git sem nenhum commit.
Todo o trabalho de análise — notebooks, figuras, monografia — estava
efetivamente fora de controle de versão.

Movidos para dentro de `kaelix-firmware/`, junto com `pyproject.toml`,
`uv.lock`, `.python-version` e este CHANGELOG. As três pastas mantiveram a
posição relativa entre si, então as referências cruzadas continuam válidas;
`docs/` foi **fundido** com o `docs/` do firmware (sem colisão de nomes —
`ARQUITETURA.md` convive com os demais).

- `.gitignore` unificado, com `.DS_Store`, caches de Jupyter e R, e os
  datasets brutos. O cache derivado em `data/cache/` (~32 MB) fica
  **versionado de propósito**: torna o treino reproduzível sem rebaixar
  12 GB do MAFAULDA.
- `pyproject.toml` renomeado de `lauan` para `kaelix`.
- Árvore do projeto no README atualizada.
- **Link quebrado corrigido**: `validacao-questionamentos.ipynb` apontava
  para `../docs/questionamentos-tecnicos.md`, que resolvia para
  `experiments/docs/` — quebrado desde antes do move. Agora `../../docs/`.

Verificação: 18 links relativos resolvem, 0 quebrados; `\graphicspath` da
monografia continua achando `figures/output/` e `docs/img/`; 35 testes
Python e 20 C++ passando; `export_thermal_data.py` reproduz os mesmos
44,8 °C documentados.

### Verificação

- `training/tests/`: **32 testes passando** (eram 10), incluindo o
  round-trip real treina → exporta → compila com g++ → compara contra
  `sklearn.score_samples`.
- `pio test -e native`: 17 testes C++ inalterados, revalidados aqui com um
  shim mínimo do Unity (o `pio` não estava instalado na máquina).
- Treino ponta-a-ponta em dados sintéticos: falso alarme 2,0% ± 1,7%
  (alvo 1%), detecção 100% ± 0%, em 5 folds de `GroupKFold`.
- Header exportado com o limiar calibrado (0,665, não mais 0,5 fixo)
  compila limpo com `-Wall -Wextra -Wpedantic` e produz a decisão esperada.
- O placeholder `src/ml/isolation_forest_data.h` (`N_TREES = 0`) foi
  **preservado** — exportar um modelo treinado em dados sintéticos para
  dentro do repositório seria pior que não ter modelo nenhum.

### Pendente (não coberto nesta rodada)

Correções de firmware levantadas na mesma auditoria seguem abertas — ver
`README.md`. As de maior impacto:

- SX1278 nunca entra em sleep; o orçamento de energia não tem termo de LoRa
  idle e o consumo médio real deve ficar ~6,5× acima do estimado.
- `platformio.ini` não declara os 16 MB de flash nem a PSRAM do N16R8.
- `LoraPacket` não tem identificação de dispositivo, e `timestamp = millis()`
  zera a cada deep sleep.
- Retornos de `*_init()` e de `lora_send()` são ignorados em `main.cpp`.

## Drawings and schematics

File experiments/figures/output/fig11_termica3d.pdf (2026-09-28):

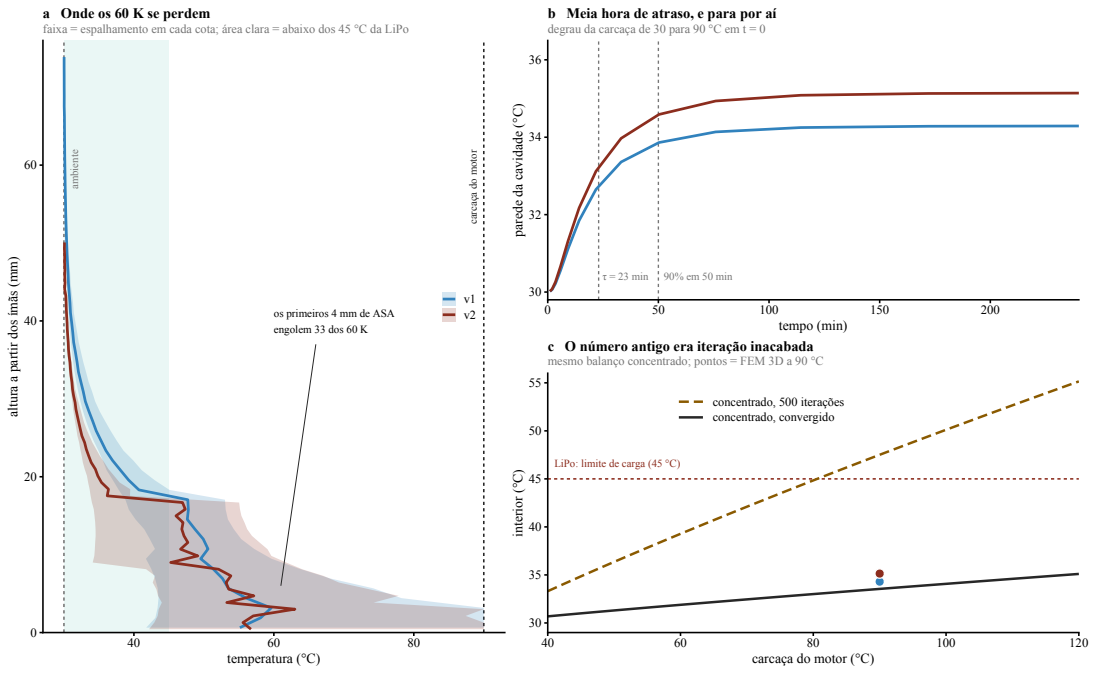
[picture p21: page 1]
ambiente; temperatura (°C); τ = 23 min; 90% em 50 min; tempo (min); interior (°C); concentrado, 500 iterações concentrado, convergido

a Onde os 60 K se perdem
faixa = espalhamento em cada cota; área clara = abaixo dos 45 °C da LiPo

b Meia hora de atraso, e para por aí
degrau da carcaça de 30 para 90 °C em t = 0

parede da cavidade (°C)

carcaça do motor

altura a partir dos ímãs (mm)

os primeiros 4 mm de ASA
engolem 33 dos 60 K

c O número antigo era iteração inacabada
mesmo balanço concentrado; pontos = FEM 3D a 90 °C

LiPo: limite de carga (45 °C)

carcaça do motor (°C)

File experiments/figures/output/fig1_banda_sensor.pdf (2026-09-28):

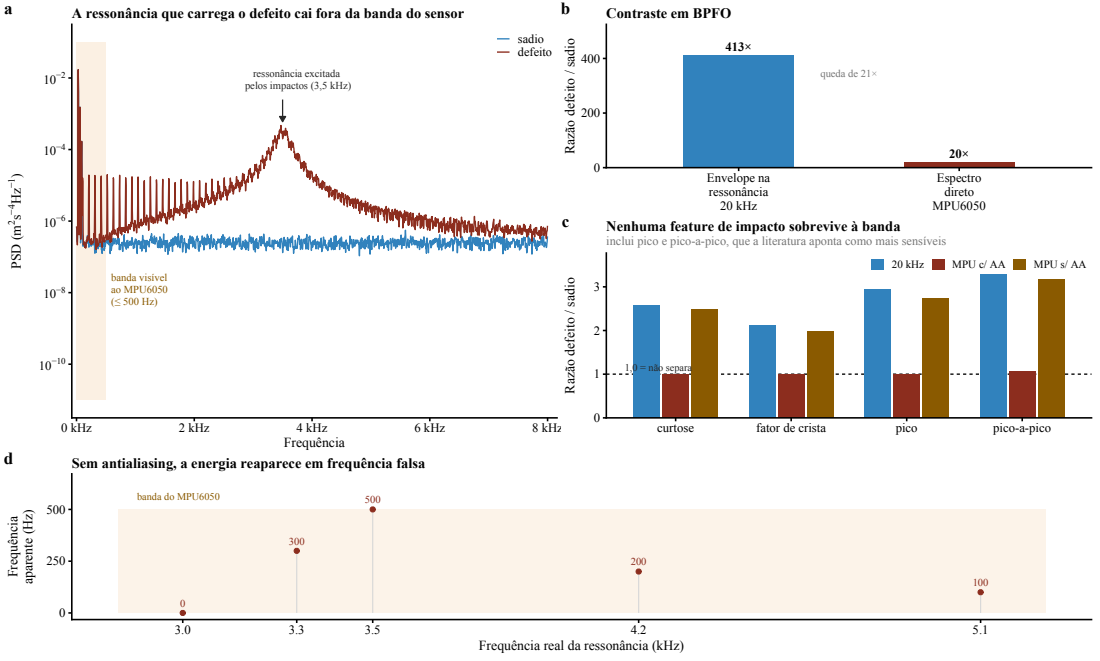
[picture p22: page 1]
banda visível ao MPU6050 (≤ 500 Hz); 0 kHz; 2 kHz; 4 kHz; 6 kHz; 8 kHz; Frequência; PSD (m2; sadio defeito; A ressonância que carrega o defeito cai fora da banda do sensor; queda de 21×; Envelope na ressonância 20 kHz; Espectro direto MPU6050; Contraste em BPFO; 1,0 = não separa; curtose; fator de crista; pico; pico-a-pico; 20 kHz; MPU c/ AA; MPU s/ AA; banda do MPU6050; aparente (Hz); Sem antialiasing, a energia reaparece em frequência falsa

Razão defeito / sadio

ressonância excitada
pelos impactos (3,5 kHz)

Nenhuma feature de impacto sobrevive à banda c

inclui pico e pico-a-pico, que a literatura aponta como mais sensíveis

Frequência real da ressonância (kHz)

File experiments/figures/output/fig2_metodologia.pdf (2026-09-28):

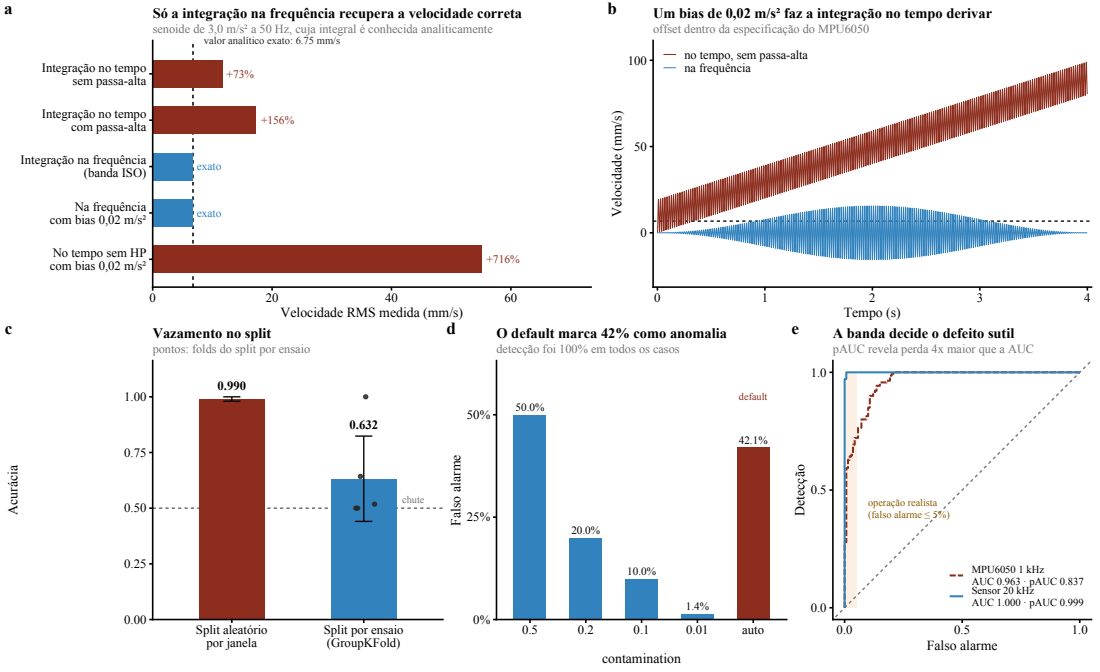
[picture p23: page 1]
exato; (banda ISO); Só a integração na frequência recupera a velocidade correta; Tempo (s); Velocidade (mm/s); Um bias de 0,02 m/s² faz a integração no tempo derivar; chute; Split aleatório por janela; Acurácia; default; auto; contamination; Falso alarme; O default marca 42% como anomalia; operação realista (falso alarme ≤ 5%); MPU6050 1 kHz AUC 0.963 · pAUC 0.837 Sensor 20 kHz AUC 1.000 · pAUC 0.999 0.0; Detecção

senoide de 3,0 m/s² a 50 Hz, cuja integral é conhecida analiticamente

offset dentro da especificação do MPU6050
no tempo, sem passa-alta
na frequência

valor analítico exato: 6.75 mm/s

Integração no tempo
sem passa-alta

com passa-alta

Integração na frequência

Na frequência
com bias 0,02 m/s²

No tempo sem HP

Velocidade RMS medida (mm/s)

Vazamento no split c

A banda decide o defeito sutil e

pontos: folds do split por ensaio

detecção foi 100% em todos os casos

pAUC revela perda 4x maior que a AUC

Split por ensaio
(GroupKFold)

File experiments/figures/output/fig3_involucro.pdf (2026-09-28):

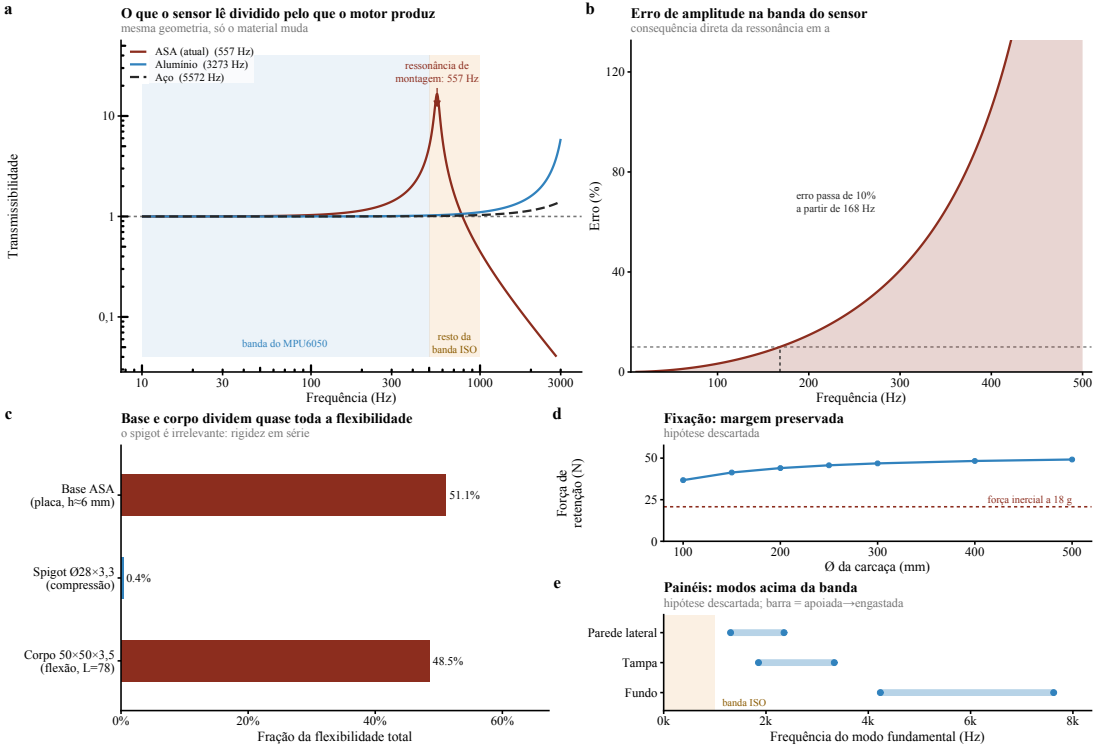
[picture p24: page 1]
banda do MPU6050; resto da; banda ISO; ressonância de montagem: 557 Hz; Frequência (Hz); Transmissibilidade; O que o sensor lê dividido pelo que o motor produz; Erro (%); Erro de amplitude na banda do sensor; 48.5% Corpo 50×50×3,5 (flexão, L=78); Spigot Ø28×3,3 (compressão); Base ASA (placa, h≈6 mm); força inercial a 18 g; Força de; retenção (N); hipótese descartada; Fixação: margem preservada; Tampa; Parede lateral

mesma geometria, só o material muda
ASA (atual) (557 Hz)
Alumínio (3273 Hz)
Aço (5572 Hz)

consequência direta da ressonância em a

erro passa de 10%
a partir de 168 Hz

Base e corpo dividem quase toda a flexibilidade c

o spigot é irrelevante: rigidez em série

Ø da carcaça (mm)

Painéis: modos acima da banda e

hipótese descartada; barra = apoiada→engastada

banda ISO Fundo

Fração da flexibilidade total

Frequência do modo fundamental (Hz)

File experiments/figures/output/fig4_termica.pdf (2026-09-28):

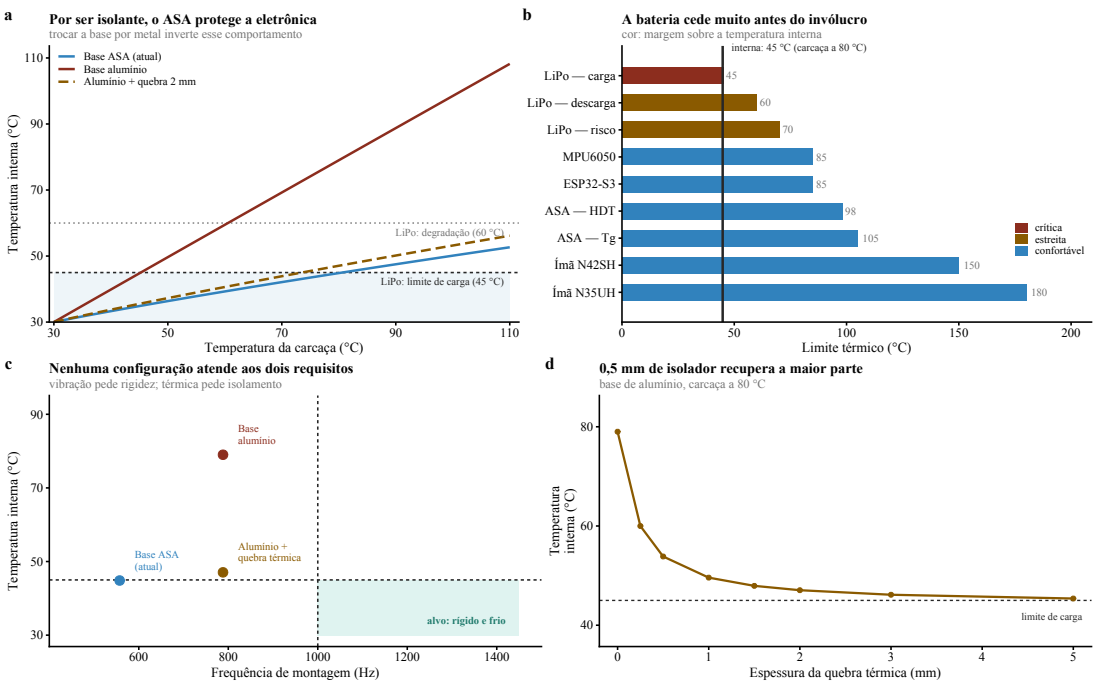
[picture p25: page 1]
LiPo: degradação (60 °C); Temperatura interna (°C); Por ser isolante, o ASA protege a eletrônica; interna: 45 °C (carcaça a 80 °C); Ímã N35UH; Ímã N42SH; ASA — Tg; ASA — HDT; ESP32-S3; MPU6050; LiPo — risco; LiPo — descarga; LiPo — carga; Limite térmico (°C); crítica estreita confortável; A bateria cede muito antes do invólucro; Base ASA (atual); Base alumínio; Alumínio + quebra térmica; 0,5 mm de isolador recupera a maior parte

trocar a base por metal inverte esse comportamento
Base ASA (atual)
Base alumínio
Alumínio + quebra 2 mm

cor: margem sobre a temperatura interna

LiPo: limite de carga (45 °C)

Nenhuma configuração atende aos dois requisitos c

Temperatura da carcaça (°C)

vibração pede rigidez; térmica pede isolamento

base de alumínio, carcaça a 80 °C

alvo: rígido e frio

limite de carga 40

Frequência de montagem (Hz)

Espessura da quebra térmica (mm)

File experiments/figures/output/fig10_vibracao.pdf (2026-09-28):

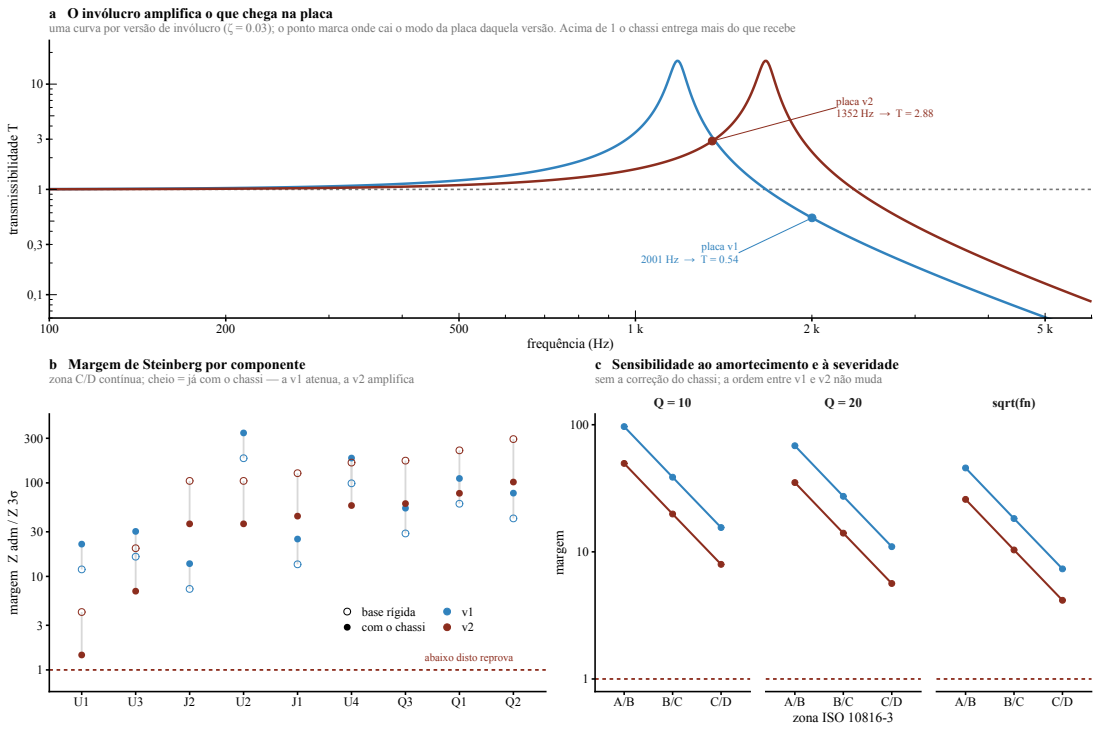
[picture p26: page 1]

a O invólucro amplifica o que chega na placa
uma curva por versão de invólucro (ζ = 0.03); o ponto marca onde cai o modo da placa daquela versão. Acima de 1 o chassi entrega mais do que recebe

b Margem de Steinberg por componente
zona C/D contínua; cheio = já com o chassi — a v1 atenua, a v2 amplifica

c Sensibilidade ao amortecimento e à severidade
sem a correção do chassi; a ordem entre v1 e v2 não muda

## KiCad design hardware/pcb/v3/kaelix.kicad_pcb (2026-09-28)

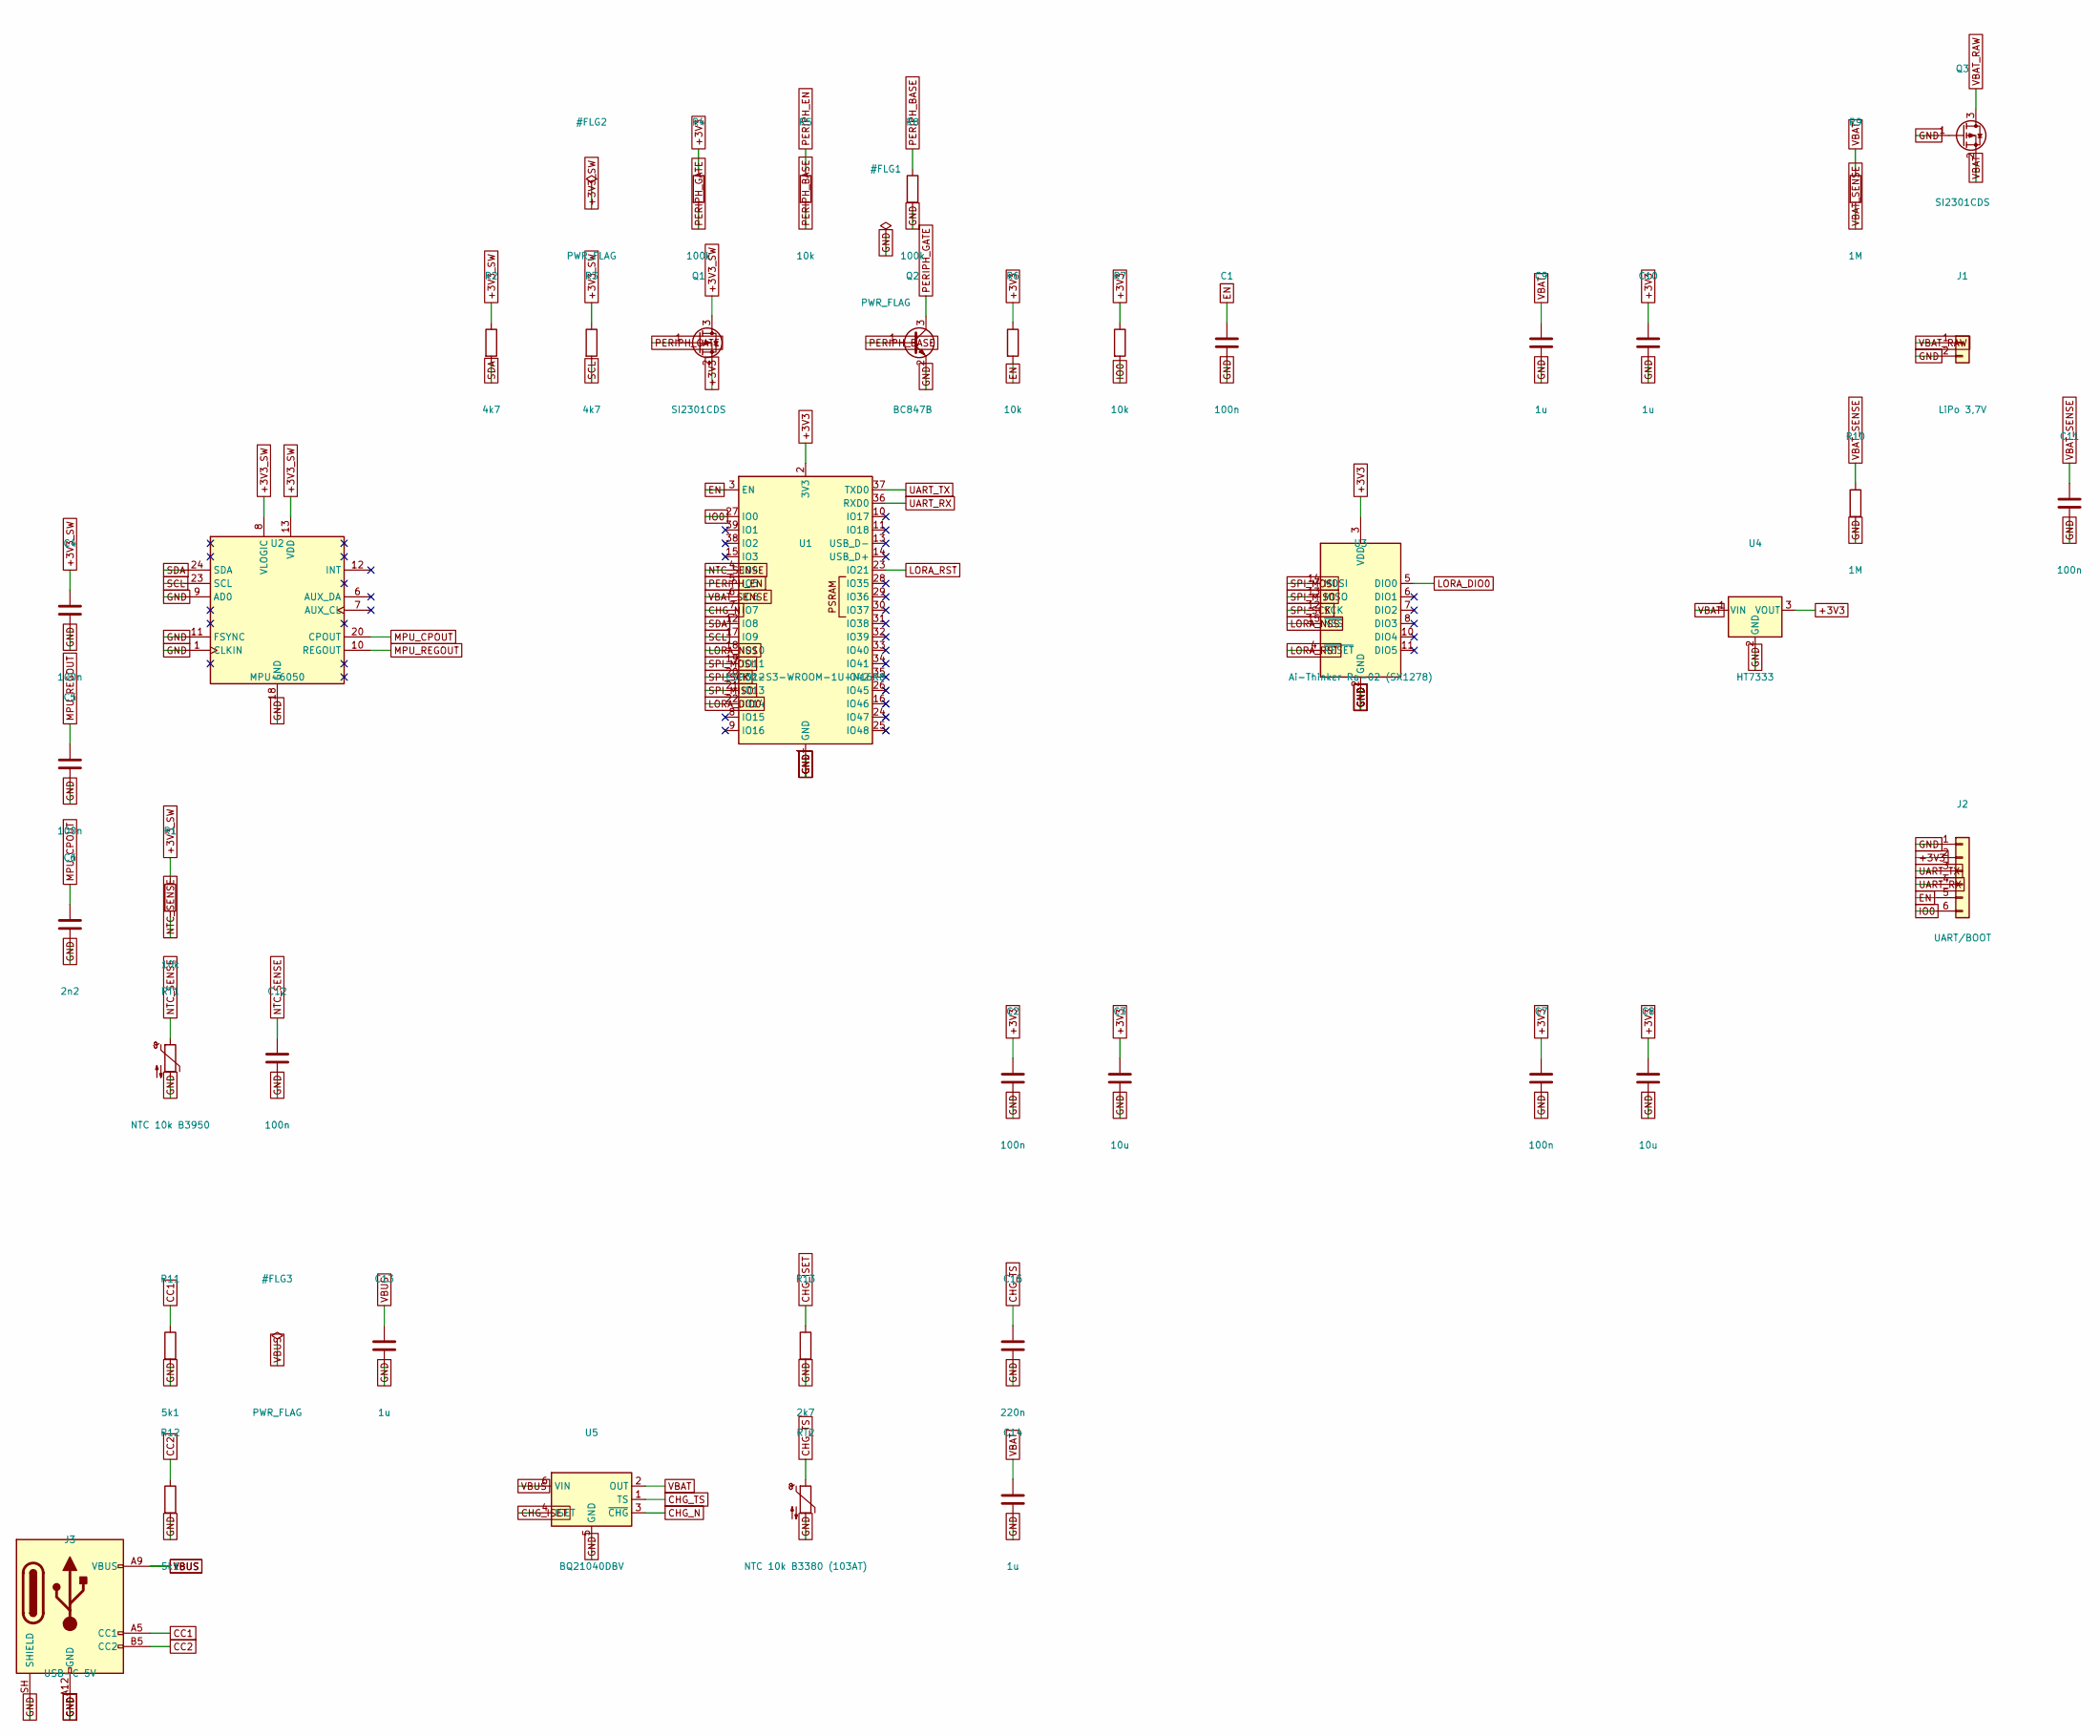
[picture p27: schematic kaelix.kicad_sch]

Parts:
C1, C2, C4, C5, C7, C11, C12: 100n; C_0805_2012Metric
C3, C8: 10u; C_0805_2012Metric
C6: 2n2; C_0805_2012Metric
C9, C10, C13, C14: 1u; C_0805_2012Metric
C15: 220n; C_0805_2012Metric
J1: LiPo 3,7V; JST_PH_S2B-PH-SM4-TB_1x02-1MP_P2.00mm_Horizontal
J2: UART/BOOT; PinHeader_1x06_P2.54mm_Vertical
J3: USB-C 5V; USB_C_Receptacle_GCT_USB4125-xx-x_6P_TopMnt_Horizontal
Q1, Q3: SI2301CDS; SOT-23
Q2: BC847B; SOT-23
R1, R5, R6, R7: 10k; R_0805_2012Metric
R2, R3: 4k7; R_0805_2012Metric
R4, R8: 100k; R_0805_2012Metric
R9, R10: 1M; R_0805_2012Metric
R11, R12: 5k1; R_0805_2012Metric
R13: 2k7; R_0805_2012Metric
RT1: NTC 10k B3950; R_0805_2012Metric
RT2: NTC 10k B3380 (103AT); R_0805_2012Metric
U1: ESP32-S3-WROOM-1U-N16R8; ESP32-S3-WROOM-1U
U2: MPU-6050; InvenSense_QFN-24_4x4mm_P0.5mm
U3: Ai-Thinker Ra-02 (SX1278); Ai-Thinker-Ra-01-LoRa
U4: HT7333; SOT-89-3
U5: BQ21040DBV; SOT-23-6

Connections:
+3V3: C2.1, C3.1, C7.1, C8.1, C10.1, J2.2, Q1.2 (S), R4.1, R6.1, R7.1, U1.2 (3V3), U3.3 (VDD), U4.3 (VOUT)
+3V3_SW: C4.1, Q1.3 (D), R1.1, R2.1, R3.1, U2.8 (VLOGIC), U2.13 (VDD)
CC1: J3.A5 (CC1), R11.1
CC2: J3.B5 (CC2), R12.1
CHG_ISET: R13.1, U5.4 (ISET)
CHG_N: U1.7 (IO7), U5.3 (~CHG)
CHG_TS: C15.1, RT2.1, U5.1 (TS)
EN: C1.1, J2.5, R6.2, U1.3 (EN)
GND: C1.2, C2.2, C3.2, C4.2, C5.2, C6.2, C7.2, C8.2, C9.2, C10.2, C11.2, C12.2, C13.2, C14.2, C15.2, J1.2, J2.1, J3.A12 (GND), J3.B12 (GND), J3.SH (SHIELD), Q2.2 (E), Q3.1 (G), R8.2, R10.2, R11.2, R12.2, R13.2, RT1.2, RT2.2, U1.1 (GND), U1.40 (GND), U1.41 (GND), U2.1 (CLKIN), U2.9 (AD0), U2.11 (FSYNC), U2.18 (GND), U3.1 (GND), U3.2 (GND), U3.9 (GND), U3.16 (GND), U4.2 (GND), U5.5 (GND)
IO0: J2.6, R7.2, U1.27 (IO0)
LORA_DIO0: U1.22 (IO14), U3.5 (DIO0)
LORA_NSS: U1.18 (IO10), U3.15 (~NSS)
LORA_RST: U1.23 (IO21), U3.4 (~RESET)
MPU_CPOUT: C6.1, U2.20 (CPOUT)
MPU_REGOUT: C5.1, U2.10 (REGOUT)
NTC_SENSE: C12.1, R1.2, RT1.1, U1.4 (IO4)
PERIPH_BASE: Q2.1 (B), R5.2, R8.1
PERIPH_EN: R5.1, U1.5 (IO5)
PERIPH_GATE: Q1.1 (G), Q2.3 (C), R4.2
SCL: R3.2, U1.17 (IO9), U2.23 (SCL)
SDA: R2.2, U1.12 (IO8), U2.24 (SDA)
SPI_MISO: U1.21 (IO13), U3.13 (MISO)
SPI_MOSI: U1.19 (IO11), U3.14 (MOSI)
SPI_SCK: U1.20 (IO12), U3.12 (SCK)
UART_RX: J2.4, U1.36 (RXD0)
UART_TX: J2.3, U1.37 (TXD0)
VBAT: C9.1, C14.1, Q3.2 (S), R9.1, U4.1 (VIN), U5.2 (OUT)
VBAT_RAW: J1.1, Q3.3 (D)
VBAT_SENSE: C11.1, R9.2, R10.1, U1.6 (IO6)
VBUS: C13.1, J3.A9 (VBUS), J3.B9 (VBUS), U5.6 (VIN)

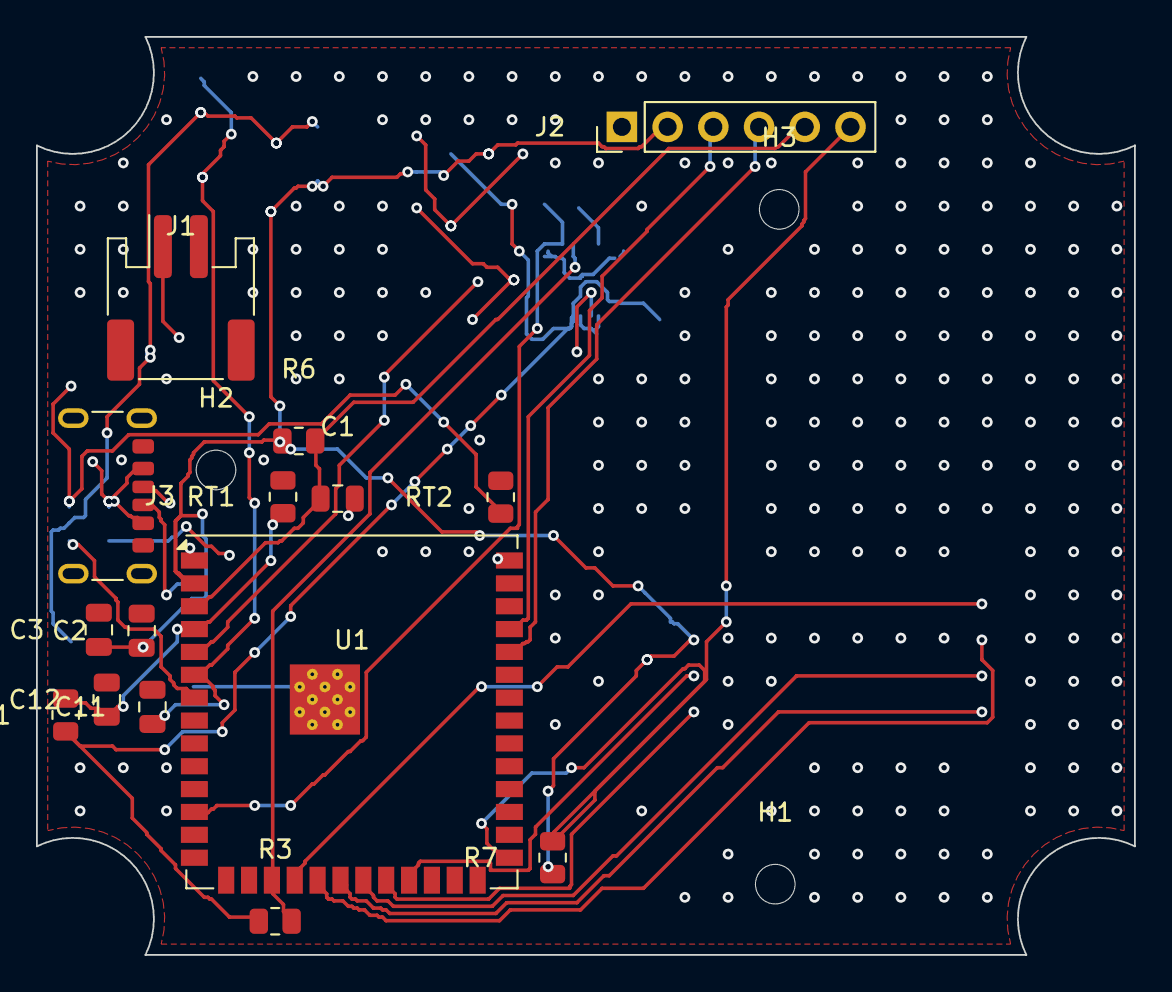
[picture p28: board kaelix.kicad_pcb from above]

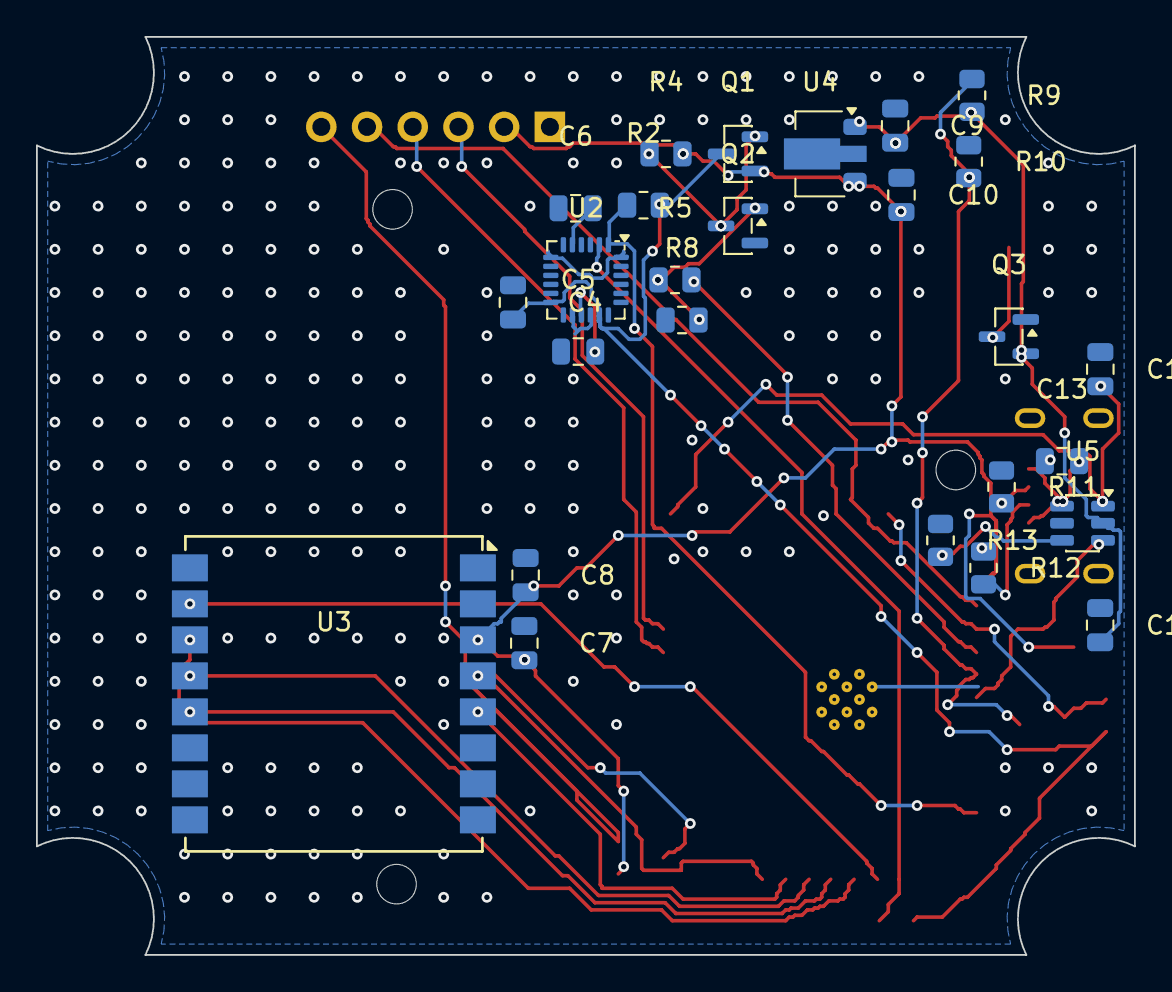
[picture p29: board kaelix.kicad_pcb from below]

Board: 2 copper layers, 61.0 x 51.0 mm, 44 parts (26 on the bottom side), 30 nets.

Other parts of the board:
H1, H2, H3: M2; MountingHole_2.2mm_M2

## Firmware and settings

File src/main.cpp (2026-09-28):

#include "machine_state.h"
#include "comms/lora.h"
#include "ml/model.h"
#include "power/sleep.h"
#include "power/watchdog.h"
#include "sensors/temperature.h"
#include "sensors/vibration.h"

#include "crc16.h"
#include "kaelix_status.h"

#include <Arduino.h>

#include <cstddef>
#include <cstdint>
#include <limits>

// Kaelix — ciclo principal: acordar → ler sensores → processar → inferir
// → transmitir (LoRa) → dormir o rádio → cortar periféricos → deep sleep.
// Ver README.md para a visão geral de cada módulo e o porquê das decisões,
// docs/ARQUITETURA-SOFTWARE.md §5-§6 para a política de erro e o estado
// seguro, e docs/ANALISE-DE-FALHAS.md §5-§6 para os modos de falha que
// cada verificação daqui fecha.
//
// Este arquivo é a ÚNICA camada que decide. `sensors`, `ml`, `comms` e
// `power` relatam com `kaelix::Status`; o que fazer com cada relato —
// degradar, pular fase, transmitir, entrar no estado seguro — é decisão
// de L3 e mora aqui.

// Sem `using namespace`: main.cpp inclui todos os módulos e é o arquivo
// mais exposto a colisão de nomes (MISRA C++ 7-3-4). Aliases mantêm a
// origem de cada nome visível sem a verbosidade.
namespace ksens = kaelix::sensors;
namespace kml = kaelix::ml;
namespace kcomms = kaelix::comms;
namespace kpower = kaelix::power;

using kaelix::MachineState;
using kaelix::Status;

// O log serial é bancada e Fase 3, não operação: em campo não há ninguém
// com um cabo USB, e a UART custa energia na janela ativa que o orçamento
// de src/power/sleep.cpp não contabiliza. O canal de diagnóstico de
// produção é o byte `diag` do pacote LoRa.
#if !defined(KAELIX_LOG_SERIAL)
#  if defined(KAELIX_PRODUCTION)
#    define KAELIX_LOG_SERIAL 0
#  else
#    define KAELIX_LOG_SERIAL 1
#  endif
#endif

namespace {

// ---------------------------------------------------------------------
// Configuração do ciclo
// ---------------------------------------------------------------------

// O tamanho do bloco vem da constante que governa a cadeia inteira, em
// lib/signal_processing — não de um número solto repetido aqui.
constexpr uint16_t VIBRATION_SAMPLES_PER_CYCLE = static_cast<uint16_t>(ksens::VIBRATION_SAMPLES);
static_assert((VIBRATION_SAMPLES_PER_CYCLE & (VIBRATION_SAMPLES_PER_CYCLE - 1U)) == 0U,
              "FFT radix-2 exige potência de 2");
static_assert(VIBRATION_SAMPLES_PER_CYCLE <= ksens::VIBRATION_MAX_SAMPLES,
              "o bloco pedido não cabe no buffer estático de amostras");

// 12 e não 10 minutos. O período é o parâmetro que fecha REQ-PWR-06
// (autonomia >= 8 meses) sem tocar no enlace: a 10 min o projeto entregava
// ~236 dias (7,7 meses) e o requisito ficava em falha aritmética, não de
// medição — ele passou a não ser atendido quando os 150 ms estimados de
// tempo no ar viraram 185 ms calculados para SF9. A 12 min são ~269 dias
// (8,8 meses).
//
// O custo é latência de detecção: uma falha que comece logo após uma
// transmissão demora até um período para ser vista. Para vibração em
// motor industrial isso é irrelevante — a evolução de desbalanceamento e
// desalinhamento se mede em dias, não em minutos.
//
// A folga também é o que torna SF10 viável (~243 dias, ainda >= 8 meses)
// se o levantamento de RSSI em planta exigir os 2,5 dB extras de ganho de
// enlace. A 10 min, SF10 dava ~211 dias e a decisão de alcance ficava
// travada pelo orçamento de energia.
constexpr uint32_t SLEEP_MINUTES = 12U;

// Período estendido do estado seguro por escalada. Ver ESCALADA, abaixo.
constexpr uint32_t QUARANTINE_SLEEP_MINUTES = 60U;

constexpr uint16_t MAX_ABNORMAL_RESETS = 4U;

// O MPU6050 precisa estabilizar depois de o rail +3V3_SW subir.
constexpr uint32_t PERIPHERAL_SETTLE_MS = 100U;

// WDT-3: cota de software da fase ativa. Fica ABAIXO da janela do Task
// WDT (6 s) de propósito — é a rede que pega o atraso ANTES do watchdog,
// para que o dispositivo chegue ao estado seguro de forma ordenada, com o
// rádio adormecido, em vez de ser resetado com o rádio em standby a
// 1,5 mA. O nominal da fase ativa é ~1,6 s, então há mais de 3x de folga.
constexpr uint32_t CYCLE_DEADLINE_MS = 5000U;
static_assert(CYCLE_DEADLINE_MS < kpower::WATCHDOG_TASK_TIMEOUT_S * 1000U,
              "a cota de software precisa disparar antes do Task WDT");

// Uma retentativa, não um laço até funcionar: cada tentativa custa o pico
// de ~90 mA do orçamento, e o gateway percebe a ausência pela lacuna na
// sequência de boot_count.
constexpr uint8_t TX_MAX_ATTEMPTS = 2U;

// Sentinela de "não medido". NaN e não 0.0f porque 0 é uma leitura
// perfeitamente plausível tanto de RMS quanto de temperatura — um
// sentinela que se disfarça de medição é a falha silenciosa que este
// firmware existe para eliminar.
constexpr float MEASUREMENT_INVALID = std::numeric_limits<float>::quiet_NaN();

// ---------------------------------------------------------------------
// Estado que atravessa o sono
// ---------------------------------------------------------------------
//
// RTC_NOINIT_ATTR e não RTC_DATA_ATTR: o bootloader RECARREGA a seção
// .rtc.data a partir da imagem em qualquer boot que não seja despertar de
// deep sleep. Ou seja, um reset por watchdog, brownout ou pânico zerava o
// boot_count — o contador apagava justamente a evidência de que o
// dispositivo estava instável, que é a informação de manutenção mais
// valiosa que ele tem a dar (FM-33).
//
// Em troca, .noinit tem conteúdo ARBITRÁRIO depois de um power-on, e
// precisa ser reconhecido como inválido: daí a palavra mágica e o CRC-16,
// calculado com o mesmo lib/crc16 já testado que protege o pacote.
struct RetainedState {
    uint32_t magic;
    uint32_t boot_count;
    uint16_t abnormal_reset_count; // resets anormais consecutivos
    uint8_t  last_status;          // Status do ciclo anterior, para o próximo pacote
    uint8_t  reserved;             // alinhamento explícito: o CRC só cobre bytes definidos
    uint16_t crc;                  // CRC-16/CCITT sobre os campos acima
};

constexpr uint32_t RETAINED_MAGIC = 0x4B4C5831UL; // "KLX1"
static_assert(offsetof(RetainedState, crc) == 12U,
              "a região coberta pelo CRC mudou — o estado retido de campo deixaria de conferir");

RTC_NOINIT_ATTR RetainedState s_retained;

// Deslocamento anticolisão do despertar.
//
// Sem ele, dispositivos energizados juntos — o que acontece numa
// instalação — acordam no mesmo instante a cada 12 minutos e colidem de
// forma SISTEMÁTICA, não estatística. O cálculo de probabilidade de
// colisão em ALOHA (1,0% para 20 dispositivos e 2,5% para 50, com 185 ms
// no ar e período de 720 s) pressupõe
// fases aleatórias, e uma instalação simultânea não tem fase aleatória.
//
// device_id separa dispositivos entre si; boot_count faz o deslocamento
// variar a cada ciclo, para que dois aparelhos que caiam no mesmo resto
// não fiquem colidindo para sempre. Determinístico e sem estado extra:
// os dois valores já existem e já vão dentro do pacote.
uint32_t transmission_jitter_seconds() {
    return (kcomms::device_id() + s_retained.boot_count) % kpower::JITTER_MAX_SECONDS;
}


uint16_t retained_crc() {
    return kcomms::crc16_ccitt(reinterpret_cast<const uint8_t*>(&s_retained),
                               offsetof(RetainedState, crc));
}

void retained_seal() {
    s_retained.crc = retained_crc();
}

// Devolve RtcStateCorrupt quando o bloco não confere SEM ser a primeira
// energização. Distinguir os dois casos importa: sem isso, todo
// dispositivo novo reportaria corrupção no primeiro pacote da vida, e o
// código perderia o significado justamente por excesso de uso.
Status retained_load(bool power_on) {
    if (s_retained.magic == RETAINED_MAGIC && s_retained.crc == retained_crc()) {
        return Status::Ok;
    }

    s_retained.magic = RETAINED_MAGIC;
    s_retained.boot_count = 0U;
    s_retained.abnormal_reset_count = 0U;
    s_retained.last_status = kaelix::status_code(Status::Ok);
    s_retained.reserved = 0U;
    retained_seal();

    return power_on ? Status::Ok : Status::RtcStateCorrupt;
}

// ---------------------------------------------------------------------
// Log
// ---------------------------------------------------------------------
// Formato fixo, uma linha por fase, sem texto livre: a string vem de
// status_to_string() e é literal em .rodata. Texto livre num log de
// campo é o que fazia "rádio LoRa não inicializou" cobrir quatro
// deslocamentos de manutenção diferentes.

#if KAELIX_LOG_SERIAL
void log_phase(const char* phase, Status status) {
    Serial.print("[kaelix] ");
    Serial.print(phase);
    Serial.print(' ');
    Serial.println(kaelix::status_to_string(status));
}

void log_cycle(Status status, MachineState state, uint32_t boot_count) {
    Serial.print("[kaelix] cycle ");
    Serial.print(kaelix::status_to_string(status));
    Serial.print(' ');
    Serial.print(kaelix::machine_state_to_string(state));
    Serial.print(" boot=");
    Serial.println(boot_count);
    // Sem flush, a UART é cortada no meio da última linha pelo deep
    // sleep — justamente a linha que diz por que o ciclo terminou assim.
    Serial.flush();
}
#else
void log_phase(const char*, Status) {}
void log_cycle(Status, MachineState, uint32_t) {}
#endif

// Alimenta o WDT-2 numa junção de fases. O retorno entra no acumulador
// como qualquer outro: um watchdog que não aceita ser alimentado é um
// watchdog que vai resetar o dispositivo no meio do ciclo.
Status feed_watchdog(Status accumulated) {
    return kaelix::status_first_error(accumulated, kpower::watchdog_feed());
}

// ---------------------------------------------------------------------
// Estado seguro (ESK)
// ---------------------------------------------------------------------
// Não é "desligado": um dispositivo desligado para de monitorar a máquina,
// e a máquina continua girando. É quieto, de baixíssimo consumo e
// reagendado — preserva a bateria, preserva a capacidade de tentar de
// novo no próximo período, e não afirma nada enquanto isso.
[[noreturn]] void enter_safe_state(Status cycle_status, MachineState state,
                                   uint32_t sleep_minutes) {
    Status status = cycle_status;

    // ESK passo 1: o rádio precisa CONFIRMAR que dormiu. Sem isso ele fica
    // em standby a 1,5 mA durante o período inteiro — 910 mA·s por ciclo,
    // 5,5x o orçamento do dispositivo — e o único sintoma é a bateria
    // durar ~45 dias em vez de ~241.
    const Status radio_sleep = kcomms::lora_sleep();
    log_phase("rf_sleep", radio_sleep);
    status = kaelix::status_first_error(status, radio_sleep);

    // ESK passo 2: trilha dos periféricos cortada.
    const Status peripherals = kpower::peripherals_power(false);
    log_phase("pwr_off", peripherals);
    status = kaelix::status_first_error(status, peripherals);

    // ESK passo 3: hold do GPIO, WDT-1 cobrindo o sono, timer armado.
    const Status prepared = kpower::sleep_prepare(sleep_minutes, transmission_jitter_seconds());
    log_phase("sleep", prepared);
    status = kaelix::status_first_error(status, prepared);

    // Este ciclo já não tem como contar o que houve daqui para a frente —
    // o rádio está dormindo. Fica registrado para o PRÓXIMO pacote: é
    // assim que um RadioSleepFailed chega ao gateway.
    s_retained.last_status = kaelix::status_code(status);
    retained_seal();

    log_cycle(status, state, s_retained.boot_count);

    kpower::deep_sleep_now();
}

} // namespace

void setup() {
#if KAELIX_LOG_SERIAL
    Serial.begin(115200);
#endif

    // Primeira coisa do ciclo, antes de energizar qualquer periférico
    // (REQ-SEG-32): a partir daqui, um travamento em qualquer ponto — I2C
    // sem resposta, radio.transmit() bloqueado, laço de árvore corrompida
    // — tem quem o interrompa. Sem watchdog, o dispositivo fica acordado a
    // ~40 mA e esvazia 2000 mAh em ~2 dias, contra os ~241 dias de
    // projeto, sem nenhum caminho de volta.
    const Status watchdog = kpower::watchdog_arm_active_phase();
    log_phase("wdt", watchdog);

    // O status do watchdog entra no acumulador só no fim do ciclo, e não
    // aqui: ele é uma propriedade do BUILD (a API do RTC WDT existe ou não
    // existe no core instalado), não um evento deste ciclo. Somado
    // primeiro, ele venceria o "primeiro erro vence" em todos os pacotes e
    // esconderia justamente as falhas de sensor que o campo precisa ver.
    Status cycle = Status::Ok;

    const uint32_t started_ms = millis();

    // Causa do reset e estado retido, antes de qualquer decisão.
    const Status reset_cause = kpower::reset_cause_status();
    log_phase("reset", reset_cause);
    const Status rtc_state = retained_load(kpower::reset_was_power_on());
    log_phase("rtc", rtc_state);

    ++s_retained.boot_count;
    if (kaelix::is_error(reset_cause)) {
        ++s_retained.abnormal_reset_count;
    } else {
        s_retained.abnormal_reset_count = 0U;
    }
    retained_seal();

    cycle = kaelix::status_first_error(cycle, reset_cause);
    cycle = kaelix::status_first_error(cycle, rtc_state);

    // O status do ciclo ANTERIOR entra no diagnóstico deste pacote, mas
    // não no acumulador: se entrasse, ele voltaria a ser gravado no estado
    // retido ao final e seria retransmitido para sempre.
    const Status carried = static_cast<Status>(s_retained.last_status);

    // ESCALADA (REQ-SEG-33): quatro resets anormais seguidos significam
    // que repetir o ciclo a cada 12 min não está resolvendo. O período
    // estendido é o que torna o estado seguro SUSTENTÁVEL — o dispositivo
    // sobrevive semanas anunciando o próprio defeito, em vez de horas
    // tentando. Um reset em laço a ~40 mA esvazia a bateria em ~50 h:
    // watchdog sem escalada troca um travamento por uma morte mais rápida.
    const uint32_t sleep_minutes = (s_retained.abnormal_reset_count >= MAX_ABNORMAL_RESETS)
                                       ? QUARANTINE_SLEEP_MINUTES
                                       : SLEEP_MINUTES;

    cycle = kaelix::status_first_error(cycle, kpower::peripherals_power(true));
    delay(PERIPHERAL_SETTLE_MS);
    cycle = feed_watchdog(cycle);

    // RECUPERAÇÃO: um boot que veio de watchdog, pânico ou brownout NÃO
    // repete o ciclo que acabou de travar — repetir é o laço de reset. A
    // fase de medição é pulada; o pacote sai mesmo assim, porque um
    // dispositivo que se cala é indistinguível de um dispositivo fora de
    // alcance (INV-5, "sempre audível").
    const bool recovery = kaelix::is_error(reset_cause);

    MachineState state = MachineState::Unknown;
    float rms = MEASUREMENT_INVALID;
    float temperature_c = MEASUREMENT_INVALID;

    if (!recovery) {
        ksens::VibrationFeatures features{};

        Status vibration = ksens::vibration_init();
        log_phase("vib_init", vibration);
        if (kaelix::is_ok(vibration)) {
            vibration = ksens::vibration_read_features(VIBRATION_SAMPLES_PER_CYCLE, &features);
            log_phase("vib_read", vibration);
        }
        cycle = kaelix::status_first_error(cycle, vibration);
        cycle = feed_watchdog(cycle);

        Status temperature = ksens::temperature_init();
        if (kaelix::is_ok(temperature)) {
            temperature = ksens::temperature_read_celsius(&temperature_c);
        }
        log_phase("temp", temperature);
        cycle = kaelix::status_first_error(cycle, temperature);
        cycle = feed_watchdog(cycle);

        Status model = kml::model_init();
        log_phase("model", model);
        // A inferência só roda com features VÁLIDAS. Sem elas não há
        // veredito: `state` fica Unknown e o pacote carrega o porquê. É
        // este `if` que impede o pior desfecho possível deste projeto —
        // um pacote bem formado, com CRC correto, dizendo "máquina sadia"
        // a partir de um buffer de zeros de um acelerômetro que não
        // existe.
        if (kaelix::is_ok(model) && kaelix::is_ok(vibration)) {
            model = kml::model_infer(features, temperature_c, &state);
            log_phase("infer", model);
        }
        cycle = kaelix::status_first_error(cycle, model);

        if (kaelix::is_ok(vibration)) {
            rms = features.rms;
        }
        cycle = feed_watchdog(cycle);
    }

    // WDT-3. A subtração de unsigned é segura na volta do contador, e
    // millis() zera a cada boot — o que se mede aqui é a fase ativa deste
    // ciclo, não tempo de parede.
    const bool deadline_exceeded = (millis() - started_ms) > CYCLE_DEADLINE_MS;
    if (deadline_exceeded) {
        cycle = kaelix::status_first_error(cycle, Status::CycleDeadlineExceeded);
        log_phase("deadline", Status::CycleDeadlineExceeded);
    }

    // O rádio é inicializado MESMO com o prazo estourado, e isso é
    // deliberado: `lora_sleep()` fala com o SX1278 pelo SPI, e quem
    // configura o SPI é o begin() do RadioLib. Pular a inicialização para
    // "economizar tempo" deixaria o rádio em standby a 1,5 mA durante os
    // 12 minutos de sono — 6,3x o orçamento do ciclo, para poupar ~100 ms.
    // O que o prazo estourado corta é a TRANSMISSÃO, não o caminho que
    // leva ao estado seguro.
    Status radio = kcomms::lora_init();
    log_phase("rf_init", radio);

    // Prazo estourado ⇒ estado seguro imediato, sem transmitir: a fase
    // ativa é cortada onde estiver, e o que ficou pendente aparece no
    // pacote do próximo ciclo.
    if (kaelix::is_ok(radio) && !deadline_exceeded) {
        // O diagnóstico do pacote é o primeiro erro DESTE ciclo, ou o do
        // anterior se este correu limpo.
        const Status diag = kaelix::status_first_error(cycle, carried);

        kcomms::LoraPacket packet{};
        radio = kcomms::make_packet(state, diag, rms, temperature_c,
                                    s_retained.boot_count, &packet);
        if (kaelix::is_ok(radio)) {
            for (uint8_t attempt = 0U; attempt < TX_MAX_ATTEMPTS; ++attempt) {
                radio = kcomms::lora_send(packet);
                if (kaelix::is_ok(radio)) {
                    break;
                }
            }
            log_phase("tx", radio);
        }
    }
    cycle = kaelix::status_first_error(cycle, radio);
    cycle = feed_watchdog(cycle);
    cycle = kaelix::status_first_error(cycle, watchdog);

    enter_safe_state(cycle, state, sleep_minutes);
}

void loop() {
    // Não utilizado — o dispositivo nunca sai do estado seguro em setup(),
    // que termina em deep sleep.
}

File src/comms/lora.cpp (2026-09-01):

#include "lora.h"

#include "../machine_state.h"

#include "crc16.h"
#include "kaelix_status.h"

#include <Arduino.h>
#include <RadioLib.h>

#include <cstdint>

// RA-02 (SX1278) via SPI. Pinos e potência de TX são placeholders — o
// código compila e a lógica pode ser revisada sem hardware, mas só
// será validado de fato (alcance, taxa de perda) na Fase 3, em campo.
// TODO: confirmar pinos contra o esquemático final.

namespace kaelix::comms {
namespace {

constexpr int8_t LORA_CS_PIN = 10;   // NSS (SPI SS padrão do esp32-s3-devkitc-1)
constexpr int8_t LORA_DIO0_PIN = 14; // DIO0 (IRQ) — não usar 8/9 (I2C do MPU6050)
constexpr int8_t LORA_RST_PIN = 21;  // RESET — não usar 8/9 (I2C do MPU6050)
constexpr float LORA_FREQUENCY_MHZ = 433.0f;
constexpr int8_t LORA_TX_POWER_DBM = 17;

// ---------------------------------------------------------------------
// Parâmetros do enlace, fixados explicitamente.
//
// Antes o código chamava begin() só com a frequência, e SF, largura de
// banda, coding rate, syncWord e preâmbulo ficavam nos defaults do
// RadioLib. Isso é ruim por dois motivos: o tempo no ar entra direto no
// orçamento de energia, e uma atualização da biblioteca mudaria o
// consumo do produto em silêncio.
//
// Alcance e autonomia são o mesmo botão. Para o pacote de 20 bytes,
// BW 125 kHz, CR 4/5, com LiPo de 2000 mAh:
//
//   SF7    57 ms no ar   256 dias    alcance de referência
//   SF8   103 ms         249 dias    +2,5 dB
//   SF9   185 ms         236 dias    +5,0 dB
//   SF10  371 ms         211 dias    +7,5 dB
//   SF12 1319 ms         138 dias    +12,5 dB
//
// SF9 é o meio-termo: 5 dB de margem sobre SF7 custando 20 dias de
// autonomia. A escolha definitiva depende da distância real entre os
// motores da Skala e o gateway, que ainda não foi medida — quando for,
// reveja esta tabela em vez de aceitar o default.
//
// CR 4/5 em vez do 4/7 default: menos redundância de canal, 18% menos
// tempo no ar. O pacote já tem CRC-16 próprio, então erro de bit é
// detectado na aplicação; gastar bateria com correção de canal para um
// payload de 20 bytes que pode ser reenviado no ciclo seguinte é troca
// ruim.
//
// syncWord separa esta rede de outras que compartilhem a frequência. O
// valor 0x12 é o de rede privada; 0x34 é reservado para LoRaWAN.
constexpr uint8_t LORA_SPREADING_FACTOR = 9U;
constexpr float LORA_BANDWIDTH_KHZ = 125.0f;
constexpr uint8_t LORA_CODING_RATE = 5U;    // 4/5
constexpr uint8_t LORA_SYNC_WORD = 0x12U;   // rede privada
constexpr uint16_t LORA_PREAMBLE_SYMBOLS = 8U;

// Tempo no ar calculado para os parâmetros acima, usado no orçamento de
// energia (ver README). Se qualquer parâmetro mudar, este número muda.
constexpr uint32_t LORA_AIRTIME_MS = 185U;

// Pulso de reset do SX1278: o datasheet pede RST em nível baixo por mais
// de 100 µs e 5 ms de espera antes do primeiro acesso.
constexpr uint32_t LORA_RESET_PULSE_MS = 1;
constexpr uint32_t LORA_RESET_SETTLE_MS = 5;

// Cota fixa de tentativas de adormecer o rádio. É um laço com limite
// constante, não um "tenta até dar certo": cada tentativa custa tempo na
// janela ativa, e um rádio que não responde a três tentativas com reset
// entre elas não vai responder à quarta.
constexpr uint8_t LORA_SLEEP_MAX_ATTEMPTS = 3;

// ---------------------------------------------------------------------
// Sem heap: por que estes dois objetos e não `new Module(...)`
// ---------------------------------------------------------------------
// O construtor do SX1278 exige um `Module*`, mas NÃO exige que ele venha
// de `new` — um objeto de duração estática serve, e é isto que elimina a
// única alocação dinâmica deste módulo. Avaliação registrada porque o
// desvio DEV-001 do documento de arquitetura dependia dela: a alocação
// era EVITÁVEL, então não há desvio a justificar, há código a corrigir.
//
// O que `new` custava: um ponteiro nunca conferido (com -fno-exceptions a
// falha vira abort() antes de qualquer log existir, indistinguível de um
// brick) e uma alocação durante a inicialização estática, antes de
// setup().
//
// Ordem de inicialização: ambos têm duração estática e são construídos na
// inicialização dinâmica desta unidade de tradução. Nenhuma outra unidade
// os toca — são `static` no escopo anônimo e só as funções abaixo os
// alcançam, todas chamadas a partir de setup(). A dependência de ordem
// entre unidades de tradução que JSF++ proíbe, portanto, não existe aqui
// por construção, e não por coincidência.
Module lora_module(LORA_CS_PIN, LORA_DIO0_PIN, LORA_RST_PIN);
SX1278 radio(&lora_module);

bool s_initialized = false;

// Traduz o código do RadioLib para o vocabulário de falha do projeto.
// `fallback` é o que o chamador considera a causa genérica da SUA fase:
// um código desconhecido durante o begin() não é uma falha de
// transmissão, e vice-versa — um mapeamento único e cego perderia essa
// distinção justamente onde ela orienta a manutenção.
kaelix::Status from_radiolib(int16_t state, kaelix::Status fallback) {
    switch (state) {
        case RADIOLIB_ERR_NONE:
            return kaelix::Status::Ok;
        case RADIOLIB_ERR_CHIP_NOT_FOUND:
            return kaelix::Status::RadioAbsent;      // sem VCC, sem antena de fato: chip mudo
#if defined(RADIOLIB_ERR_SPI_WRITE_FAILED)
        case RADIOLIB_ERR_SPI_WRITE_FAILED:
            return kaelix::Status::RadioBusSilent;   // CS/SCK/MOSI/MISO
#endif
#if defined(RADIOLIB_ERR_SPI_CMD_FAILED)
        case RADIOLIB_ERR_SPI_CMD_FAILED:
            return kaelix::Status::RadioBusSilent;
#endif
        case RADIOLIB_ERR_INVALID_FREQUENCY:
        case RADIOLIB_ERR_INVALID_OUTPUT_POWER:
        case RADIOLIB_ERR_INVALID_BANDWIDTH:
        case RADIOLIB_ERR_INVALID_SPREADING_FACTOR:
        case RADIOLIB_ERR_INVALID_CODING_RATE:
            return kaelix::Status::RadioConfigRejected; // bug de firmware, não defeito de peça
        case RADIOLIB_ERR_TX_TIMEOUT:
            return kaelix::Status::RadioTxTimeout;
        case RADIOLIB_ERR_PACKET_TOO_LONG:
            return kaelix::Status::PayloadTooLong;
        default:
            return fallback;
    }
}

// Pulso de reset por GPIO em vez de radio.reset(): o método existe na
// família SX127x, mas a superfície de API do RadioLib varia entre
// versões, e o pulso é uma linha do datasheet. Depender do datasheet é
// mais estável que depender da versão da biblioteca.
void lora_hardware_reset() {
    pinMode(LORA_RST_PIN, OUTPUT);
    digitalWrite(LORA_RST_PIN, LOW);
    delay(LORA_RESET_PULSE_MS);
    digitalWrite(LORA_RST_PIN, HIGH);
    delay(LORA_RESET_SETTLE_MS);
}

} // namespace

uint32_t device_id() {
    // eFuse MAC é único de fábrica por chip. Os 32 bits baixos bastam
    // para distinguir os dispositivos de uma planta.
    return static_cast<uint32_t>(ESP.getEfuseMac() & 0xFFFFFFFFULL);
}
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

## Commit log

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2026-08-22 chore: consolida análises, figuras e monografia neste repositório
    docs/, experiments/ e figures/ viviam na raiz do workspace, fora deste
    repositório, num repo git sem nenhum commit — todo o trabalho de análise
    estava efetivamente fora de controle de versão.
    As três pastas mantiveram a posição relativa entre si, então as
    referências cruzadas continuam válidas, e docs/ foi fundido com o docs/
    do firmware (sem colisão de nomes). Junto vieram pyproject.toml,
    uv.lock e .python-version, que são o ambiente Python dos notebooks e
    dos exportadores de figura.
    Corrige também um link quebrado desde antes do move:
    validacao-questionamentos.ipynb apontava para ../docs/, que resolvia
    para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
    [fig1a_espectro.csv, fig1b_contraste.csv, fig1b_espectros_bpfo.csv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]
2026-08-22 feat(training): alinha o domínio dos datasets ao do firmware
    O treino extraía um vetor de features por arquivo inteiro — MAFAULDA a
    50 kHz, ~250k amostras — enquanto o dispositivo lê uma janela de 512
    amostras a 1 kHz. dominant_freq_hz chegaria a 25 kHz no treino e nunca
    passaria de 500 Hz em campo: o modelo exportado não se aplicaria ao que
    o ESP32 mede.
    to_device_windows() decima (FIR em estágios, zero_phase) e fatia todo
    sinal antes de virar feature. As constantes espelham src/main.cpp e
    src/sensors/vibration.cpp.
    Outras correções no mesmo módulo:
    - iter_dataset_files usava Path.glob, que não desce em subdiretórios.
    Como o MAFAULDA é organizado em pastas por tipo e sev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
2026-08-22 fix(training): aplica a máscara de banda 10-1000 Hz da ISO 10816-3
    A norma define as zonas A-D sobre velocidade RMS medida entre 10 Hz e
    1000 Hz. A integração zerava apenas o bin DC, sem recortar a banda,
    divergindo do método que o item 2 dos questionamentos técnicos validou
    com erro de 0,0%.
    A implementação passa a ser a mesma de figures/scripts/export_source_data.py
    (vel_freq): janela de Hann, recorte de banda, compensação da potência
    que a janela remove. Verificada contra o valor analítico de referência
    (3,0 m/s² @ 50 Hz -> 6,7524 mm/s) e contra a imunidade a bias de
    acelerômetro, que é o que motiva integrar na frequência.
2026-08-22 feat(training): valida por ensaio e calibra o limiar por falso alarme
    Três correções de método, todas vindas de docs/questionamentos-tecnicos.md.
    Split por grupo (item 6). A validação usa GroupKFold com o arquivo de
    origem como grupo, então janelas do mesmo ensaio nunca ficam dos dois
    lados do split. Antes não havia split algum: fit(X_normal) seguido de
    predict(X) sobre o mesmo conjunto. O relatório agora traz média e desvio
    entre folds — desvio alto é informação sobre falta de ensaios, não ruído
    a esconder atrás de um número único.
    Limiar por taxa de falso alarme alvo (item 7). O limiar deixa de ser 0,5
    fixo e passa a ser o quantil dos scores de um conjunto de calibra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
2026-08-22 fix(signal): extrai a frequência dominante da velocidade band-limitada
    A frequência dominante vinha do espectro de aceleração cru. Como
    aceleração escala com ω², esse espectro é sempre dominado pelo conteúdo
    de alta frequência — no MAFAULDA, um modo estrutural da bancada em
    117 Hz, idêntico com máquina sadia ou defeituosa. A feature carregava a
    assinatura da montagem, não da falha: a correlação com a rotação real do
    ensaio era de -0,018, e 92% das janelas anômalas caíam dentro da faixa
    p1-p99 das normais.
    A magnitude passa a ser reponderada por |V(f)| = |A(f)|/(2πf), com a
    busca restrita a 10-1000 Hz. A fase é irrelevante para escolher o bin de
    pico, então não é p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
2026-08-22 docs: atualiza arquitetura, README e adiciona changelog
    ARQUITETURA.md ganha o protocolo de treino e calibração, a integração
    para velocidade com recorte de banda, e o papel da ISO como diagnóstico
    em vez de verdade de referência.
    README.md: árvore do projeto reescrita para a estrutura consolidada,
    status das frentes atualizado, contagem de testes corrigida.
    test/README.md dizia cobrir sensors/vibration e sensors/temperature; os
    testes cobrem lib/signal_processing, lib/thermistor e
    lib/isolation_forest.
    CHANGELOG.md registra a rodada inteira, incluindo os resultados do
    primeiro treino em dados reais e o confundimento da massa adicionada nos
    ensaios de rolamento do MAFAULDA.
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2026-08-22 feat(comms): identifica o dispositivo, versiona o pacote e dorme o rádio
    Três problemas no mesmo módulo.
    O pacote não identificava o emissor. Com mais de um Kaelix na planta, o
    gateway não teria como saber de quem era a leitura. Agora carrega
    device_id derivado do eFuse MAC, único de fábrica por chip.
    O campo timestamp era millis(), que zera a cada deep sleep — todo pacote
    chegava com ~3000 ms. Não era um relógio. Substituído por boot_count, que
    vive em RTC memory e sobrevive ao sleep, dando sequência e detecção de
    pacote perdido. O tempo de parede fica com o gateway, que carimba na
    recepção.
    Não havia verificação de integridade nem versão de formato. O pacote
    passa a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
    [lora.cpp]
2026-08-22 fix(power): retém o GPIO no deep sleep e refaz o orçamento de energia
    GPIOs não-RTC vão para alta impedância ao entrar em deep sleep, deixando
    a base dos BC337 flutuando justamente durante os 10 minutos em que o
    corte de energia precisa valer. deep_sleep() passa a chamar
    gpio_hold_en() + gpio_deep_sleep_hold_en(), e peripherals_power() chama
    gpio_hold_dis() no boot seguinte, porque o hold sobrevive ao reset e
    travaria o pino.
    O orçamento documentado no arquivo tinha três erros:
    - Nenhum termo de LoRa idle. O rádio ficava em standby (~1,5 mA) durante
    o sleep, o que sozinho é 5,5x o orçamento inteiro do ciclo.
    - Autonomia calculada para uma 18650 de 3000 mAh, enquanto project.md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
    [sleep.cpp]
2026-08-22 fix(main): confere retornos de init e dorme o rádio antes do deep sleep
    Os quatro *_init() e o lora_send() devolvem bool e nenhum era conferido:
    o dispositivo transmitia mesmo com o rádio fora do ar, e uma falha de
    transmissão sumia em silêncio. Cada falha agora é reportada, e a
    transmissão fica condicionada ao rádio ter subido.
    Acrescenta a chamada de lora_sleep() antes do deep_sleep — sem ela o
    SX1278 passa os 10 minutos em standby e o orçamento de energia do
    dispositivo não fecha.
    Acrescenta delay de 100ms após energizar os periféricos: o MPU6050
    precisa estabilizar antes do init, e antes o init vinha imediatamente
    depois de ligar os BC337.
    O boot_count em RTC memory subst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
    [main.cpp]
2026-08-22 fix(sensors): lê o NTC em milivolts calibrados pelo eFuse
    A conversão assumia que a contagem crua do ADC é linear na tensão. O ADC
    do ESP32-S3 é sensivelmente não-linear, e o desvio ia direto para a
    temperatura reportada.
    analogReadMilliVolts() aplica a curva de calibração gravada no eFuse de
    fábrica; analogSetPinAttenuation(ADC_11db) abre a faixa de entrada para
    os ~3,3V que o divisor pode entregar, contra o padrão que satura antes.
    lib/thermistor ganha ntc_resistance_from_millivolts com testes. A
    matemática do divisor é a mesma — o que muda é a linearidade da entrada.
    [temperature.cpp, test_thermistor.cpp]
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2026-08-22 docs(relatorio): corrige as referências auditadas em fonte primária
    Auditoria das 13 referências da bibliografia contra o site do editor, o
    DOI e o arXiv. Seis tinham defeito.
    Erros de atribuição:
    - varejao2025: primeiro autor é I. M. S. Varejão, citado como
    F. M. Varejão — que é o sexto autor. Duas pessoas do mesmo grupo, e é
    assim que esse erro nasce.
    - kolok2025: três de cinco iniciais erradas (P. Kolok, L. Hotz, N. Remy).
    - fidali2024: terceiro autor é J. Ochmann, não M. Ochmann.
    A ISO 10816-3:2009 está RETIRADA, substituída pela ISO 20816-3:2022, e a
    bibliografia a tratava como vigente. A prática industrial e a literatura
    ainda a adotam, e é isso que justifica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
2026-08-22 refactor(signal): elimina a alocação dinâmica da FFT
    dominant_frequency alocava dois std::vector de n floats por chamada. Com
    a janela de 512 amostras são ~4 KB de heap a cada ciclo de 10 minutos —
    cerca de 35 mil pares malloc/free por ano de campo, com falha de alocação
    não tratada e fragmentação acumulando num dispositivo que nunca reinicia
    por vontade própria. Heap depois da inicialização é proibido em JSF++
    AV-206 e MISRA C++ 18-4-1, e a razão é exatamente essa.
    Substituídos por buffer estático dimensionado por FFT_MAX_N, que deriva
    de VIBRATION_SAMPLES: o tamanho vem da configuração do dispositivo, não
    de um número solto. A não reentrância que isso impõe está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
2026-08-22 refactor(isolation-forest): cota a travessia e valida a árvore
    isolation_tree_path_length percorria a árvore com
    while (tree.feature[node] != -1). Um array corrompido travava o
    dispositivo em laço infinito, e não havia watchdog para tirá-lo de lá.
    Mas o laço era o sintoma. O defeito estrutural estava na struct: ela
    carregava os cinco arrays e nenhum comprimento, então nenhuma função
    tinha como saber se um índice caía dentro deles. root, left e right são
    int16_t com sinal, e um índice negativo lia memória fora do array — no
    ESP32-S3 não há MPU para transformar isso em falha visível. Corrigir o
    laço sem corrigir a struct teria sido remendo.
    IsolationTree ganha n_nodes e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
2026-08-22 docs: adiciona arquitetura de software, análise de falhas, norma e rastreabilidade
    Os quatro artefatos de processo que projetos industriais e aeroespaciais
    exigem e que o projeto não tinha.
    ARQUITETURA-SOFTWARE.md: camadas com regra de dependência, convenções,
    políticas de memória e de erro, estado seguro e registro de desvios.
    Recomenda NÃO construir uma camada HAL, argumentando dos dois lados: todo
    o ganho vem de separar de onde vêm as amostras do que se faz com elas, e
    isso se resolve partindo vibration_read_features em uma função que toca
    I2C e outra pura, sem vtable nem indireção.
    ANALISE-DE-FALHAS.md: FMEA com 36 modos de falha, classes de severidade e
    detectabilidade, e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
2026-08-22 docs: registra a rodada de conformidade e a auditoria de citações no changelog
    Cobre a reorganização do firmware segundo MISRA C++, JSF++ e os
    princípios de determinismo do DO-178C; os achados da análise de falhas
    que não estavam na lista original, incluindo os três de severidade
    máxima; as três regressões que o próprio refactor introduziu e como
    foram corrigidas; e as duas rodadas de auditoria de citações, com o
    placar honesto de 6 defeitos em 13 referências do relatório e 18 em 38
    da revisão de literatura.
    Registra também o que NÃO foi verificado: o firmware não foi compilado, e
    os três achados de severidade máxima não foram confirmados como
    corrigidos porque a fase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
2026-09-01 refactor: move figures/ para experiments/
    figures/ passa a viver ao lado de notebooks/, sob experiments/. A raiz do
    repositório fica com o que é firmware (src/, lib/, test/), o pipeline de
    treino, o ferramental e a documentação; o que é análise e material derivado
    dela fica junto.
    Os scripts em R resolvem caminho pelo próprio diretório e não precisaram
    mudar. Os exportadores Python usam parents[] relativo e também não.
    [fig1a_espectro.csv, fig1b_contraste.csv, fig1b_espectros_bpfo.csv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]
2026-09-01 fix(comms): fixa os parâmetros do enlace LoRa
    begin() recebia só a frequência. Fator de espalhamento, largura de banda,
    taxa de codificação, syncWord e preâmbulo ficavam nos defaults do RadioLib
    — o que é ruim por dois motivos independentes.
    O tempo no ar entra direto no orçamento de energia, e o orçamento assumia
    150 ms sem derivação. Para o pacote de 20 bytes em SF9, BW 125 kHz e CR 4/5,
    o valor real é 185 ms. E, com os parâmetros herdados, uma atualização da
    biblioteca alteraria o consumo do produto sem que a mudança fosse detectável.
    Cada retorno de configuração passa a ser conferido. Um enlace configurado
    pela metade transmite — para um receptor que não estará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
    [lora.cpp]
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2026-09-17 feat(hardware): esquemático, placa e verificação física geradas por código
    O projeto eletromecânico passa a ser gerado a partir de uma netlist declarada,
    e verificado sobre o artefato gerado em vez de sobre um modelo paralelo.
    Geração: gen_schematic e gen_pcb partem da mesma netlist, router faz o
    traçado de duas camadas no disco, gen_involucro modela as três peças a partir
    das cotas do desenho, e gen_3dmodels confere os modelos importados contra as
    cotas do footprint.
    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
    [base.step, corpo.step, jst.step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]
2026-09-17 feat(figures): circuito, PDN, vibração e térmica tridimensional
    Quatro figuras da fase de hardware: o circuito, a impedância da rede de
    distribuição de energia, a resposta a vibração aleatória com a margem de
    fadiga de solda, e a condução térmica em três dimensões.
    Seguem o pipeline do projeto — computação fora do script de plotagem, CSV
    rastreável, saída vetorial com texto editável.
    [fig10_margens.csv, fig10_referencias.csv, fig10_sensibilidade.csv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]
2026-09-17 fix(power): corrige o watchdog RTC para o ESP32-S3
    O primeiro build para o alvo reprovou aqui, com cinco erros.
    watchdog.cpp incluía <soc/rtc_wdt.h> sob uma guarda __has_include. A guarda
    testava a EXISTÊNCIA do cabeçalho, não sua USABILIDADE: no S3 o arquivo está
    presente e referencia RTC_WDT_STG_SEL_*, símbolos que só existem na árvore do
    ESP32 original. A proteção falhou exatamente no cenário para o qual foi
    escrita — em vez de degradar para NotImplemented, quebrou o build.
    Passa a usar hal/wdt_hal.h (RWDT), portátil entre ESP32, S2, S3 e C3, e a
    mesma via que o ESP-IDF usa no bootloader. Isso eliminou o condicional por
    família em vez de acrescentar mais um.
    A janela vir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
    [watchdog.cpp]
2026-09-17 build: declara 16 MB no cabeçalho da imagem
    board_build.flash_size governa só o lado do build. O elf2image lê
    upload.flash_size, que o perfil da devkitc-1 fixa em 8 MB — e gravava
    --flash_size 8MB numa imagem cuja tabela de partições vai até 16 MB: app1
    termina em 12,6 MB e spiffs em 15,6 MB.
    O app cabe nos primeiros 8 MB, então nada quebra hoje. OTA, SPIFFS e coredump
    quebrariam.
    Corrigido por board_upload.flash_size, deliberadamente sem tocar em
    maximum_size: a checagem de tamanho tem de continuar valendo contra a
    partição app0 de 6,25 MB, não contra a flash inteira.
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2026-09-17 docs: sincroniza a documentação com o código e corrige contas
    A documentação tinha divergido do que o firmware faz.
    Sincronizado: vários pontos ainda diziam N_TREES = 0 e limiar 0,5, quando o
    modelo treinado está embarcado; o pacote é v2, de 21 bytes com estado ternário
    e campo de diagnóstico, não v1 de 20; o orçamento de energia aparecia como
    ~354 µA e ~236 dias em toda parte; e REQ-ML-01 e REQ-ML-09 continuavam
    marcados como não verificados na matriz de rastreabilidade.
    Corrigido um erro de conta no §7.4 da análise de falhas: os ~363 µA e ~230
    dias atribuídos ao pacote de diagnóstico de 36 bytes pertenciam ao de 21 bytes
    em CR 4/7 — as linhas do cálculo estavam troc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
2026-09-17 build: acrescenta a suíte de hardware ao runner
    A verificação passa a ter quatro suítes, com a de KiCad junto das outras três.
    Manter a verificação de hardware fora do ponto de entrada único repetiria o
    problema que ele existe para resolver: quebra que só aparece quando alguém
    lembra de rodar a suíte certa.
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2026-09-18 fix(docs): cita a ISO 20816-3 e trata a banda como requisito de instrumento
    relatorio-kaelix e verificacao-hardware chamavam de "a norma" a ISO
    10816-3:2009, retirada e substituída pela ISO 20816-3:2022. A bibliografia
    já registrava a substituição; a prosa não. A substituição é declarada uma
    vez, na primeira menção substantiva, com a observação de que os valores de
    zona são idênticos nas duas edições — a troca afeta a rastreabilidade da
    citação, não os números.
    A banda também estava enunciada como janela de medição ("sobre 10–1000 Hz").
    A norma exige resposta plana do instrumento em faixa de ao menos 10–1000 Hz,
    com limite inferior de até 2 Hz abaixo de 600 r/m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
2026-09-18 fix(docs): separa a procedência dos números sintetizados na revisão
    Três resultados próprios eram apresentados como se viessem do MAFAULDA e
    vêm de sinal sintetizado:
    - o par 413x/20x de contraste em BPFO, na subseção que existe justamente
    para declarar procedência;
    - a queda de pAUC de 16,2% contra 3,7% de AUC (tab:pauc do
    relatorio-kaelix), citada duas vezes no Eixo 1;
    - o falso alarme de ~42% com contamination='auto' (tab:fpr), posto em
    coluna com três valores medidos em máquina. Detecção de 100% e AUC
    unitária não saem de conjunto real.
    Na tab:fpr a marcação vai para a própria linha, não só para a legenda, e o
    parágrafo passa a dizer o que a comparação su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
2026-09-18 feat(docs): adiciona a estrutura do TCC em abnTeX2
    principal.tex monta os cinco capítulos, resumo, abstract, abreviaturas,
    símbolos e dois apêndices, com a instituição fixada no iCEV. As referências
    vêm de ../relatorio/referencias.bib e as figuras de
    ../../experiments/figures/output/, sem cópia: renomear uma chave do .bib ou
    regenerar uma figura muda o TCC na próxima compilação.
    mapa-integracao.md registra o que dos cinco relatórios entra em cada
    capítulo, o que vira apêndice e as pendências abertas. O Makefile compila;
    os intermediários ficam no .gitignore local e o principal.pdf é versionado,
    como os demais PDFs.
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2026-09-18 chore(hardware): regera os artefatos da placa v1
    Nova execução dos geradores. drc.rpt, erc.rpt e kaelix.net mudam apenas no
    carimbo de data; kaelix.step tem as entidades renumeradas pelo exportador
    do KiCad. O esquemático sai idêntico byte a byte, e o desenho da placa não
    muda.
    [kaelix.step]
2026-09-18 fix(hw): trata pino passante como obstáculo na face oposta
    O verificador de colisão só considerava o furo de fixação ao olhar a face
    oposta de uma peça. Pino passante de componente atravessa o laminado e sai
    do outro lado com pad e filete de solda, e ali nenhum corpo pode assentar —
    é o pth_inside_courtyard do KiCad. Até a v2 só o header J2 tinha pino
    passante, e nada ficava sob ele; os pinos de carcaça do USB-C da v3 caem
    na face de baixo, onde fica o carregador, e o DRC acusou três ocorrências.
    A regra vale para pad a partir de 0,8 mm. As vias térmicas de 0,6 mm do
    pad do WROOM-1U continuam fora: na v1 o Ra-02 assenta sob elas por
    projeto, e contá-las recriaria o falso pos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
    [gen_pcb.py]
2026-09-18 fix(router): não conta plano sob o corpo de peça de passo fino
    A grade do roteador via células de plano de terra na faixa entre as
    fileiras de pads de um QFN de 0,5 mm e tratava a região como caminho. O
    preenchimento do KiCad, com espessura mínima e folga exatas, deixa ali só
    retalhos, e o escape seguinte ou uma pista de sinal os fecha em ilha. Na
    v3 o escape de GND do U2.1 terminou numa dessas ilhas sob o MPU6050: o
    roteador deu o pad por ligado e o DRC acusou um grupo de terra solto.
    Agora, sob o corpo de peça de passo fino e na face dela, o plano não conta
    como caminho. Atravessar com pista continua possível; só deixa de valer
    contar com plano ali. A regra fica no modelo do pla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
    [kaelix.kicad_pcb, kaelix.step]
2026-09-18 fix(involucro): corta de fato os furos de USB-C e SMA na parede
    O cilindro de cada passagem começava em x = -cx, a largura externa inteira,
    e não a metade. Com 10,5 mm de comprimento ele ia de -69 a -58,5 mm num
    corpo que termina em -34,5: nenhum dos dois furos era cortado, na v1 nem na
    v2. O defeito "furo USB-C sem conector" do README descrevia um furo que
    existia no desenho e não no modelo. Apareceu quando o conector da v3
    precisou passar por ele e o gerador acusou interferência com a parede.
    O cilindro agora começa fora da parede e a atravessa com sobra. O corpo
    perde 0,58 cm3 nas duas versões, o volume dos dois furos. As alturas
    continuam as arbitradas (45% e 80% da cavidade).
    Os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
    [base.step, corpo.step, montagem-corte.step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]
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2026-09-18 docs(hardware): documenta a placa v3, a carga e as correções de gerador
    pcb/README.md: coluna da v3 na tabela de versões e seção sobre o que ela
    muda — peças, critério de cada uma, corrente de carga pelo modelo térmico e
    tratamento do conector de borda. Os números de roteamento da v1 e da v2
    foram atualizados para o roteador corrigido, e a linha de desacoplamento
    passou para a métrica atual: os "10 de 10" e "3 de 10" eram de antes da
    correção 16a e divergiam do que o próprio gerador imprime. Defeitos 22 e
    27-29 fechados; 30-34 abertos para a v3.
    involucro/README.md: invólucro v3, altura do furo do USB-C medida, e o
    defeito 18 — os furos nunca foram cortados, e os resultado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
2026-09-18 docs(relatorio): corrige a premissa de carga e a conclusão térmica
    Os relatórios raciocinavam sobre o limite de 45 °C de carga numa placa que
    não tinha carregador. Com a placa v3, a premissa passa a valer — e o
    relatorio-kaelix mostrou um segundo erro, anterior à carga: os 44,8 °C a
    80 °C e o limite atingido perto de 81 °C de carcaça vinham do modelo
    concentrado que não convergia. A correção (33,0 °C convergido; placa entre
    35,1 e 38,3 °C a 90 °C no FEM) estava no verificacao-hardware e nunca
    chegou ao texto.
    - relatorio-kaelix: em operação nenhum limite é atingido até 90 °C de
    carcaça, e o autoaquecimento é irrelevante; durante a carga o carregador
    dissipa ~0,4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
2026-09-18 docs(tcc): revisa os capítulos com a conclusão térmica e a placa v3
    Introdução, desenvolvimento, resultados, conclusão, resumo e abstract
    passam a usar a formulação corrigida dos relatórios: em operação nenhum
    limite é atingido até 90 °C de carcaça; o limite de 45 °C da célula
    restringe só durante a carga, que depende da placa v3, ainda não fabricada.
    Os valores do modelo que não convergia (44,8 °C e 81 °C) saem do texto e
    ficam apenas na legenda da figura 4, que declara isso. PDF recompilado.
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2026-11-12 docs(changelog): record the field firmware and its fixes
    Adds the transmitter, gateway and protocol v3 entries and the fixes
    found on the bench: socket descriptor reuse, spool write retries,
    persistent TLS connection, mDNS returning 0.0.0.0 and the routine after
    a configuration change.
2026-11-12 feat(field): add the descriptive analysis
    Sensor noise, rotation, spectra, burst delivery and the response to
    changes in the measurement conditions, outside the registered
    hypotheses.
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2026-11-12 chore(receiver): remove the October LoRa receiver
    The field gateway in src/gateway replaces it. Removes its sources,
    except the pin map and the log buffer that the gateway reuses, the
    private configuration header template, the v1 JSON contracts (now
    defined in the API repository) and its two test suites.
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2026-11-12 chore(figures): remove figures 1 to 11 of the earlier thesis
    Scripts, source data and outputs of the sensor band, methodology,
    enclosure, thermal, topology, chain, gateway, circuit, PDN and vibration
    figures, the notebook that checked them by simulation and the README
    that described them.
2026-11-12 docs: remove the source reports and the previous engineering notes
    The five LaTeX reports with the logo they used, and the architecture,
    failure analysis, coding standard, traceability and C3 device notes of
    the previous firmware.
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
